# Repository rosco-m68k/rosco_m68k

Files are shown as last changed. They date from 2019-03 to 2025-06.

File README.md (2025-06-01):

# Really Old-School Computer - M68K
## A Motorola 68k Single-Board Computer

> **Note**: This is the **develop** branch, where the latest development files live. It is not guaranteed to contain stable code or working designs at any given point. If you are looking for code to use with your board or stable designs, these can be found on the relevant release branches: The [latest 2.4 release branch](https://github.com/rosco-m68k/rosco_m68k/tree/release/version-2.4) for revision 2.x boards, the [1.3 release branch](https://github.com/rosco-m68k/rosco_m68k/tree/release/version-1.3), the [1.2 release branch](https://github.com/rosco-m68k/rosco_m68k/tree/release/revision-1.2) for **revision 1.2** boards, or the [1.1 release branch](https://github.com/rosco-m68k/rosco_m68k/tree/release/revision-1.1) (or the [1.01 release branch if you have firmware 1.01](https://github.com/rosco-m68k/rosco_m68k/tree/release/revision-1.01)) for **revision 1 boards**. Code built or PCBs manufactured from the develop branch are likely to contain development and pre-production bugs, be incomplete, or just plain not work. Code and designs here are liable to change in utterly-incompatible ways without notice!

## What is this?

This repository holds design files, firmware and software for the Really Old-School Computer 
(M68k) single-board computer, AKA the rosco_m68k. This is a fully-featured, programmable,
extensible and capable 16/32-bit retro computer that is completely open source.

This project contains all the design files and source code for the project. For 
documentation (including assembly instructions) please see the [getting started guide](index.md).

You can find the project along with some logs about its development history
on Hackaday: https://hackaday.io/project/164305-yet-another-m68k-homebrew

* All Software released under the MIT licence. See LICENSE for details.
* All Hardware released under the CERN Open Hardware licence.See LICENCE.hardware.txt.
* All Documentation released under Creative Commons Attribution. See https://creativecommons.org/licenses/by/2.0/uk/
* OSHWA-certified Open Source Hardware

## Specifications

Current main board

### Hardware

The hardware specifications for the rosco_m68k are:

* MC68010P10 at 10MHz.
* XR68C681P provides UART, Timers and SD Card / SPI
* 1MB RAM (0x0 - 0xFFFFF)
* 1MB ROM (0xE00000 - 0xEFFFFF)
* 1MB IO space (0xF00000 - 0xFFFFFF)
* High-speed decode and glue logic handled by Atmel F22V10C PLDs.
* Comprehensive expansion and IO connectors allow the system to be easily expanded!

### Software

* A serial bootloader that can load software via the UART (with Kermit protocol)
* Lots of example code and community projects
* Rich firmware interface for with serial and video console for easy programming
* Programmable in assembly, C and (a limited subset of) C++.
* Easy68K-compatible* TRAP 15 (IO) handler
* A growing collection of system libraries and utility code
* Custom Homebrew tap with toolchain - assembly built with VASM; C/C++ built with GCC 13.3.

(*) The firmware is _mostly_ Easy68K compatible - certain functions are not implemented due to the serial nature of IO.

## Getting boards fabricated

If you want to get boards fabricated, we recommend JLCPCB - they did all of our commercial boards. 
These are the options you'll want when ordering from them (these should be readily adaptable to other fabs too!)

JLCPCB Fab Options

## Certification

The rosco_m68k is an OSHWA-certified Open Source Hardware project!

<p align='center'>
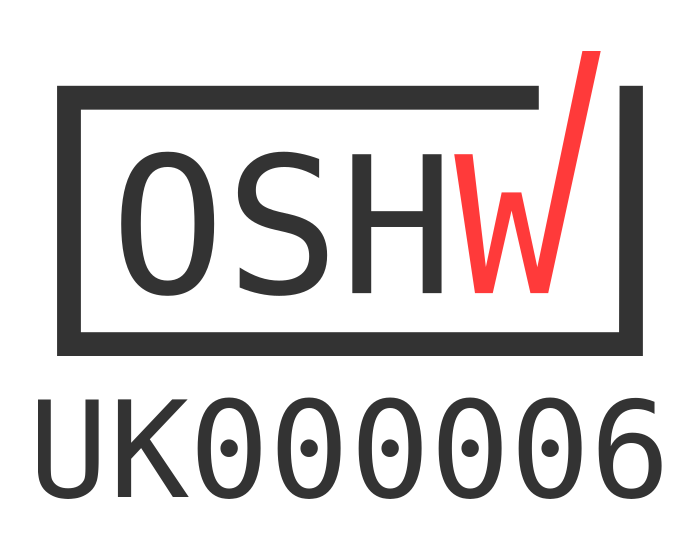
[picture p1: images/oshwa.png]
OSHWA Certified OSHWA Certification UK000006

</p>
<p align='center'>
https://certification.oshwa.org/uk000006.html
</p>

## Evolution

<table>
<tr>
<td colspan="2">
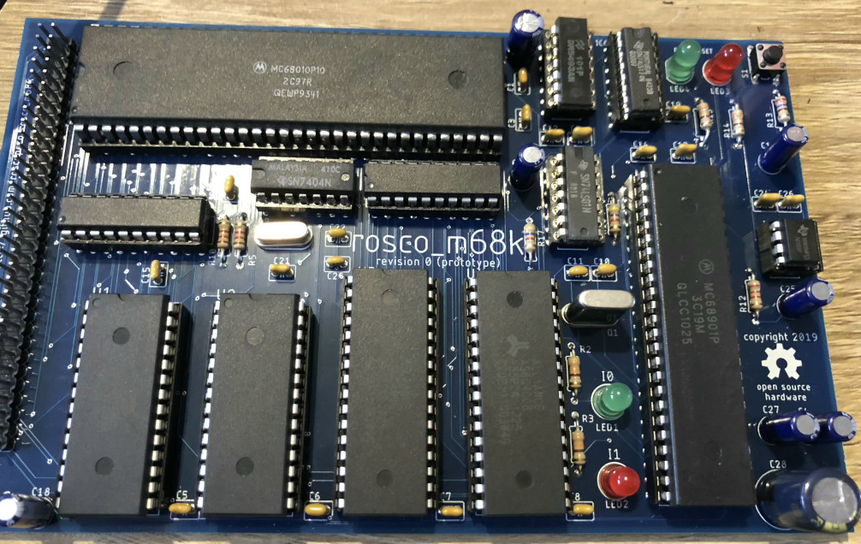
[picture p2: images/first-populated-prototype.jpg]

</td>
</tr>
<tr>
<td>

</td>
<td>
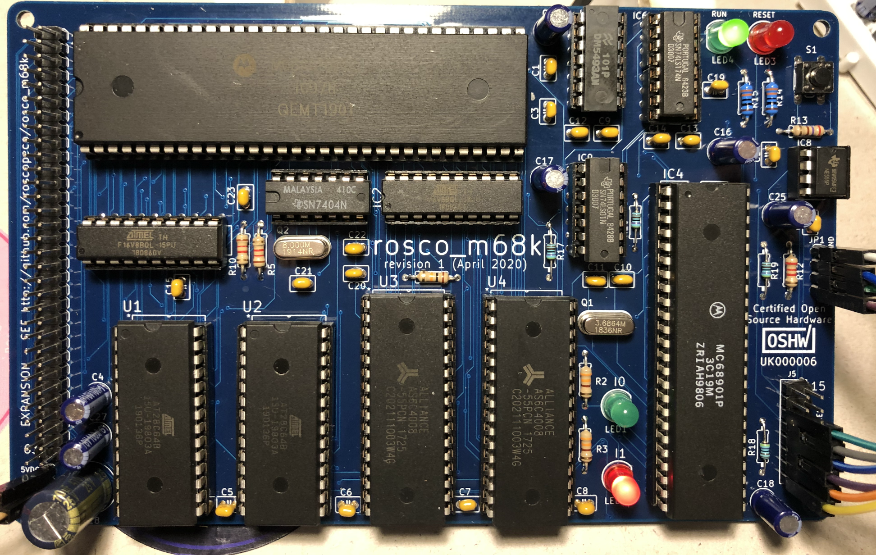
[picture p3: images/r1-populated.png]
 
</td>
</tr>
<tr>
<td>
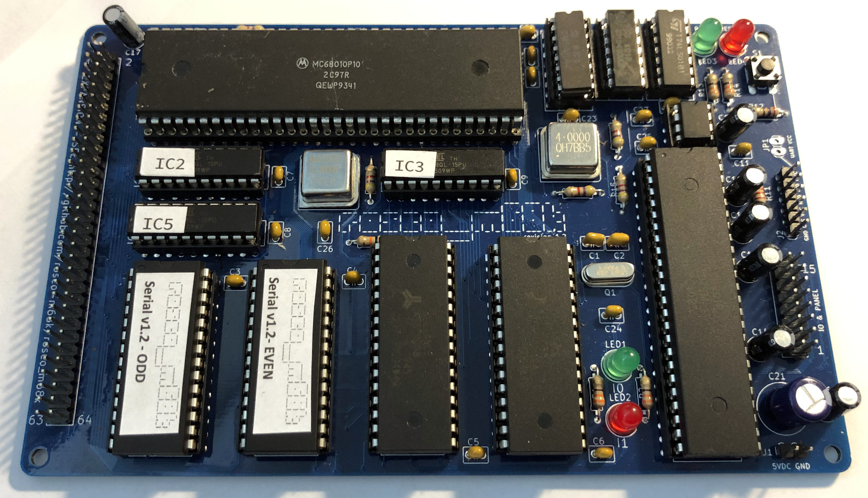
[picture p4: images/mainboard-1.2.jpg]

</td>
<td>
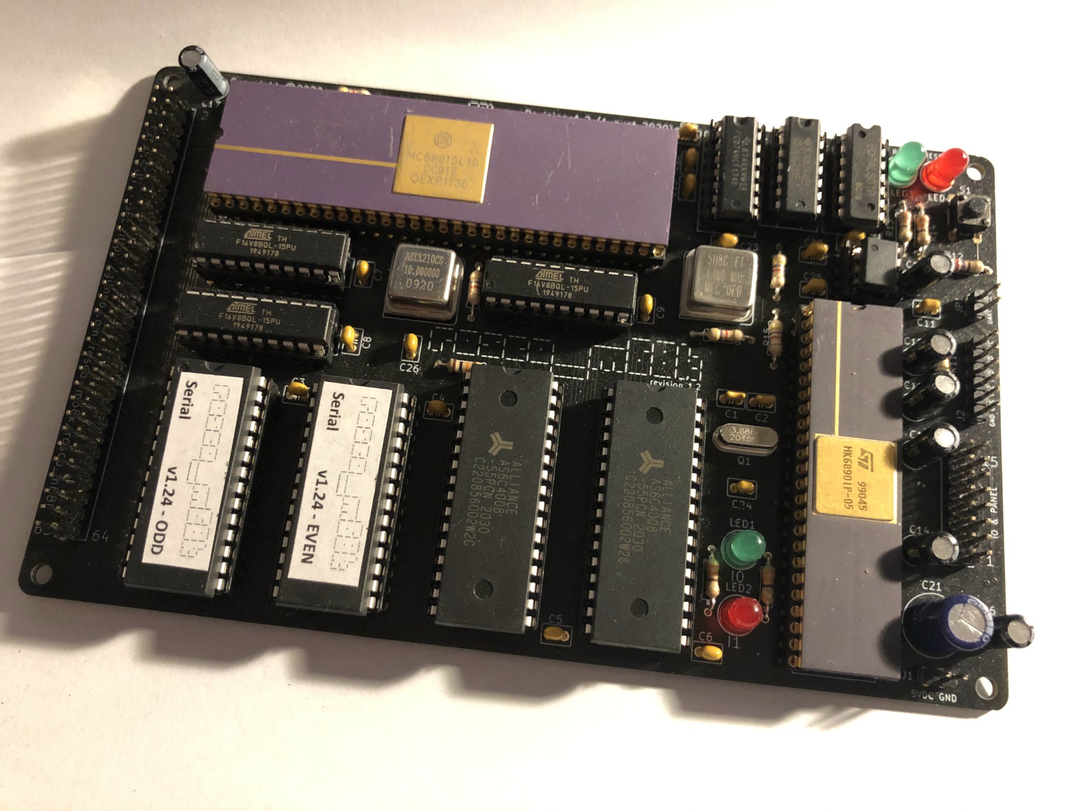
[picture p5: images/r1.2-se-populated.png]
 
</td>
</tr>
<tr>
<td>
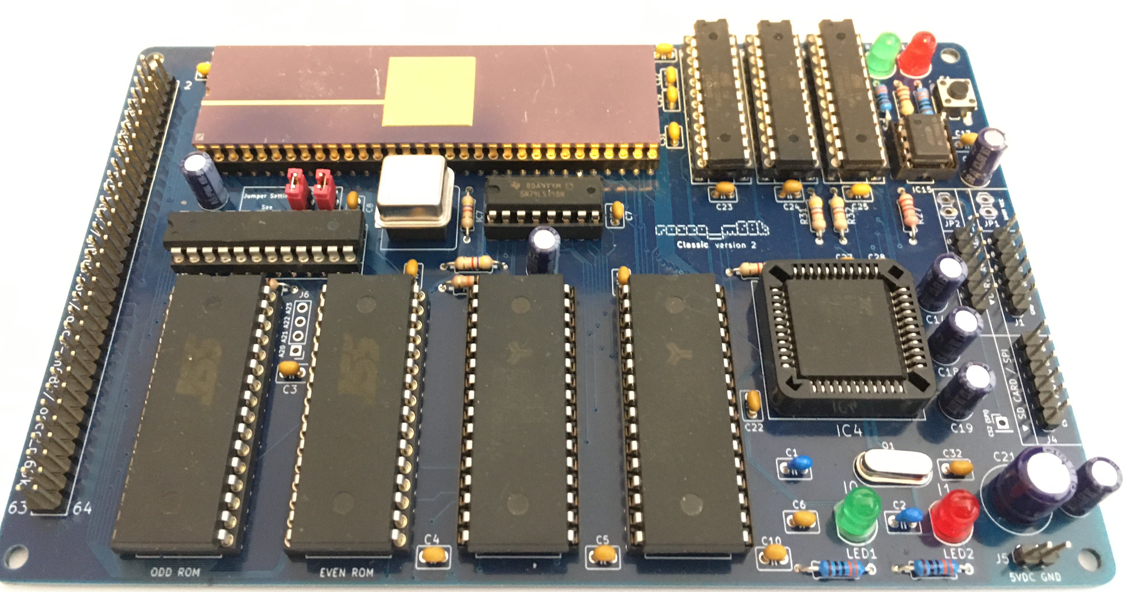
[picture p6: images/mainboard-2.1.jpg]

</td>
<td>
 
</td>
</tr>
<tr>
<td colspan="2">

</td>
</tr>
</table>

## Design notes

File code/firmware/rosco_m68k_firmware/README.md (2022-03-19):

# rosco_m68k Firmware v2.0
## For all Revision 1.x & Revision 2.x rosco_m68k Classic main boards

This is the official version 2.0 firmware for all rosco_m68k Classic boards.

It provides basic machine initialization, a rich API for use by software,
and a variety of boot loaders to enable flexible loading of code into the
machine at boot time.

Drivers are included here for the MC68901 (Revision 1.x only), MC68681 
(and XR68C681), V9958, Xark's Xosera, MarkM's IDE (ATA) interface, and 
the built-in (bit-banged) SPI and SD Card interfaces, and (where 
appropriate) a firmware interface to enable easy use is also provided 
(see InterfaceReference.md).

## Building

The build supports building either 1MB (for Revision 2.x mainboards) or 
64KB ROMs (for Revision 1.x mainboards). Selected options will vary depending
on the ROM size being built. 

Note that, unlike the 1.x firmware series, no support is provided for 16KB ROMs.

To build all options included for revision 2.x boards, just `make`, e.g:

```
make clean all
```

If you wish to build for revision 1.x boards, build with REVISION1X=true, e.g.

```
REVISION1X=true make clean all
```

You can optionally include/exclude various things - see the `Makefile` for 
details.

### Burning

If you are using a TL866II+ programmer, you can burn your ROMs 
directly from the Makefile with:

```
make burn
```

This will automatically set the device to whatever is appropriate for the
ROM size you built (SST39SF040 for R2.x, AT28C256 for R1.x). This can be 
overriden by passing `ROMDEVICE` on the command line, e.g:

```
ROMDEVICE=<SOMEDEVICE> make clean burn
``` 

Where `<SOMEDEVICE>` is a Minipro-recognised device string.

## SD Card 

The SD Card connects to the dedicated SD card connector on the r2 and
r1.2 mainboards. See https://github.com/rosco-m68k/rosco_m68k/blob/develop/SDCardGuide.md
for further details.

SD Cards must be FAT formatted, and will be recognised and scanned 
at boot. If a file named `ROSCODE1.BIN` is found in the root directory,
it will be loaded automatically. 

Binaries built with the `start_serial` standard library (which includes
all example programs) will work from SD card without modification.

## Serial Loader (Kermit)

### Protocols

Currently, only Kermit is supported, and only in the `robust` mode. To support
cautious or fast mode would probably need hardware flow control, for which
most FTDI adapters implement inadequate support.

This is mildly annoying as it requires one to install additional software 
to get Kermit support from the command line, or in minicom. On most Unices
you should be able to install from your package manager (try `ckermit` or 
`c-kermit`). On OSX you can install from homebrew (`brew install c-kermit`) 
and ports probably has it too. On Windows YMMV, but if you're successfully
building this on Windows then you've probably already done a lot of work to
get a cross-compiler and so on working, so I'm sure you'll figure it out.

If you are having problems getting Kermit to work on Linux (especially
Debian or derivatives) you may find that building this patched version
from source helps: https://github.com/rosco-m68k/ckermit

### Kermit Settings

It is **strongly** recommended you use the following settings for your
c-kermit. These should go in your `~/.kermrc` file (or whatever the 
Windows equivalent is):

```
set carrier-watch off ;
set flow xon/xoff ;
robust
```

This instructs c-kermit not to look for a carrier detect signal, to use
software flow-control (because all FTDI chips I've seen get RTS/CTS 
just wrong enough to make them useless without a FIFO on the receiving 
end), and to use the `robust` kermit protocol variant, which is the only 
one I've been able to get to work with the embedded Kermit implementation 
in the bootloader - YMMV of course, feel free to experiment...

You'll need this (at least the carrier detect disable) whether you're
using c-kermit from the command-line or from minicom (or similar).

Of course if your FTDI adapter has a CD pin and you tie this low, you
can skip the carrier-detect setting...
 
## Code

For details of the standard libraries and how to use them to write your
own code, see the examples and the README in the software directory:
https://github.com/rosco-m68k/rosco_m68k/blob/develop/code/software/README.md

You will also find some template projects that get you started with 
either C/C++ or Assembly development at 
https://github.com/rosco-m68k/rosco_m68k/tree/develop/code/starter_projects

The primary reference for the software interfaces provided by the 
firmware can be found here: 
https://github.com/rosco-m68k/rosco_m68k/blob/develop/code/firmware/rosco_m68k_firmware/InterfaceReference.md

* Code is loaded at $40000 (somewhat arbitrarily). The loader will jump
  directly to that location after the code is received.
* This means you are limited to ~860KB with the standard memory configuration.
* (It's actually slightly more, but the stack is at the top of RAM!)
* Once your code is loaded, all of RAM is yours.
* If you use the `heap` standard library, most of this memory will be dedicated
  to your heap, with 32KB being reserved for stack.
* Depending how much setup you want to do, you might leave the lowest 1KB 
  alone (exception vectors), other than setting up any vectors your code
  actually wants to handle.
* If you want to use the standard runtime support stuff (see below), leave the
  bottom 8KB alone (i.e. $2000-$FFFFF are free for your use).

Most of the following things are taken care of automatically if you use the
`start_serial` library (and link using the provided link script). 

The starter projects linked above take care of this for you.
 
* The _recommended_ thing to do is to relocate your code after loading,
  so you don't have it stuck in the middle of RAM. This will make your
  life easier later.
* Obviously your link script will need to take this into account!
* On entry to your code, you are free to (and probably should) reset the
  stack, and can trash any registers you wish. 
* The loader **does not** expect to be returned to. It _will_ handle
  such a condition gracefully, however (it will print a message and halt
  the machine).
  
On entry to the loaded code, the system will be in the following state:

* CPU will be in supervisor mode
* PC will be at $40000
* VBR will point to $0
* Supervisor stack will be at the top of RAM, SSP could be anywhere and can be reset
* Registers will be undefined, and can all be trashed.
* Exception table will be set up (with mostly no-op handlers) from $0 - $3FF 
* Some (very) basic system data will exist between $400-$4FF. You can trash this if you don't need it
  * Some of the default exception handlers **do** write to this area, however!
  * So replace them if you're going to use this area for your own purposes!
* Interrupts (level 2 and above) will be enabled  
* A default exception handler (that will print some debugging information) will
  be installed.
* The system timer will be driving a 100Hz system tick
* System tick will be vectored to CPU vector 0x45, default handler flashes I0.
* DUART/MFP Interrupts other than Timer C will be disabled
* TRAP#13, TRAP#14, TRAP#15 will be hooked by the firmware to provide some basic 
  IO.
* UART TX and RX will be enabled, but their interrupts won't be 
  * you'll either have to enable (and handle) them or use polling
  * If you _do_ enable them, don't use the TRAP#14 IO routines any more or sadness is likely to ensue.

## Runtime Support

See InterfaceReference.md for full details of the runtime interfaces,
TRAPs and memory layout supported by this firmware, including the 
Easy68k compatibility layer.

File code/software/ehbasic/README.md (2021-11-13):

# Enhanced Basic for rosco_m68k

This is a port of Lee Davison's Enhanced Basic for 680x0 to the rosco_m68k.

It can be loaded into RAM (by the serial bootloader) where it will currently run
directly from the load address (i.e. it does not relocate low like most of the 
other software does, because of some idiosyncracies in the way its memory is laid
out - this is likely to change in the future). BASIC RAM is kept below this and 
comprises 128K at the moment.

It should also support being built into a ROM, though this is as-yet untested.

Note that EhBASIC, like any good BASIC, is case-sensitive! Commands must be in
uppercase, or you will receive an error message.

References:

1. http://retro.hansotten.nl/home/lee-davison-web-site/
2. http://www.easy68k.com/applications.htm
3. http://sun.hasenbraten.de/vasm/

## Building

### Standard board (Revision 1.x with Firmware 1.3+, or revision 2.x)

Just run `make` to build, with the standard toolchain.

### Standard board (No MC68681 Dual UART expansion, Firmware 1.2 or below)

To work with the with the onboard MC68901, you must pass `FIRMWARE_IO=false`
option to the make command:

`FIRMWARE_IO=false make clean all`

### With MC68681 Dual UART expansion board

To work with the MC68681 expansion on older mainboards (without Firmware
1.3 or above), you must pass `FIRMWARE_IO=false` and `MC68681=true` 
options to the make command:

`FIRMWARE_IO=false MC68681=true make clean all`

------------------------------------------------------------------------

 EhBASIC68

 Enhanced BASIC is a BASIC interpreter for the 68k family microprocessors. It
 is constructed to be quick and powerful and easily ported between 68k systems.
 It requires few resources to run and includes instructions to facilitate easy
 low level handling of hardware devices. It also retains most of the powerful
 high level instructions from similar BASICs.

 EhBASIC is copyright Lee Davison 2002 - 2012 and free for educational or
 personal use only.
 For commercial use please contact me at leeedavison@lgooglemail.com for conditions.

 For more information on EhBASIC68, other versions of EhBASIC and other projects
 please visit my site at ..

  http://mycorner.no-ip.org/index.html

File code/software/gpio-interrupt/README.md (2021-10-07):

# Rosco_m68k MFP GPIO Interrupt Test Example

This is an example of programming rosco_m68k's MC68901 Multi-Function
Peripheral (MFP) chip.  It programs the chip's general purpose input/output
(GPIO) port to generate a 680x0 CPU interrupt on a falling edge signal (high
to low transition) on rosco_m68k's GPIO3 pin (aka JP5-5). When this transition
happens, the CPU will suspend what it is doing and call a special "interrupt
handler" function, which can then do some work and then when it finishes,
the CPU will resume right at the point where it suspended.

In order to actually see this do anything  semi-interesting, you'll need
something to toggle the signal on J5 pin 5 (GPIO3).  You can use an FTDI
module (including the one you may also be using for rosco_m68k UART), a
switch or an Arduino etc.

However, in my testing, even with _nothing_ hooked up I got a large number
of "bogus" interrupts due to the pin being left floating (especially
when touching JP5 lightly with my finger).

## Building

```text
make clean all
```

This will build `gpio-interrupt.bin`, which can be uploaded to a rosco_m68k
board with standard firmware.

The `Makefile` also makes some other potentially useful outputs:

* `gpio-interrupt.elf` the program binary along with additional symbol and debugging information (useful when using other GNU tools vs a raw binary)
* `gpio-interrupt.dis` a disassembly of the program (but since it is interspersed with the corresponding source code, it is somewhat more understandable than a raw disassembly)
* `gpio-interrupt.sym` lists symbols used in the program and their address (or value for constants)
* `gpio-interrupt.map` similar to the SYM file this shows where everything was placed in memory by the linker

The test will print to the screen while "counting" high to low transitions
on J5 pin 5 and toggling the red LED (the green LED will keep blinking as
usual, using the normal rosco 100Hz MFP "timer C" interrupt).  If there is any
UART input (e.g., you hit a key in a terminal program) the program will issue
a "goodbye" message and exit (similar to as if you pressed the reset button).

I have tried hard to keep the code all in C and not directly use assembly,
however this task is by nature somewhat low-level and I did find using one line
of assembly was required (at least without removing the `-pedantic` compiler
option, and that didn't quite seem sportsman like).

I have found it handy to use an FTDI adapter to automatically toggle the
GPIO pin.  See
[Introduction To FTDI Bitbang Mode](https://hackaday.com/2009/09/22/introduction-to-ftdi-bitbang-mode/)
for a nice example that toggles CTS (change the define at the top to 0x10 for DTR or 0xFF
for "all the pins").  You should connect the GND of FTDI to one of the rosco GND
connections (which you should already be doing if using the FTDI for rosco UART).
Also connect the FTDI signal pin you are using to JP5-5 (e.g., DTR, CTS or RTS).
I find DTR is handy on the default generic FTDI modules. **DO NOT** connect power
from the FTDI module to rosco (unless you are using **only** using the FTDI module
to power your rosco).

Here is a picture of my FTDI to GPIO3 hook-up.  The red, grey and black wires are normal
UART connections (rosco RXD to FTDI TX, rosco TXD to FTDI RX and GND to GND).  The white
wire is DTR to GPIO3 to generate the interrupt.
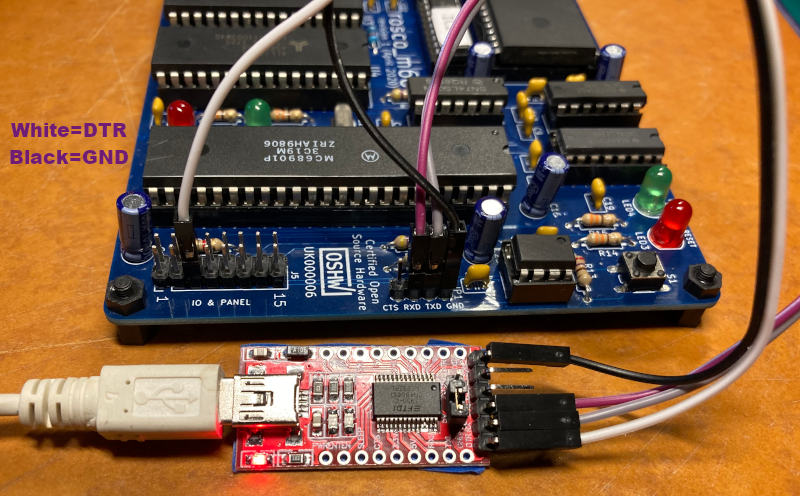
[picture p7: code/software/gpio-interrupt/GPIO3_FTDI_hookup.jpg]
GPIO3 to FTDI connection


I believe using a switch to toggle JP5-5 between 5V and GND should work also (perhaps with
a small-ish ~100 ohm resistor to protect rosco, electrically).

If you're feeling adventurous (and have `ckermit` installed), you
can try:

```text
SERIAL=/dev/some-serial-device make load
```

which will attempt to send the binary directly to your board (which
must obviously be connected and waiting for the upload).

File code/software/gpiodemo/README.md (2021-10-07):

# Very simple GPIO programming example

This is a very simple example of programming the GPIOs.

In order to actually see this do anything, you'll need to hook up a circuit with
some LEDs or something connected to the GPIO lines.

**Note** If you're going to do that, use transistors - the GPIO's can't directly
drive LEDs! See [example-circuit/circuit.pdf](example-circuit/circuit.pdf) for
an example circuit schematic (in KiCad).

## Building

```text
make clean all
```

This will build `kernel.bin`, which can be uploaded to a board that is running
the `serial-receive` firmware.

If you're feeling adventurous (and have ckermit installed), you can try:

```text
SERIAL=/dev/some-serial-device make load
```

which will attempt to send the binary directly to your board (which must
obviously be connected and waiting for the upload).

**NOTE:** This sample uses UTF-8 (for the "💡" glyph). It's recommended to run minicom with colour
and UTF-8 enabled (or you can alter the program).

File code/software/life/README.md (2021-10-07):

# C Game of Life for rosco_m68k

Based on code from this site: <https://rosettacode.org/wiki/Conway%27s_Game_of_Life>

## Building

```bash
make clean all
```

This will build `life.bin`, which can be uploaded to a board that is running the
`serial-receive` firmware.

If you're feeling adventurous (and have ckermit installed), you can try:

```bash
SERIAL=/dev/some-serial-device make load
```

which will attempt to send the binary directly to your board (which must
obviously be connected and waiting for the upload).

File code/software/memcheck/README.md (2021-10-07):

# Memory checked for rosco_m68k

This runs a check of all memory in the address space and builds a memory map
based on what it finds.

All memory locations are tested by writing, and checking that the value that was
written is successfully read back (after writing to another location to avoid
phantom reads).

## Building

```bash
make clean all
```

This will build `memcheck.bin`, which can be uploaded to a board that is
running the `serial-receive` firmware.

If you're feeling adventurous (and have ckermit installed), you can try:

```bash
SERIAL=/dev/some-serial-device make load
```

which will attempt to send the binary directly to your board (which must
obviously be connected and waiting for the upload).

This sample uses UTF-8. It's recommended to run minicom with colour and UTF-8
enabled, for example:

```bash
minicom -D /dev/your-device -c on -R utf-8
```

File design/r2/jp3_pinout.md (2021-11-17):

# rosco_m68k JP3 (Expansion) Pinout (revision 2)

> **Note** this applies to revision 2 (and higher, unless otherwise specified)
  boards **only**. This pinout has changed since the revision one boards (but 
  for most practical purposes it should be compatible - see the new IRQ pins 
  for the differences). This pinout is **not** compatible with earlier revision
  zero boards (which were never released to production anyway)!

JP3 provides peripheral access to the full address, data and control buses in the system, 
plus VCC (5V) and GND. These signals are unbuffered and have no built-in protection, so are
not suitable for direct use as a bus, but could be made so with a relativelty simple 
expansion-to-bus conversion board. 

Many of the MC68010 lines are tri-state when used in conjunction with the bus-mastering support.

It should be noted that most of these signals have very low output current capabilities,
and should not be used to directly drive e.g. LEDs. If LEDs are to be driven, then either
a transistor must be used, or the circuit set up such that the pins sink current.

In all cases, see the datasheets for the relevant IC driving a given line (either the
MC68010, MC68901 or, for the decoder signals, the ATF22V10Cs) for the absolute maximum ratings.

The absolute maximum current draw on the VCC line is 1A. Recommended maximum is 500mA.
The board _may_ be able to supply more than this, but as power supplies are so variable 
you should take care if drawing more than this from this pin. A better solution should 
you need might be to separately power your peripheral from the supply and share common ground.

| Pin | Signal | Description | Active | I/O |
|-----|---|---|---|-----|
| 1 | A1 | MC68010 Address line 1 | High | O |
| 2 | VCC | +5V (Recommend 1A max) | N/A | O |
| 3 | A2 | MC68010 Address line 2 | High | O |
| 4 | CLK | Main system clock (10MHz, 50% duty cycle) | N/A | O |
| 5 | A3 | MC68010 Address line 3 | High | O |
| 6 | GND | Ground | N/A | O |
| 7 | A4 | MC68010 Address line 4 | High | O |
| 8 | VPA | MC68010 Legacy peripheral VPA (*5)(6*) | Low | I |
| 9 | A5 | MC68010 Address line 5 | High | O |
| 10  | E | MC68010 Legacy peripheral E (*5) | Low | O |
| 11  | A6 | MC68010 Address line 6 | High | O |
| 12  | VMA | MC68010 Legacy peripheral VMA (*5) | Low | O |
| 13  | A7 | MC68010 Address line 7 | High | O |
| 14  | IRQ3 | IRQ3 line (*3) | Low | I |
| 15  | A8 | MC68010 Address line 8 | High | O |
| 16  | IOS | IOSEL line from decoder (*1) | Low | O |
| 17  | A9 | MC68010 Address line 9 | High | O |
| 18  | EXPS | EXPSEL line from decoder (*1) | Low | O |
| 19  | A10 | MC68010 Address line 10 | High | O |
| 20  | FC0 | MC68010 Function Code 0 (*2) | High | O |
| 21  | A11 | MC68010 Address line 11 | High | O |
| 22  | FC1 | MC68010 Function Code 1 (*2) | High | O |
| 23  | A12 | MC68010 Address line 12 | High | O |
| 24  | FC2 | MC68010 Function Code 2 (*2) | High | O |
| 25  | A13 | MC68010 Address line 13 | High | O |
| 26  | IPL0 | IRQ5 line (*3) | Low | I |
| 27  | A14 | MC68010 Address line 14 | High | O |
| 28  | IPL1 | IRQ2 Line (*3) | Low | I |
| 29  | A15 | MC68010 Address line 15 | High | O |
| 30  | IPL2 | IRQ6 Line *3) | Low | I |
| 31  | A16 | MC68010 Address line 16 | High | O |
| 32  | LDS | MC68010 Lower Data Strobe | Low | O |
| 33  | A17 | MC68010 Address line 17 | High | O |
| 34  | UDS | MC68901 Upper Data Strobe | Low | O |
| 35  | A18 | MC68010 Address line 18 | High | O |
| 36  | RESET  | System Reset (4*) | Low | I/O |
| 37  | A19 | MC68010 Address line 19 | High | O |
| 38  | D15 | MC68010 Data line 15 | High | I/O |
| 39  | A20 | MC68010 Address line 20 | High | O |
| 40  | D14 | MC68010 Data line 14 | High | I/O |
| 41  | A21 | MC68010 Address line 21 | High | O |
| 42  | D13 | MC68010 Data line 13 | High | I/O |
| 43  | A22 | MC68010 Address line 22 | High | O |
| 44  | D12 | MC68010 Data line 12 | High | I/O |
| 45  | A23 | MC68010 Address line 23 | High | O |
| 46  | D11 | MC68010 Data line 11 | High | I/O |
| 47  | AS | MC68010 Address Strobe | Low | O |
| 48  | D10 | MC68010 Data line 10 | High | I/O |
| 49  | BERR | MC68010 Bus Error | Low | I |
| 50  | D9 | MC68010 Data line 9 | High | I/O |
| 51  | BG | MC68010 Bus Grant | Low | O |
| 52  | D8 | MC68010 Data line 8 | High | I/O |
| 53  | BGACK  | MC68010 Bus Grant Acknowledge | Low | I |
| 54  | D7 | MC68010 Data line 7 | High | I/O |
| 55  | BR | MC68010 Bus Request | Low | I |
| 56  | D6 | MC68010 Data line 6 | High | I/O |
| 57  | DTACK  | MC68010 Data Transfer Acknowledge | Low | I |
| 58  | D5 | MC68010 Data line 5 | High | I/O |
| 59  | R/W | MC68010 Read/Not Write | N/A | O |
| 60  | D4 | MC68010 Data line 4 | High | I/O |
| 61  | D0 | MC68010 Data line 0 | High | I/O |
| 62  | D3 | MC68010 Data line 3 | High | I/O |
| 63  | D1 | MC68010 Data line 1 | High | I/O |
| 64  | D2 | MC68010 Data line 2 | High | I/O |
 
 ## Notes:
 
 1. If used to drive LEDs, the circuit should be configured such that these pins sink current.
 2. If all three function code pins are high the CPU is asserting IACK.
 3. Active low, open-collector IRQ lines for peripherals (4K7 pullups included, do not add more). 
 4. Wire-or, open-collector. Pullup is already provided.
 5. See MC68010 user manual. Using these lines alters bus cycle timing.
 6. This line has a built-in 10k pull-up.

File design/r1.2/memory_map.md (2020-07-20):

# Memory Map

With the standard address decoder (IC2), the machine has the following memory map:

| Region | Start | End | Type |
|---|---|---|---|
| 00 | 0x00000000 | 0x000fffff | Onboard RAM (See note 1) |
| 01 | 0x00100000 | 0x00efffff | Expansion RAM |
| 02 | 0x00f00000 | 0x00f3ffff | Memory hole (See issue #32) |
| 03 | 0x00f40000 | 0x00f7ffff | Expansion RAM |
| 04 | 0x00f80000 | 0x00fbffff | IO (See note 2, below) |
| 05 | 0x00fc0000 | 0x00ffffff | Onboard ROM (See note 3) |

## Note 1 - RAM layout with standard firmware

```
00: 0x00000000-0x000003ff - Exception vectors
01: 0x00000400-0x000004ff - System data area
02: 0x00000500-0x00000fff - Reserved for Kernel, can be re-used 
03: 0x00001000-0x000fffff - User
```

When using the serial firmware, the firmware loads code at 0x40000. On
entry to that code:

* PC will be at 0x40000
* VBR will point to 0x0
* Supervisor stack will be at 0x100000, SSP could be anywhere and can be reset

There is a more complete description of the environment at entry to your
code here: https://github.com/rosco-m68k/rosco_m68k/tree/master/code/firmware/rosco_m68k_v1

When the standard `start_serial` library is compiled into your program,
this library will take care of linking your program correctly and relocating
it to 0x1000 before passing control to your `kmain` function.
For a complete description of the environment on entry, 
see https://github.com/rosco-m68k/rosco_m68k/tree/master/code/software/libs/src/start_serial

### RAM Expansion

Where the roscram_68k RAM expansion board (https://github.com/rosco-m68k/hardware-projects/tree/master/ram-expansion) is fitted, the base address of the RAM provided will be as set by JP1-JP3 on the expansion board, but always
at or above the 1MB mark.

The RAM will extend between 1 and 4 megabytes beyond the base, depending how much RAM is
fitted to the expansion board.

Where the expansion is mapped high (at 13MB) only two megabytes are supported - additional
RAM fitted to the board will not be addressable.

> For more detail on the mapping used by the expansion board and the jumper settings, see comments in https://github.com/rosco-m68k/hardware-projects/blob/master/ram-expansion/code/pld/ic1_address_decoder.pld

## Note 2 - IO Space

As standard, the MFP is mapped to all odd addresses in IO space (IC5 handles
this). It has to be mapped to odd addresses in order to work with the 
CPUs vectored interrupts.

The MFP registers are mapped repeatedly through the whole of IO space,
which leaves only even addresses available for IO expansion (unless the
glue code in IC5 is modified to support).

### MFP Registers

The MFP registers are mapped at the following base addresses and then 
repeat at odd addresses throughout IO space.

| Name (from `machine.h`) | Address | Description |
|---|---|---|
| MFP_GPDR | 0xf80001 | GPIO Data Register |
| MFP_AER | 0xf80003 | Active Edge Register |
| MFP_DDR | 0xf80005 | GPIO Data Direction Register |
| MFP_IERA | 0xf80007 | Interrupt Enable 'A' |
| MFP_IERB | 0xf80009 | Interrupt Enable 'B' |
| MFP_IPRA | 0xf8000B | Interrupt Pending 'A' |
| MFP_IPRB | 0xf8000D | Interrupt Pending 'B' |
| MFP_ISRA | 0xf8000F | Interrupt In-service 'A' |
| MFP_ISRB | 0xf80011 | Interrupt In-service 'B' |
| MFP_IMRA | 0xf80013 | Interrupt Mask 'A' |
| MFP_IMRB | 0xf80015 | Interrupt Mask 'B' |
| MFP_VR | 0xf80017 | Vector Register |
| MFP_TACR | 0xf80019 | Timer 'A' Control Register | 
| MFP_TBCR | 0xf8001B | Timer 'B' Control Register |
| MFP_TCDCR | 0xf8001D | Timers 'C' & 'D' Control |
| MFP_TADR | 0xf8001F | Timer 'A' Data Register |
| MFP_TBDR | 0xf80021 | Timer 'B' Data Register |
| MFP_TCDR | 0xf80023 | Timer 'C' Data Register |
| MFP_TDDR | 0xf80025 | Timer 'D' Data Register |
| MFP_SCR | 0xf80027 | USART Sync Char Register |
| MFP_UCR | 0xf80029 | USART Control Register |
| MFP_RSR | 0xf8002B | USART Receiver Status Register |
| MFP_TSR | 0xf8002D | USART Transmitter Status Register |
| MFP_UDR | 0xf8002F | USART Data Register |

## Note 3 - Onboard ROM

Although 256KB is set aside for ROM, in the standard configuration only 16KB of 
on-board ROM is provided; This is simply striped through the whole of the
space reserved for ROM.

It's also worth noting that, for the first four memory cycles after power-on
or reset, ROM is duplicated low (at 0x0) to allow the CPU to read the reset
vector.

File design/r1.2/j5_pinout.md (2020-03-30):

# rosco_m68k J5 (IO & Panel) Pinout

J5 provides connection to five software-controlled digital GPIO pins with
vectored interrupt capability, two software-controlled timers 8-bit timers, 
and access to all six address-decoder outputs for display purposes.

## GPIO Pins

The general purpose interrupt input/output port provides five I/O lines (GPIO#1-#5)
that may be operated as either inputs or outputs under software control.

In addition, these lines may optionally generate an interrupt on either a positive
transition or a negative transition of the input signal. 

Since interrupts are enabled on a bit-by-bit basis, a subset of the GPIO port could 
be programmed as e.g. handshake lines or the port could be connected to as many as 
five external interrupt sources, which would be prioritized by the on-board interrupt
controller for interrupt service.

For full details, refer to the MC68901 Users Manual. When programming the GPIO port,
it should be noted that the GPIOs are connected to MFP GPIPs #2-6. GPIOs 0, 1 and 7
are used internally by the system.

> **Note**: The GPIO pins are intented for interfacing with other ICs and are **not** 
  suitable for directly driving LEDs or other such devices. If you want to drive LEDs
  from these pins please use transistors!

### Legacy peripheral support

While the MC68010's built-in legacy peripheral support lines are available on
JP3, utilising these lines will cause M6800-type peripherals to use the autovector 
which corresponds to their assigned interrupt level (determined by the state of
the IPL pins, also available on JP3) since they do not provide a vector number in
response to an IACK cycle. This means that polling will have to be performed in
software to determine the interrupting device.

However, by tying the IRQ output from an M6800-type device to the general purpose
IO port and configuring that GPIO as an interrupt line, a unique vector number will
be provided to the processor during an interrupt acknowledge cycle. 

This interrupt structure will significantly reduce interrupt latency for M6800-type
devices and other peripheral devices which do not support vector-by-device.

## Timers

The timers can generate periodic interrupts, measure elapsed time, and count 
signal transitions. In addition, the timers have waveform generation capability.
Both timers are prescaler/counter timers with a common 3.6864MHz clock and are 
independent of the system clock. 

Each timer's output signal toggles when the timer's main counter times out. 
Additionally, both have auxiliary input signals which are used in two of the operation 
modes. An interrupt channel is assigned to each timer and when the auxiliary control 
signals are used, a separate interrupt channel will respond to transitions on these 
inputs.

In addition to the delay mode, both timers can operate in pulse width measurement 
mode and event count mode. 

For full details of the timer modes and how the timers are programmed, refer to the 
MC68901 user manual. When programming the timers, it should be noted that the 
two timers provided are the full-featured timers, A and B. Timers C and D are
used internally by the system.

## Pin assignments

It should be noted that most of these signals have very low output current capabilities,
and should not be used to directly drive e.g. LEDs. If LEDs are to be driven, then either
a transistor must be used, or the circuit set up such that the pins sink current.

In all cases, see the datasheets for the relevant IC driving a given line (either the
MC68901 or, for the decoder signals, the ATF16V8BQL) for the absolute maximum ratings.

| Pin | Signal | Description | Active | I/O |
|-----|---|---|---|-----|
| 1 | GPIO1  | GPIO #1 (MFP GPIP #2) (*4) | H/L | I/O |
| 2 | ERAM | EVENRAMSEL line from decoder (*1) | Low | O |
| 3 | GPIO2  | GPIO #2 (MFP GPIP #3) (*4) | H/L | I/O |
| 4 | ORAM | ODDRAMSEL line from decoder (*1) | Low | O |
| 5 | GPIO3  | GPIO #3 (MFP GPIP #4) (*4) | H/L | I/O |
| 6 | EROM | EVENROMSEL line from decoder (*1) | Low | O |
| 7 | GPIO4  | GPIO #4 (MFP GPIP #5) (*4) | H/L | I/O |
| 8 | OROM | ODDROMSEL line from decoder (*1) | Low | O |
| 9 | GPIO5  | GPIO #5 (MFP GPIP #6) (*4) | H/L | I/O |
| 10  | IOS | IOSEL line from decoder (*1) | Low | O |
| 11  | TAO | Timer A output | -- | O |
| 12  | EXPS | EXPSEL line from decoder (*1) | Low | O |
| 13  | TBO | Timer B output | -- | O |
| 14  | TBI | Timer B input (*2) | -- | I |
| 15  | TAI | Timer A input (*2) | -- | I |
| 16  | N/C | Unconnected (*3) | -- | --  |
 
 ## Notes:
 
 1. If used to drive LEDs, the circuit should be configured such that these pins sink current.
 2. These pins have an on-board 4K7 pull-up to VCC
 3. This pin can (via additional soldering) be used as either a GND or VCC to suit the configuration of the other pin connections. In the future an on-board jumper may be provided to accomplish this.
 4. If driving LEDs, it is **strongly** recommended that transistors be used as these pins have very low current ratings for both source and sink. Refer to the MC68901 datasheet for specific values.

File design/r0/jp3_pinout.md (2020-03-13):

# rosco_m68k JP3 (Expansion) Pinout

> **Note** that there is an error in the silkscreen of the revision 0 board than incorrectly
  labels pin 2 as pin 64 on the physical board!

JP3 (split into JP3 and JP4 in the schematic but joined as a single 2x32 pin header on the PCB)
provides peripheral access to the full address, data and control buses in the system, plus
VCC (5V) and GND. These signals are unbuffered, however many of the MC68010 lines are 
tri-state when used in conjunction with the bus-mastering support.

It should be noted that most of these signals have very low output current capabilities,
and should not be used to directly drive e.g. LEDs. If LEDs are to be driven, then either
a transistor must be used, or the circuit set up such that the pins sink current.

In all cases, see the datasheets for the relevant IC driving a given line (either the
MC68010 or, for the decoder signals, the ATF16V8BQL) for the absolute maximum ratings.

The recommended maximum current draw on the VCC line is 250mA. The board _should_ be
able to supply more than this, but as power supplies are so variable you should take
care if drawing more than this from this pin. A better solution should you need might
be to separately power your peripheral from the supply and share common ground.

Although it is possible with the current design to power the board by the VCC and GND
pins, this is not recommended. If you do decide to do this you might consider additional
filtering.

| Pin | Signal | Description | Active | I/O |
|-----|---|---|---|-----|
| 1 | A1 | MC68010 Address line 1 | High | O |
| 2 | VCC | +5V (Recommend 250mA max depending on PSU) | N/A | O |
| 3 | A2 | MC68010 Address line 2 | High | O |
| 4 | CLK | Main system clock (8MHz, 50% duty cycle) | N/A | O |
| 5 | A3 | MC68010 Address line 3 | High | O |
| 6 | GND | Ground | N/A | O |
| 7 | A4 | MC68010 Address line 4 | High | O |
| 8 | ERAM | EVENRAMSEL line from decoder (*1) | Low | O |
| 9 | A5 | MC68010 Address line 5 | High | O |
| 10  | EROM | EVENROMSEL line from decoder (*1) | Low | O |
| 11  | A6 | MC68010 Address line 6 | High | O |
| 12  | ORAM | ODDRAMSEL line from decoder (*1) | Low | O |
| 13  | A7 | MC68010 Address line 7 | High | O |
| 14  | OROM | ODDROMSEL line from decoder (*1) | Low | O |
| 15  | A8 | MC68010 Address line 8 | High | O |
| 16  | IOS | IOSEL line from decoder (*1) | Low | O |
| 17  | A9 | MC68010 Address line 9 | High | O |
| 18  | EXPS | EXPSEL line from decoder (*1) | Low | O |
| 19  | A10 | MC68010 Address line 10 | High | O |
| 20  | FC0 | MC68010 Function Code 0 (*2) | High | O |
| 21  | A11 | MC68010 Address line 11 | High | O |
| 22  | FC1 | MC68010 Function Code 1 (*2) | High | O |
| 23  | A12 | MC68010 Address line 12 | High | O |
| 24  | FC2 | MC68010 Function Code 2 (*2) | High | O |
| 25  | A13 | MC68010 Address line 13 | High | O |
| 26  | IPL0 | MC68010 Interrupt Priority Level Bit 0 (*3)  | Low | I |
| 27  | A14 | MC68010 Address line 14 | High | O |
| 28  | IPL1 | MC68010 Interrupt Priority Level Bit 1 (*3)  | Low | I |
| 29  | A15 | MC68010 Address line 15 | High | O |
| 30  | IPL2 | MC68010 Interrupt Priority Level Bit 2 (*3)  | Low | I |
| 31  | A16 | MC68010 Address line 16 | High | O |
| 32  | LDS | MC68010 Lower Data Strobe | Low | O |
| 33  | A17 | MC68010 Address line 17 | High | O |
| 34  | UDS | MC68901 Upper Data Strobe | Low | O |
| 35  | A18 | MC68010 Address line 18 | High | O |
| 36  | RESET  | System Reset (4*) | Low | I/O |
| 37  | A19 | MC68010 Address line 19 | High | O |
| 38  | D15 | MC68010 Data line 15 | High | I/O |
| 39  | A20 | MC68010 Address line 20 | High | O |
| 40  | D14 | MC68010 Data line 14 | High | I/O |
| 41  | A21 | MC68010 Address line 21 | High | O |
| 42  | D13 | MC68010 Data line 13 | High | I/O |
| 43  | A22 | MC68010 Address line 22 | High | O |
| 44  | D12 | MC68010 Data line 12 | High | I/O |
| 45  | A23 | MC68010 Address line 23 | High | O |
| 46  | D11 | MC68010 Data line 11 | High | I/O |
| 47  | AS | MC68010 Address Strobe | Low | O |
| 48  | D10 | MC68010 Data line 10 | High | I/O |
| 49  | BERR | MC68010 Bus Error | Low | I |
| 50  | D9 | MC68010 Data line 9 | High | I/O |
| 51  | BG | MC68010 Bus Grant | Low | O |
| 52  | D8 | MC68010 Data line 8 | High | I/O |
| 53  | BGACK  | MC68010 Bus Grant Acknowledge | Low | I |
| 54  | D7 | MC68010 Data line 7 | High | I/O |
| 55  | BR | MC68010 Bus Request | Low | I |
| 56  | D6 | MC68010 Data line 6 | High | I/O |
| 57  | DTACK  | MC68010 Data Transfer Acknowledge | Low | I |
| 58  | D5 | MC68010 Data line 5 | High | I/O |
| 59  | R/W | MC68010 Read/Not Write | N/A | O |
| 60  | D4 | MC68010 Data line 4 | High | I/O |
| 61  | D0 | MC68010 Data line 0 | High | I/O |
| 62  | D3 | MC68010 Data line 3 | High | I/O |
| 63  | D1 | MC68010 Data line 1 | High | I/O |
| 64  | D4 | MC68010 Data line 4 | High | I/O |
 
 ## Notes:
 
 1. If used to drive LEDs, the circuit should be configured such that these pins sink current.
 2. If all three function code pins are high the CPU is asserting IACK.
 3. Interrupt 4 (100b) is reserved for the MC68901.
 4. Wire-or, open-collector.

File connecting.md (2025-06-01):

[Home](index.md) | [Getting Started](getting-started.md) | [Connecting](connecting.md) | [Running the Examples](running-the-examples.md) | [Toolchain Installation](toolchain-installation.md) | [Building the Software](building-the-software.md) | [Installing the Emulator](installing-the-emulator.md) | [Debugging with MAME](MAME-serial.md) | [Using SD Cards](SDCardGuide.md)

# Connecting your rosco_m68k

## Once you've built your new old computer, it's time to start talking to it!

Hooking up your rosco_m68k to your regular modern computer is a simple affair, thanks to the wonders of modern technology. USB to Serial (UART) converters are cheap and plentiful, and you might even have received one along with your kit (if you opted for one when you purchased). Let's look at what you'll need to get started.

### You'll need:
- A USB lead with +5V and GND broken out to Dupont® connectors, or alternative power connector
- A USB to Serial converter (sometimes called an FTDI converter) or cable
- A USB Mini-B to A cable

> **Warning!**
> - Incorrectly connecting your rosco_m68k may damage it and other equipment connected to it - Check before you connect!
> - Connecting your rosco_m68k to a power source with a voltage higher than 5V is likely to damage it - Check before you connect!
> - Your USB to Serial converter must be 5V tolerant. Some have a jumper to select either 5V or 3.3V, ensure this is set to 5V - Check before you connect!

---

## Connecting the Power

You'll need some kind of 5V power supply that can connect to the two-pin power header on the rosco_m68k. We use modified USB cables and regular wall-wart adapters for this, but any well-regulated 5V power source will work just fine.

If you don't have a power lead, it's easy to make one from an old USB lead - check out [this video](https://www.youtube.com/watch?v=Vw4d0oMl0Mg), for example.

When connecting the power, be sure to observe the polarity - the pins are clearly marked on the board as **5VDC** and **GND**. If using a USB cable, these should be connected to the red and black wires, respectively. It's really important to connect these correctly, getting them the wrong way round *will* damage your rosco_m68k! If in doubt, use a multimeter to check the polarity before you connect.

---

## Connecting the UART to the USB to Serial Converter

The exact method for doing this will vary depending on the specific converter you have, but the general principle remains the same.

Find the four-pin UART connector on your rosco_m68k - it's on the right side of the board, and the pins are marked **CTS**, **RXD**, **TXD** and **GND**.

Now, on your USB to Serial converter, find the corresponding four pins. Most converters (including the one we optionally supply) will already have headers soldered on for these pins.

Using a four-way wire with DuPont connectors at each end, make the following connections:

| rosco_m68k | USB to Serial Converter |
|---|---|
| CTS | CTS |
| RXD | TXD (Sometimes TX) |
| TXD | RXD (Sometimes RX) |
| GND | GND |

Now connect the USB cable from your USB to Serial converter to your computer. The converter will probably have some LEDs that light up at this point, and your computer should recognise it as a new serial device.

The new device should appear in the `/dev` directory, ready for use. On macOS, for example, it's named `/dev/cu.usbserial-XXXX`. You can find it easily by running:

```sh
ls /dev/cu*
```

On Linux, you can find the name of the device by looking at the output of the `dmesg` command.

---

## Connecting an SD Card

If you're running Firmware v1.3 and up, you can connect an SD card using an Arduino SD card adapter. Depending on your board revision, this either connects to a dedicated header (on 1.23 boards and higher) or to J5 (on 1.2 boards and below).

See [this page](https://github.com/rosco-m68k/rosco_m68k/blob/develop/SDCardGuide.md) for a detailed hookup guide, as well as information on supported cards and formatting.

---

## Installing Software and Testing

> **Note:** These instructions apply to macOS® and Linux only. We recommend that Windows® users use a Linux VM.

If you hit compilation failures or other issues with CKermit, you may need to install from source - we maintain a fork of the 9.0.160 version, slightly modified to compile on modern systems: [rosco-m68k/ckermit](https://github.com/rosco-m68k/ckermit).

In this section we'll install two programs, `minicom` and `ckermit`. If you already have them installed, or have another terminal emulator / kermit client that you like, then feel free to skip this section.

We recommend using Homebrew to manage your software. If you don't already have it, you can find simple installation instructions at [brew.sh](https://brew.sh/).

If you're using Linux and don't want to install Homebrew, it's very likely that both these packages are available from your distribution's standard package repositories - you'll be able to install them with `apt-get`, `yum`, `dnf`, or whatever your regular package manager is called.

To install the two packages with Homebrew:

```sh
brew install minicom c-kermit
```

(Note: If using your Linux distribution's package manager, the Kermit package is likely to be called `ckermit` instead of `c-kermit`.)

After installation, both packages should be ready to use, but we need to add a little bit of configuration first.

Create a new file in your home directory called `.kermrc`, or edit the existing one if it already exists. The contents of this file should be:

```
set carrier-watch off ;
set flow xon/xoff ;
robust
```

Now launch minicom:

```sh
minicom -D /dev/cu.usbserial-XXXX -c on -R utf-8
```

Replace `/dev/cu.usbserial-XXXX` with the path to the device you determined in the previous step. On Linux, this will probably start with `/dev/tty...` rather than `/dev/cu...`.

> **Note:** On Mac, you may find that the `Esc+KEY` combination used in the following section doesn't work. If you're using [iTerm2](https://iterm2.com/) you can emulate this combination with the right option key by opening the `Profiles` menu, selecting `Open Profiles`. Click the `Edit Profiles` button, and with the `Default` profile selected in the left pane go to the `Keys` tab in the right pane. Near the bottom of this is an option to change the mapping of the `Right Option` key - change this to be `Esc+`.

Once Minicom has launched, open the options (Esc+O or CTRL-A, O on Linux) and navigate to Serial Port Setup. Edit the options as needed, then escape out and select "Save setup as dfl". Restart minicom to ensure the configuration is loaded.

Power up your rosco_m68k (or hit the reset button if it's already powered up), and you should see the startup message on-screen. Congratulations - you're now all set, and your rosco_m68k can talk to your computer!

From here, you can use Esc+S (Ctrl-A, S on Linux) to initiate a Kermit file transfer, and send a compiled binary program to your board and interact with it in the serial terminal.

Now that the rosco_m68k is successfully talking to your computer, it's time to run some example programs! We'll do that in the [next section](running-the-examples.md).

---

---

[Home](index.md) | [Getting Started](getting-started.md) | [Connecting](connecting.md) | [Running the Examples](running-the-examples.md) | [Toolchain Installation](toolchain-installation.md) | [Building the Software](building-the-software.md) | [Installing the Emulator](installing-the-emulator.md) | [Debugging with MAME](MAME-serial.md) | [Using SD Cards](SDCardGuide.md)

Copyright © 2020 The Really Old-School Company Limited. Registered in England and Wales No. 12596175
The Really Old-School Company Ltd, 15 Starthe Bank, GB DE75 7AX Tel: 0330 133 2083

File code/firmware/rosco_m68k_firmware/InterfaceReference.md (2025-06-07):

# rosco_m68k Firmware - Memory & Interfaces
## Firmware version 2.0

This document describes the interfaces provided for programmers,
hardware integrators and those expanding the rosco_m68k, as it
applies to firmware revision 2.0. 

The information contained herein is accurate and complete as far
as possible, and will be kept updated as firmware 2.0 is developed.

# Contents

* 1. TRAP Interfaces for User Code
  * 1.1. SPI & Block device IO (TRAP 13)
    * 1.1.1 Example Usage
    * 1.1.2 Functions
      * 1.1.2.1 CHECK_SD_SUPPORT (Function #0)
      * 1.1.2.2 SD_INIT (Function #1)
      * 1.1.2.3 SD_READ_BLOCK (Function #2)
      * 1.1.2.4 SD_WRITE_BLOCK (Function #3)
      * 1.1.2.5 SD_READ_REGISTER (Function #4)
      * 1.1.2.6 CHECK_SPI (Function #5)
      * 1.1.2.7 SPI_INIT (Function #6)
      * 1.1.2.8 SPI_ASSERT_CS (Function #7)
      * 1.1.2.9 SPI_DEASSERT_CS (Function #8)
      * 1.1.2.10 SPI_TRANSFER_BYTE (Function #9)
      * 1.1.2.11 SPI_TRANSFER_BUFFER (Function #10)
      * 1.1.2.12 SPI_RECV_BYTE (Function #11)
      * 1.1.2.13 SPI_RECV_BUFFER (Function #12)
      * 1.1.2.14 SPI_SEND_BYTE (Function #13)
      * 1.1.2.15 SPI_SEND_BUFFER (Function #14)
      * 1.1.2.16 CHECK_ATA_SUPPORT (Function #15)
      * 1.1.2.17 ATA_INIT (Function #16)
      * 1.1.2.18 ATA_READ_SECTORS (Function #17)
      * 1.1.2.19 ATA_WRITE_SECTORS (Function #18)
      * 1.1.2.20 ATA_IDENTIFY (Function #19)
  * 1.2. Character device IO routines (TRAP 14)
    * 1.2.1 Example Usage
    * 1.2.2 Functions
      * 1.2.2.1 PRINT (Function #0)
      * 1.2.2.2 PRINTLN (Function #1)
      * 1.2.2.3 SENDCHAR (Function #2)
      * 1.2.2.4 RECVCHAR (Function #3)
      * 1.2.2.5 PRINTCHAR (Function #4)
      * 1.2.2.6 SETCURSOR (Function #5)
      * 1.2.2.7 CHECKCHAR (Function #6)
      * 1.2.2.8 CHECK_DEVICE_SUPPORT (Function #7)
      * 1.2.2.9 GET_DEVICE_COUNT (Function #8)
      * 1.2.2.10 GET_DEVICE (Function #9)
      * 1.2.2.11 ADD_DEVICE (Function #10)
      * 1.2.2.12 DEVICE_RECVCHAR (Function #11)
      * 1.2.2.13 DEVICE_SENDCHAR (Function #12)
      * 1.2.2.14 DEVICE_CHECKCHAR (Function #13)
      * 1.2.2.15 RESERVED (Function #14)
      * 1.2.2.16 RESERVED (Function #15)
      * 1.2.2.17 DEVICE_CTRL (Function #16)
      * 1.2.2.18 INPUTCHAR (Function #17)
      * 1.2.2.19 CHECKINPUT (Function #18)
  * 1.3. Easy68k compatibility layer (TRAP 15)
    * 1.3.1 Example Usage
    * 1.3.2 Functions
      * 1.3.2.1 PRINTLN_LEN (Function #0)
      * 1.3.2.2 PRINT_LEN (Function #1)
      * 1.3.2.3 READSTR (Function #2)
      * 1.3.2.4 DISPLAYNUM_SIGNED (Function #3)
      * 1.3.2.5 READNUM (Function #4)
      * 1.3.2.6 READCHAR (Function #5)
      * 1.3.2.7 SENDCHAR (Function #6)
      * 1.3.2.8 CHECKINPUT (Function #7)
      * 1.3.2.9 GETUPTICKS (Function #8)
      * 1.3.2.10 TERMINATE (Function #9)
      * 1.3.2.11 MOVEXY (Function #11)
      * 1.3.2.12 SETECHO (Function #12)
      * 1.3.2.13 PRINTLN_SZ (Function #13)
      * 1.3.2.14 PRINT_SZ (Function #14)
      * 1.3.2.15 PRINT_UNSIGNED (Function #15)
      * 1.3.2.16 SETDISPLAY (Function #16)
      * 1.3.2.17 PRINTSZ_NUM (Function #17)
      * 1.3.2.18 PRINTSZ_READ_NUM (Function #18)
      * 1.3.2.19 PRINTNUM_SIGNED_WIDTH (Function #20)
* 2. System Data Area memory map
  * 2.1. Exception vectors
  * 2.2. Basic System Data Block (SDB)
  * 2.3. Extension Function Pointer Table (EFPT)
  * 2.4. Video IO Data Area (VDA)
    * 2.4.1. Video Data Block (VDB)
  * 2.5. Firmware Reserved Area 1 (Internal)
  * 2.6. Firmware Reserved Area 2 (BSS)
* 3. Character Devices
  * 3.1 General Information
  * 3.2. The `CHAR_DEVICE` structure
  * 3.3. Device function calling conventions

# 1. TRAP Interfaces for User Code

The firmware provides a set of basic IO routines intended for use
from user code. Because some of these routines may require the CPU
to be in Supervisor mode, they are accessed via the M68k TRAP
instruction. Execution of this instruction causes the CPU to jump
to an exception vector (initialized by the firmware) as if an
exception were being processed. Context is stored on the stack
and Supervisor mode is entered automatically.

Currently, three TRAPs are used by the firmware:

* TRAP 13 provides rosco_m68k's native block device IO routines (SD)
* TRAP 14 provides rosco_m68k's native serial device IO routines (UART/Console)
* TRAP 15 provides basic IO routines that are broadly Easy68k-compatible(*)

All other TRAP vectors are unused at boot-time (and initialized to no-op
handlers). Extension code, drivers and user code are free to re-use
these vectors as they see fit.

The standard TRAP handlers use various registers as arguments, and
may also use one or more registers to return values to the 
calling code. These registers are documented in the following 
sections. In all cases, all registers other than those stated
in this documentation are preserved.

**Note** that the standard firmware TRAP handlers rely on the 
integrity of the System Data Area in memory. If this area is
reused or corrupted, these routines may not function properly.

(*) Note that the Easy68k layer may optionally be omitted from the 
firmware build. In such cases, the functions offered on TRAP 15 will
not be available, and that TRAP vector may be reused.

## 1.1. Block device IO (TRAP 13)

TRAP 13 provides access to the block-device IO functionality
provided by the firmware. At present, this means SD cards.

Register D0.L is expected to contain the function code (note that
this is different to the TRAP 14 handler!). Other arguments
depend on the specific function, and are documented below.

In all cases, registers used as aguments (including D0.L) are **not** 
guaranteed to be preserved. All other registers are preserved.

Function codes outside the range documented here are considered
reserved for future expansion, and should not be used by integrators
or other code. The exception to this is where the user program 
is intended to take complete control of the system, in which case
the TRAP handlers, and the SDA that underpins them, may be entirely
replaced in the scope of that program.

### 1.1.1 Example Usage

An example of using function 2 (SD_READ_BLOCK) of TRAP 13 is:

```
SD_read_block::
    movem.l A0-A2/D1,-(A7)
    move.l  (20,A7),A1
    move.l  (24,A7),D1
    move.l  (28,A7),A2
    move.l  #2,D0
    trap    #13
    movem.l (A7)+,A0-A2/D1
    rts
```

With GCC as the compiler, this could be called directly from C, 
with the prototype: 

```
bool SD_read_block(SDCard *sd, uint32_t block, void *buf);
```
 
### 1.1.2 Functions

#### 1.1.2.1 CHECK_SD_SUPPORT (Function #0)

**Arguments**

* D0.L - 0 (Function code)

**Modifies**

* `D0.L` - Return value

**Description**

Determine whether SD Card support is present in the Firmware.

Where SD Card support is available, this will return the magic
number $1234FEDC in D0.L. 

Any other value indicates that support is not available. In this
case, none of the SD Card routines should be used.

With Firmware 2.0, SD support is always available. However, this
routine is retained to allow easy backward-compatibility.

#### 1.1.2.2 SD_INIT (Function #1)

**Arguments**

* `D0.L` - 1 (Function code)
* `A1`   - Pointer to an SDCard struct

**Modifies**

* `D0.L` - Return value
* `A0`   - Modified arbitrarily
* `A1`   - May be modified arbitrarily

**Description**

Attempt to initialize the SD Card. 

The memory pointed to by A1 will be a SDCard structure - see
sdfat.h in the standard libraries for details.

The return value in D0.L will be one of the SDInitStatus
codes - `SD_INIT_OK` (ordinal 0) indicates success, while failure 
is indicated by any other value. Again, see sdfat.h for details.

#### 1.1.2.3 SD_READ_BLOCK (Function #2)

**Arguments**

* `D0.L` - 2 (Function code)
* `D1.L` - Block number to read
* `A1`   - Pointer to an initialized SDCard struct
* `A2`   - Pointer to a 512-byte buffer

**Modifies**

* `D0.L` - Return value
* `D1.L` - May be modified arbitrarily
* `A0`   - Modified arbitrarily
* `A1`   - May be modified arbitrarily
* `A2`   - May be modified arbitrarily

**Description**

Read a 512-byte block from the SD Card into the buffer
pointed to by A2.

Returns 0 in D0.L to indicate failure, any other value
indicates success.

#### 1.1.2.4 SD_WRITE_BLOCK (Function #3)

**Arguments**

* `D0.L` - 3 (Function code)
* `D1.L` - Block number to write
* `A1`   - Pointer to an initialized SDCard struct
* `A2`   - Pointer to a 512-byte buffer

**Modifies**

* `D0.L` - Return value
* `D1.L` - May be modified arbitrarily
* `A0`   - Modified arbitrarily
* `A1`   - May be modified arbitrarily
* `A2`   - May be modified arbitrarily

**Description**

Write a 512-byte block from the buffer pointed to by A2 to
the SD Card..

Returns 0 in D0.L to indicate failure, any other value
indicates success.

#### 1.1.2.5 SD_READ_REGISTER (Function #4)

**Arguments**

* `D0.L` - 4 (Function code)
* `D1.L` - Register number to read (translates directly to a CMD)
* `A1`   - Pointer to an initialized SDCard struct
* `A2`   - Pointer to a 16-byte buffer

**Modifies**

* `D0.L` - Return value
* `D1.L` - May be modified arbitrarily
* `A0`   - Modified arbitrarily
* `A1`   - May be modified arbitrarily
* `A2`   - May be modified arbitrarily

**Description**

Read an SD Card register block from the SD Card into the buffer
pointed to by A2.

Returns 0 in D0.L to indicate failure, any other value
indicates success.

#### 1.1.2.6 CHECK_SPI (Function #5)

**Arguments**

* `D0.L` - 5 (Function code)

**Modifies**

* `D0.L` - Return value

**Description**

Determine whether SPI support is present in the Firmware.

Where SPI Card support is available, this will return the magic
number $1234FEDC in D0.L. 

Any other value indicates that support is not available. In this
case, none of the SPI routines should be used.

With Firmware 2.0, SD support is always available. However, this
routine is retained to allow easy backward-compatibility.

#### 1.1.2.7 SPI_INIT (Function #6)

**Arguments**

* `D0.L` - 6 (Function code)

**Modifies**

* `D0.L` - Result (0 = OK, otherwise failed)
* `A0`   - Modified arbitrarily

**Description**

Initialize the SPI interface. This sets the SPI pins to the 
appropriate modes (input vs output).

#### 1.1.2.8 SPI_ASSERT_CS (Function #7)

**Arguments**

* `D0.L` - 7 (Function code)
* `D1.L` - Device number (0 or 1)

**Modifies**

* `D0.L` - Result (0 = failed, otherwise OK)
* `A0`   - Modified arbitrarily

**Description**

Assert the appropriate CS line. Note that asserting one line 
*does not* automatically deassert the other!

#### 1.1.2.9 SPI_DEASSERT_CS (Function #8)

**Arguments**

* `D0.L` - 8 (Function code)
* `D1.L` - Device number (0 or 1)

**Modifies**

* `D0.L` - Result (0 = failed, otherwise OK)
* `A0`   - Modified arbitrarily

**Description**

Deassert the appropriate CS line. 

#### 1.1.2.10 SPI_TRANSFER_BYTE (Function #9)

**Arguments**

* `D0.L` - 9 (Function code)
* `D1.L` - Byte to send

**Modifies**

* `D0.L` - Byte received
* `A0`   - Modified arbitrarily

**Description**

Send and receive a byte (exchange) via SPI.

#### 1.1.2.11 SPI_TRANSFER_BUFFER (Function #10)

**Arguments**

* `D0.L` - 10 (Function code)
* `A1.L` - Pointer to buffer
* `D1.L` - Number of bytes

**Modifies**

* `D0.L` - Count exchanged
* `A0`   - Modified arbitrarily
* `A1`   - Possibly modified

**Description**

Transfer count (`D1.L`) bytes from the given buffer, exchanging them 
with bytes received at the same time (and returned in the buffer).

Note that the buffer pointer may be modified, so keep a copy locally.

#### 1.1.2.12 SPI_RECV_BYTE (Function #11)

**Arguments**

* `D0.L` - 11 (Function code)

**Modifies**

* `D0.L` - Byte received
* `A0`   - Modified arbitrarily

**Description**

Send and receive a byte (exchange) via SPI.

#### 1.1.2.13 SPI_RECV_BUFFER (Function #12)

**Arguments**

* `D0.L` - 12 (Function code)
* `A1.L` - Pointer to buffer
* `D1.L` - Number of bytes

**Modifies**

* `D0.L` - Count received
* `A0`   - Modified arbitrarily
* `A1`   - Possibly modified

**Description**

Receive count (`D1.L`) bytes into the given buffer.
Note that the buffer pointer may be modified, so keep a copy locally.

#### 1.1.2.14 SPI_SEND_BYTE (Function #13)

**Arguments**

* `D0.L` - 13 (Function code)
* `D1.L` - Byte to send

**Modifies**

* `A0`   - Modified arbitrarily
* `D1.L` - Possibly trashed

**Description**

Send and receive a byte (exchange) via SPI.

#### 1.1.2.15 SPI_SEND_BUFFER (Function #14)

**Arguments**

* `D0.L` - 14 (Function code)
* `A1.L` - Pointer to buffer
* `D1.L` - Number of bytes

**Modifies**

* `D0.L` - Count received
* `A0`   - Modified arbitrarily
* `A1`   - Possibly modified

**Description**

Send count (`D1.L`) bytes from the given buffer.
Note that the buffer pointer may be modified, so keep a copy locally.

#### 1.1.2.16 CHECK_ATA_SUPPORT (Function #15)

**Arguments**

* `D0.L` - 15 (Function code)

**Modifies**

* `D0.L` - Return value

**Description**

Determine whether ATA support is present in the Firmware.

Where ATA support is available, this will return the magic
number $1234FEDC in D0.L. 

Any other value indicates that support is not available. In this
case, none of the ATA routines should be used.

With Firmware 2.0, ATA support is always available. However, this
routine is retained to allow easy backward-compatibility.

#### 1.1.2.17 ATA_INIT (Function #16)

**Arguments**

* `D0.L` - 16 (Function code)
* `D1.L` - 0 (ATA Master) or 1 (ATA slave)
* `A1`   - Pointer to an ATADevice struct

**Modifies**

* `D0.L` - Return value
* `D1.L` - May be modified arbitrarily
* `A0`   - Modified arbitrarily
* `A1`   - May be modified arbitrarily

**Description**

Attempt to initialize an ATA device. 

The memory pointed to by A1 will be a ATADevice structure - see
ata.h in the standard libraries for details.

The return value in D0.L will be one of the ATAInitStatus
codes - `ATA_INIT_OK` (ordinal 0) indicates success, while failure 
is indicated by any other value. Again, see ata.h for details.

#### 1.1.2.18 ATA_READ_SECTORS (Function #17)

**Arguments**

* `D0.L` - 17 (Function code)
* `D1.L` - LBA sector number to read
* `D2.L` - Number of sectors to read
* `A1`   - Pointer to an initialized ATADevice struct
* `A2`   - Pointer to a (512 * D2.L)-byte buffer

**Modifies**

* `D0.L` - Return value
* `D1.L` - May be modified arbitrarily
* `A0`   - Modified arbitrarily
* `A1`   - May be modified arbitrarily
* `A2`   - May be modified arbitrarily

**Description**

Read the number of 512-byte sectors (indicated by `D2.L`) from the 
ATA device into the buffer pointed to by `A2`.

Returns the actual number of sectors read in `D0.L`.

#### 1.1.2.19 ATA_WRITE_SECTORS (Function #18)

**Arguments**

* `D0.L` - 18 (Function code)
* `D1.L` - LBA sector number to write
* `D2.L` - Number of sectors to write
* `A1`   - Pointer to an initialized ATADevice struct
* `A2`   - Pointer to a (512 * D2.L)-byte buffer

**Modifies**

* `D0.L` - Return value
* `D1.L` - May be modified arbitrarily
* `A0`   - Modified arbitrarily
* `A1`   - May be modified arbitrarily
* `A2`   - May be modified arbitrarily

**Description**

Write the number of 512-byte sectors (indicated by `D2.L`) from the 
buffer pointed to by `A2` to the ATA device, starting at the LBA sector
indicated by `D1.L`.

Returns the actual number of sectors written in `D0.L`.

#### 1.1.2.20 ATA_IDENTIFY (Function #19)

**Arguments**

* `D0.L` - 19 (Function code)
* `A1`   - Pointer to an initialized ATADevice struct
* `A2`   - Pointer to a 512-byte buffer

**Modifies**

* `D0.L` - Return value (0 = failed, 1 = success)
* `D1.L` - May be modified arbitrarily
* `A0`   - Modified arbitrarily
* `A1`   - May be modified arbitrarily
* `A2`   - May be modified arbitrarily

**Description**

Issue an ATA `IDENTIFY` command to the specified `ATADevice`, and return
the results in the supplied buffer.

Returns 1 in `D0.L` if successful, 0 otherwise.

## 1.2. Basic IO routines (TRAP 14)

TRAP 14 provides access to the character-based IO functionality 
provided by the firmware. This includes the default UART and
console.

Register D1.L is expected to contain the function code. Other arguments
depend on the specific function, and are documented below.

In all cases, registers used as aguments (**excluding** D1.L, which 
will be preserved unless explicitly documented as used for a return
value) are **not** guaranteed to be preserved. All 
other registers are preserved.

Function codes outside the range documented here are considered
reserved for future expansion, and should not be used by integrators
or other code. The exception to this is where the user program 
is intended to take complete control of the system, in which case
the TRAP handlers, and the SDA that underpins them, may be entirely
replaced in the scope of that program.

### 1.2.1 Example Usage

An example of calling function 1 (PRINTLN) of TRAP 14 is:

```
DO_PRINTLN:
    move.l  #1,D1
    lea.l   MYSTRING,A0
    trap    #14

; ... later

MYSTRING    dc.b    "Hello, World!", 0
```

### 1.2.2 Functions

#### 1.2.2.1 PRINT (Function #0)

**Arguments**

* `D1.L` - 0 (Function code)
* `A0`   - Pointer to null-terminated string to print

**Modifies**

* `A0`   - Will point to the memory location following the null terminator

**Description**

Print the null-terminated string pointed to by `A0` to the system's
*default console*. 

Where the default console is a serial terminal, this routine may block until
there is space in the UART's transmit buffer for the character - as such, 
it is not suitable for use in time- or latency-critical code (e.g. interrupt 
handlers).

The default console is initialized at boot-time by the firmware, and 
may be the V9958 console (where available), or the *default serial UART*.
For details on the default UART, see the `SENDCHAR` function.

System integrators and third-party hardware developers may also override
the default console (for example to output to third-party video 
hardware). See section 2.3 for details.

#### 1.2.2.2 PRINTLN (Function #1)

**Arguments**

* `D1.L` - 1 (Function code)
* `A0`   - Pointer to null-terminated string to print

**Modifies**

* `A0`   - Will point to the memory location following the null terminator

**Description**

Print the null-terminated string pointed to by `A0` to the system's
*default console* followed by a CR/LF sequence.

Where the default console is a serial terminal, this routine may block until
there is space in the UART's transmit buffer for the character - as such, 
it is not suitable for use in time- or latency-critical code (e.g. interrupt 
handlers).

The default console is initialized at boot-time by the firmware, and 
may be the V9958 console (where available), or the *default serial UART*.
For details on the default UART, see the `SENDCHAR` function.

System integrators and third-party hardware developers may also override
the default console (for example to output to third-party video 
hardware). See section 2.3 for details.

#### 1.2.2.3 SENDCHAR (Function #2)

**Arguments**

* `D1.L` - 2 (Function code)
* `D0.B` - Character to send

**Modifies**

Nothing

**Description**

Synchronously send the character contained in `D0.B` via the system's
*default UART*. This routine may block until there is space in the 
UART's transmit buffer for the character - as such, it is not suitable
for use in time- or latency-critical code (e.g. interrupt handlers).

The default UART is initialized at boot-time by the firmware, and
will generally be the "best" serial UART available (with the 
fallback being the MC68901 UART that is expected to be always installed).

System integrators and third-party hardware developers may also override
the default UART (for example to utilise third-party hardware). 
See section 2.3 for details.

#### 1.2.2.4 RECVCHAR (Function #3)

**Arguments**

* `D1.L` - 3 (Function code)

**Modifies**

* `D0.B` - Returns the received character

**Description**

Synchronously receive a character via the system's *default UART*,
and return it in `D0.B`. If no character is immediately available, this
routine will block until one becomes available. As such, it is not suitable
for use in time- or latency-critical code (e.g. interrupt handlers).

The default UART is initialized at boot-time by the firmware, and
will generally be the "best" serial UART available (with the 
fallback being the MC68901 UART that is expected to be always installed).

System integrators and third-party hardware developers may also override
the default UART (for example to utilise third-party hardware). 
See section 2.3 for details.

#### 1.2.2.5 PRINTCHAR (Function #4)

**Arguments**

* `D1.L` - 4 (Function code)
* `D0.B` - Character to print

**Modifies**

Nothing

**Description**

Print the character in `D0.B` to the system's *default console*.

Where the default console is a serial terminal, this routine may block until
there is space in the UART's transmit buffer for the character - as such, 
it is not suitable for use in time- or latency-critical code (e.g. interrupt 
handlers).

The default console is initialized at boot-time by the firmware, and 
may be the V9958 console (where available), or the *default serial UART*.
For details on the default UART, see the `SENDCHAR` function.

System integrators and third-party hardware developers may also override
the default console (for example to output to third-party video 
hardware). See section 2.3 for details.

#### 1.2.2.6 SETCURSOR (Function #5)

**Arguments**

* `D1.L` - 5 (Function code)
* `D0.B` - 0 to hide cursor, non-zero to show

**Modifies**

Nothing

**Description**

Show or hide the cursor on the *default console*. Where this is not possible]
(e.g. where the default console is a serial terminal) this routine does
nothing.

The default console is initialized at boot-time by the firmware, and 
may be the V9958 console (where available), or the *default serial UART*.
For details on the default UART, see the `SENDCHAR` function.

System integrators and third-party hardware developers may also override
the default console (for example to output to third-party video 
hardware). See section 2.3 for details.

#### 1.2.2.7 CHECKCHAR (Function #6)

**Arguments**

* `D1.L` - 6 (Function code)

**Modifies**

* `D0.B` - 0 if no character waiting, nonzero otherwise

**Description**

Determine whether the system's *default UART* has a character waiting to
be received, returning non-zero in `D0.B` if so, zero otherwise. 

This can be used to determine whether a call to `RECVCHAR` will block.
Note that this function may clear error flags and other status information.

The default UART is initialized at boot-time by the firmware, and
will generally be the "best" serial UART available (with the 
fallback being the MC68901 UART that is expected to be always installed).

System integrators and third-party hardware developers may also override
the default UART (for example to utilise third-party hardware). 
See section 2.3 for details.

#### 1.2.2.8 CHECK_DEVICE_SUPPORT (Function #7)

**Arguments**

* `D1.L` - 7 (Function code)

**Modifies**

* `D0.L` - Return value

**Description**

Check if the new _Character Device Support_ (available since firmware
2.30) is available.

Where support is available, this will return the magic number $1234FEDC 
in `D0.L`.

Any other value indicates that support is not available. In this
case, none of the character device routines should be used.

#### 1.2.2.9 GET_DEVICE_COUNT (Function #8)

**Arguments**

* `D1.L` - 8 (Function code)

**Modifies**

* `D0.W` - Return value

**Description**

Returns the number of character devices the firmware knows about in 
`D0.W`.

#### 1.2.2.10 GET_DEVICE (Function #9)

**Arguments**

* `D1.L` - 9 (Function code)
* `D0.W` - 0-based index of the desired device
* `A0`   - Points to a `CHAR_DEVICE` structure (32 bytes)

**Modifies**

* `D0.B` - `0` if the device number is not valid, nonzero otherwise
* `A0`   - Trashed

**Description**

Populates the supplied device structure with data for the
specified device number. 

Note that the data is copied into the structure you supply,
you cannot use this to modify system data structures.

#### 1.2.2.11 ADD_DEVICE (Function #10)

**Arguments**

* `A0`   - Pointer to a new `CHAR_DEVICE` structure
* `D1.L` - 10 (Function code)

**Modifies**

* `D0.B` - 0-15 index of the device. Any other value indicates failure.

**Description**

Adds a new character device at the next available slot. There
are sixteen slots - if they are all full, this function will return
a value >15 to indicate failure.

#### 1.2.2.12 DEVICE_RECVCHAR (Function #11)

**Arguments**

* `D1.L` - 11 (Function code)
* `A0`   - Pointer to the `CHAR_DEVICE` structure (obtained via `GET_DEVICE`)

**Modifies**

* `D0.B` - Returns the received character
* `A0`   - Trashed 

**Description**

Synchronously receive a character via the character device in the supplied
`CHAR_DEVICE` structure, and return it in `D0.B`. 

If no character is immediately available, this routine _may_ block until one
becomes available. As such, it is not suitable for use in time- or 
latency-critical code (e.g. interrupt handlers).

#### 1.2.2.13 DEVICE_SENDCHAR (Function #12)

**Arguments**

* `D1.L` - 12 (Function code)
* `D0.B` - Character to send
* `A0`   - Pointer to the `CHAR_DEVICE` structure (obtained via `GET_DEVICE`)

**Modifies**

* `A0`   - Trashed 

**Description**

Synchronously send the character contained in `D0.B` via the character 
device referenced by the supplied `CHAR_DEVICE` structure. 

This routine _may_ block until there is space in the device's buffer
for the character - as such, it is not suitable for use in time- or 
latency-critical code (e.g. interrupt handlers).

#### 1.2.2.14 DEVICE_CHECKCHAR (Function #13)

**Arguments**

* `D1.L` - 13 (Function code)
* `A0`   - Pointer to the `CHAR_DEVICE` structure (obtained via `GET_DEVICE`)

**Modifies**

* `D0.B` - 0 if no character waiting, nonzero otherwise
* `A0`   - Trashed 

**Description**

Determine whether the the character device referenced by the supplied
 `CHAR_DEVICE` structure has a character waiting to be received, returning 
 non-zero in `D0.B` if so, zero otherwise. 

This can be used to determine whether a call to `DEVICE_RECVCHAR` will 
block if called for the same device.

Note that this function _may_ clear error flags and other status information.

#### 1.2.2.15 RESERVED (Function #14)

This function code is reserved for future use and should not be called.

#### 1.2.2.16 RESERVED (Function #15)

This function code is reserved for future use and should not be called.

#### 1.2.2.17 DEVICE_CTRL (Function #16)

**Arguments**

* `D1.L` - 16 (Function code)
* `D0.L` - Command (low-byte) and optional data
* `D2.L` - 32-bit command-specific parameter
* `A0`   - Pointer to the `CHAR_DEVICE` structure (obtained via `GET_DEVICE`)

**Modifies**

* `D0.L` - 0 if unknown command, device/command-specific result otherwise
* `A0`   - Trashed 

**Description**

Send a device-specific command, with optional parameters in the high
24 bits of `D0` and the full 32-bits of `D2`.

The commands supported, the parameters they take, and the return value
of this function are all device specific. See the specific documentation
for the device (which can be identified by the device type in the 
`CHAR_DEVICE` block) for details.

#### 1.2.2.18 INPUTCHAR (Function #17)

**Arguments**

* `D1.L` - 17 (Function code)

**Modifies**

* `D0.B` - The read character

**Description**

Read a character from the default input device. Will block until a
character is available.

In systems where the rosco_m68k (or compatible) keyboard is connected to the
second UART, this will check the keyboard. 

Otherwise, the default input will usually be the main UART.

#### 1.2.2.19 CHECKINPUT (Function #18)

**Arguments**

* `D1.L` - 18 (Function code)

**Modifies**

* `D0.B` - 0 if no character waiting, nonzero otherwise

**Description**

Check the default input device for a waiting character.

In systems where the rosco_m68k (or compatible) keyboard is connected to the
second UART, this will check the keyboard. 

Otherwise, the default input will usually be the main UART.

## 1.3. Easy68k compatibility layer (TRAP 15)

TRAP 15 provides an (optional, included by default) Easy68k-compatible
IO interface. The aim is to allow many common Easy68k programs to be 
run on the rosco_m68k without modification.

Currently only a subset of the Easy68K tasks are implemented. Output 
will always go to the **default console** (See section 1.1.2.1) and input
will be via the **default UART** (See section 1.1.2.3). Depending on
capabilities of the input and output devices, some functions may not
be available in all contexts (for example, cursor movement and color
setting will not be available where output is via UART).

These functions are called by loading the task number into `D0` and setting
up other registers as documented below, and then calling `TRAP #15`.

### 1.3.1 Example Usage

An example of calling function 0 (PRINTLN with length) of TRAP 15 is:

```
DO_EASY68K_PRINTLN_LEN:
    move.l  #0,D0
    move.w  #13,D1
    lea.l   MYSTRING,A1
    trap    #15

; ... later

MYSTRING    dc.b    "Hello, World!"
```

### 1.3.2 Functions

#### 1.3.2.1 PRINTLN_LEN (Function #0)

**Arguments**

* `D0.L` - 0 (Function code)
* `D1.W` - String length (max 255)
* `A1` - Points to the string

**Modifies**

* `D1` - Trashed
* `A1` - Points to memory location after the last printed character

**Description**

Print the string at (A1), D1.W bytes long (max 255) with carriage return
and line feed (CR, LF) to the system's *default console*. 

See also: Function 13

#### 1.3.2.2 PRINT_LEN (Function #1)

**Arguments**

* `D0.L` - 1 (Function code)
* `D1.W` - String length (max 255)
* `A1` - Points to the string

**Modifies**

* `D1` - Trashed
* `A1` - Points to memory location after the last printed character

**Description**

Print the string at (A1), D1.W bytes long (max 255) **without** carriage return
and line feed (CR, LF) to the system's *default console*. 

See also: Function 14

#### 1.3.2.3 READSTR (Function #2)

**Arguments**

* `D0.L` - 2 (Function code)
* `A0` - Pointer to buffer in which to store string

**Modifies**

* `D1.W` - Returns length of read string (Max 80)
* `(A1)` - Returns the string

**Description**

Read string from keyboard and store at (A1), NULL terminated, length retuned in D1.W (max 80). 

#### 1.3.2.4 DISPLAYNUM_SIGNED (Function #3)

**Arguments**

* `D0.L` - 3 (Function code)
* `D1.L` - Number to display

**Modifies**

* `D1` - Possibly trashed

**Description**

Print signed number in D1.L in decimal (in smallest field) to the system's
*default console*.

See also: Functions 15 & 20

#### 1.3.2.5 READNUM (Function #4)

**Arguments**

* `D0.L` - 4 (Function code)

**Modifies**

* `D1.L` - Returns the read number

**Description**

Read a number from the keyboard into D1.L.

See also: Functions 15 & 20

#### 1.3.2.6 READCHAR (Function #5)

**Arguments**

* `D0.L` - 5 (Function code)

**Modifies**

* `D1.B` - The read character.

**Description**

Read single character from the keyboard into D1.B.

**Note** Unlike Easy68k, this will block until input is available.

#### 1.3.2.7 SENDCHAR (Function #6)

**Arguments**

* `D0.L` - 6 (Function code)
* `D1.B` - Character to display

**Modifies**

* `D1` - Trashed

**Description**

Display single character in D1.B.

#### 1.3.2.8 CHECKINPUT (Function #7)

**Arguments**

* `D0.L` - 7 (Function code)

**Modifies**

* `D1.B` - 1 if input pending, 0 otherwise

**Description**

Set D1.B to 1 if keyboard input is pending, otherwise set to 0. 
Use Function 5 to read pending key.

**Notes**

**This function is to be avoided if possible**.

Using this function doesn't make a lot of sense in the current rosco_m68k 
environment, because all input is via the UART. This means that, while this 
function _is_ implemented, its meaning is subtly different from the Easy68K
equivalent - here true result means there is serial data waiting, not 
specifically a user keypress.

That's not the worst of it, however - if the MC68901 UART is currently the
system's *default UART*, **using this task may actually be harmful**.
It may silently clear any errors the UART is signalling. This is 
because it works by reading the Buffer Full indicator bit in the receiver
status register, which has the effect of _also_ clearing the error flags
(e.g. overrun) in that same register. Normally, these would be checked 
during a receive, but this task doesn't check them _at all_ and so could 
lead to errors being ignored / discarded.

So, if you must use this task, keep all this in mind! 

See also: Function 5                       

#### 1.3.2.9 GETUPTICKS (Function #8)

**Arguments**

* `D0.L` - 8 (Function code)

**Modifies**

* `D1.L` - Current number of upticks

**Description**

Return upticks (time in hundredths of a second since boot) in D1.L.

**Notes**

Easy68K defines this function as returning the count of "hundredths of a
second since midnight", but since the rosco_m68k doesn't have a real-time 
clock this just returns the system tick counter from the system data 
block (SDB), which is updated by the system tick handler (driven by a 
programmable interrupt which may be disabled).

Unfortunately this counter is only word-sized, and will roll over every
655.36 seconds (or 10.92 minutes if you prefer). It also isn't updated at
exactly 100HZ, so all-in-all this isn't really going to return "hundredths 
of a second since boot" unless you aren't particularly strict with your 
definition of "hundredths" and the computer was started less than ~11 minutes ago.

If you do need any kind of precision timing, you'll have to design some sort
of expansion that connects to the expansion bus :) 

#### 1.3.2.10 TERMINATE (Function #9)

**Arguments**

* `D0.L` - 9 (Function code)

**Modifies**

Nothing

**Description**

Terminate the program (Disables interrupts and halts the CPU).

This will never return - the only way back is through wetware
intervention.

#### 1.3.2.11 MOVEXY (Function #11)

**Arguments**

* `D0.L` - 11 (Function code)
* `D1.W` - Encoded position (see description)

**Modifies**

* `D1` - Trashed
* `D2` - Trashed
* `A0` - Trashed

**Description**

Position the cursor at ROW, COL. 

Support is not mandatory for any given console. E.g. requires ANSI support
on the receiving terminal where the default console is a UART.

* The high byte of D1.W holds the COL number (0-79),
* The low byte holds the ROW number (0-31).

0,0 is top left 79,31 is the bottom right (depending on terminal size).
Out of range coordinates are usually ignored (depends on terminal).

**Clear Screen : Set D1.W to $FF00**.

#### 1.3.2.12 SETECHO (Function #12)

**Arguments**

* `D0.L` - 12 (Function code)
* `D1.B` - 0 to disable, 1 to enable

**Modifies**

* `D1` - Trashed

**Description**

Keyboard Echo.

* D1.B = 0 to turn off keyboard echo.
* D1.B = non zero to enable it (default).

Echo is restored on 'Reset'.

#### 1.3.2.13 PRINTLN_SZ (Function #13)

**Arguments**

* `D0.L` - 13 (Function code)
* `A1` - Points to the string

**Modifies**

* `D1` - Trashed
* `A1` - Points to memory location after the last printed character

**Description**

Print the NULL-terminated string at (A1) with carriage return
and line feed (CR, LF) to the system's *default console*. 

See also: Function 0

#### 1.3.2.14 PRINT_SZ (Function #14)

**Arguments**

* `D0.L` - 14 (Function code)
* `A1` - Points to the string

**Modifies**

* `D1` - Trashed
* `A1` - Points to memory location after the last printed character

**Description**

Print the NULL-terminated string at (A1) **without** carriage return
and line feed (CR, LF) to the system's *default console*. 

See also: Function 1

#### 1.3.2.15 PRINT_UNSIGNED (Function #15)

**Arguments**

* `D0.L` - 15 (Function code)
* `D1.L` - Number to print
* `D2.B` - Base (2 through 36)

**Modifies**

* `D1` - Trashed
* `D2` - Trashed

**Description**

Display the unsigned number in D1.L converted to number base (2 
through 36) contained in D2.B.

For example, to display D1.L in base16 put 16 in D2.B

Values of D2.B outside the range 2 to 36 inclusive are ignored.

#### 1.3.2.16 SETDISPLAY (Function #16)

**Arguments**

* `D0.L` - 16 (Function code)
* `D1.B` - Option to set (see description)

**Modifies**

* `D1` - Trashed

**Description**

Adjust display properties

* D1.B = 0 to turn off the display of the input prompt.
* D1.B = 1 to turn on the display of the input prompt. (default)
* D1.B = 2 do not display a line feed when Enter pressed during Trap task #2 input
* D1.B = 3 display a line feed when Enter key pressed during Trap task #2 input (default)

Other values of D1 reserved for future use.

Input prompt display is enabled by default and by 'Reset'.

#### 1.3.2.17 PRINTSZ_NUM (Function #17)

**Arguments**

* `D0.L` - 17 (Function code)
* `D1.L` - Number to display
* `A1` - Pointer to string

**Modifies**

* `D1` - Trashed
* `A1` - Trashed

**Description**

Combination of functions 14 & 3.

* Display the NULL terminated string at (A1) without CR, LF then
* Display the number in D1.L, in base 10

#### 1.3.2.18 PRINTSZ_READ_NUM (Function #18)

**Arguments**

* `D0.L` - 18 (Function code)
* `A1` - Pointer to string

**Modifies**

* `D1.L` - Returns the resulting number
* `A1` - Trashed

**Description**

Combination of functions 14 & 4.

* Display the NULL terminated string at (A1) without CR, LF then
* Read a number from the keyboard into D1.L.

#### 1.3.2.19 PRINTNUM_SIGNED_WIDTH (Function #20)

**Arguments**

* `D0.L` - 20 (Function code)
* `D1.L` - Number to display
* `D2.B` - Field width

**Modifies**

* `D1` - Trashed
* `A1` - Trashed

**Description**

Display signed number in D1.L in decimal in field D2.B columns wide.

#2. System Data Area memory map

As standard, the first 4KB of RAM is reserved for system use. This section
details the layout of this memory area.

It is worth noting that if memory is in high demand and the program
being run intends to take full control of the system (i.e. not make
use of any of the firmware TRAP routines or default exception
handlers) then some of this are may be reused. As this is advanced
usage, it is assumed that you know what you need to keep in 
order for the basic machine to function.

All addresses listed in this section are physical addresses. If you
are programming for a system that has an MMU, you may need
to take virtual addressing into account and translate accordingly.

# 2. System Data Area memory map

## 2.1. Exception vectors

**Start Address**: 0x0
**End Address**: 0x3FF
**Size**: 0x400 (1024 bytes, 1KB)

This area contains the exception vectors for use by the CPU. 
See the MC68010 manual for the layout of this area.

In order to use custom exception handlers, you will want to
replace the appropriate vector with the address of your 
handler function. Writing exception handlers is beyond the
scope of this document.

It should be noted that this can be moved if a 68010 or higher
is in use. To achieve this, place the starting address of the
exception table in the VBR (Vector Base Register).

## 2.2. Basic System Data Block (SDB)

**Start Address**: 0x400
**End Address**: 0x41F
**Size**: 0x20 (32 bytes, 8 longwords)

This area contains the basic system data block, which is reserved
by the system for variable storage and data used by the standard
exception handlers and TRAP routines.

| Address | Size | Description |
|---|---|---|
| 0x400 | 4 | SDB Magic (0xB105D47A) |
| 0x404 | 4 | Status code (set by exception handlers) |
| 0x408 | 2 | Internal counter used by timer tick handler |
| 0x40A | 2 | System flags (see below) |
| 0x40C | 4 | Upticks counter, updated by timer tick handler |
| 0x410 | 4 | Xosera base address (or 0 if not detected) |
| 0x414 | 4 | Size of the first block of contiguious memory |
| 0x418 | 4 | Default UART base address |
| 0x41C | 4 | CPU Info (see below) |

For initialisation and usage, see `bootstrap.S` and the Easy68k `syscalls_asm.S`.

### System flags word (0x40A)

This word contains various flags that control system behaviour. The main use
at the moment is to prevent the system from using the on-board LEDs.

| Bit | Description |
|-----|---|
|  15 | Reserved |
|  14 | Reserved |
|  13 | Reserved |
|  12 | Reserved |
|  11 | Reserved |
|  10 | Reserved |
| 9 | Allow system use of LED1 |
| 8 | Allow system use of LED0 |
| 0-7 | Reserved |

The default value for the flags word is $XFXX (XX being reserved bits which can
have any value). This allows the system to take control of the two LEDs I0 and I1.

User code may clear any of the non-reserved bits to take full control of the appropriate
lines. 

**Note** that changing any reserved bits from their default values will result in 
undefined behaviour and possible data loss.

**Note** that, in the case of total system crash (i.e. a crash that is unrecoverable
without a hardware button-push reset), these bits will not be honored and the system 
will assume full control.

**Note** also that clearing these bits has no effect on the actual state of the relevant
lines, and user code should set the lines to a known state after setting this word.

### CPU Info (0x41C)

This four-byte value encodes the CPU type (3 bits indicating the family version number,
and 29 bits with the approximate multiplied speed measured at boot time).

Where multiple processors are present, this field will refer to the boot CPU.

## 2.3. Extension Function Pointer Table (EFPT)

**Start Address**: 0x420
**End Address**: 0x4FF
**Size**: 0xE0 (224 bytes, 56 pointers)

This area contains pointers to functions which are called by the
firmware and TRAP handlers to achieve various things. 

The purpose of this pointer table is to allow these functions
to be replaced by driver software. For example, the V9958 driver
replaces some of these functions in order to redirect output 
to the video console.

Driver writers can replace functions here in order to hook into
the firmware. The general rules are:

* The pointers can point anywhere, but the function that is pointed to **must** remain at that address!
* On entry to the function, the CPU will be in supervisor mode
* On entry to the function, the SP will reference the supervisor stack

Not all of these functions will be used by the firmware - some are 
designated as for program use (for example, a kernel may use them
to provide its own hooks).

User code **must not** call these functions directly - they 
must be accessed through the public TRAP functions!

| Address | Function |
|---|---|
| 0x420 | FW_PRINT - Print SZ to the default console. |
| 0x424 | FW_PRINTLN - Print SZ to the default console, followed by CRLF |
| 0x428 | FW_PRINTCHAR - Print a character to the default console |
| 0x42C | FW_HALT - Disable interrupts and halt |
| 0x430 | FW_SENDCHAR - Send a character via the default UART | 
| 0x434 | FW_RECVCHAR - Receive a character via the default UART |
| 0x438 | FW_CLRSCR - Clear the default console (where supported) |
| 0x43C | FW_MOVEXY - Move cursor to (X,Y) (see note 1) |
| 0x440 | FW_SETCURSOR - Show (D0.B > 0) or hide (D0.B == 0) the cursor |
| 0x444 | FW_CHECKCHAR - Determine whether a character is available on the default UART |
| 0x448 | FW_PROGRAM_LOADER - The firmware uses this to invoke the program loader (defaults to SD/Kermit) |
| 0x44C | FW_SD_INIT - Initialize SD Card |
| 0x450 | FW_SD_READ - Read from SD Card |
| 0x454 | FW_SD_WRITE - Write to SD Card |
| 0x458 | FW_SD_REG - Read SD Card register |
| 0x45C | FW_SPI_INIT - Intialize SPI subsystem |
| 0x460 | FW_SPI_ASSERT_CS - Assert SPI chip select 0 or 1 |
| 0x464 | FW_SPI_DEASSERT_CS - Deassert SPI chip select 0 or 1 |
| 0x468 | FW_SPI_TRANSFER_BYTE - Transfer (exchange) a byte |
| 0x46C | FW_SPI_TRANSFER_BUFFER - Transfer (exchange) N bytes to/from a buffer |
| 0x470 | FW_SPI_RECV_BYTE - Receive a byte |
| 0x474 | FW_SPI_RECV_BUFFER - Receive N bytes into a buffer |
| 0x478 | FW_SPI_SEND_BYTE - Send a byte |
| 0x47C | FW_SPI_SEND_BUFFER - Send N bytes from a buffer |
| 0x480 | FW_ATA_INIT - Initialize ATA PIO device |
| 0x484 | FW_ATA_READ - Read from ATA device |
| 0x488 | FW_ATA_WRITE - Write to ATA device |
| 0x48C | FW_ATA_IDENT - `IDENTIFY` ATA device |
| 0x490 | FW_PROG_EXIT - Vector used by library code to support the exit() function |
| 0x494 | FW_INPUTCHAR - Blocking read from default input device |
| 0x498 | FW_CHECKINPUT - Check if a character is available on default input device |

**Note 1**: FW_GOTOXY takes the coordinates to move to from D1.W. The high
byte is the X coordinate (Column) and the low byte is the Y coordinate (Row).

**Note 2**: The SD, SPI and ATA routines arguments, modifies and returns are the same as for the TRAPs they 
underlie unless otherwise noted. See section 1 for details.

Arguments, modifies and other information for these functions are the same
as for the TRAP functions they implement. If replacing them, you **must**
adhere to the same interface. The reference implementations can be found in
`bootstrap.S`, `trap14.S` and `sdcard/syscalls_asm.S`.

**Note** that all of these are allowed to block! 

## 2.4. Video IO Data Area (VDA)

**Start Address**: 0x500
**End Address**: 0x117F
**Size**: 0xC80 (3200 bytes)

This area is reserved for use by video subsystems. The specific layout
is dependent on the video subsystem in use.

For example, this area may contain a framebuffer along with
variables and data required by a video driver.

## 2.4.1. Video IO Block (VDB)

**Start Address**: 0x1140
**End Address**: 0x117F
**Size**: 0x40 (64 bytes)

This block of 16 longs is reserved for publicly-available data about installed
video systems. It may be populated by the firmware during detection, or by 
video drivers at load time.

| Address | Size | Description |
|---|---|---|
| 0x1140  | 4 | VDB Magic (0xC0C010C0) |
| 0x1144  | 4 | Reserved |
| 0x1148  | 4 | Reserved |
| 0x114C  | 4 | Reserved |
| 0x1150  | 4 | Reserved |
| 0x1154  | 4 | Reserved |
| 0x1158  | 4 | Reserved |
| 0x115C  | 4 | Reserved |
| 0x1160  | 4 | Reserved |
| 0x1164  | 4 | Reserved |
| 0x1168  | 4 | Reserved |
| 0x116C  | 4 | Reserved |
| 0x1170  | 4 | Reserved |
| 0x1174  | 4 | Reserved |
| 0x1178  | 4 | Reserved |
| 0x117C  | 4 | Xosera base address (or 0 if not detected) |

## 2.5. Firmware Reserved Area 1 (Internal)

**Start Address**: 0x1180
**End Address**: 0x17FF
**Size**: 0x680 (1664 bytes)

This area is reserved for future Firmware expansion.

## 2.6. Firmware Reserved Area 2 (BSS)

**Start Address**: 0x1800
**End Address**: 0x1FFF
**Size**: 0x800 (2048 bytes)

This area is reserved for the firmware's BSS section. The content
and layout of this area may change without notice.

# 2.7. Firmware Version Identifier

**Start Address**: 0xE00100
**End Address**: 0xE00103
**Size**: 3 bytes

The longword at the top of the ROM exception table determines the 
firmware version and some information about its (static) version-related
requirements and capabilities.

Most significant word is flags, least significant word is split into major
(MSB) and minor (LSB) version identifiers.

## Flags:

```
bit 0 - 11: Reserved
bit 12    : Supports Video Data Block (Version 2.5+)
bit 13    : Flashable ROM (i.e. HUGEROM).
bit 14    : Requires larger system data area
bit 15    : Snapshot version
```

# 3. Character Devices

## 3.1 General Information

The system provides support for up to 16 character devices which are
accessed through the relevant routines in TRAP 14.

Any UART devices detected during firmware initialization will 
automatically have such devices created for them. The remainder are
available for user use.

## 3.2. The `CHAR_DEVICE` structure

The `CHAR_DEVICE` structure is currently 32 bytes:

| Offset | Size | Contains |
|---|---|---|
| 0x0 |  0x4 | Data required by the functions (e.g. base address) |
| 0x4 |  0x4 | CHECKCHAR function pointer |
| 0x8 |  0x4 | RECVCHAR function pointer |
| 0xC |  0x4 | SENDCHAR function pointer |
| 0x10 |  0x4 | Reserved for future use |
| 0x14 |  0x4 | Reserved for future use |
| 0x18 |  0x4 | DEVICE_CTRL function pointer |
| 0x1C |  0x2 | Capability flags |
| 0x1E |  0x1 | Additional device-specific flags |
| 0x1F |  0x1 | Device type |

### 3.2.1 Capability Flags

The capability flags are a work in progress, and are currently ignored.

### 3.2.2 Device Types

The device types currently defined by the system are:

| Type | Description |
|---|---|
| 0x01 | MFP in-built UART |
| 0x02 | DUART Port A |
| 0x03 | DUART Port B |

## 3.3. Device function calling conventions

> **Note** It is legal to call device functions directly from user codes. They 
should be designed accordingly. The system TRAPs to call them are
provided for convenience only, and device functions should not assume
the CPU will be in supervisor mode when they are called.

All the device functions receive a pointer to their `CHAR_DEVICE` 
structure in A0. `D0` is used for the return value where applicable.

The calling convention (other than the pointer to the device structure)
is the same as the `CHECKCHAR`, `RECVCHAR` and `SENDCHAR` functions
in TRAP 14.

If the device routines are to be directly called from (for example) C
then a wrapper will be required to manage moving arguments from the
stack to the appropriate registers.

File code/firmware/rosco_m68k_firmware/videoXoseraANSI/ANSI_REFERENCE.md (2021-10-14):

# rosco_m68k Xosera XANSI Console Reference

This is a reference for terminal control sequences supported by the rosco_m68k Xosera XANSI console driver (which can be included
in the 64K or 1MB rosco_m68k firmware and used automatically when Xosera hardware is detected at boot). These represent a largely a
compatible superset of VT100, ANSI and other common terminal codes (as adapted to Xosera).  However, there are also a number of
rosco_m68k XANSI specific extensions to support rosco_m68k and Xosera (flagged with EXTENSION).

## Control Characters

| Character | Hex  | Name | Description |
| --- | ---- | ---- | --- |
| `\a` or `^G` | 0x07 | BEL  | alert (visual bell, reverses screen momentarily) |
| `\b` or `^H` | 0x08 | BS | backspace, move cursor left, stops at left margin |
| `\t` or `^I` | 0x09 | HT | tab, move to next 8 col. tab or next line EXTENSION (VT100 doesn't wrap)  |
| `\n` or `^J` | 0x0A | LF | line feed, cursor down, scrolls up at bottom (also does CR if NEWLINE on) |
| `\v` or `^K` | 0x0B | VT | vertical tab, cursor up, scrolls down at top EXTENSION (LF on VT100) |
| `\f` or `^L` | 0x0C | FF | form feed, clear screen, home cursor EXTENSION (LF on VT100) |
| `\r` or `^M` | 0x0D | CR | carriage return (move to left margin only) |
| `\x18` or `^X` | 0x18 | CAN  | terminate current CSI or ESC sequence, otherwise ignored |
| `\x1A` or `^Z` | 0x1A | SUB  | terminate current CSI or ESC sequence, otherwise ignored |
| `\x1B` or `^[` | 0x1B | ESC  | ESC sequence introducer |
| `\x9B` | 0x9B | CSI  | 8-bit CSI sequence introducer (equivalent to "ESC`[`" sequence) |

EXTENSION: When PASSTHROUGH on ("CSI`8m`", aka HIDDEN attribute), all characters will be printed as graphical characters instead of
being interpreted except for ESC and CSI introducers (but these will also be printed when sent twice).  To print the NUL character
('\0' or 0x00), you must use PRINTCHAR (as it is used to terminate the PRINT or PRINTLN string).

When the PASSTHROUGH mode is not enabled, other control charaters not specified above are ignored with no effect.

## ESC Sequences

| Sequence | Name  | Description |
| --- | ----- | --- |
| ESC`[` | CSI | CSI sequence introducer (equivalent to 8-bit "`\x9b`" CSI) |
| ESC`c` | RIS | reset initial settings EXTENSION restores Xosera text mode |
| ESC`7` | DECSC | save cursor position |
| ESC`8` | DECRC | restore saved cursor position |
| ESC`(` | G0 | VT220 font EXTENSION: Xosera font 0 (ST 8x16 default) |
| ESC`)` | G1 | VT220 font EXTENSION: Xosera font 1 (ST 8x8) |
| ESC`*` | G2 | VT220 font EXTENSION: Xosera font 2 (PC 8x8) |
| ESC`+` | G3 | VT220 font EXTENSION: Xosera font 3 (default same as font 0) |
| ESC`D` | IND | move cursor down, scroll at bottom (like LF regardless of NEWLINE mode) |
| ESC`M` | RI | move cursor up, scroll at top |
| ESC`E` | NEL | next line (like CR + LF) |
| ESC`Z` | DA | send VT101 identifier reply (older sequence, replies with "ESC`[?1;0c`" ) |

NOTE: Only single character ESC sequences are supported (ESC and one additional character).  This is different than some terminals
for codes G0 - G3 (which may take another "nationality" code character that is not supported).

Other sequences not specified above will terminate ESC mode and are ignored with no effect.

## CSI Sequences

| Sequence | Name | Description |
| --- | --- | --- |
| CSI _n_`A` | CUU | cursor up, _n_ times (no scroll) |
| CSI _n_`B` | CUD | cursor down, _n_ times (no scroll) |
| CSI _n_`C` | CUF | cursor right, _n_ times (no scroll) |
| CSI _n_`D` | CUB | cursor left, _n_ times (no scroll) |
| CSI _r_`;`_c_`H` | CUP | cursor home / position (_r_ row, _c_ column, starting at 1, home default) |
| CSI _r_`;`_c_`f` | HVP | cursor home / position (_r_ row, _c_ column, starting at 1, home default) |
| CSI`?3h` | DECCOLM 132 | 132 columns EXTENSION  106 column "wide" 16:9 video mode (848x480) |
| CSI`?3l` | DECCOLM 80 | 80 columns EXTENSION  80 column "narrow" 4:3 video mode (640x480) |
| CSI`?5h` | DECSCNM on | screen reverse EXTENSION swap default fore/back (persistant) |
| CSI`?5l` | DECSCNM off | screen normal  EXTENSION swap default fore/back (persistant) |
| CSI`?7h` | DECAWM on | autowrap mode on (wrap cursor or scroll at right margin, default) |
| CSI`?7l` | DECAWM off | autowrap mode off (cursor stops at right margin) |
| CSI`?12h` | ATT160 blink | blinking inverse cursor (blinks every ~1/2 second, default) |
| CSI`?12l` | ATT160 no blink | non-blinking inverse cursor |
| CSI`?20h` | LMN on | newline mode on, LF also does CR |
| CSI`?20l` | LMN off | newline mode off, LF only (default) |
| CSI`?25h` | DECTCEM on | show cursor when waiting for input (default) |
| CSI`?25l` | DECTCEM off | do not show any cursor |
| CSI`5n` | DSR | report terminal "OK" status with "ESC`[0n` |
| CSI`6n` | CPR | report cursor position "ESC`[`_r_`;`_c_`R`" _r_ is row, _c_ is column |
| CSI _n_`c` | DA | report device attributes, depending on _n_ (see next entries) |
| CSI`0c` | VT101 DA ID | 0 reports VT101 ID "ESC`[?1;0c`" |
| CSI`68c` | XANSI DA ID | 68 reports XANSI ID "ESC`[?68;`_v_`;`_i_`;`_r_`c`" EXTENSION: Xosera ver _v_._i_ XANSI rev _r_ |
| CSI`s` | SCP | save cursor position (ANSI version) |
| CSI`u` | RCP | restore saved cursor position (ANSI version) |
| CSI`J` | ED | erase down from cursor line to end of screen |
| CSI`1J` | ED | erase up from cursor line to start of screen |
| CSI`2J` | ED | erase whole screen (NOTE: faithful to DEC VT101, cursor does not move) |
| CSI`K` | EL | erase from cursor to end of line (inclusive) |
| CSI`1K` | EL | erase from cursor to start of line (inclusive) |
| CSI`2K` | EL | erase from whole cursor line (inclusive) |
| CSI _n_`m` | SGR | set graphic rendition depending on _n_ (see table below), can be combined with `;` |

Other sequences not specified above will terminate CSI mode and are ignored with no effect.

Numeric parameters for the above (represented in _italics_) are in ASCII decimal with multiple values seperated with a semicolon
("`;`") and if omitted typically default to 0 (except for cursor row and column, which default to 1).
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

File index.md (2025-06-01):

# Getting started with the rosco_m68k

Welcome to the go-to resource for all things rosco_m68k! Here, you’ll find everything you need to get started—from detailed assembly instructions to guides on building exciting extensions. Dive in and explore the full potential of your machine!

[Join us on Discord](https://discord.gg/rDkE3Xr)

---

## Documentation Sections

### Getting Started
Just received your kit and can't wait to get started? Check this section for everything you need to know.
- [Getting Started Guide](getting-started.md)
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

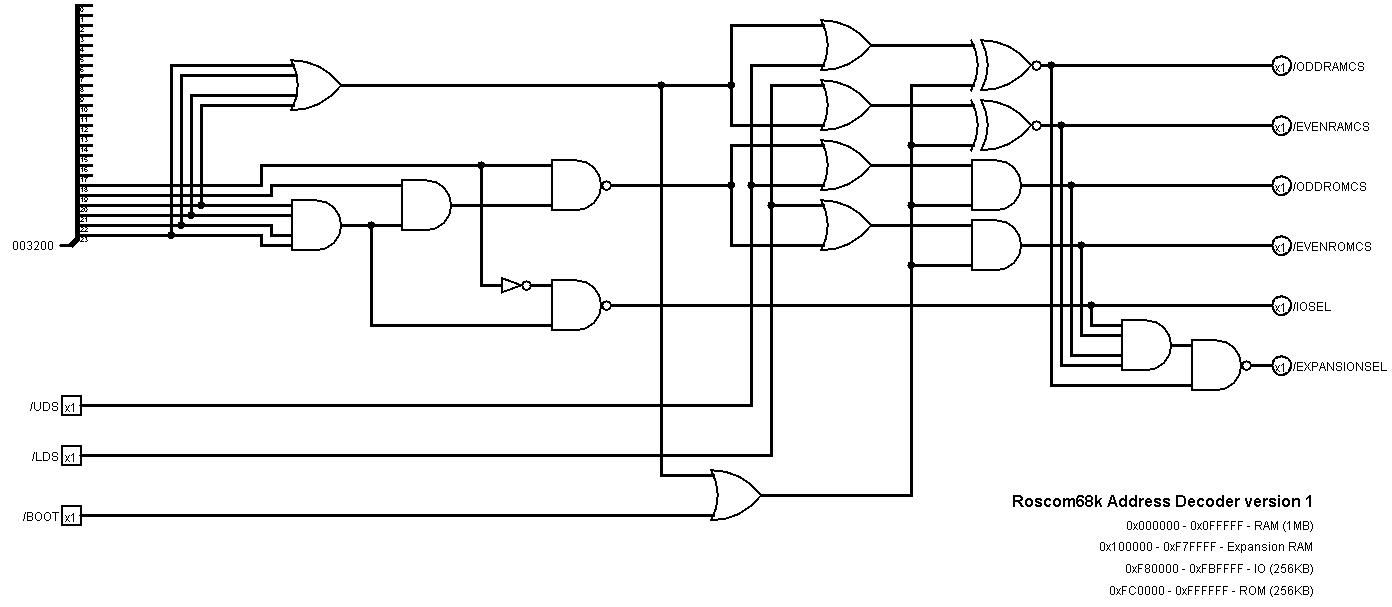
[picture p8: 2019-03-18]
design/r0/logisim/address_decoder_v1.png

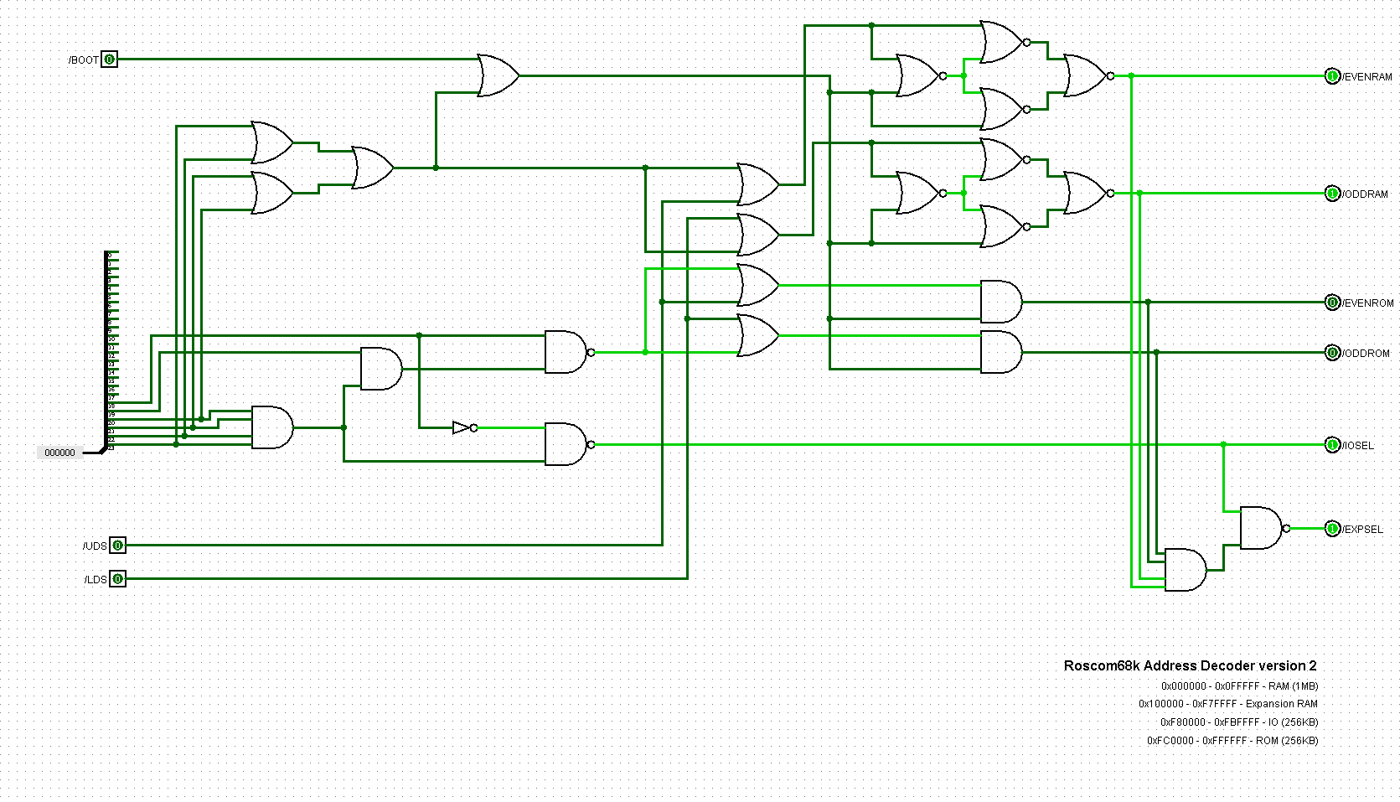
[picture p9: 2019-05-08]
design/r0/logisim/address_decoder_v2.png

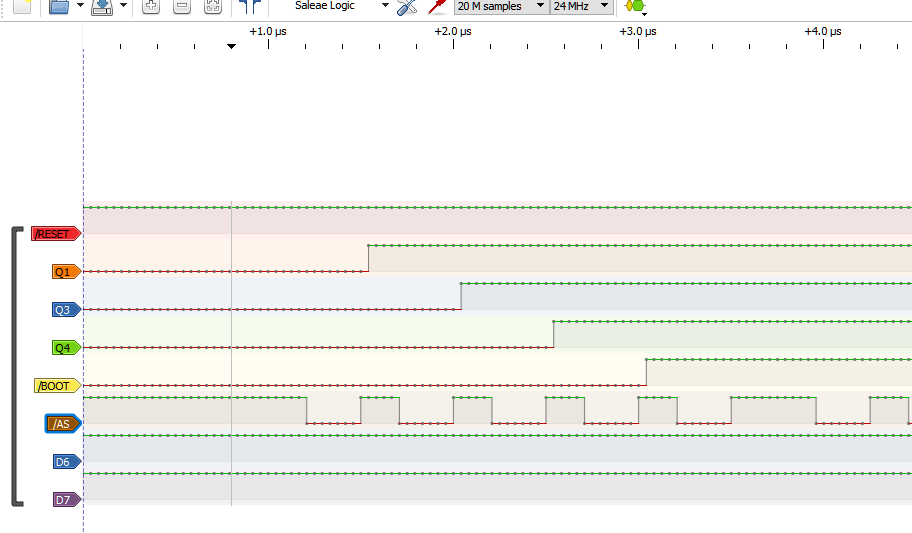
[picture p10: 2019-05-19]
images/boot_line_on_reset.png

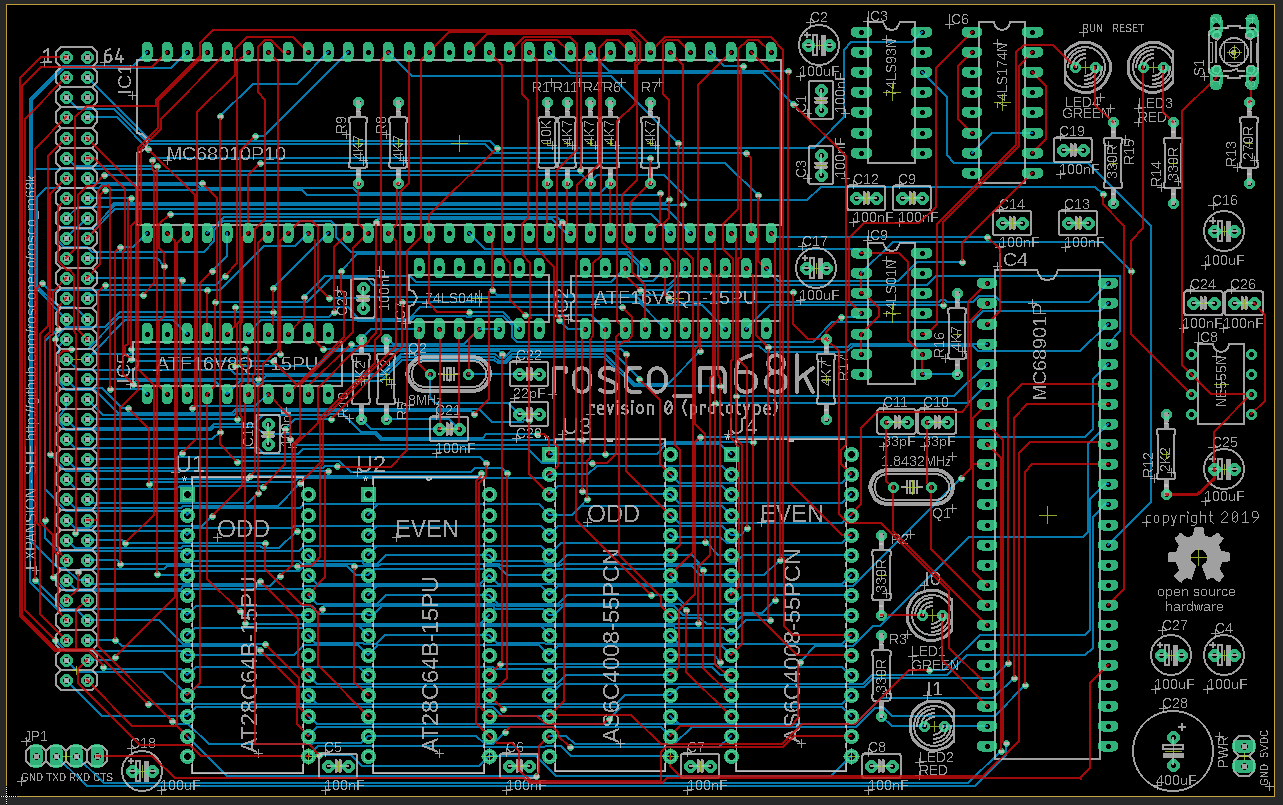
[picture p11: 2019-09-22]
images/pcb_r0.png

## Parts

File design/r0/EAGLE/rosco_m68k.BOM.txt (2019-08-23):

Partlist exported from C:/Users/rosco/devel/retro/rosco_m68k/design/EAGLE/rosco_m68k.sch at 22/08/2019 15:40

Part Value          Device         Package            Description                                                                  1   2   3   4   DESCRIPTION     MF MPN            OC_FARNELL OC_NEWARK PACKAGE  POPULARITY PROG                SPICEPREFIX SUPPLIER       
C1   100nF          C2,5-3         C2.5-3             CAPACITOR                                                                                                                                                    38                                                        
C2   100uF          CPOL-EUE2.5-5  E2,5-5             POLARIZED CAPACITOR, European symbol                                                                                                                         16                             C                          
C3   100nF          C2,5-3         C2.5-3             CAPACITOR                                                                                                                                                    38                                                        
C4   100uF          CPOL-EUE2.5-5  E2,5-5             POLARIZED CAPACITOR, European symbol                                                                                                                         16                             C                          
C5   100nF          C2,5-3         C2.5-3             CAPACITOR                                                                                                                                                    38                                                        
C6   100nF          C2,5-3         C2.5-3             CAPACITOR                                                                                                                                                    38                                                        
C7   100nF          C2,5-3         C2.5-3             CAPACITOR                                                                                                                                                    38                                                        
C8   100nF          C2,5-3         C2.5-3             CAPACITOR                                                                                                                                                    38                                                        
C9   100nF          C2,5-3         C2.5-3             CAPACITOR                                                                                                                                                    38                                                        
C10  33pF           C2,5-3         C2.5-3             CAPACITOR                                                                                                                                                    38                                                        
C11  33pF           C2,5-3         C2.5-3             CAPACITOR                                                                                                                                                    38                                                        
C12  100nF          C2,5-3         C2.5-3             CAPACITOR                                                                                                                                                    38                                                        
C13  100nF          C2,5-3         C2.5-3             CAPACITOR                                                                                                                                                    38                                                        
C14  100nF          C2,5-3         C2.5-3             CAPACITOR                                                                                                                                                    38                                                        
C15  100nF          C2,5-3         C2.5-3             CAPACITOR                                                                                                                                                    38                                                        
C16  100uF          CPOL-EUE2.5-5  E2,5-5             POLARIZED CAPACITOR, European symbol                                                                                                                         16                             C                          
C17  100uF          CPOL-EUE2.5-5  E2,5-5             POLARIZED CAPACITOR, European symbol                                                                                                                         16                             C                          
C18  100uF          CPOL-EUE2.5-5  E2,5-5             POLARIZED CAPACITOR, European symbol                                                                                                                         16                             C                          
C19  100nF          C2,5-3         C2.5-3             CAPACITOR                                                                                                                                                    38                                                        
C20  22pF           C2,5-3         C2.5-3             CAPACITOR                                                                                                                                                    38                                                        
C21  100nF          C2,5-3         C2.5-3             CAPACITOR                                                                                                                                                    38                                                        
C22  22pF           C2,5-3         C2.5-3             CAPACITOR                                                                                                                                                    38                                                        
C23  100nF          C2,5-3         C2.5-3             CAPACITOR                                                                                                                                                    38                                                        
C24  100nF          C2,5-3         C2.5-3             CAPACITOR                                                                                                                                                    38                                                        
C25  100uF          CPOL-EUE2.5-5  E2,5-5             POLARIZED CAPACITOR, European symbol                                                                                                                         16                             C                          
C26  100nF          C2,5-3         C2.5-3             CAPACITOR                                                                                                                                                    38                                                        
C27  100uF          CPOL-EUE2.5-5  E2,5-5             POLARIZED CAPACITOR, European symbol                                                                                                                         16                             C                          
C28  400uF          CPOL-EUE3.5-10 E3,5-10            POLARIZED CAPACITOR, European symbol                                                                                                                         5                              C                          
IC1  MC68010P10     MC68000P       DIL64              68xxx PROCESSOR                                                                                                                unknown    unknown                                                                      
IC2  ATF16V8QL-15PU ATF16V8BP3     DIL20              High perfomance CMOS (electrically erasable) programmable logic device (PLD)                                    ATF16V8QL-15PU 1551768    94M6254                       ADDRESS_DECODER.PLD                            
IC3  74LS93N        74LS93N        DIL14              Decade, divide by twelve and binary COUNTER                                                                                                                  0                                                         
IC4  MC68901P       MC68901P       DIL48              68xxx PROCESSOR                                                                                                                unknown    unknown                                                                      
IC5  ATF16V8QL-15PU ATF16V8BP3     DIL20              High perfomance CMOS (electrically erasable) programmable logic device (PLD)                                    ATF16V8QL-15PU 1551768    94M6254                       GLUE_LOGIC.PLD                                 
IC6  74LS174N       74LS174N       DIL16              Hex D type FLIP FLOP, clear                                                                                                                                  0                                                         
IC7  74LS04N        74LS04N        DIL14              Hex INVERTER                                                                                                                                                 0                                                         
IC8  NE555N         NE555N         DIL08              TIMER                                                                                                                                                                                                                  
IC9  74LS01N        74LS01N        DIL14              Quad 2-input NAND gate, open collector                                                                                                                       0                                                         
JP1  UART           PINHD-1X4      1X04               PIN HEADER                                                                   GND TXD RXD CTS                                                                 91                                                        
JP2  PWR            PINHD-1X2      1X02               PIN HEADER                                                                   +5V GND                                                                                                                                   
JP3                 PINHD-2X30     2X30               PIN HEADER                                                                                                                                                   0                                                         
JP4                 PINHD-2X2      2X02               PIN HEADER                                                                                                                                                   0                                                         
LED1 GREEN          LED5MM         LED5MM             LED                                                                                                                                                          93                                                        
LED2 RED            LED5MM         LED5MM             LED                                                                                                                                                          93                                                        
LED3 RED            LED5MM         LED5MM             LED                                                                                                                                                          93                                                        
LED4 GREEN          LED5MM         LED5MM             LED                                                                                                                                                          93                                                        
Q1   1.8432MHz      CRYSTALHC49S   HC49/S             CRYSTAL                                                                                                                        1667008    unknown                                                                      
Q2   8MHz           CRYSTALHC49S   HC49/S             CRYSTAL                                                                                                                        1667008    unknown                                                                      
R1   10K            R-EU_0207/10   0207/10            RESISTOR, European symbol                                                                                                                                    81                             R                          
R2   330R           R-EU_0207/10   0207/10            RESISTOR, European symbol                                                                                                                                    81                             R                          
R3   330R           R-EU_0207/10   0207/10            RESISTOR, European symbol                                                                                                                                    81                             R                          
R4   4K7            R-EU_0207/10   0207/10            RESISTOR, European symbol                                                                                                                                    81                             R                          
R5   1K2            R-EU_0207/10   0207/10            RESISTOR, European symbol                                                                                                                                    81                             R                          
R6   4K7            R-EU_0207/10   0207/10            RESISTOR, European symbol                                                                                                                                    81                             R                          
R7   4K7            R-EU_0207/10   0207/10            RESISTOR, European symbol                                                                                                                                    81                             R                          
R8   4K7            R-EU_0207/10   0207/10            RESISTOR, European symbol                                                                                                                                    81                             R                          
R9   4K7            R-EU_0207/10   0207/10            RESISTOR, European symbol                                                                                                                                    81                             R                          
R10  1K2            R-EU_0207/10   0207/10            RESISTOR, European symbol                                                                                                                                    81                             R                          
R11  4K7            R-EU_0207/10   0207/10            RESISTOR, European symbol                                                                                                                                    81                             R                          
R12  2K2            R-EU_0207/10   0207/10            RESISTOR, European symbol                                                                                                                                    81                             R                          
R13  270R           R-EU_0207/10   0207/10            RESISTOR, European symbol                                                                                                                                    81                             R                          
R14  330R           R-EU_0207/10   0207/10            RESISTOR, European symbol                                                                                                                                    81                             R                          
R15  330R           R-EU_0207/10   0207/10            RESISTOR, European symbol                                                                                                                                    81                             R                          
R16  4K7            R-EU_0207/10   0207/10            RESISTOR, European symbol                                                                                                                                    81                             R                          
R17  4K7            R-EU_0207/10   0207/10            RESISTOR, European symbol                                                                                                                                    81                             R                          
S1                  10-XX          B3F-10XX           OMRON SWITCH                                                                                                    B3F-1000       176432     36M3542                                                                      
U1   AT28C64B-15PU  AT28C64B-15PU  DIP254P1524X482-28 Parallel EEPROM                                                                              Parallel EEPROM    AT28C64B-15PU  1095784    96K6557   PCDIP-28                                            ATMEL          
U2   AT28C64B-15PU  AT28C64B-15PU  DIP254P1524X482-28 Parallel EEPROM                                                                              Parallel EEPROM    AT28C64B-15PU  1095784    96K6557   PCDIP-28                                            ATMEL          
U3   AS6C4008-55PCN AS6C4008-55PCN DIP254P1524X393-32 CMOS SRAM                                                                                                       AS6C4008-55PCN 1562900    94M6217   DIP-32                                              ALLIANCE MEMORY
U4   AS6C4008-55PCN AS6C4008-55PCN DIP254P1524X393-32 CMOS SRAM                                                                                                       AS6C4008-55PCN 1562900    94M6217   DIP-32                                              ALLIANCE MEMORY

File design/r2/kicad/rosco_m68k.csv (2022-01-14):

Id | Designator | Package | Quantity | Designation | Supplier and ref
1 | H1,H2,H4,H3 | MountingHole_3.2mm_M3_Pad | 4 | MountingHole
2 | S1 | B3F-10XX | 1 | 10-XX
3 | R19,R11 | 0207_10 | 2 | 10K
4 | C1,C2 | C2.5_or_3.5-3 | 2 | 7pF
5 | C7,C8,C9,C20,C23,C24,C22,C26,C13,C27,C28,C30,C31,C6,C25,C29,C12,C10,C5,C4,C3,C32 | C2.5-3 | 22 | 100nF
6 | C16,C17,C18,C19,C14,C15,C11 | E2,5-5 | 7 | 100uF
7 | C21 | E3,5-10 | 1 | 470uF
8 | IC4 | PLCC-44_THT-Socket | 1 | XR68C681CJTR-F
9 | IC5,IC6,IC3,IC2 | DIP-24_W7.62mm_Socket_LongPads | 4 | ATF22V10C
10 | JP1,JP2,JP3,JP4 | 1X02 | 4 | Jumper
11 | LED3,LED1 | LED5MM | 2 | GREEN
12 | LED4,LED2 | LED5MM | 2 | RED
13 | Q1 | Crystal_HC49-4H_Vertical | 1 | 3.6864MHz
14 | Q2 | Oscillator_DIP-8 | 1 | 5H8ET-10.000
15 | U4,U3 | DIP-32_W15.24mm_LongPads | 2 | AS6C4008-55PCN
16 | U2,U1 | DIP-32_W15.24mm_LongPads | 2 | SST39SF040
17 | J3 | PinHeader_2x32_P2.54mm_Vertical | 1 | Conn_02x32_Odd_Even
18 | R8,R7,R9,R10,R32,R31,R12,R15,R17,R18,R3,R16 | 0207_10 | 12 | 4K7
19 | J4 | 1X06 | 1 | Conn_01x06
20 | J2 | 1X06 | 1 | UART_B
21 | J1 | 1X06 | 1 | UART_A
22 | J5 | 1X02 | 1 | PWR
23 | IC15 | DIP-8_W7.62mm_LongPads | 1 | 555N
24 | R27 | 0207_10 | 1 | 2K2
25 | R28 | 0207_10 | 1 | 270R
26 | R13,R14,R1,R2 | 0207_10 | 4 | 330R
27 | R21 | 0207_10 | 1 | 1K2
28 | J6 | PinHeader_1x04_P2.54mm_Vertical | 1 | Conn_01x04_Male
29 | REF**,REF** | SM-rosco_m68k_logo | 2 | SM-rosco_m68k_logo
30 | J7 | PinHeader_1x01_P2.54mm_Vertical | 1 | Conn_01x01_Male
31 | IC7 | DIP-16_W7.62mm_LongPads | 1 | 74LS148
32 | IC1 | DIL64 | 1 | MC68010P10
33 | OSHW_Mono_0.25_Scale | OSHW_Mono_0.25_Scale | 1 | UK000006
34 | REF** | RoHS-Logo_6mm_SilkScreen | 1 | RoHS-Logo_6mm_SilkScreen
35 | REF** | WEEE-Logo_5.6x8mm_SilkScreen | 1 | WEEE-Logo_5.6x8mm_SilkScreen
36 | REF** | MD-rosco_m68k_logo | 1 | MD-rosco_m68k_logo

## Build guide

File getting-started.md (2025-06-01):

[Home](index.md) | [Getting Started](getting-started.md) | [Connecting](connecting.md) | [Running the Examples](running-the-examples.md) | [Toolchain Installation](toolchain-installation.md) | [Building the Software](building-the-software.md) | [Installing the Emulator](installing-the-emulator.md) | [Debugging with MAME](MAME-serial.md) | [Using SD Cards](SDCardGuide.md)

# Getting Started with rosco_m68k

## Building your kit

### Yay! Your kit has arrived! Here are a few handy tips for the build...

So you've just received your kit, and no doubt you're itching to build it. Perhaps you're a seasoned soldering pro or maybe this is all new to you – either way, read on for some handy tips and lessons we learned by soldering a lot of these things...

#### Things you'll need:
- A soldering iron (we recommend a temperature controlled one, but it doesn't have to be anything fancy!)
- Some solder (We like lead-free, 1mm diameter)
- Supplies for cleaning and caring for your iron (see below)
- (Optional) Masking tape

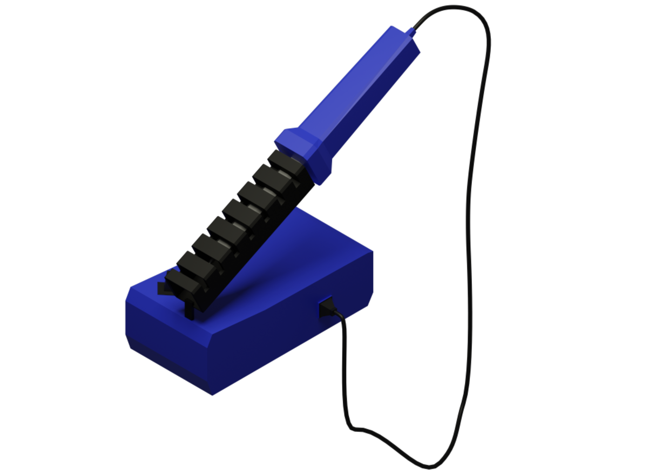
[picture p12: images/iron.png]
Soldering Iron


#### Take me to the BOM!
If you're an old pro at this, the links below will take you directly to the BOM for your board revision:
- [Revision 1 BOM](https://github.com/rosco-m68k/rosco_m68k/blob/master/design/r1/kicad/rosco_m68k.csv)
- [Revision 1.2 BOM](https://github.com/rosco-m68k/rosco_m68k/blob/release/revision-1.2/design/r1.2/kicad/rosco_m68k.csv)
- [Classic v2 BOM](https://github.com/rosco-m68k/rosco_m68k/blob/release/version-2.0/design/r2/kicad/rosco_m68k.csv)

---

## Recommended order of assembly

This is the way we generally approach building a rosco_m68k. Your mileage may vary!

When we build the rosco_m68k, we have a standard approach that we tend to follow. In fact, we find this tends to work for most PCB-based projects, though there are often cases where it makes sense to vary it. However, for this board, this is the order we pretty much always do it in:

1. First of all, we solder the resistors.
2. Next, we do the ceramic capacitors.
3. After those are done, it's time for the button.
4. Then, we do the crystals...
5. ... followed by the chip sockets (if using)
6. Now do any ICs that aren't going to be socketed.
7. After that we add the LEDs
8. Then it's time for the pin headers
9. Next, the small electrolytic capacitors are added
10. And finally the large electrolytic

You'll probably notice that, with this approach, we take the smallest components in terms of height first, and gradually add the taller components as we go. We find this works well with this board, and makes it easy to handle during the build. That said, of course this isn't a hard and fast rule – this is your kit, how you build it is totally up to you!

Let's take a look at each component type, and we'll talk about any tips we have for them individually.

### Resistors
There's not a lot to say here. We tend to place these in logical groups, soldering each group and trimming the leads before moving on to the next group, but you could just as easily place them all at once (either bending the leads or using masking tape to keep them in place) and then solder them in one go. We prefer doing them in groups because it means the leads are less likely to get in your way. As with all the components, aim to have it flush with the board (to minimise additional lead length) and if you can, try to have it nice and central between the holes.

### Ceramic capacitors
Sometimes our suppliers send us ceramics where the leads have a wider footprint than the body, so in that case you'll want to gently straighten out the leads (we recommend a pair of needle-nose pliers for this job). Again, we like to solder these in groups, and try to get them as flush with the board as possible – you might need to gently pull them from the back-side of the board before soldering to get them snugly into place.

### Button
The button is pretty simple, and the one we supply neatly holds itself in place while you solder it so you don't need to worry about it having short leads. Simply push the button into the holes (don't worry, it only fits the right way) and solder it in. Be sure to use the edge of your soldering tip here to ensure the leg is heated along with the pad and the solder should just slide into place.

### IC sockets
These should be pretty easy too. A bit of masking tape is your friend here, we tend to do a strip across the RAM, ROM and MFP, then do the CPU and glue logic with another strip or two, depending on width. If your iron is the right temperature it doesn't take long to get each leg and pad to flow temperature, and you'll probably find a nice rhythm by the time you've done a few so although there are a lot of legs, it doesn't take too long. We like to start by soldering the opposite corner pins, and checking the socket is straight before doing the rest. If it's moved, you can just re-do the corners.

### Crystals
Again, we usually put a bit of masking tape over each crystal to hold it in place. Bending the leads works too, but don't bend them too much, and we do find that the crystals tend to move around a bit when soldering if just using bent leads, hence the tape. The crystals we supply are pretty hardy, but try not to get them too hot during soldering – if a joint isn't happening on the first try, let it cool a bit and then have another go.

### LEDs
The main thing to watch with these is that you get the polarity right. The silkscreen has one flat side for each LED – this is the side where the short leg should go (if using LEDs we supply, the body of the LED has a matching flat spot, as do most standard 5mm LEDs). LEDs 1 and 4 should be green, and 2 and 3 should be red. We don't recommend using other colours – you might need to adjust the value of some of the resistors if you want to do that. We usually use a bit of masking tape to hold the LEDs in place, and take a moment to double check they're standing straight before you solder them – it's super annoying when you turn the board over to find that one of them has leaned over to the side somehow while you were soldering it...

### Pin headers
The pin headers take a little more heat than most of the other components, but not much. You'll probably find a nice rhythm, just as you did for the IC sockets. We use masking tape here too, and again double check – the headers are prone to leaning, just like the LEDs. A useful trick for the small headers (the two and four pin power and UART connectors) is to push the long-side pins through your masking tape, then stick it to the board with the short pins through the holes, ready to solder. We find this makes them easier to place properly and helps keep them straight.

### ICs
This is probably where there is the most potential for damage during soldering, but with a bit of care you should be fine. Take your time, and remember that heat build up inside the chip is cumulative, so if you rush through the legs doing one after the other, you're almost as likely to damage the part as if you held too long on an individual leg. It's unfortunate that replacing a heat-damaged IC is likely to be the most expensive damage you can do while building your board, and they're also the least fun parts to desolder if you have to, so it's worth having some patience and getting it right first time. Also, be wary of electrostatic discharge when handling the chips – try to handle them as little as possible, and avoid touching the legs if you can. If you have an antistatic mat or wrist strap, all the better. Oh, and make sure you get the chips the right way around – the semicircular indentation on one end of the chip should match the same indentation on the silkscreen. Check and double check – there's nothing more annoying than doing a perfect job soldering in a chip, only to have to remove it again because it's in backwards... Just like the sockets, we'd advise doing opposite corners first.

### Electrolytic capacitors
Make sure these are flush to the board before you solder them – you might have to use a little force to push them properly into place. Once you've done that, you'll probably find that they keep themselves in place while you solder, but they are a bit sneaky and will sometimes lean over after you turn the board over to solder them. If you need to, you can add a bit of tape to hold them in place. Like the crystals, these don't like a lot of heat – they aren't quite as touchy about it as the ICs, but still, take your time and if a joint isn't taking the solder, back off and let things cool down before taking another run at that joint. It's important that you get these the right way around! There's a little plus sign (+) on the board for each electrolytic – this is the side where the longer leg should go. The body of these capacitors will have a different coloured stripe on one side, which should go on the opposite side from the + (i.e. the stripe denotes the - side). When you're done, all the stripes should be facing the same way.

---

## Cleaning

You may want to clean your board after soldering everything up. Depending on the flux you used (or that came inside your solder) this might be necessary, but it's nice to remove any left-over globs of flux and other sticky bits that are left over from soldering.

You can buy various commercial products to do this, but Isopropyl Alcohol is our preferred chemical most of the time. Get the 99% stuff, and use it sparingly with Q-tips and a stiff (though not metal!) brush for best results. Let your board dry completely before connecting anything up.

Is it worth the hassle of cleaning your board? Well, if you don't, it'll most likely work just fine (in any event, there isn't anything that could be wrong that cleaning with IPA will fix) and will probably last for decades assuming you've not used anything crazy in terms of flux or other chemicals. If you do clean it, it'll look more professional and "finished" and you'll be able to rest easy knowing there's nothing nasty eating away at your copper. The choice is yours.

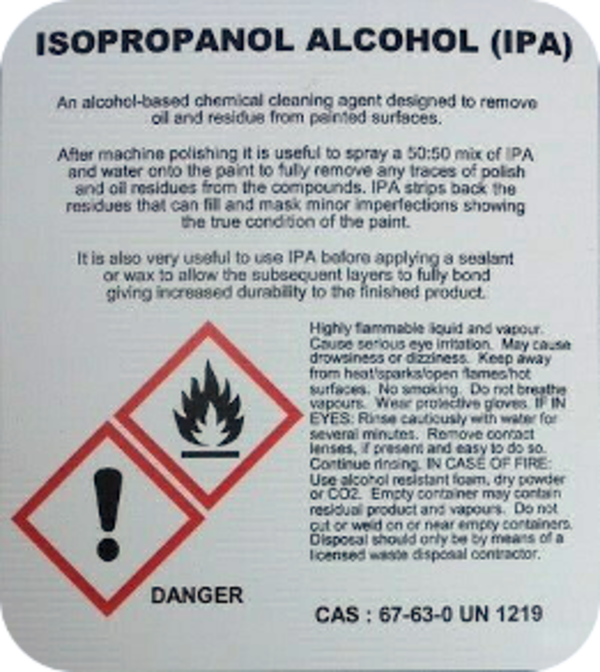
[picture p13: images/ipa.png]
IPA


> **Danger!**
>
> Isopropyl Alcohol is highly flammable and toxic if swallowed! Always read the warnings on the bottle carefully and ensure you follow all directions. Use personal-protective equipment when using IPA. Only use in a well-ventilated area, keep away from all sources of ignition and try not to breathe in any fumes. Avoid contact with the skin and eyes.

---

## Additional soldering supplies

You don't need these, but they definitely help...

### Soldering Iron Metal Sponge
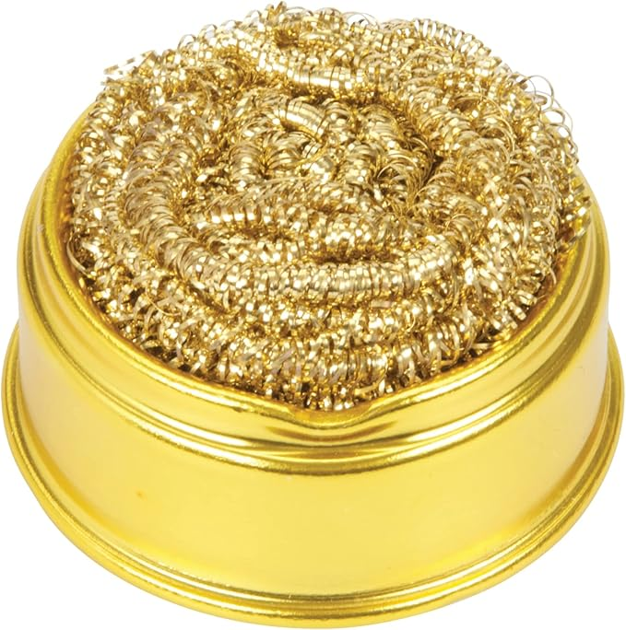
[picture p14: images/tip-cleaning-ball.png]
Soldering Tip Cleaning Ball & Base


It's likely that your soldering iron came with a sponge, which is designed to be used wet (otherwise it'll tend to melt). This definitely has its uses, but there will be times where it's not enough. If your iron is starting to get really dirty with oxidation and whatnot, one of these metal sponges can come in very handy. Obviously using one of these does abraid your tip a bit more than a wet sponge, so you don't want to use it all the time, but the number of times where a quick run through this fixes things and gives you a nice clean tip to solder with will outweigh any downsides. [Get one here (Amazon UK)](https://www.amazon.co.uk/Silverline-281271-Soldering-Cleaning-Ball/dp/B011SFFRQC)

### Tip Tinner
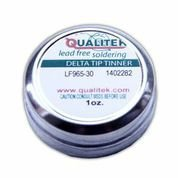
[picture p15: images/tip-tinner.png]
Tip Tinner


Handy for getting rid of oxidation on your soldering tip and tinning it at the same time, this is usually acid-based and works instantly on a hot iron. Obviously being acid-based it will eventually eat away at the plating on your tip, but for an occasional refresh of a heavily oxidized tip it's hard to beat this stuff. Plus, it's lead-free and it lasts forever, though that might be because it's ridiculously difficult to actually open the tin. [Pick it up here (Amazon UK)](https://www.amazon.co.uk/Antex-XM000Y0B-Soldering-Tip-Tinner/dp/B01ECH04HA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)

### Desoldering Braid
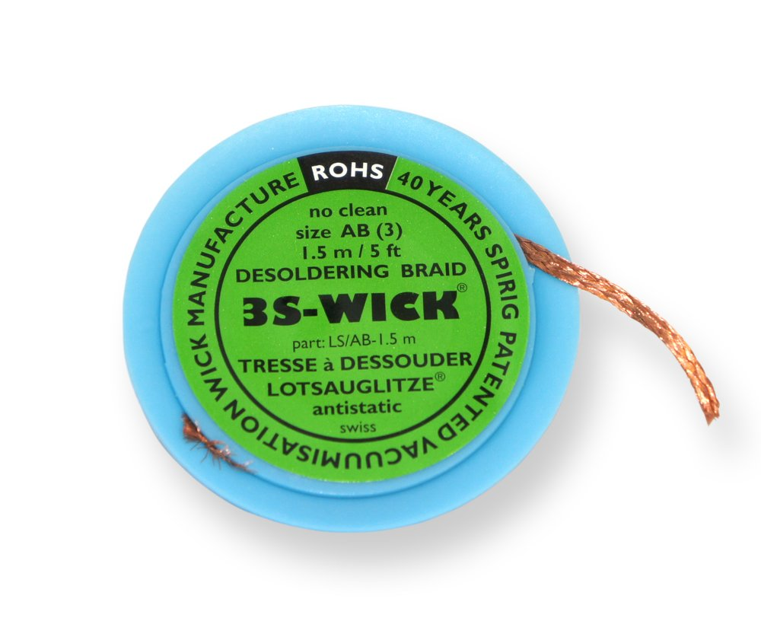
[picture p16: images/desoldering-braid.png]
Desoldering Braid


Everyone makes mistakes, and occasionally you will too. Inevitably, some of those mistakes will occur while soldering. This stuff is the "undo" button of soldering. Not really just for mistakes, this comes in handy whenever you need to remove some solder, whether you've added bit too much, or you're removing a component from some other circuit in order to recycle it. It works a bit like a wick (in fact, it's also known as "solder wick") – you place it on the solder you want to remove, apply heat, and the solder gets soaked up into the braid. It's probably not as much fun as its more glamorous cousin, the desoldering pump (or "solder sucker"), but it's reliable, plentiful and cheap. Plus it's not impossible to clean, and doesn't involve globs of molten metal flying around so it's probably safer, at least than the cheaper end of the pump range. [Get it here (Amazon UK)](https://www.amazon.co.uk/Spirig-WICK2-2-1-5-3S-Wick-Desoldering-Antistatic/dp/B00KX20MG2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)

---

## Soldering 101

If you're new to soldering, this is worth a watch...

There are lots of soldering tutorials on YouTube, but this one is nice and concise and says most of what we'd have said, probably better than we would have.

### Recommended Video

How to Solder: Through-Hole Soldering (SparkFun) (https://www.youtube.com/watch?v=Qps9woUGkvI)

**How to Solder: Through-Hole Soldering**  
by SparkFun Electronics ([Watch on YouTube](https://www.youtube.com/watch?v=Qps9woUGkvI))

---

---

[Home](index.md) | [Getting Started](getting-started.md) | [Connecting](connecting.md) | [Running the Examples](running-the-examples.md) | [Toolchain Installation](toolchain-installation.md) | [Building the Software](building-the-software.md) | [Installing the Emulator](installing-the-emulator.md) | [Debugging with MAME](MAME-serial.md) | [Using SD Cards](SDCardGuide.md)

Copyright © 2020-2024 The Really Old-School Company Limited. Registered in England and Wales No. 12596175
The Really Old-School Company Ltd, 15 Starthe Bank, GB DE75 7AX Tel: 0330 133 2083

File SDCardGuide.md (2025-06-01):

[Home](index.md) | [Getting Started](getting-started.md) | [Connecting](connecting.md) | [Running the Examples](running-the-examples.md) | [Toolchain Installation](toolchain-installation.md) | [Building the Software](building-the-software.md) | [Installing the Emulator](installing-the-emulator.md) | [Debugging with MAME](MAME-serial.md) | [Using SD Cards](SDCardGuide.md)

# SD Card Hookup & User Guide

With Firmware 1.3, SD Cards are now supported directly by the firmware. This feature works will all boards that are supported by Firmware 1.3, though the electrical hookup and usage varies.

In order to use SD card, you will need an Arduino SD Card adapter. It is very important that this adapter includes level conversion (as SD cards are 3.3V) - any adapter marked as suitable for Arduino _should_ work, but for completeness ensure it has the regulator and level-conversion chip (as in the diagram below).

## Electrical connection

To connect your SD adapter to your rosco_m68k, you will use some of the GPIO pins (on `J5`) for r1 and r1.2 boards, or the dedicated SD card connector (`J4`) on r1.23 boards. The hookup is as shown below:

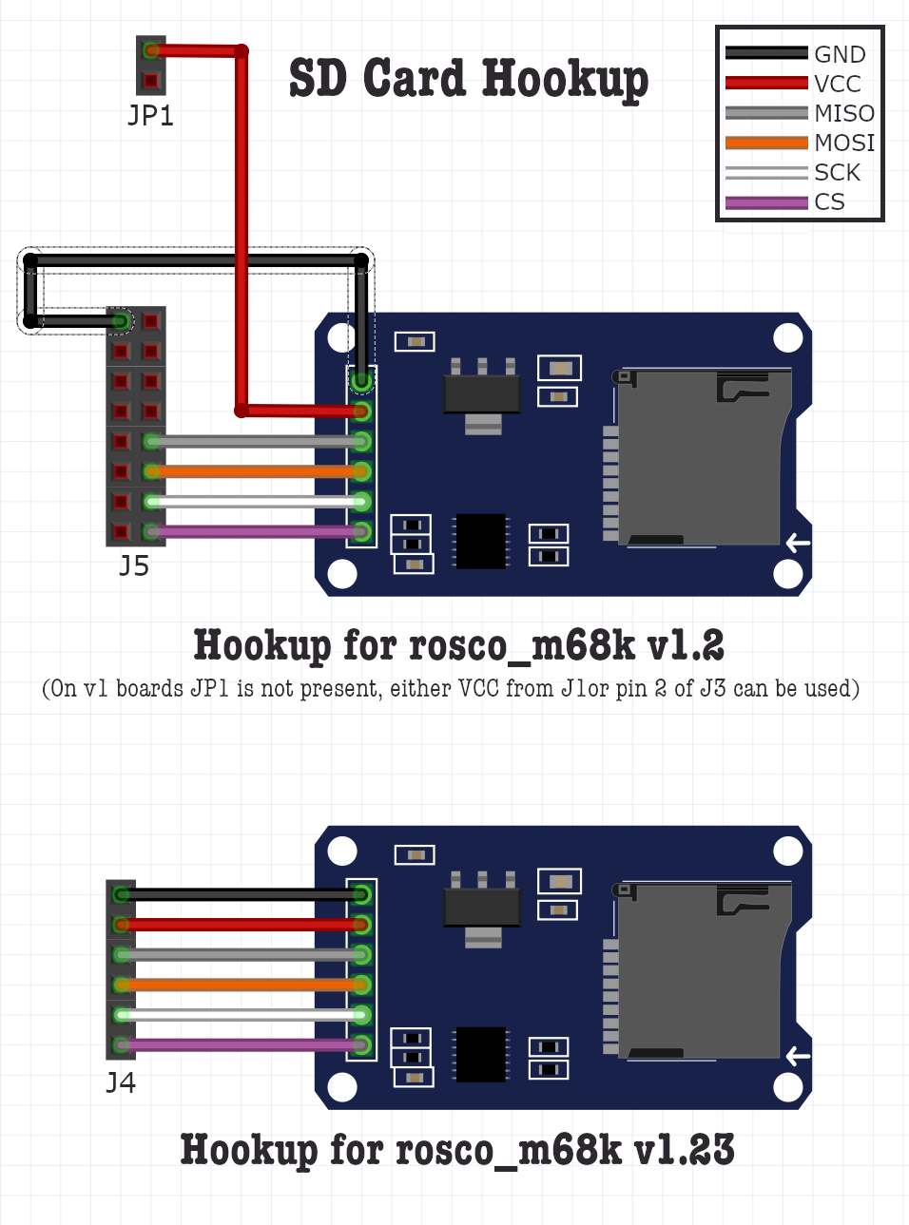
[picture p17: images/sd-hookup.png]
SD Card Hookup


The SD adapter should be connected with the rosco_m68k powered off. Ensure all connections are correct before connecting power to the mainboard. Once the adapter is connected, you can insert and remove SD cards without needing to power off or reboot your rosco_m68k.

## Supported SD cards

Most SD cards will work fine in a read-only system, however for best performance and reliability (especially during writes) we recommend good quality SDHC cards with capacity 16 or 32GB. The interface has been fairly extensively tested with SanDisk, Samsung, and similar brands in SDHC capacity.

## SD Card format

In order to work with the standard rosco_m68k software (both the firmware bootloader, where available, and Xark's [sdfat_menu](code/software/sdfat_menu)) your SD card should be formatted as FAT. You can do this on a desktop computer - specifics vary by platform.

FAT32 is recommended (and more completely tested). VFAT is known to be unsupported at this time.

### sdfat_menu

Xark's [sdfat_menu](code/software/sdfat_menu) is the official loader for SD cards, and is the recommended way to interface with your SD card. Whether by direct booting with `BIGROM`s (see below) or by sending the menu program via Kermit before using SD features, the menu provides a comprehensive text interface for selecting binaries to load and run, and also provides a command-shell, directory navigation, and more.

### Bootable SD

If you have the `BIGROM` build of Firmware 1.3, your rosco_m68k will look for an SD card at boot time (before falling back to Kermit). If one is found, it will attempt to load a file called `ROSCODE1.BIN` from the SD card and boot it directly.

It is recommended that, where this capability exists, you use Xark's [sdfat_menu](code/software/sdfat_menu) (see above).

---

[Home](index.md) | [Getting Started](getting-started.md) | [Connecting](connecting.md) | [Running the Examples](running-the-examples.md) | [Toolchain Installation](toolchain-installation.md) | [Building the Software](building-the-software.md) | [Installing the Emulator](installing-the-emulator.md) | [Debugging with MAME](MAME-serial.md) | [Using SD Cards](SDCardGuide.md)

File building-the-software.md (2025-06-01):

[Home](index.md) | [Getting Started](getting-started.md) | [Connecting](connecting.md) | [Running the Examples](running-the-examples.md) | [Toolchain Installation](toolchain-installation.md) | [Building the Software](building-the-software.md) | [Installing the Emulator](installing-the-emulator.md) | [Debugging with MAME](MAME-serial.md) | [Using SD Cards](SDCardGuide.md)

# Building the Software

Getting started with the software for your new board is as simple as grabbing the source code from GitHub and compiling it for the board.

You'll need a m68k toolchain for this part - if you don't have one, you can easily [install ours using Homebrew →](toolchain-installation.md).

We use git for version control and it's the easiest way to get the code and stay up to date, but you can also grab a zip-file if you prefer. No matter how you get the files the rest of the process is the same, so this document applies to both methods.

> **Note:** These instructions apply to macOS® and Linux® only. We recommend that Windows® users use Windows® Subsystem for Linux® or a Linux VM for development.

---

## Step One - Get The Code

Before we can build the software, you'll need to get a copy of it onto your local machine. You can either use git, or download a zip file.

### Using git

This is our preferred option, and it'll make it easy to stay up to date when we add new stuff. If you've never heard of git, check out [this page](https://www.atlassian.com/git/tutorials/what-is-git) for the lowdown.

If you're on macOS® or Linux, the chances are git is already installed. You can check if you already have git installed by typing:

```sh
git --version
```

If it comes back with a version number, you're all set! Otherwise, use your distribution's package manager to install git. For example:

```sh
sudo dnf install git
# or
sudo apt-get install git
```

To clone the project, navigate to a suitable directory and run:

```sh
git clone https://github.com/rosco-m68k/rosco_m68k.git
```

This will copy the very latest version of everything to your local computer. You'll get the code for everything from the sample programs to the code that runs the glue logic on the board, plus a ton of documentation and other stuff. Once git has done its thing you'll find everything below your current directory, in a directory called `rosco_m68k`.

If you're interested in hardware hacking, you might also want to grab some additional design files, which we keep in a separate repository:

```sh
git clone https://github.com/rosco-m68k/hardware-projects.git
```

But these are totally optional - the main repository contains the main design files for the board alongside all the software.

### Download a zip

If you don't want to use git, that's cool too - you can download the latest release as a zip file from the following links:

- [Main repository](https://github.com/rosco-m68k/rosco_m68k/archive/master.zip)
- [Hardware projects](https://github.com/rosco-m68k/hardware-projects/archive/master.zip)

---

## Exploring

If you want to explore the project a bit before you download it, head on over to [https://github.com/rosco-m68k](https://github.com/rosco-m68k) and have a look around - as well as the code, you'll find our issue tracker, documentation, and a bunch of other stuff. If you're interested in feeding back issues or contributing code, now would be a great time to sign up for a free GitHub account if you don't already have one!

---

## Step Two - Build!

Now you have the code locally you're ready to make sure you can build stuff. If you installed our toolchain, this part should be a breeze.

Firstly, you'll need to build some library code that the other programs share. Execute the following:

```sh
cd rosco_m68k/code/software/libs
make install
```

This won't install anything globally on your machine, instead it will just build the libraries and put them in a standard place within the project where the other code can find them.

Now we're ready to build a program. Run the following commands:

```sh
cd ../adventure
make
```

Assuming everything's installed correctly, this should take a second or two, and will create a file called `adventure.bin` - this is a port of [Jeff Tranter's Adventure](https://github.com/jefftranter/6502/tree/master/c/adventure) to the rosco_m68k, and it's all ready for you to upload to your board and try out!

If you see any errors when building either the libraries or the example program, it's likely your m68k toolchain isn't complete. We highly recommend installing our toolchain from Homebrew, but if you've gone with the option of building it yourself then you'll have to do some debugging. If you're stuck you can always [reach out on discord](https://discord.gg/xpZJmhA) and we'll do what we can to help!

All you need to do now is make sure your rosco_m68k is connected to your computer and up and running, then use minicom (or your terminal of choice) to send the `adventure.bin` file to the board using the Kermit protocol. Once the board receives the binary it will automatically start running it, and you'll be playing a fresh new game of Adventure!

---

## Next Steps

Now that you've tested out the toolchain and know you can successfully build software for your rosco_m68k, it's time to have a look around at the rest of the examples, and maybe even start doing some coding yourself.

The best and most up-to-date documentation can always be found in the project itself. You can either open up the README.md files locally, or they're always available (with formatting) on GitHub. A good place to start is [https://github.com/rosco-m68k/rosco_m68k/tree/master/code/software](https://github.com/rosco-m68k/rosco_m68k/tree/master/code/software) - you'll see a list of directories and files, and the README.md for that directory if you scroll down a bit.

Whenever you navigate to a new directory that has a README.md, you'll see the documentation right there!

---

## Building the Firmware & GAL Code

If you opted to not receive pre-programmed ROMs or PLDs when you ordered your rosco_m68k, you'll be wanting to build the firmware and the GAL code.

You'll find what you need in the following locations:
- `rosco_m68k/code/firmware`
- `rosco_m68k/code/pld`

You'll find fairly extensive documentation for the firmware here: [rosco_m68k_firmware](https://github.com/rosco-m68k/rosco_m68k/tree/develop/code/firmware/rosco_m68k_firmware)

For the glue logic, we've included the compiled JEDEC files in Git. If you want to modify the code, you'll need to grab a copy of GALasm [from here](https://github.com/daveho/GALasm) - it isn't included in the standard toolchain, but is easy to build with your platform compiler.

Once you've built them, there are scripts in each directory that will use minipro (included in the standard toolchain) to burn these to the appropriate chips. This will work fine if your EEPROM burner is supported by minipro - if not, you'll need to use the appropriate software that came with your burner.

As always, if you get stuck, [give us a shout on discord](https://discord.gg/76MhBxJ) and we'll help where we can.

---

---

[Home](index.md) | [Getting Started](getting-started.md) | [Connecting](connecting.md) | [Running the Examples](running-the-examples.md) | [Toolchain Installation](toolchain-installation.md) | [Building the Software](building-the-software.md) | [Installing the Emulator](installing-the-emulator.md) | [Debugging with MAME](MAME-serial.md) | [Using SD Cards](SDCardGuide.md)

Copyright © 2020-2024 The Really Old-School Company Limited. Registered in England and Wales No. 12596175
The Really Old-School Company Ltd, 15 Starthe Bank, GB DE75 7AX Tel: 0330 133 2083

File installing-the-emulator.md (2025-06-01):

[Home](index.md) | [Getting Started](getting-started.md) | [Connecting](connecting.md) | [Running the Examples](running-the-examples.md) | [Toolchain Installation](toolchain-installation.md) | [Building the Software](building-the-software.md) | [Installing the Emulator](installing-the-emulator.md) | [Debugging with MAME](MAME-serial.md) | [Using SD Cards](SDCardGuide.md)

# Installing the Emulator

The rosco_m68k toolchain includes a fully-featured fork of a popular Open Source emulator, with full support for rosco_m68k and a variety of other retro-style single-board computers.

With the emulator, you get full hardware debugging capabilities, and can run rosco_m68k software in a fully emulated virtual machine, right on your modern computer.

Once you've [got the homebrew tap set up](toolchain-installation.md), installation is simple on macOS® and Linux®.

> **Note:** These instructions apply to macOS® and Linux® only. We recommend that Windows® users use Windows® Subsystem for Linux® or a Linux VM for development.

---

## Installing from Homebrew

This is the recommended option - the emulator can be tricky to build, and it can take a while.

Our homebrew tap contains a pre-configured build with binary bottles for various platforms and architectures.

Assuming you already installed Homebrew and the rosco_m68k tap, you can just do:

```sh
brew install mame-sbc
```

Depending on your platform this may take a little while (and if there isn't a pre-built binary available, you'll need your platform build tooling installed).

Once installed, there's an extra step you'll need to do to set up the default configuration:

```sh
mkdir -p ~/.mamesbc && ln -s $(brew --prefix)/share/mame-sbc/ini/mamesbc.ini ~/.mamesbc/mamesbc.ini
```

This will make a rosco_m68k-specific emulator directory under your home directory, and symlink the default configuration file into it.

Once that's done, you can run it with your favourite rosco_m68k binary:

```sh
sbc rosco_classicv2 -debug -quik <path to rosco_m68k repository>/code/software/memcheck/memcheck.bin
```

Type `g` (for "go") in the debug window that will pop up, and that's it! You should be good to go.

For more details on the emulator and some help using the debugger, refer to the official documentation: [MAME Debugger Docs](https://docs.mamedev.org/debugger/index.html)

---

## Installing from Source

Our emulator is a customised fork of a very popular Open Source emulation project.

You can grab the code from GitHub:

```sh
git clone https://github.com/roscopeco/mame.git
cd mame
make -j9
```

This includes the Open Source ROM files for rosco_m68k and various other single-board computers.

---

---

[Home](index.md) | [Getting Started](getting-started.md) | [Connecting](connecting.md) | [Running the Examples](running-the-examples.md) | [Toolchain Installation](toolchain-installation.md) | [Building the Software](building-the-software.md) | [Installing the Emulator](installing-the-emulator.md) | [Debugging with MAME](MAME-serial.md) | [Using SD Cards](SDCardGuide.md)

Copyright © 2020-2024 The Really Old-School Company Limited. Registered in England and Wales No. 12596175
The Really Old-School Company Ltd, 15 Starthe Bank, GB DE75 7AX Tel: 0330 133 2083

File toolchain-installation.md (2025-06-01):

[Home](index.md) | [Getting Started](getting-started.md) | [Connecting](connecting.md) | [Running the Examples](running-the-examples.md) | [Toolchain Installation](toolchain-installation.md) | [Building the Software](building-the-software.md) | [Installing the Emulator](installing-the-emulator.md) | [Debugging with MAME](MAME-serial.md) | [Using SD Cards](SDCardGuide.md)

# Toolchain Installation

## No toolchain? No problem! Get coding in no time with our simple toolchain installation.

Before you can build any software for the rosco_m68k, you'll need a toolchain. Fortunately, the rosco_m68k comes with a full-featured C/C++ toolchain based on [GCC](https://gcc.gnu.org/), with assembly language support from [VASM](http://sun.hasenbraten.de/vasm/).

And thanks to our handy [Homebrew tap](https://github.com/rosco-m68k/homebrew-toolchain), it's easier than ever to get started cross-compiling software for your rosco_m68k!

> **Note:** These instructions apply to macOS® and Linux® only. We recommend that Windows® users use Windows® Subsystem for Linux® or a Linux VM for development.

---

## Step One - Install Homebrew

Homebrew, billed as The Missing Package Manager for macOS (or Linux), makes it really easy to install a complete, locally-built-from-official-sources VASM/GCC/Binutils cross-compiling toolchain, and it's our recommended way to get started with coding for the rosco_m68k.

If you don't already have Homebrew installed, visit [brew.sh](https://brew.sh/) for a one-line install.

In a nutshell, it involves running the following command in a terminal:

```sh
/bin/bash -c "$(curl -fsSL https://raw.githubusercontent.com/Homebrew/install/HEAD/install.sh)"
```

If you're wary about running arbitrary scripts downloaded from the web, take a look at their [alternative installation instructions](https://docs.brew.sh/Installation) for more options.

> **Note:** If you are on Linux, there are additional steps to take at this point. Please follow the Install section in the [Homebrew on Linux](https://docs.brew.sh/Homebrew-on-Linux#install) documentation.

---

## Step Two - Install the Toolchain

Now that you have Homebrew installed, installing the toolchain is a breeze. The best way to do this depends on your platform.

### On macOS®

```sh
brew tap rosco-m68k/toolchain
brew install rosco-m68k-toolchain@13
```

This will automatically download, build and install all the dependencies that you would normally have to build manually. Homebrew will also keep a record of what's installed, enabling you to easily remove everything if you need to later, and allowing you to receive updates when they become available.

If for some reason you want to install our older bare-metal toolchain, you can do that instead with the following commands:

```sh
brew tap rosco-m68k/toolchain
brew install gcc-cross-m68k@13 vasm-all srecord minipro
```

This isn't recommended for most users, but might be useful if you're working with an older board/firmware branch, or if you have special build requirements and don't need our libc.

### On Linux®

Note: These steps specifically target Debian-based distributions (particularly, Ubuntu 20.04 at present). If you are using a different distribution, you may need to replace `apt-get` with e.g. `yum` or `dnf` in these steps.

Firstly, you'll need to install some essential build software, and then install the cross-compiler and VASM assembler (you'll probably be asked for your password at the sudo step):

```sh
sudo apt-get install gcc g++ srecord
brew tap rosco-m68k/toolchain
brew install rosco-m68k-toolchain@13
```

Just like on macOS®, this will automatically download, build and install all the dependencies that you would normally have to build manually. Homebrew will also keep a record of what's installed, enabling you to easily remove everything if you need to later, and allowing you to receive updates when they become available.

If you want to install minipro (optional, for burning your own EEPROMs):

```sh
brew install minipro
```

Once all that's done, you're ready to rock! 🎉

---

---

[Home](index.md) | [Getting Started](getting-started.md) | [Connecting](connecting.md) | [Running the Examples](running-the-examples.md) | [Toolchain Installation](toolchain-installation.md) | [Building the Software](building-the-software.md) | [Installing the Emulator](installing-the-emulator.md) | [Debugging with MAME](MAME-serial.md) | [Using SD Cards](SDCardGuide.md)

Copyright © 2020-2024 The Really Old-School Company Limited. Registered in England and Wales No. 12596175
The Really Old-School Company Ltd, 15 Starthe Bank, GB DE75 7AX Tel: 0330 133 2083

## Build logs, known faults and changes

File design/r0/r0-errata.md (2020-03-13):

# Errata for revision 0 PCB

* The MFP address lines are reversed (see [#7](https://github.com/roscopeco/rosco_m68k/issues/7) and [#11](https://github.com/roscopeco/rosco_m68k/issues/11))
* The top silkscreen incorrectly labels expansion pin 2 as pin 64 (see [#8](https://github.com/roscopeco/rosco_m68k/issues/8))
* It is recommended to replace the **Q1** 1.8432 MHz crystal with a 3.6864 MHz part to enable 9600 BPS from the UART
  * Farnell part [9712909](https://uk.farnell.com/iqd-frequency-products/lfxtal003263/crystal-3-686400mhz/dp/9712909?CMP=i-ddd7-00001003) is a suitable drop-in replacement
  * This is due to software now using the divide-by-16 mode on the UART to aid noise resiliency
  * Higher frequencies are **not recommended** as they exceed the maximums specified for the MC68901 MFP

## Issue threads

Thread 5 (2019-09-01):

IACK generation may not be robust enough

roscopeco, 2019-09-01:
Currently, the glue logic CUPL code (in `/pldcode/glue/GLUE_LOGIC.PLD`) uses FC0, FC1 and FC2 to generate the IACK signal. On MC68010 this is not always true - breakpoints also occur with those three lines high.

The difference on this processor is determined by reading address lines 16-19 - during IACK these four lines will also be high, while in a breakpoint situation they will not.

This is not currently a problem but worth investigating if there's ever a desire to do hardware breakpointing.

roscopeco, 2020-03-13:
Won't do.

Closed 2020-03-13.

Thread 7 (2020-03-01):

Address lines to MFP are reversed

roscopeco, 2020-03-01:
In the current schematic (and revision 0 board design) the address lines A1-A5 are incorrectly connected to MFP register select RS5-RS1 (I.e they are reversed).

This needs two fixes:

* Correct the schematic
* Implement a software fix for r0 boards

Correcting the schematic is self-evident.

The software fix will involve changing the register addresses in equates.S to reverse bits 1-5. This change will apply only to boards made from the current (pre-schematic-fix) design.

roscopeco, 2020-03-13:
Software fix in place. Will raise new issue to cover schematic fix.

Closed 2020-03-13.

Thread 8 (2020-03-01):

Pin numbering for expansion connector incorrect on r0 silkscreen

roscopeco, 2020-03-01:
The revision zero board has pin identifiers for expansion pins 1 and 64 on the silkscreen.

The pin one identifier is correct, but the pin 64 identifier is incorrectly attached to pin 2. Pin 64 is actually at the bottom right of the connector.

ACs:

* Note this issue in the expansion connector pinout
* Fix this on the r1 board silkscreen

Closed 2020-03-15.

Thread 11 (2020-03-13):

Fix MFP address lines in schematic/board

roscopeco, 2020-03-13:
(See #7 for original report)

In the current schematic (and revision 0 board design) the address lines A1-A5 are incorrectly connected to MFP register select RS5-RS1 (I.e they are reversed).

A software fix has been implemented. The schematic/board still needs to be fixed before the next revision is manufactured.

roscopeco, 2020-03-15:
Fixed.

Closed 2020-03-15.

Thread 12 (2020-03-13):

Replace Q1 with a 3.6864MHz part

roscopeco, 2020-03-13:
Due to the software switching to the divide-by-sixteen mode on the UART receiver, the maximum baud that can be achieved with the current specification is 4800 bps. This can be increased to 9600 bps by replacing Q1 with a 3.6864MHz part.

Farnell part [9712909](https://uk.farnell.com/iqd-frequency-products/lfxtal003263/crystal-3-686400mhz/dp/9712909?CMP=i-ddd7-00001003) (IQD FP's LFXTAL003263) is a suitable drop-in replacement and does not require any other changes.

With this substitution the firmware will double the baud rate to 9600 without modification.

This is probably the highest (standard) speed possible with /16 mode on the MFP without moving to an external clock, due to its maximum frequency specification of 4MHz, and requirement that all timers use at least a /4 prescaler.

In tests 14400 was achieved and found stable, however support is variable in supporting hardware (e.g. USB-Serial adapters) and software (e.g. Minicom).

roscopeco, 2020-03-15:
Fixed in r1 board.

Closed 2020-03-15.

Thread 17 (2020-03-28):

Missing KiCad project file.

paulvdhoeven, 2020-03-28:
I just cloned your project because I am curious what you made of it in the mean time.

Then I discovered that the KiCad project file is missing. Without it KiCad can not be opened in project mode and the link between schematic and PCB is broken. The most logical explanation is that you forgot to put this file in git.

I also saw you entered blue text strings into the title block:
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

These texts should be added via:
**"Eeschema / File / Page Settings"**

roscopeco, 2020-03-28:
Ah, many thanks (again!). I'd added `.pro` files to `.gitignore` for some reason, I've fixed now and the files are in `master`.

Also, noted your suggestion about the title block texts - I'll fix that soon.

Closed 2020-03-28.

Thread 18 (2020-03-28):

Missing footprints for memory chips.

paulvdhoeven, 2020-03-28:
First: Just pulled your changes from github.
Normally my git knowledge stops at making clones, but I have intention of learning more of git.

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

I can now work with it as a normal KiCad project.
First thing I noticed is that footprints for the memory chips were not in the schematic.
You can easily fix this by:
**Pcbnew / File / Export / Footprint association (.cmp) File**

Then go back to Eeschema, and import that file:
**Eeschema / File / Import / Footprint Association File**

I've also used your project as an example of "vector buses" in:
https://forum.kicad.info/t/lots-of-nets-how-to-organize/21967/11

roscopeco, 2020-03-28:
Awesome, thanks for the tip 👍 I'll get that fixed asap.

Interesting reading that page, I've read about global vs hierarchical labels. I decided to go with Global labels for now, but might re-visit that later.

Closed 2020-03-29.

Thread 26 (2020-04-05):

Replace J3 DTACK with IODTACK

roscopeco, 2020-04-05:
Breaking DTACK out onto J3 is not correct - DTACK is _always_ driven by IC5 and should not be driven directly by IO devices.

Instead, the IODTACK (an input to IC5) line should be broken out to the expansion connector, as this is a tri-state line that devices can drive when they are selected and can be put into Hi-Z at all other times. IC5 takes care of using this line when appropriate (though there is a linked issue with the timing of this - See #27 for details).

As a workaround for r0 and r1 boards, it is suggested that a jumper is soldered from IC5 pin 9 to the unused pin 16 on J5.

roscopeco, 2020-05-27:
It's probably better to tristate DTACK itself. This would be more flexible and open the possibility of not forcing EXP to be zero-wait-state (which will be necessary for DRAM based expansions for example).

roscopeco, 2020-07-23:
Fixed in production-candidate r1.2.

Closed 2020-07-23.

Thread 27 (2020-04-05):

DTACK timing is incomplete for end-of-cycle in IO space

roscopeco, 2020-04-05:
The current timing of IODTACK -> DTACK is not robust enough to support IO devices that have slow tear-down times at the end of the read cycle. Specifically, devices that cannot tristate the bus quickly enough when AS is de-asserted can cause the following bus cycles to fail due to contention.

This is because, after the CPU de-asserts AS, it waits for the device to de-assert DTACK before proceeding. However, the glue logic in IC5 incorrectly drops DTACK immediately as AS is de-asserted due to the address decoder de-asserting IOSEL. This means that, immediately on de-asserting AS, DTACK is de-asserted also and the CPU continues with the next bus cycle.

Unfortunately, this means that no matter whether the IO device continues to assert DTACK the CPU will not see it asserted. In cases where the device is still in process of tristating e.g. the data bus, this can cause contention on the next read and cause garbage to be read.

It's worth noting that this is only really a problem when the bus is driven by microcontroller devices - most hardware devices tristate their bus pins virtually immediately when their CS is de-asserted. In the microcontroller case, it requires careful code design to ensure that the bus cycle is timed appropriately for the CPU.

It's also worth noting that this doesn't place any speed requirements on the actual read - the CPU will respond appropriately to DTACK _during_ the read cycle - this problem only manifests at the _end_ of the cycle.

In practice this means that an Arduino, for example, will have to be programmed with direct port access at least for the end-of-cycle, as pin manipulation via the Arduino SDK (`digitalWrite` et al) is too slow for this purpose in all but the most trivial case (e.g. a single pin being tristated).

roscopeco, 2020-10-14:
Keeping open as a reminder for redesign of rosco_m68k_next

roscopeco, 2021-10-10:
Closing, superseded (IODTACK is no longer a thing).

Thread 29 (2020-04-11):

Address decoder IO space is incorrect

roscopeco, 2020-04-11:
The CUPL code for the address decoder contains an error that causes IO space to incorrectly extend from `0xF00000-0xFBFFFF` instead of the desired `0xF80000-0xFBFFFF`. This is wasting half a megabyte at the top of the address space.

The current code for `IOSEL` is:

```
!IOSEL      = IACK & !A18 & A20 & A21 & A22 & A23;
```

Where it should actually be:

```
!IOSEL      = IACK & !A18 & A19 & A20 & A21 & A22 & A23;
```

(Notice that the fixed version includes A19 in the equation).

roscopeco, 2020-04-11:
Though this issue is closed, the fix is imperfect and in practice only 256k of the 512k expansion space above 15MB is actually usable. This _may_ not be worth doing anything about as it would probably mean breaking out even more of the address bus into the address decoder.

Certainly not worth doing now (would mean hardware changes) but will raise an Enhancement to consider in a future board spin.

roscopeco, 2020-04-11:
See #32

Closed 2020-04-11.

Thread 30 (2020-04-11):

DTACK generation in glue code does not support expansion space

roscopeco, 2020-04-11:
When addressing expansion space, the glue logic in IC5 does not correctly generate DTACK. This causes the computer to hang, and makes it impossible to support memory expansions at present.

In keeping with the zero-wait-state design of the onboard RAM and ROM, it seems reasonable to stipulate that memory expansions be fast enough to support zero-wait-state also - anything that doesn't should really be mapped into IO space rather than expansion (which is reserved purely for memory).

The fix is a small change in the CUPL code for IC5. DTACK generation is currently:

```
DTACK        = ((IOSEL # IACK) & MFPDTACK) # (!IACK & EVENROMSEL) # (!IACK & ODDROMSEL) # (!IACK & EVENRAMSEL) # (!IACK & ODDRAMSEL);
```

This should be changed to:

```
DTACK        = ((IOSEL # IACK) & MFPDTACK) # (!IACK & EVENROMSEL) # (!IACK & ODDROMSEL) # (!IACK & EVENRAMSEL) # (!IACK & ODDRAMSEL) # (!IACK & !ODDROMSEL & !EVENROMSEL & !ODDRAMSEL & !EVENRAMSEL & !IOSEL);
```

(This isn't particularly efficient, but does not require hardware changes. It might be worth revisiting this issue in a future board revision).

Closed 2020-04-11.

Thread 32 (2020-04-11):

Remove memory hole between $F00000-$F40000

roscopeco, 2020-04-11:
The current address decoder creates a 256KiB memory hole between `0xF00000-0xF40000`.

Decide whether this is worth fixing. If it is, raise a ticket to fix. If not, close "won't do".

This would require HW changes, so tagging it for r2.

roscopeco, 2020-05-24:
Won't do, superseded by #41

Closed 2020-05-24.

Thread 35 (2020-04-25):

Pads on U1-U4 and IC8 should be the same size as the other ICs

roscopeco, 2020-04-25:
For some reason, the PCB pads on U1-U4 and IC8 are smaller than the other pads. Soldering would be easier if these pads were the same size as the pads on the other ICs. This should be a simple matter of changing the footprint (and probably rerouting some of the traces) - the current footprints are EAGLE-imports anyway and have other issues so it would be good to replace them.

roscopeco, 2020-05-27:
Done for 1.2.

Closed 2020-05-27.

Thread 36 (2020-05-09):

Replace serial header with standard 6-pin Serial -> USB layout

roscopeco, 2020-05-09:
The current board has a custom layout for the UART header. For ease of use with readily-available FTDI cables and adapters this should be replaced with the standard 6-pin layout found on those cables.

roscopeco, 2020-05-09:
When doing this, jumper the 5V line so the board power doesn't have to come from the converter!

roscopeco, 2020-05-27:
Done for 1.2.

Closed 2020-05-27.

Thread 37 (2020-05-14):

Improve performance of RESET LED

roscopeco, 2020-05-14:
Thanks to Henk Gooijen for this suggestion!

> You could add an LED on the RESET using IC9D. Can probably be patched on the R2 board. IC9D pin 11 and pin 12 disconnect from GND (IF that is possible ...). If possible, then connect pin 11 and pin 12 to pin 4. Disconnect LED3 from the NE555 (pin 3) and connect the LED3 (anode) to IC9 D pin 13).

roscopeco, 2020-05-27:
Done for 1.2.

Closed 2020-05-27.

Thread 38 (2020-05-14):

Replace main crystal and derived clock with individual canned oscillators

roscopeco, 2020-05-14:
Thanks to Henk Gooijen for this suggestion:

> So, for R3 you could remove the 7401 and the 8 MHz Xtal, and replace it with a canned 10 MHz oscillator. Further, remove the 7493 and replace it with a 4 MHz canned oscillator

This would get rid of two increasingly hard-to-find and expensive 7400s from the design and significantly increase flexibility. We should definitely do this!

(Plus the current clock is barely in-spec, so there's that too...)

roscopeco, 2020-05-27:
Done for 1.2.

Closed 2020-05-27.

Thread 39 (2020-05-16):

Connect ROM pins 1 and 26

roscopeco, 2020-05-16:
Thanks for RTS4E75 for the idea and testing of this.

If r2 board is sticking with 28-pin ROMs, the usable capacity for those ROMs could be expanded by connecting pins 1 and 26. On larger members of the AT28C family (AT28C256 for example) these pins A14 and A13 respectively. This would allow drop-in replacement for ROM size up to 64KB and is verified to still work with the AT28C64B parts currently in use.

When doing this remember that the address pins on the ROMs are off-by-one WRT the CPU lines as the CPU doesn't have an A0 (CPU A14 maps to ROM A13 etc).

roscopeco, 2020-05-27:
Done for 1.2.

Closed 2020-05-27.

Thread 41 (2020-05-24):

Remap IO and ROM space to the whole top megabyte

roscopeco, 2020-05-24:
Instead of just removing the memory hole mentioned in #32 and returning that address space to EXP, we should use the whole top megabyte for IO and ROM to allow more expansion options.

The current thinking is to map it 50/50 - 512KiB each for IO (0xF00000-0xF7FFFF) and ROM (0xF80000-0xFFFFFF).

Thanks to @RTS4E75 for the suggestion on Discord.

Requires hardware changes (more address lines into the decoder) and probably a bigger GAL, tagging for r2.

roscopeco, 2020-10-14:
Marking 'maybe' as 32-bit address space may change the priority on this.

roscopeco, 2021-03-05:
Closing as this will need a complete rethink for r2 anyway.

Closed 2021-03-05.

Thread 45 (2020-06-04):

Investigate: In-circuit ROM reprogramming

roscopeco, 2020-06-04:
Look into supporting in-circuit EEPROM reprogramming. Would entail:

* Stop tying /WE high on the EEPROMs
* Possibly some HW protection (maybe jumper /WE, or have a GAL handle /WE in response to some Magick Incantation)
* Software support for reprogramming (not in ROM, obvs!)

This should be doable without too much trouble, and might be a use for the MFP (in conjunction with a bit of glue, this would probably fit in the existing GALs).

roscopeco, 2021-03-05:
ICP accepted for r2, leaving open as a reminder.

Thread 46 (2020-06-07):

Address decoder lines should not be tri-state

roscopeco, 2020-06-07:
The output lines from the address decoder should not be tristate. There are no pull resistors on these lines, and in any event it is expected by expansions that they always be driven - there is no value in expansions driving these lines directly, rather they should rely on the decoder to correctly select the memory space in use.

roscopeco, 2020-06-07:
Can be hot-fixed into release/revision-1.01, remove tri-state logic and replace with gating on /AS.

Closed 2020-06-07.

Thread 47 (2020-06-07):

Emulate open-collector DTACK in glue logic

roscopeco, 2020-06-07:
The glue logic GAL should emulate open-collector behaviour for DTACK by tri-stating the pin, with enable being driven by DTACK being low. A pull-up should then be applied to DTACK to give correct behaviour.

Hardware changes required - should be done for revision 1.2 or 2. Also need to investigate the impact on current run of V9958 boards which do not manage DTACK (should be fixable with a small jumper modification to pull DTACK low when VDP CS goes low).

Closed 2020-06-07.

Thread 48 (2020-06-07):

MFP DS is asserted incorrectly at all times

roscopeco, 2020-06-07:
The DS line of the MFP is incorrectly asserted at all times. This causes bus contention when working with even IO addresses and prevents writing to certain registers from working as it also trashes MFP registers at the following odd address.

The problem is in the glue logic:

```
/MFPDS  = /LDS + IACK
```

Should be:

```
/MFPDS  = /LDS + /IACK
```

This is a minimal-impact fix. Hotfix for release/revision-1.01 (and release a bulletin for existing users).

Closed 2020-06-07.

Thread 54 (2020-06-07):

Add pull-up on DTACK for 1.2 and investigate patch for current-run video board

roscopeco, 2020-06-07:
With new DTACK handling in current develop (for 1.2 board) we will need two things:

* Pull up on DTACK
* A patch for current run video board (pull DTACK on VDP CS)

roscopeco, 2020-07-23:
Fixed on production-candidate r1.2, Fix implemented in V9958 glue logic (jumper required on boards).

Raised https://github.com/rosco-m68k/hardware-projects/issues/18 to cover work to implement long-term fix on the video board.

Closed 2020-07-23.

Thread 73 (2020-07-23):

RUN LED is the wrong way around

roscopeco, 2020-07-23:
On r0, r1 and r1.2 board the RUN LED is the wrong way around.

ACs:

* RUN LED is the same way around as the other LEDs on the board.

roscopeco, 2020-10-14:
Closing as next revision will be a complete redesign.

roscopeco, 2020-11-26:
Done anyway in r1.21 (mostly for tracking)

Closed 2020-10-14.

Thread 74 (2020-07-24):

Fix incorrect system timer frequency

roscopeco, 2020-07-24:
The system timer tick (driven by MFP timer C) is incorrectly running at 200Hz. It should be 100Hz.

This is because the crystal from which the timers are derived had it's frequency doubled after r0, but the bootstrap code that sets up Timer C has never been updated.

200Hz is high and has a negative (if slight) impact on system performance. Additionally, the upticks counter (which is supposed to be hundredths of a second) in FW 1.1 and 1.2 is incorrect.

This is not an issue for FW 1.01 (as it does not track upticks), but should be fixed in FW1.1 and 1.2 (and beyond).

Additionally the counter that drives the I0 flash will need to be adjusted as we want to keep the existing ~1Hz flash.

Closed 2020-07-24.

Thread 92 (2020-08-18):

Firmware should only optionally use GPIOs

roscopeco, 2020-08-18:
Currently, if the timer tick is enabled, it will always toggle GPIOs (to flash the green LED). This limits the utility of the GPIO port and makes efficient low-level programming more difficult.

While one can disable the timer completely with `bclr.b  #5,MFP_IMRB`, this also disables updating of the uptime counters, and so is not optimal. There should be a variable in the SDB that one can set to disable the GPIO toggling, while still allowing the timer to continue operating.

XarkLabs, 2020-08-19:
Thinking a little bit about this, my proposal would be to have a documented "GPIO mask" that has bits set that are "user use" that the system should not alter (default ~0x83 = LEDs, and CTS - and as discussed red LED will always blink on "crash" regardless).    Then the few places where firmware etc. touches GPIO change bset/cclr/bchg test the mask (or probably better) just read/modify/write byte using gpio_mask. This also functions as a simple "indicator" as to what GPIOs are in use (which might be handy).

roscopeco, 2020-08-19:
I like this idea @XarkLabs , seems more flexible than a simple Boolean. Good call :)

Closed 2020-11-26.

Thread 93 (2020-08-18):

Terminal exception handlers should ensure GPIOs are in a known state before using them

roscopeco, 2020-08-18:
The terminal exception handlers (BUS ERROR, ADDRESS ERROR and ILLEGAL INSTRUCTION) currently flash the red LED in a different pattern to indicate the fault condition.

They **do not** initialise the GPIOs to the appropriate state before doing this. In cases where the programmer has changed the state of the GPIOs to enable efficient use of the MFPs GPIO port, this may result in non-visible flashing in a crash situation.

The exception handlers should set the appropriate GPIO to OUTPUT (and initialise the GPIO port to a known state) before entering into the terminal loop.

Closed 2020-11-29.

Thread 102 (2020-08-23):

DTACK operation is incorrect on r1 boards

roscopeco, 2020-08-23:
@XarkLabs discovered that DTACK operation is incorrect on r1 boards with r1.1 GAL code.

The incorrect behaviour can be seen in the trace below - note that, when IOSEL is asserted for IO accesses, DTACK does not go high as it should. This is causing the CPU to proceed faster than the MFP can correctly handle, and means that IODTACK is never asserted by the MFP (due to it's CS being deasserted by the premature end-of-cycle).

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

The problem is due to incorrect precedence in the logic equations for IC5. This should be fixed on the 1.1 branch. **This also needs to be investigated in 1.2 to ensure we do not have similar issues**.

Due to the special-case handling of IACK cycles, it's worth noting that IACK functions correctly.

A fix **must not** change the behaviour externally (especially for EXPSEL accesses) and it is desirable to retain the existing 'normally-asserted' DTACK behaviour if possible.

Closed 2020-08-30.

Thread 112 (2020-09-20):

RS232-USB PL2302 causes problems after loading

nbrok, 2020-09-20:
I use no FTDI cable but an RS232 to USB cable (PL2302). With this I have an issue that after loading a program via Kermit that no ready message is shown. This due an USB reset after Kermit did load the file.
As I insert a readchar call in kmain of ehbasic or adventure then I can get the start-up message of that particular program after pressing a key. This is a dirty hack. I think the delay after loading a program is to short. (So I read from the ROM sourcecode)

nbrok, 2020-09-21:
I solved it by changing the delay value in main2.c of the firmware.
OLD:
// Wait a short while for the user's terminal to come back...
    mcBusywait(100000);
NEW:
// Wait a short while for the user's terminal to come back...
    mcBusywait(400000);

This results in 720 ms delay at 10MHz

roscopeco, 2020-09-22:
Reopening to cover work to make this happen.

Increased delay should be applied as a hot fix to 1.1, 1.2 and also on Develop.

Closed 2020-10-04.

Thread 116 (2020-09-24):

Easy68K trap #15 function #7 does not work with 68681

roscopeco, 2020-09-24:
The ROM code for the Easy68K trap function #7 (CHECKINPUT) is still directly talking to the MFP.

Instead, it should use whichever UART is the default.

This will probably mean adding a new function to the EFP to support.

Closed 2020-11-26.

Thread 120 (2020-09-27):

ehBASIC inserts random CR when output is via V9958

roscopeco, 2020-09-27:
When ehBASIC is being used with 1.1 or 1.2 ROMs and output is going to the V9958 text console, random carriage-returns are inserted into the output. For example, in this screenshot a CR was output halfway through typing in line 10, however the subsequent LIST shows that this CR is not actually inserted into the line.

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

(Hardware issues have been ruled out, the screenshot above is from MAME, though this also happens on real hardware).

I suspect this is an issue in the ehBASIC echo routine. If that doesn't turn up anything, another place to look might be the V9958 console driver in `vdpcon.S` (specifically, is there a character it shouldn't print?)

Closed 2020-10-03.

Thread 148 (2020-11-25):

Glue logic should use A18 or A19 for IACK, not A17

roscopeco, 2020-11-25:
The glue logic (IC5) currently defines IACK as:

```
/IACK     = A17 * FC0 * FC1 * FC2
```

This is not correct for CPUs MC68020 and up - for those CPUs, A17 is high to indicate a Coprocessor CPU Cycle.

For upward compatibility, this should be changed to use either A18 or A19.

(TODO: Check what later CPUs output on these pins for IACK cycles - it may be that we need multiple pins in the A16-A19 range, and if so, probably a bigger GAL...)

roscopeco, 2021-03-05:
Won't fix on r1 boards, leaving open as a reminder for r2.

roscopeco, 2021-03-21:
Decided this might as well be fixed on r1.23 as I'm rerolling the fab anyway. Fix in flight on https://github.com/rosco-m68k/rosco_m68k/tree/feature/glue-experiment .

Closed 2021-04-02.

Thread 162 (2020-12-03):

can't build firmware on linux due to make: m68k-elf-gcc: Command not found

quarterturn, 2020-12-03:
On Ubuntu 20.04
Following Toolchain.md using manual source install method.
GCC 7.5.0 install successful per instructions.

firmware build fails at:

`

$ BIGROM=true make clean all
make -C stage2 clean
make[1]: Entering directory '/home/quarterturn/Documents/rosco_m68k/code/firmware/rosco_m68k_v1.2/stage2'
rm -f init2.o common.o serial.o machine.o main2.o kermit/kermit.o kermit/kermit_support.o sdfat/gpio.o sdfat/bbspi.o sdfat/bbsd.o sdfat/load.o sdfat/fat_io_lib/fat_access.o sdfat/fat_io_lib/fat_cache.o sdfat/fat_io_lib/fat_filelib.o sdfat/fat_io_lib/fat_format.o sdfat/fat_io_lib/fat_misc.o sdfat/fat_io_lib/fat_string.o sdfat/fat_io_lib/fat_table.o sdfat/fat_io_lib/fat_write.o loader2.bin loader2.bin.zip loader2.bin.zip.o loader2.map
make[1]: Leaving directory '/home/quarterturn/Documents/rosco_m68k/code/firmware/rosco_m68k_v1.2/stage2'
rm -f bootstrap.o lzgmini_68k.o decompress.o ansicon.o trap14.o main1.o  easy68k/syscalls_asm.o easy68k/syscalls.o video9958/vdpcon.o video9958/font.o rosco_m68k.rom rosco_m68k_odd.rom rosco_m68k_even.rom rosco_m68k.map
vasmm68k_mot -Felf -m68010 -quiet  -o bootstrap.o bootstrap.S
vasmm68k_mot -Felf -m68010 -quiet   -o lzgmini_68k.o lzgmini_68k.s
vasmm68k_mot -Felf -m68010 -quiet  -o decompress.o decompress.S
vasmm68k_mot -Felf -m68010 -quiet  -o ansicon.o ansicon.S
vasmm68k_mot -Felf -m68010 -quiet  -o trap14.o trap14.S
m68k-elf-gcc -c -std=c11 -ffreestanding -nostartfiles -Wall -Wpedantic -Werror -Iinclude -mcpu=68010 -march=68010 -mtune=68010 -Os -fomit-frame-pointer -mno-align-int -mno-strict-align   -DEASY68K_TRAP -DVIDEO9958_CON -Ivideo9958/include -o main1.o main1.c
make: m68k-elf-gcc: Command not found
make: *** [Makefile:66: main1.o] Error 127

`

here's all I have in my home opt directory path:

`

~/opt/cross/bin$ ls
m68k-elf-addr2line  m68k-elf-c++filt  m68k-elf-ld      m68k-elf-objcopy  m68k-elf-readelf  m68k-elf-strip  srec_info
m68k-elf-ar         m68k-elf-elfedit  m68k-elf-ld.bfd  m68k-elf-objdump  m68k-elf-size     srec_cat        vasmm68k_mot
m68k-elf-as         m68k-elf-gprof    m68k-elf-nm      m68k-elf-ranlib   m68k-elf-strings  srec_cmp

`

make install for gcc fails with:

`

 make install-gcc install-target-libgcc
/bin/bash ../gcc-7.5.0/mkinstalldirs /home/quarterturn/opt/cross /home/quarterturn/opt/cross
make[1]: Entering directory '/home/quarterturn/Downloads/m68k-toolchain/build-gcc-7.5.0-m68k/fixincludes'
rm -rf /home/quarterturn/opt/cross/libexec/gcc/m68k-elf/7.5.0/install-tools
/bin/bash ../../gcc-7.5.0/fixincludes/../mkinstalldirs /home/quarterturn/opt/cross/libexec/gcc/m68k-elf/7.5.0/install-tools
mkdir -p -- /home/quarterturn/opt/cross/libexec/gcc/m68k-elf/7.5.0/install-tools
/bin/bash ../../gcc-7.5.0/fixincludes/../mkinstalldirs /home/quarterturn/opt/cross/lib/gcc/m68k-elf/7.5.0/install-tools/include
/usr/bin/install -c -m 644 ../../gcc-7.5.0/fixincludes/README-fixinc \
  /home/quarterturn/opt/cross/lib/gcc/m68k-elf/7.5.0/install-tools/include/README
/usr/bin/install -c fixinc.sh /home/quarterturn/opt/cross/libexec/gcc/m68k-elf/7.5.0/install-tools/fixinc.sh
/usr/bin/install -c fixincl /home/quarterturn/opt/cross/libexec/gcc/m68k-elf/7.5.0/install-tools/fixincl
/usr/bin/install -c mkheaders /home/quarterturn/opt/cross/libexec/gcc/m68k-elf/7.5.0/install-tools/mkheaders
make[1]: Leaving directory '/home/quarterturn/Downloads/m68k-toolchain/build-gcc-7.5.0-m68k/fixincludes'
make[1]: Entering directory '/home/quarterturn/Downloads/m68k-toolchain/build-gcc-7.5.0-m68k/lto-plugin'
make[2]: Entering directory '/home/quarterturn/Downloads/m68k-toolchain/build-gcc-7.5.0-m68k/lto-plugin'
 /bin/mkdir -p '/home/quarterturn/opt/cross/libexec/gcc/m68k-elf/7.5.0'
 /bin/bash ./libtool --tag=disable-static  --mode=install /usr/bin/install -c   liblto_plugin.la '/home/quarterturn/opt/cross/libexec/gcc/m68k-elf/7.5.0'
libtool: install: /usr/bin/install -c .libs/liblto_plugin.so.0.0.0 /home/quarterturn/opt/cross/libexec/gcc/m68k-elf/7.5.0/liblto_plugin.so.0.0.0
libtool: install: (cd /home/quarterturn/opt/cross/libexec/gcc/m68k-elf/7.5.0 && { ln -s -f liblto_plugin.so.0.0.0 liblto_plugin.so.0 || { rm -f liblto_plugin.so.0 && ln -s liblto_plugin.so.0.0.0 liblto_plugin.so.0; }; })
libtool: install: (cd /home/quarterturn/opt/cross/libexec/gcc/m68k-elf/7.5.0 && { ln -s -f liblto_plugin.so.0.0.0 liblto_plugin.so || { rm -f liblto_plugin.so && ln -s liblto_plugin.so.0.0.0 liblto_plugin.so; }; })
libtool: install: /usr/bin/install -c .libs/liblto_plugin.lai /home/quarterturn/opt/cross/libexec/gcc/m68k-elf/7.5.0/liblto_plugin.la
libtool: finish: PATH="/home/quarterturn/opt/cross/bin:/home/quarterturn/bin:/usr/local/cuda-10.1/bin::/usr/local/cuda/bin:/home/quarterturn/opt/cross/bin:/home/quarterturn/bin:/usr/local/cuda-10.1/bin::/usr/local/cuda/bin:/home/linuxbrew/.linuxbrew/bin:/home/linuxbrew/.linuxbrew/sbin:/home/quarterturn/opt/cross/bin:/home/quarterturn/bin:/usr/local/cuda-10.1/bin::/usr/local/cuda/bin:/home/quarterturn/.local/bin:/usr/local/sbin:/usr/local/bin:/usr/sbin:/usr/bin:/sbin:/bin:/usr/games:/usr/local/games:/snap/bin:/sbin" ldconfig -n /home/quarterturn/opt/cross/libexec/gcc/m68k-elf/7.5.0
----------------------------------------------------------------------
Libraries have been installed in:
   /home/quarterturn/opt/cross/libexec/gcc/m68k-elf/7.5.0

If you ever happen to want to link against installed libraries
in a given directory, LIBDIR, you must either use libtool, and
specify the full pathname of the library, or use the `-LLIBDIR'
flag during linking and do at least one of the following:
   - add LIBDIR to the `LD_LIBRARY_PATH' environment variable
     during execution
   - add LIBDIR to the `LD_RUN_PATH' environment variable
     during linking
   - use the `-Wl,-rpath -Wl,LIBDIR' linker flag
   - have your system administrator add LIBDIR to `/etc/ld.so.conf'

See any operating system documentation about shared libraries for
more information, such as the ld(1) and ld.so(8) manual pages.
----------------------------------------------------------------------
make[2]: Nothing to be done for 'install-data-am'.
make[2]: Leaving directory '/home/quarterturn/Downloads/m68k-toolchain/build-gcc-7.5.0-m68k/lto-plugin'
make[1]: Leaving directory '/home/quarterturn/Downloads/m68k-toolchain/build-gcc-7.5.0-m68k/lto-plugin'
make[1]: Entering directory '/home/quarterturn/Downloads/m68k-toolchain/build-gcc-7.5.0-m68k/gcc'
make[1]: *** No rule to make target 'install'.  Stop.
make[1]: Leaving directory '/home/quarterturn/Downloads/m68k-toolchain/build-gcc-7.5.0-m68k/gcc'
make: *** [Makefile:4301: install-gcc] Error 2

`

quarterturn, 2020-12-04:
review of config.log showed gcc-9.3.0 having an issue with '-qversion' option in the gcc makefile. I instead got the source of gcc-9.3.0 and followed the same build process.

make now fails at:
ake[2]: Entering directory '/home/quarterturn/Downloads/m68k-toolchain/build-gcc-9.3.0-m68k/gcc'
g++ -c   -g -O2 -DIN_GCC  -DCROSS_DIRECTORY_STRUCTURE   -fno-exceptions -fno-rtti -fasynchronous-unwind-tables -W -Wall -Wno-narrowing -Wwrite-strings -Wcast-qual -Wmissing-format-attribute -Woverloaded-virtual -pedantic -Wno-long-long -Wno-variadic-macros -Wno-overlength-strings   -DHAVE_CONFIG_H  -DGENERATOR_FILE -fno-PIE -I. -Ibuild -I../../gcc-9.3.0/gcc -I../../gcc-9.3.0/gcc/build -I../../gcc-9.3.0/gcc/../include  -I../../gcc-9.3.0/gcc/../libcpp/include  \
	-o build/genmodes.o ../../gcc-9.3.0/gcc/genmodes.c
/home/quarterturn/opt/cross/m68k-elf/bin/as: unrecognized option '--64'

quarterturn, 2020-12-04:
I looked at issue #5 of the homebrew-toolchain git and started over with the homebrew method. I had to 'brew edit vasm-all' and make the following change:

sha256 "9ae0b37bca11cae5cf00e4d47e7225737bdaec4028e4db2a501b4eca7df8639d"

Only other thing I had to fix was ' the pstopdf error via sudo cp /usr/bin/ps2pdf /usr/bin/pstopdf'
The firmware now can be built.

Closed 2020-12-04.

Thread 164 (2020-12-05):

Trap #15 handler should not trash D0

roscopeco, 2020-12-05:
Currently, the trap handlers are allowed to trash their arguments. Sometimes this works well (e.g. string pointing to next in an array) but often it is most annoying (e.g. trashing the function code, meaning it must be set again when e.g. printing multiple buffers consecutively).

* Go through all the handlers, and save at least the function code argument from modification.
* Document this.

roscopeco, 2021-03-05:
Fix in flight for this: https://github.com/rosco-m68k/rosco_m68k/pull/180

Closed 2021-03-05.

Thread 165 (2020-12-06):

Trap #15 handler should not trash registers if not used as an argument

roscopeco, 2020-12-06:
Currently, the trap handlers are allowed to trash their arguments (and this is documented). However, some of the handlers also trash registers that **are not** used as arguments, for example `A0` is trashed by TRAP 15 function 14. This is annoying (to say the least) and should not happen.

* Go through all the handlers, and ensure they do not trash non-argument registers.
* Document this.

See also: #164

roscopeco, 2021-03-05:
Fix in flight for this: https://github.com/rosco-m68k/rosco_m68k/pull/180

roscopeco, 2021-03-05:
Fixed by https://github.com/rosco-m68k/rosco_m68k/pull/180

Closed 2021-03-05.

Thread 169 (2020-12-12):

Firmware 1.2 does not work on MC68000

roscopeco, 2020-12-12:
The 1.2 (and up) firmware does not work on MC68000. This is due to the temporary bus error handler, which assumes a minimum of 68010 (and treats the stack frame accordingly).

For 68000, the easiest thing to do is just unstack the frame and jump directly (as it does not support software re-run).

As part of this fix, it's also worth bringing in the 68020 support from the development firmware.

Closed 2020-12-12.

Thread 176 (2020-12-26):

VASM sha256 hash mismatch.

bzuidgeest, 2020-12-26:
When brewing I got an error when getting to vasm-all

Error: SHA256 mismatch
Expected: 2b7aba9b6d0a196a2ab009fbed08f10acd94da41d11d3a224cb59b2a6c2f2b41
  Actual: 9ae0b37bca11cae5cf00e4d47e7225737bdaec4028e4db2a501b4eca7df8639d
    File: /home/****/.cache/Homebrew/downloads/31e078af95a73fde88e3d55dc37179f5520233a98b3f351a785b0a3f9f54f314--vasm.tar.gz
To retry an incomplete download, remove the file above.

I looked into the formulae and it links to sun.hasenbraten.de/vasm/release/vasm.tar.gz as the download url.
Version is set at 1.8f. So I assume the sha256 is for that version. However when visiting page
http://sun.hasenbraten.de/vasm/index.php?view=relsrc which lists this url, it notes that the current version is v1.8i
So I assume the formulae or however homebrew calls its scripts is out of date.

VASM also has a page with tagged code releases http://sun.hasenbraten.de/vasm/index.php?view=tagged

there you can find links to a specific source release version. This seems a more stable download link to me for use with the formulae. So my advise would be to switch the link to using that (http://phoenix.owl.de/tags/vasm1_8f.tar.gz in this case). Otherwise you will always have it breaking on new releases of vasm. Maybe there are other options as I am no expert on this.

roscopeco, 2020-12-30:
Thanks for the report @bzuidgeest , I was not aware of the tagged releases. I have raised https://github.com/rosco-m68k/homebrew-toolchain/issues/7 in the toolchain repo (linked to this issue) to fix this.

Thanks again! :)

roscopeco, 2021-01-18:
Closed, thanks @0xTJ :)

Closed 2021-01-18.

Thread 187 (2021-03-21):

Memcheck needs updating for r1.23 boards

roscopeco, 2021-03-21:
The (forthcoming) revision 1.23 board will change (fix) the way that DTACK is handled in expansion space.

While this is a Good Thing™ , it does incur a behavioural change in that `memcheck` will now encounter bus errors when it hits the memory hole at 0x00F00000. We need to either:

* Stop it looking at that memory, much as we do for IO space, or
* Give it a bus error handler, like the firmware uses.

I am ambivalent at this point as to which one we do. That said, and given there is talk of potentially using the memory hole for other purposes, it's _probably_ best if we avoid it altogether, though of course if we _don't_ ever do that then the bus error handler would be more future-proof.

So, in short, 🤷‍♂️

roscopeco, 2021-03-22:
Fix in flight on https://github.com/rosco-m68k/rosco_m68k/tree/feature/glue-experiment .

Closed 2021-04-02.

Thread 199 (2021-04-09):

r1.23 schematics are missing

roscopeco, 2021-04-09:
It appears that the 1.23 schematics somehow got lost during the merging of the branches, and they no longer match with the PCB in `release/version-1.3`, `develop` and `master`.

They are probably still on a branch on Ross' local machine somewhere. They need to be found and merged correctly to the above mentioned branches.

Thanks to e2k for reporting (on Discord)

Closed 2021-04-14.

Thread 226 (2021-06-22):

mcEnableInterrupts in machine lib enables *all* interrupts

roscopeco, 2021-06-22:
The `mcEnableInterrupts` function in the `machine` standard lib indiscriminately enables all interrupts (it sets the mask to 0).

This could potentially cause problems. A better solution would be to have the function take a new level mask as an argument.

Closed 2021-06-30.

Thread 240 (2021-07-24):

TRAP #15 Function #6 should print, not send (despite the name)

roscopeco, 2021-07-24:
The Easy68k TRAP #15 function #6 , despite being named `SENDCHAR`, is documented to _display_ the character, so it should probably use the underlying `PRINTCHAR` EFP rather than the `SENDCHAR` one.

It might be worth (somehow) checking we're aligned with Easy68k on this...

(See: https://github.com/rosco-m68k/rosco_m68k/blob/develop/code/firmware/rosco_m68k_v1.3/InterfaceReference.md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 )

0xTJ, 2021-07-25:
Based on the EASy68K reference, it looks like `TRAP #15` function `#6` should go to the same place as `#0`, `#1`, `#3`, and all the others that "display", so I'd agree that it should go through the `PRINTCHAR` route. I think everything for `TRAP #15` should go through the default console instead of default UART (and as far as I can see this is the only one that doesn't do this yet).

Might also be worth considering (for any added user input devices, I've been looking at making a PS/2 board) adding FW/EFP routines for generic user input, as opposed to UART input; something that is to `RECVCHAR` what `PRINTCHAR` is to `SENDCHAR`.

Closed 2021-07-25.

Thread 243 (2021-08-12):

MFP IACK needs more complete decoding

roscopeco, 2021-08-12:
Currently, the IACK used on the mainboard glue to drive IACK on the MFP is not anything like good-enough. The equation is:

```
/IACK     = A19 * FC0 * FC1 * FC2
```

The output of this pin is driven directly into the MFP IACK, and also used to drive DS on the MFP.

This causes the MFP IACK (and DS) to be driven for **all** interrupt acknowledge cycles. This race condition is the root cause of the issue seen with any other device which is using legacy IACK cycles whereby after a short time the MFP interrupts will become inoperable.

There is nothing to be done (without hardware modification) on current batch of boards, but raising this for any future r2, and also for the pro.

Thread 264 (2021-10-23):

EhBASIC Makefile and build instructions need updating...

XarkLabs, 2021-10-23:
EhBASIC Makefile and build instructions need a bit of updating.  Currently I believe the Makefile ignores the MC68681 option and always tries to use the FIRMWARE_IO.  This is a problem for older firmware, so Makefile should probably default to new firmware, but still honor other options (my bad).

Closed 2021-11-13.

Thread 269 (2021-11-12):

With latest changes, cstdlib exit() does not call destructors

roscopeco, 2021-11-12:
With latest changes, the `exit` function in `cstdlib` does not correctly call destructors. It should.

This is complicated slightly because the `exit` function is defined in the `cstdlib` library, and there is no requirement that `start_serial` actually be in use in order to use that library. So it's possible that global destructors are not even _supported_ when `exit` is called.

I propose the way to fix this is to add an EFP entry for e.g. `EFP_PROGRAM_EXIT`. The firmware can set this the same as the reset vector (remembering to update it to `warm_boot` in `main1.c`) and then `start_serial` can change it to the address of a label _after_ kmain returns in `init.S`.

However, this change is tricky currently (due to `r2-initial-import` being in-flight) so I am proposing we defer until after than merge (and then fix under this ticket, which I will assign to myself).

**Note**: While investigating, I found that `abort` (also in `cstdlib.c`) will need updating when r2-initial-import is merged, as it currently hardcodes the ROM start address in inline assembly. This will instead need to be taken from the linker-provided symbol.

Closed 2022-01-14.

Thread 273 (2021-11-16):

`calloc` and `realloc` need implementing properly

roscopeco, 2021-11-16:
With latest changes, `calloc` is a super-simple implementation that works, but is inefficient and slow.

`realloc` is implemented "bare-minimum to spec" (i.e. it always fails, returning `NULL`).

Both of these need implementing properly (in `libs/src/shmall/rosco_m68k.cpp`).

0xTJ, 2021-11-23:
Annoyingly, it's really hard (I haven't been able to, even following instructions on how to convince GCC to do that, which I assume worked in an older version) to get current GCC to choose to emit the `DBcc` instruction to take advantage of the MC68010 loop mode. I've been working on this and have had to use inline assembly (just the 2 instructions that form the loop, defaulting to a simple pure C implementation when `__m68k__` isn't defined) to get good performance on the memory clear and copy for these two functions.

When I use the `__asm__`, I get a ~7x performance increase for `calloc` in a benchmark added to `malloc-test`. (~45 seconds down to ~7 seconds for 1024 `calloc` calls with a size of 0x8000)

Closed 2021-12-08.

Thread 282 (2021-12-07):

LED Blink on r2 board is unreliable

roscopeco, 2021-12-07:
The interrupt-driven LED blink on the r2 board with firmware 2.0 is unreliable, and will sometimes stop blinking (especially noticeable when the computer is under load, such as when receiving via Kermit).

This appears to be a simple issue in the firmware. Specifically, the `TICK_HANDLER` in `bootstrap.asm` is writing the byte part of a register, but testing a word. So this code:

```
move.b  SDB_INTFLAGS,D1
tst     D1                        ; Is INTFLAGS zero?
```

should actually use an explicit size for the `tst` instruction (which otherwise defaults to `test.w`):

```
move.b  SDB_INTFLAGS,D1
tst.b   D1                        ; Is INTFLAGS zero?
```

I will push a branch to fix this issue shortly.

Closed 2021-12-08.

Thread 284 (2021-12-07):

CPU detection does not work in a "fully-loaded" system

roscopeco, 2021-12-07:
The current firmware relies on at least one bus error during early initialisation in order to detect the CPU model, which is then used to determine to multiplier for speed calculation.

On r2 boards, there are three devices that have the potential to cause bus error during init - the 68681 (which _should_ always be present), Xosera and the V9958.

Assuming the 68681 will never cause a bus error, if a Xosera board is present (thus not causing a bus error) then the V9958 init is skipped completely (removing the last opportunity for a bus error). So in this configuration, the CPU model is never detected, and the firmware chooses a (rather optimistic) default:

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

Suggestions for a fix (**UPDATE** Illegal Instruction trap decided as the way to go, see discussion in comments):

* ~Always generate a bus error (perhaps we can reserve a word in IO space that should always be unused, for example)~
* ~Stop relying on bus errors for CPU detection (we do this because the CPU stacks enough useful info for the handler)~
* Something else? **Yes - probe with CPU-specific instructions & illegal instruction trap**

0xTJ, 2022-01-18:
Looking at the M68k family PRM, and some of the individual chip UMs, I'm thinking that using bus errors isn't the best solution.

If CPU detection has to be done, I think doing it by hooking the Illegal Instruction exception would be best. The PRM has a handy table of which instructions are supported on which CPU (but doesn't include the M68060), and I don't think it would be too hard to pick some to identify the CPU.

The MC68030UM suggests that code shouldn't be made to expect a specific stack frame type from specific exceptions, and that each exception handler should all be able to handle any of the formats, which are all described in the PRM.

One other option would be to drop CPU detection entirely, and make all the core code be CPU-agnostic. As far as I understand, the execution environments at boot should be equivalent between CPUs, so we don't *need* to know it right away. Any extra initialization (cache, MMU, FPU) can be done based on some configuration information (like a block in system flash), after the first stage of boot-up (so that you can't brick your system by telling it that it's an '040 when it's a '010).

Regardless of whether CPU detection is kept, I think it would be best to have the core of the firmware be built for '000 (no `MOVEC`, vector table at address 0), but able to handle exception stack frames from any CPU. To me, this feels like the most elegant solution for system firmware.

0xTJ, 2022-01-18:
Very fair wanting to keep CPU detection, it is nice to see that pop up.

Also, I had forgotten (even though I had it in front of me while writing) that the '000 doesn't use the format-code stack frame, so I absolutely agree with keeping the '010 as the least common denominator.

roscopeco, 2022-01-18:
Cool, I think that's reasonable (and FWIW I just did a quick test and it doesn't currently work with a 68000, at least not the random one I just pulled out of a drawer - it hangs during the hardware probe).

I will have a look at switching to illegal instruction traps as you suggest, it's a much cleaner idea than the bus-error-side-effect thing (and we have plenty of room now) 👍

0xTJ, 2022-01-18:
Looking at the instructions that exist, it looks like `EXTB` (among several other choices) could be used to rule out the '010, `CALLM`/`RETM` pair (with a type $00 module descriptor to avoid any external state impact) to check for '020, and `MOVE16` to check for '040.

Using `PMOVE` as reading from an MMU register should be safe, though I don't love that it's a supervisor-only register, when the others could be done as user. Another option would be to use `CALLM`, which only exists on '020, with a type $00 module descriptor (to avoid any external state impact).

Closed 2022-01-20.

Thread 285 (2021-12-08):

HUGEROM should be default for example in release/version-2.0 and develop

roscopeco, 2021-12-08:
Now that Classic r2.0 is out, the examples should build for `HUGEROM` by default. Currently, this has to be specified manually on the build command-line.

* Fix in r2.0
* Merge back to develop
* Retain option to build for older boards (maybe SMALLROM option?)

Closed 2021-12-21.

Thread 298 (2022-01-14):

Xosera ANSI terminal broken in dev firmware

roscopeco, 2022-01-14:
In current 2.2.DEV firmware, Xosera ANSI terminal does not work. I suspect this is due to the switch to BCD for the firmware revision.

Specifically, from a quick investigation, it looks like the `str_dec` routine may not like that change.

Closed 2022-01-21.

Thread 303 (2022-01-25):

Warm boot doesn't re-initialise DUART after hardware reset

0xTJ, 2022-01-25:
Currently, the line https://github.com/rosco-m68k/rosco_m68k/blob/d2e599dbe13a67ec5b3cbc58612797911bdc1022/code/firmware/rosco_m68k_v2.1/main1.c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 has the warm boot handler iset to be used both at program exit and as hardware reset vector. This causes problems when using the system `/RESET` signal to reset the processor, because this also resets the DUART (and could reset any future added peripherals). The warm boot isn't made to re-setup the entire system, just to call the current program loader, so the warm boot message isn't printed, and Kermit doesn't work.

I'd propose that the hardware reset vector use a separate routine that's one step "colder" than the current warm boot.

It might also be worth considering splitting out some of the code in `bootstrap.asm` into separate files to make things a little more modular, but that's a separate issue.

roscopeco, 2022-01-25:
Interesting. This makes sense that it should be a problem, but I don't see it in (e.g. `updateflash` which uses the `reset` instruction and AIUI _should_ trigger this issue, but doesn't, at least on my system) 🤔

Is there a test we can run which exhibits this behaviour?

(And yeah, I agree on `bootstrap.asm`. Breaking it up a bit has been on my list for quite a while now...)

roscopeco, 2022-01-25:
Having drunk plenty of coffee and thought more about this, I think it's good as currently implemented. I kind of feel like, if a piece of code is going to run a `reset` instruction (which it's worth noting doesn't actually reset the processor), then it's not really doing a warm reboot, and has no business expecting to be able to jump to the warm boot vector, as it has deliberately reset all the peripherals.

I think where `reset` is used, it's a reasonable requirement that the next thing the software (or firmware, I'm not against adding a trap for this) does is load the stack and initial PC from the ROM base and jumps there for a "cold" reboot.

What do you think?

roscopeco, 2022-01-25:
Ah right, okay, I can see your use-case now.

I'm not _against_ the above in principle (but I do want to think it through more and digest it somewhat), and you're right that it's not technically supported with the current expansion bus (though likely just yanking `/RESET` will "work fine" with any 68010 you care to try it with). If you have chance to work something up I'd gladly look at it 😃

FWIW I _do_ think we can achieve broadly what you need with a change in the glue logic. Specifically, if you replace IC5 with:

```
GAL22V10
GLUE

AS   IOSEL   HWRST  FC2    FC1     FC0   A1    A2    A3     A19      NC     GND
NC   NC      HALT   RESET  RUNLED  BQ0   BQ1   BQ2   BOOT   ANYIACK  DUIACK VCC

HALT.T  =  GND
HALT.E  =  HWRST

RESET.T =  GND
RESET.E =  HWRST

RUNLED  = /HALT

AR      = /RESET
BQ0.R   =  RESET                ; High after one memory cycle
BQ1.R   =  RESET * BQ0          ; High after two memory cycles
BQ2.R   =  RESET * BQ1          ; High after three memory cycles
BOOT.R  =  RESET * BQ2          ; High after four memory cycles

/ANYIACK=  RESET * FC0 * FC1 * FC2 * A19
/DUIACK =  RESET * FC0 * FC1 * FC2 * /AS * /A1 * /A2 * A3 * A19

DESCRIPTION

Modified IC5 for #303 test purposes
```

I _think_ that'll work, and should still be safe for the software reset case, but I'll admit I've not thought it through in depth or done any testing with it.

roscopeco, 2022-01-25:
(And actually, thinking a bit more about it, whether we change the firmware in support of this or not, we might want to think about using some slightly more robust version of the above for IC5 if we want to support hardware-reset-other-than-by-the-button. Off the top of my head we could use a spare pin to feedback a combination of `/HALT` and `/RESET` and use that to reset the `/BOOT` line maybe 🤔 ).

0xTJ, 2022-01-27:
Hmm, I'm not sure if that would work properly, since the processor can still do a system reset via `/RESET`, but continue executing. I imagine if would mess with things up if `/BOOT` got asserted at a time other than power-up reset.

I'm not sure how it'd be possible to differentiate an external `/RESET`-only reset from a `reset` instruction.

roscopeco, 2022-01-27:
Yeah, for the latter comment I'm thinking we should probably feed back `/RESET` and `/HALT` and reset `/BOOT` only if _both_ go low (i.e. a 'proper' hardware reset) rather than doing with the `HWRST` line as currently (it would be broadly the same thing, except it would support external reset). This would be more for completeness than anything else (as you say, it's not currently easy to do, as `/HALT` isn't broken out to the expansion bus).

(WRT the former comment, I just did a quick test, and the board continues to work with that change, which suggests there's likely more to it than met the eye when I came up with it - as you say, it really shouldn't work 🤔 I don't have time to get the LA on it right now, but it wasn't really a suggestion of "something we should do" anyway 😅 ).

0xTJ, 2022-01-28:
Ah, I see what you're saying, that makes sense and should be easy.

I'll make undo some of the changes to my prototype branch given that all external resets will be resets with to ROM with `/BOOT`, and I'll be making  PR since that makes it easier to what's changed. Though, with that PLD change, some of that I've said before wouldn't apply, so it's going to turn more into a `bootstrap.asm` refactor, and making things a little more modular with initialization.

The main part of what I said before that's more of a design decision to make is whether or not the reset vectors are still replaced with values for warm boot, since those wouldn't be "naturally" reachable anyways if all processor resets go to ROM. (I changed those to stay as a mostly-cold reset.)

Closed 2022-02-02.

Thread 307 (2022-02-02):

HALT should be broken out to a pin somewhere

roscopeco, 2022-02-02:
As detailed in https://github.com/rosco-m68k/rosco_m68k/pull/306#issue-1117449775 , it is currently not possible to hard reset the system other than with the on-board button, as `/HALT` is not broken out to a pin anywhere. Raising this to fix that on a future board spin.

roscopeco, 2023-08-17:
PR #352

Closed 2023-08-29.

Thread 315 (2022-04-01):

Memcheck hangs at start of roscram_68k expansion ram board memory mapped space on rev 2.12 board

DrItanium, 2022-04-01:
Observed with a rosco_m68k board revision 2.12 with firmware 2.16 and a roscram_68k board.

Regardless of the amount of ram installed in the expansion memory board and jumper configuration (except one) the instant memcheck hits the start of the mapped ram location it just stops with no error. Here is what I see:

```
***********************************************************
*                                                         *
*          rosco_m68k SysInfo & MemCheck utility          *
*        MC68010 CPU with Firmware 2.16 [RELEASE ]        *
* Firmware reports  1048576 bytes total contiguous memory *
*                                                         *
***********************************************************

Building memory map, please wait this may take a while...

Scanning for RAM: 1024K/14336K

```

When I change the jumpers on the memory board the 1024k is replaced with the base address or (start of installed memory).

If I disconnect the memory board or short all jumpers on the ram board then execution is successful because the memory board is being bypassed. With the exception of jumper pattern 0b111, the program will stop the instant it hits the mapped memory space. I even tried installing different memory configurations (even ones which aren't supported). For simplicity I'll give it as a four bit code where each bit represents a 1 megabyte even odd ram pair with the right most bit being base + $fffff and the left most bit being base + $300'000 pair. A zero means no installed and a one means installed.

0b1111 -> hangs at memory start
0b0111 -> hangs at memory start
0b0011 -> hangs at memory start
0b0001 -> hangs at memory start
0b1110 -> hangs at base + $100'000
0b1100 -> hangs at base + $200'000
0b1000 -> hangs at base + $300'000
0b0000 -> no hang... but no memory installed.

I didn't try all combinations. I got the same result if JP4 is shorted or not as well.

I also did an indepth inspection of mem board as well looking for solder bridges and found none.
I am using Alliance AS6C4008-55PCN SRAM chips as well.

If I power it from an external 5v source or the FTDI cable the result is the same (obviously not at the same time).

There is something I'm obviously doing wrong but not sure what it is.

mifritscher, 2022-04-01:
I've the same problem. It seems to be a problem with memcheck, as e.g. peek&poke from ehbasic worked fine.

DrItanium, 2022-04-01:
I'm glad I'm not the only one. So what command did you run in ehbasic to test that (I don't know basic at all...)? I'd like to use it to validate that the memory expansion is working.

mifritscher, 2022-04-01:
Uh, I just used PRINT, PEEK and POKE from https://philpem.me.uk/leeedavison/68k/ehbasic/language.html.

something like
```
A = $<Address in HEX>
PRINT PEEK(A)
POKE (A,200)
PRINT PEEK(A)
```

should do.

DrItanium, 2022-04-01:
Thank you :D

For reference it is

```
A = $<Address in HEX>
PRINT PEEK(A)
POKE A,200
PRINT PEEK(A)
```

Which worked for me. And the memory expansion board is working.

DrItanium, 2022-04-01:
I'm going to close this issue and open an new issue with a more descriptive title

Closed 2022-04-01.

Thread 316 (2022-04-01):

Memcheck hangs if memory expansion board is connected to a v2 based rosco_m68k board

DrItanium, 2022-04-01:
Running the memcheck example will hang during RAM scan if the memory expansion board is connected to the v2 classic board.

The hang happens once the program hits the memory mapped area. It will not fail if the jumpers of the memory board are set to 0b111, no memory is installed in the expansion board board, or the board is not connected.

I observed this on a 2.10 classic running firmware 2.16.

0xTJ, 2022-04-02:
I've replicated this on my board, with firmware 2.20.

0xTJ, 2022-04-02:
Huh, I think I've found the problem, it doesn't look like the code will advance the `current` pointer at all if the data was successfully read back. It will always loop forever as soon as it encounters valid expansion RAM. I should have a PR up shortly to fix this.

Closed 2022-04-04.

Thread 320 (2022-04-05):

Firmware 2.2 non-functional with r1.23 mainboards

roscopeco, 2022-04-05:
When the 2.2 firmware is built for revision 1.x boards, it appears that it doesn't correctly set up MFP interrupts, so the tick never happens and the board hangs waiting for the CPU speed loop.

Specifically, when built with:

```
BIGROM=true REVISION1X=true make clean burn
```

The firmware hangs after printing the banner, before printing the CPU speed. If building with `NO_TICK`:

```
BIGROM=true REVISION1X=true NO_TICK=true make clean burn
```

then the firmware functions correctly (but does not display CPU speed or operate the tick, of course).

I have verified that both Firmware 2.0 and Firmware 2.1 function correctly on revision 1.23 boards when build with `BIGROM=true REVISION1X=true` which leads me to believe the issue is somewhere in this changeset: https://github.com/rosco-m68k/rosco_m68k/compare/v2.1...v2.2

Closed 2022-04-06.

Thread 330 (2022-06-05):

Cannot produce pcb from gerbers

GBeushausen, 2022-06-05:
I try to get the PCB manufactured (R2). But the silkscreen is missing. If i export it myself with KiCad (don't know what i'm doing), the manufacturer says there are errors and cannot manufacture it. How can i get a working version of the PCB?

Also the manufacturer asks if this is a 2 layer or a 4 layer board. I don't know. Where can i find this information? Since this is not available on Tindie anymore, could you provide more information on how to get this manufactured? I'm a software guy, i don't have the slightest clue about hardware.

roscopeco, 2022-06-05:
Interesting. All the Gerbers for r2 are here: https://github.com/rosco-m68k/rosco_m68k/tree/develop/design/r2/CAMOutputs

The silkscreen for front and back are contained in the `rosco_m68k-F_SilkS.gbr` and `rosco_m68k-B_SilkS.gbr` files respectively.

The board is four-layer, and the layer stack up for copper is:

* `rosco_m68k-Top.gbr` (Top)
* `rosco_m68k-Route2.gbr`
* `rosco_m68k-Route15.gbr`
* `rosco_m68k-Bottom.gbr` (Bottom)

The drill files can be found alongside the gerbers (`rosco_m68k-PTH.drl` and `rosco_m68k-NPTH.drl`).

For most fabs, it should be enough to simply zip all the files in the `CAMOutputs` directory and send that zip file. Some fabs will require you to assign a layer stack-up (which is as listed above).

Which manufacturer are you using? What are the specific errors they are complaining about?

GBeushausen, 2022-06-05:
Thanks for your help. I didn't used the develop branch. I used the Release2 branch and there, the silk screen was missing. With this branch i didn't get any errors, other than it was submitted as a 2 layer board and it seems to be a 4 layer board. I'm, using PCBWay.

roscopeco, 2022-06-05:
No probs. You had me slightly worried, but I just had a look through the release branches and the silkscreen appears to be there in all of them. The `release/version-2.0` branch is somewhat out of date though, if you were using a release branch it's always best to use the latest for board designs (so `release/version-2.2` in this case).

However, it's also fine to use `develop` in this instance as the board hasn't changed since the last release, glad to hear it worked for you 👍

Okay, no worries, this should be fine for PCBWay :)

Closed 2022-06-05.

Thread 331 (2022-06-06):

Some manufacturing questions

GBeushausen, 2022-06-06:
I'm trying to produce the boards with PCBWay. They have two questions, which i don't know what it means.

1. For 4 layer board, we will make both inner and outer copper thickness 1/1oz, is it ok?
2. You noted RoHS in the file, but selected HASL with lead surface treatment cannot fit, pls advise.

What should i choose? Can i choose HASL?

roscopeco, 2022-06-06:
1. Yes that will be fine.
2. If the boards are for yourself and you don’t mind lead, you can go with Leaded HASL if you like. If you want to be kinder to the environment you can choose lead-free HASL. They are only asking because the leaded HASL is not RoHS compliant.

roscopeco, 2022-07-31:
I'm going to assume this answered your questions. Closing.

Closed 2022-07-31.

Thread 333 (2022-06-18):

Proposed board alterations: Breakout EXPSEL in J6 and add optional DIP16 oscillator footprint

HeathenUK, 2022-06-18:
As requested, just jotting down two thoughts on potential improvements:

- At the moment EXPSEL is only broken out via J3, where adding it to J6 would make it possible to create expansion RAM hat PCBs that don't require IC2 to be customised where one doesn't want to use the J3 connector (for example, if you explicitly only want to use it for Xosera and don't want a backplane).
- For whatever reason DIP8 oscillators are getting rarer while DIP14 are still freely available. It looks like there's sufficient board space to add optional DIP14-compatible pins (similar to the way we accommodate either size of cap for the DUART crystal.

roscopeco, 2023-08-17:
Thanks for this @HeathenUK , and apologies for the delay in getting to it. I have raised a PR that will address `EXPSEL` (adding it to `J6` as you suggest). On this board revision I have decided not to do the `Q2` resize / additional pins, but will keep it in mind for a future bigger respin / the next version :)

Closed 2023-08-29.

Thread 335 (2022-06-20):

CS0/CS1 (and potentially other GPO/GPI lines) clobbered by UART code

HeathenUK, 2022-06-20:
In looking to re-use the SPI routines in the firmware for a non-SD device I've had issues with what _appear_ to be the output lines (possible the input lines too?) from the DUART being yanked around unexpectedly during or between transactions.

Of course it's no problem to minimise issues in a single two-byte transaction by deasserting and re-asserting CS, but this issue does also seem to be preventing auto-incrementing/streaming transactions where you wouldn't normally deassert the CS pin until you're done (or I wouldn't, perhaps I'm operating against spec).

@roscopeco had suggested this might be an artefact of older "POST" style code and the firmware setting the whole of the output pins in one go including those not sinking an LED. I'm surprised that hasn't caused any issues with SD transactions!

G

0xTJ, 2023-09-29:
Do you know if this is still a problem? Since this issue was made I've had a few looks at where this could happen, and haven't found anything.

Since the DUART uses separate registers for setting and clearing, only the output pins that have bits set in those writes will be affected. As far as I can find (at least in the current `develop`), the operations on those pins in the firmware seem to only target the needed pins (the heartbeat only uses `$20`, SPI creates bit masks in registers).

I'm also unsure about what could yank around the input lines, since those are only connected to either the UART or the SPI ports, and are output-only from the DUART.

roscopeco, 2024-04-07:
Closing this as superseded, if it is still a problem we can reopen / reraise 🙂

Closed 2024-04-07.

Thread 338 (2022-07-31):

BOM - What to buy?

GBeushausen, 2022-07-31:
I have got some boards produced for me. Now i want to build them, but i don't know what components exactly i have to buy.

Like in the BOM it says:
4;"C7,C24,C13,C31,C12,C10,C32,C30,C29,C28,C9,C8,C3,C4,C5,C6,C27,C26,C25,C23,C22,C20";"C2.5-3";22;"100nF";;;
What does this mean? 100nf of what? Where to buy this?

Or this:
5;"R18,R17,R16,R15,R12,R8,R10,R32,R31,R9,R3,R7";"0207_10";12;"4K7";;;

What type of resistor is this?

Or this chip:
15;"IC6,IC2,IC5,IC3";"DIP-24_W7.62mm_Socket_LongPads";4;"ATF22V10C";;;

There are many subtypes of this chip, like 15pu, 20pu, 7px some say 10 macrocells, some 500 slpd. How do i know exactly which chip i need to buy?

roscopeco, 2022-07-31:
The resistors are all standard 0.25W axial through-hole resistors.

For the capacitors, `C2.5-3` are standard 2.5mm lead pitch radial non-polarised caps with the capacitance specified in the BOM (e.g. 100nF, 7pF, etc). I recommend MLCC. `E2,5-5` is a standard radial electrolytic polarised cap with 2.5mm lead pitch and the specified capacitance. `E3,5-10` (for the 470uF) is a standard radial electrolytic polarised cap with 3.5mm lead pitch. In other words, the letter (`C` or `E`) specifies whether this a ceramic or electrolytic cap, while the number immediately following specifies lead pitch and package size. All are through-hole.

For the ATF22V10C, I do not mandate a specific type as it depends to an extent what your programmer can handle. The board is tested with ATF22V10C-10PU , and ATF22V10C-7PX is known to work also.

roscopeco, 2022-08-06:
Again (https://github.com/rosco-m68k/rosco_m68k/issues/331), closing this as I assume it fixed your issue, though I can't really tell given no further feedback from yourself. I cannot begin to tell you how fulfilling I find your demands and our one-sided interactions, and how much I look forward to there being no more of them.

GBeushausen, 2022-08-06:
@roscopeco I'm really thankful for your help. You just immediatly closed the issue after replying to me and i was not sure if i could still reply after you closed the issue.

roscopeco, 2022-08-06:
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

Closed 2022-08-06.

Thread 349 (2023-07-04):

Error array subscript @ is outside array bounds

Berzerkula, 2023-07-04:
https://github.com/rosco-m68k/rosco_m68k/blob/a42a2f78be5507def89f6c46d2ec49db9581c695/code/software/libs/src/printf/include/printf.h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

I am using latest gcc and binutils for the m68k toolchain. Used -Wno-array-bounds  for the follwing (software builds fine with the option):

m68k-elf-gcc -c -std=c11 -ffreestanding -ffunction-sections -fdata-sections -fomit-frame-pointer -Wall -Wextra -Werror -Wno-unused-function -pedantic -I../../../code/software/libs/build/include -mcpu=68010 -march=68010 -mtune=68010 -g -O2 -DROSCO_M68K  -o memcheck.o memcheck.c
In file included from ../../../code/software/libs/build/include/stdio.h:20,
                 from memcheck.c:16:
In function 'show_banner',
    inlined from 'main' at memcheck.c:400:3:
../../../code/software/libs/build/include/printf.h:59:16: error: array subscript 0 is outside array bounds of 'uint32_t[0]' {aka 'long unsigned int[]'} [-Werror=array-bounds=]
   59 | #define printf printf_
memcheck.c:346:5: note: in expansion of macro 'printf'
  346 |     printf("* Firmware reports %8ld bytes total contiguous memory *\n", *FW_MEMSIZE);
      |     ^~~~~~
In function 'main':
cc1: note: source object is likely at address zero
cc1: all warnings being treated as errors
make[1]: *** [../../../code/software/software.mk:109: memcheck.o] Error 1
make[1]: Leaving directory '/home/kb0iic/repos/rosco_m68k/code/software/memcheck'
make: *** [Makefile:31: memcheck] Error 2

0xTJ, 2023-07-05:
Is this an issue when building the current version in the `develop` branch? This issue, and the one in #348, *should* have already been fixed when we added GCC 13 support.

Berzerkula, 2023-07-05:
I do remember this involved a bit back, I'm seeing it in GCC 14 (using git for GCC and Binutils)  I did a make clean, git -fxd (really cleans it) and did a pull, and all is fine. Unsure how I saw it earlier. It is clear. I'll close this issue.

Closed 2023-07-05.

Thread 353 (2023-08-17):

Add optional larger osc footprint for Q2

roscopeco, 2023-08-17:
(Raising off the back of #333 which was originally raised by HeathenUK)

In the same way as we support dual sizes for UART capacitors, we should support both DIP8 and DIP16 oscillator cans for Q2.

Not done on classic v2 boards due to lots of moving around but should definitely keep in mind for future version(s) (hence this ticket).

roscopeco, 2024-04-07:
Closing won't do, limited utility currently.

Closed 2024-04-07.

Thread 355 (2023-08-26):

Github Action for PR needs to run if **source** branch is a forked develop

roscopeco, 2023-08-26:
Currently, the build action on PR only runs if the branch is not `develop`, which is as intended (we want to have a separate build for `develop` that doesn't upload artifacts but instead creates a snapshot release).

However, the case where the _source_ branch of a PR is a `develop` in a forked repository also prevents the action running.

So, we need to find a way to make the action be ignore if the **target** (and only the target) branch is `develop` in this repo.

Closed 2023-08-29.

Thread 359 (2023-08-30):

RN1 value in 68020 BOM should be 4k7

roscopeco, 2023-08-30:
10k is probably fine (and will save on BOM cost) so it’s probably worth doing some actual tests (it only really affects interrupt lines on the expansion connector, plus cache inhibit and a few other CPU lines have a stronger pull-up).

However the actual designed value is 4k7 so should either test and rerate to 10k in the design, or fix the BOM to be 4k7.

Closed 2023-10-31.

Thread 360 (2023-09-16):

QUESTION: Is there anything special about IC3 (ATF22V10C) that you get in the kit?

blackdwarf, 2023-09-16:
I managed to boot up the computer (yay!) but I noticed that IC3, IC5, IC6, and the CPU get warm. I reseated the first 3 and tried to power it on again and no luck. Looking around what happened, I noticed that I managed to turn IC3 the wrong way. Curse my poor eyesight and poor lighting!

Anyways, DigiKey has these in stock, so wanted to buy a couple, but just wanted to check is there anything special I need to do with the replacement programming-wise? Or can I just plop in a new one (this time double checking if it is oriented right)?

Thanks!

roscopeco, 2023-09-16:
Hello!

Sorry to hear about this, but glad you've been able to get replacements.

The ATF22V10Cs are programmable logic devices, and will need to be programmed before use. You can find the JEDEC file you'll need to program IC3 here: https://raw.githubusercontent.com/rosco-m68k/rosco_m68k/develop/code/pld/r2/duartsel/ic3_duart_sel.jed

We recommend the TL866II+ programmer and the Minipro software - if you have those then you can also find a handy script to compile and burn the code for this chip in this directory: https://github.com/rosco-m68k/rosco_m68k/tree/develop/code/pld/r2/duartsel

If you don't have a programmer, please feel free to open a support case on Tindie - use either the "Contact Store" button on the main store page ( https://www.tindie.com/stores/rosco/ ) or there should be a similar button on your order details page to directly raise a question.

Thanks,
Ross

blackdwarf, 2023-09-16:
Thanks for the quick response, really appreciate it!

I do have a programmer, but it is a T48, which seems like it [doesn't work](https://gitlab.com/DavidGriffith/minipro/-/issues/270) with minipro. However, I will probably be able to just flash the PLD from the Windows software?

roscopeco, 2023-09-16:
No worries 🙂 Ah right, yeah, that's the reason I've still not gotten a T48 yet 😅

I would think you should be able to flash the PLD fine from the Windows software using the JED file I linked above.

Please do update here if you have any issues with it 🙂

blackdwarf, 2023-09-18:
An update here (for posterity and other people who may be butter fingered like I was), and yet another question.

So, based on our discussion above, I took a chance and read IC3 in my T48. That worked, but the contents were definitely different than the JED file you linked. I blanked it, then wrote the JED file from the repo. It...worked! I can boot the board! I also compiled the BASIC from the repo, transferred it there and ran some code that worked.

However, the CPU and the IC3, IC5, and IC6 do get warm. Is this normal? Or do I have another issue I need to look at? I am powering it off of an ordinary USB port.

roscopeco, 2023-09-19:
Awesome, thanks for the update, and glad to hear you’re up and running!

It’s totally normal for those chips to get warm when the system is running 🙂

blackdwarf, 2023-09-19:
Great! Then I'm good to go and try me some 68k stuff. Never had one when I was a kid. 😄

roscopeco, 2023-09-19:
Have fun! 🥳

Closed 2023-09-19.

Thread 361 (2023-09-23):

Updateflash should mention JP3

roscopeco, 2023-09-23:
The error message from updateflash correctly states when it cannot identify the ROM chips.

however, this is the case when the write protect jumper is open (a write is needed to put the chips in command mode). So if users have that jumper open and try to flash the chips, they’ll be told they have the wrong ROMs when they don’t.

the UX would be much improved if the error message mentioned the jumper 🙂

Closed 2023-09-29.

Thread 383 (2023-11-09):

Switch UART TX/RX silkscreen around

rossbamford-xdesign, 2023-11-09:
RX/TX markings on the board current reflect what should be plugged in there, rather than the pin function.

This is confusing people, so swap it back.

roscopeco, 2024-01-14:
Done for 030 board, other boards to follow

roscopeco, 2024-03-16:
Done for all boards in March 2024 refresh.

Closed 2024-03-16.

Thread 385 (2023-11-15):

Null-terminated print traps should leave A1 pointing to the terminator

roscopeco, 2023-11-15:
In the interface reference docs, we state that the print traps leave A1 pointing to the null terminator.

This no longer appears to be the case, we save and restore that register in the trap code.

since this behaviour is useful, we should put it back as it was.

0xTJ, 2023-12-13:
Is there a one of the implementation that's known not to do as it's documented? I've checked most of the functions printing functions and those seemed to match what's documented.

`TRAP #14` uses `A0` while `TRAP #13` uses `A1`, so I could see if there was some confusion where the main system print traps save and restore `A1`. I might however have also just missed a spot where the behaviour is wrong.

roscopeco, 2024-04-07:
Closing this as superseded. If still an issue we can reopen or reraise 🙂

Closed 2024-04-07.

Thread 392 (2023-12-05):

Software GPIO Directly Uses MFP

0xTJ, 2023-12-05:
Currently, the GPIO software library is fixed to use the MFP both for Arduino-like GPIO and for SPI. This library should be fixed to be more flexible and/or call into the firmware TRAPs.

Closed 2024-04-07.

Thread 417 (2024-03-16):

Debug trap handler gets incorrect values

roscopeco, 2024-03-16:
The debug trap handler is not fully compatible with 020 and 030 stack frames.

This causes (e.g.) fault address for bus error to be incorrect.

Check 🧐 and fix 🛠️

Closed 2024-04-07.

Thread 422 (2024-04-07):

`start_serial` incorrectly handles `EFP_PROG_EXIT` vector

roscopeco, 2024-04-07:
Briefly:

The way the init code in `start_serial` uses the `EFP_PROG_EXIT` vector to handle program exit is flawed in two ways:

* The original handler is stored in a program variable
* The code relies on `kmain` returning to restore the original handler

This is generally "fine" but breaks when user code does "weird things" like chaining to another user program (as is the case with `sdfat_menu`). In this case, the program variable is likely to be overwritten, and the original handler is likely to never be restored, leaving it as a dangling pointer to code that no longer exists when chained code (or anything run following warm boot) calls it.

Since user programs (like `sdfat_menu`) should be able to do this, this should be fixed in the libs. The obvious (and perhaps wrong) way to do this would be to make `exit`, `atexit` handlers and the init code itself work like it does in the new(lib) startup code: https://github.com/rosco-m68k/newlib-4.4.0.20231231/blob/062620702eccd78b1f19ea7f6d4a05bdbbfb0f14/libgloss/rosco/crt0.asm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

For full context, see this thread: https://discord.com/channels/698525682199822367/711035186170822727/1226460649673064449

Closed 2024-04-07.

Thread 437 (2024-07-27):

Audio stinger on boot

roscopeco, 2024-07-27:
Support audio stinger at boot.

I think we're going with 1s on 512KB ROM, and 2s full stinger on 1MB.

Probably should use polled audio rather than interrupts to begin with.

roscopeco, 2024-09-22:
Keeping this open due to poor quality audio, needs interrupts most likely.

roscopeco, 2024-12-18:
Closing, won’t do

Closed 2024-12-18.

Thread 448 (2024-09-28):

Keyboard reset code needs to be more resilient

roscopeco, 2024-09-28:
The keyboard init in the firmware needs to actively reset the keyboard. Currently it can get confused (and fail detection) if:

* The keyboard has been left in scan mode
* The keyboard has sent mouse packets that have not been completely processed

We should make sure we empty the buffers, send a bunch of NOPs, and then actively set ASCII mode and sensible defaults in the firmware init code.

Closed 2024-10-08.

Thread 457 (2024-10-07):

can't compile develop branch

der-schmelle2, 2024-10-07:
Hello,
this is my first ‘issue’ so please be nice to me and give me hints if I did something wrong.
I am running macOS 15.0.1.
I have installed the toolchain and am now trying to compile the firmware in develop Branch. Unfortunately this does not work. See attached file with the information received from the terminal output.
Procedure for reproduction:
```
brew tap rosco-m68k/toolchain
brew install gcc-cross-m68k@13 vasm-m68k srecord minipro
brew install zstd
git clone https://github.com/rosco-m68k/rosco_m68k.git
git submodule update --init --recursive
git checkout master
make clean all
make burn
```
**** IS WORKING FINE ****

`git checkout develop`
M code/firmware/rosco_m68k_firmware/romfs/micropython/core
M code/firmware/rosco_m68k_firmware/romfs/mklittlefs
Switched to branch ‘develop’
our branch is up to date with ‘origin/develop’.
`make clean all`
*** SEE attached screen output ***
[error_develop_branch.txt](https://github.com/user-attachments/files/17275054/error_develop_branch.txt)

Please help.
Thanks Peter

der-schmelle2, 2024-10-07:
Hello Ross,
Thank you very much for your message. I will carry out your suggested steps
tomorrow. I am really enthusiastic about your project. Thank you for that.

Best regards
Peter

Ross Bamford ***@***.***> schrieb am Mo. 7. Okt. 2024 um
21:12:

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

roscopeco, 2024-10-08:
Hmm, the error `m68k-elf-objcopy: No such file or directory` suggests the old toolchain wasn't found.

There's a [PR currently in flight](https://github.com/rosco-m68k/rosco_m68k/pull/454) to remove the dependency, but in the meantime you need to have both installed.

You mentioned initially that you'd already installed the old toolchain - did you uninstall it?

der-schmelle2, 2024-10-08:
No, I have not uninstalled anything. Would it make sense to uninstall and
reinstall both?

Ross Bamford ***@***.***> schrieb am Di. 8. Okt. 2024 um
21:45:

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

roscopeco, 2024-10-08:
No, there shouldn't be any need to do that. The easiest thing to do while we're waiting to get this PR merged would be:

```
git checkout feature/remove-bare-metal-toolchain-dependency
```

and then I'll update here as soon as we get the PR merged and you can switch back to `develop` :)

roscopeco, 2024-10-09:
Update: the PR to remove the old toolchain dependency is merged, you should be able to build develop now if you pull.

der-schmelle2, 2024-10-09:
It's working fine. Thanks

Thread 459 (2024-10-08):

Debug stub needs to wait for keypress

roscopeco, 2024-10-08:
With the new firmware, if not also connected to serial terminal it’s impossible to read debug stub info on crash, due to video being immediately reset on reboot.

debug stub should wait for keypress before continuing to allow debugging 🙂

Closed 2025-04-06.

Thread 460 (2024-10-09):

Regression: `mcCheckDevice`, `mcReadDevice` appear non-functional for UART B

roscopeco, 2024-10-09:
When code is linked against Newlib `librosco`, `mcCheckDevice` and `mcReadDevice` appear non-functional for UART B.

Requires further testing, as very possible it's not limited to those two routines and/or UART B.

0xTJ, 2024-12-24:
Is there a specific program that can be used to replicate this? I tried modifying a `newlib` example, and explicitly linked `librosco`, but can't replicate this. On a rosco_m68k Classic V2 rev 2.2 (with the FTDI trace to UART B cut, so using an external FTDI) `mcCheckDevice` still returns `true` when a character is available, and I can correctly read in that character with `mcReadDevice`.

roscopeco, 2024-12-24:
> Is there a specific program that can be used to replicate this? I tried modifying a `newlib` example, and explicitly linked `librosco`, but can't replicate this. On a rosco_m68k Classic V2 rev 2.2 (with the FTDI trace to UART B cut, so using an external FTDI) `mcCheckDevice` still returns `true` when a character is available, and I can correctly read in that character with `mcReadDevice`.

Thanks for looking at this @0xTJ !

I noted this down when testing other things and it’s very possible I had other “moving parts” in play at the time. If you’re not able to replicate then that puts my mind at rest, I’m happy to close this on that basis and if it shows up again we can revisit.

0xTJ, 2024-12-24:
Sounds good, closing for now! :)

Closed 2024-12-24.

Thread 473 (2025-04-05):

misspelling in blockdev mk file?

BoliShag, 2025-04-05:
On the last line of
code/firmware/rosco_m68k_firmware/stage1/blockdev/include.mk
it looks like CFLAGS is misspelled.

Berzerkula, 2025-04-06:
`blockdev/%.o: CLFAGS+=$(BD_EXTRA_CFLAGS)`

Yes, it is CLFAGS instead of CFLAGS

0xTJ, 2025-04-06:
Thanks for pointing out this typo. I've opened a PR to correct it.

Closed 2025-04-06.

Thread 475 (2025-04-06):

rtlsupport.h is probably not needed

BoliShag, 2025-04-06:
1. It has three prototypes, all of which are duplicated in string.h
2. The memcpy prototype has the src/dst args in the wrong order

Adding
```
#include <stdint.h>
typedef   uint32_t    size_t;
```
to string.h and replacing #includes of rtlsupport with string.h gets you most of the way to re-building successfully without rtlsupport.h.

0xTJ, 2025-04-07:
Are you looking at this code in the `develop` branch? I believe that the use of `rtlsupport.h` was removed some time ago from this repository.

BoliShag, 2025-04-07:
Why yes.
Yes I was. Thx.

Closed 2025-04-07.

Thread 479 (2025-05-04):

libm .mk causes spurious compile of printf.c

BoliShag, 2025-05-04:
The way libm/include.mk creates its LIBOBJECTS reincludes every *.c across all the libs:
```
SOURCES=$(shell find . -name "*.c")
LIBOBJECTS=$(SOURCES:%.c=%.o)
```

If you replace that with something like

```
LIBSOURCESALL=$(shell find . -name "*.c")
$(info === lib srcs  $(LIBSOURCESALL)  ===)

LIBMSOURCES0=$(filter   ./src/libm/%, $(LIBSOURCESALL))
$(info === libm srcs  $(LIBMSOURCES0)  ===)

LIBMSOURCES=$(subst   ./src/libm,src/libm,$(LIBMSOURCES0))
$(info === libm srcs  $(LIBMSOURCES)  ===)

LIBOBJECTS=$(LIBMSOURCES:%.c=%.o)
```

you'll see the all the .c's that would have been re-added to LIBOBJECTS with pathing like "./src/printf/printf.o"

That effectively causes something along the lines of:
```  gcc -o ./src/printf/printf.o ./src/printf/printf.c```
when printf.o is nowhere specified to be built by printf's include.mk

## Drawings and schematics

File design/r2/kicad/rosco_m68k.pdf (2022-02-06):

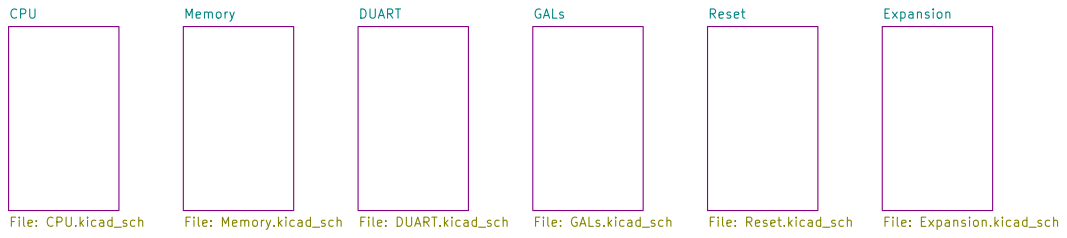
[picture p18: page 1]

Copyright 2019-2022 Ross Bamford and Contributors CPU

Open Source Hardware licenced under CERN Open Hardware Licence
See https://github.com/roscopeco/rosco_m68k/blob/master/LICENCE.hardware.txt
OSHWA UK000006 (https://certification.oshwa.org/uk000006.html)
File: rosco_m68k.kicad_sch Sheet: / The Really Old-School Company Limited

Id: 1/7 Title: ROSCO_M68K GENERAL PURPOSE MC68010 COMPUTER

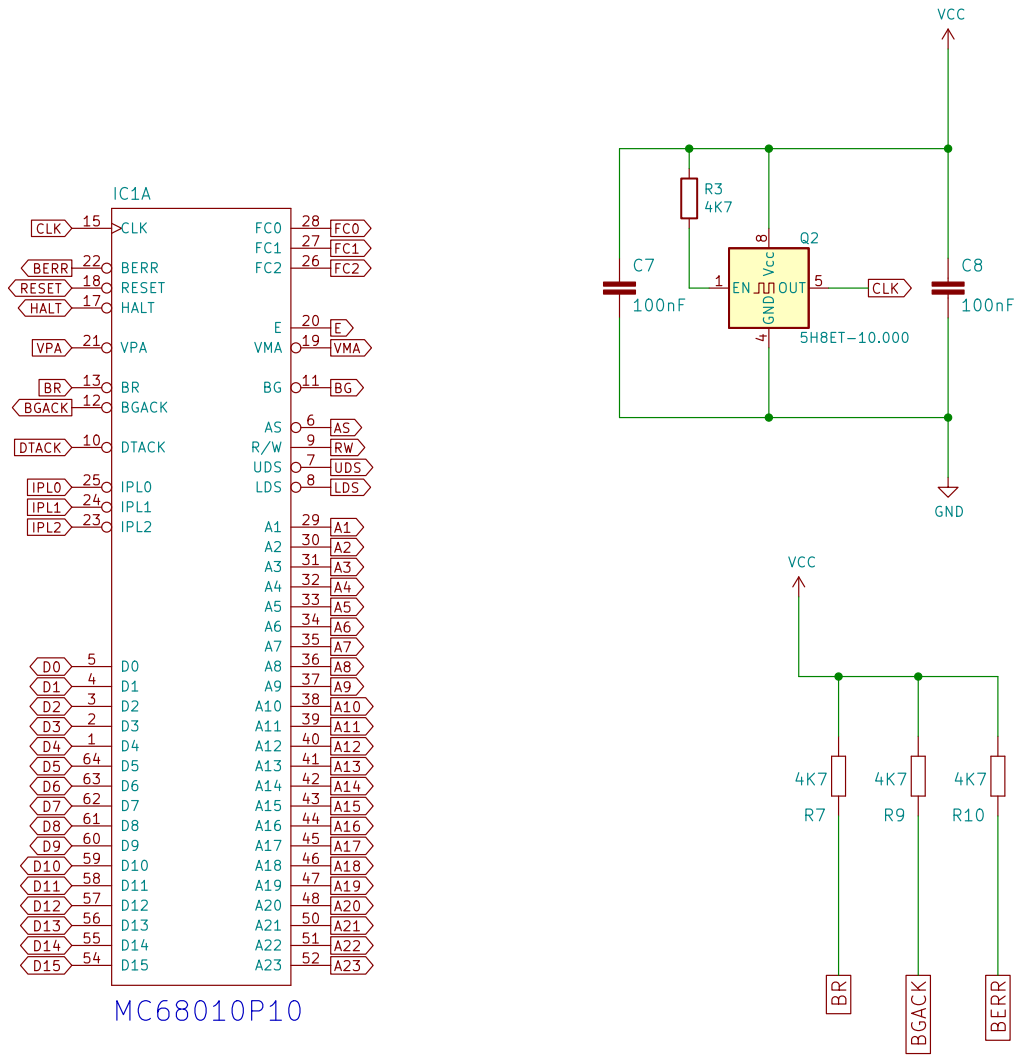
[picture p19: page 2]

Copyright 2019-2022 Ross Bamford and Contributors R10

Open Source Hardware licenced under CERN Open Hardware Licence
See https://github.com/roscopeco/rosco_m68k/blob/master/LICENCE.hardware.txt
OSHWA UK000006 (https://certification.oshwa.org/uk000006.html)
File: CPU.kicad_sch Sheet: /CPU/ The Really Old-School Company Limited

Id: 2/7 Title: ROSCO_M68K GENERAL PURPOSE MC68010 COMPUTER

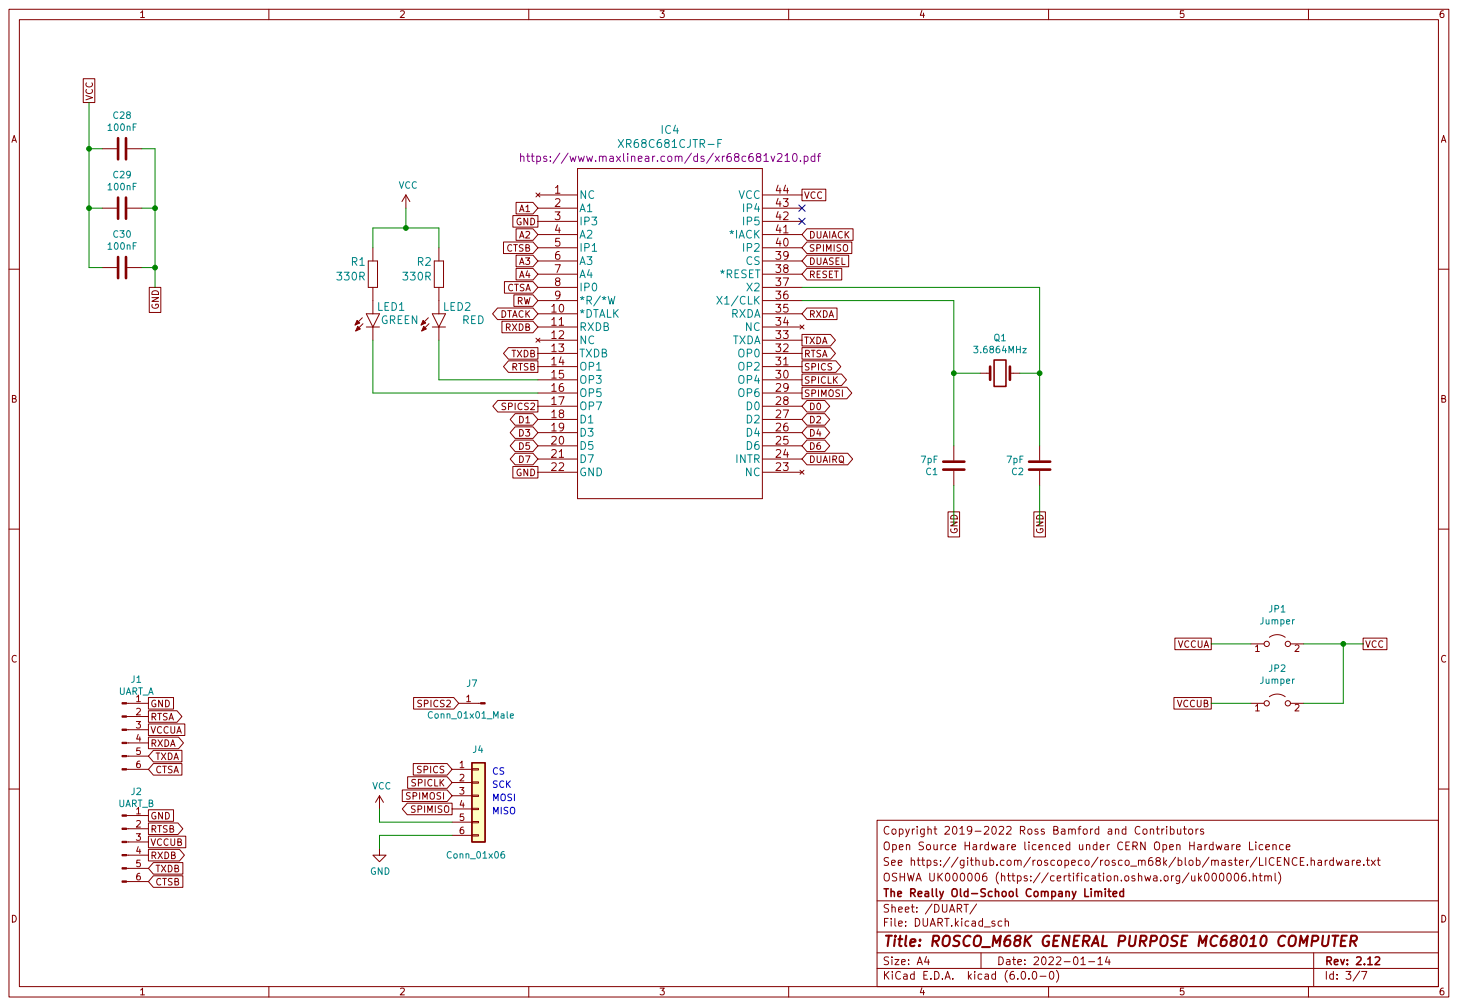
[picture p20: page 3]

Copyright 2019-2022 Ross Bamford and Contributors
Open Source Hardware licenced under CERN Open Hardware Licence
See https://github.com/roscopeco/rosco_m68k/blob/master/LICENCE.hardware.txt
OSHWA UK000006 (https://certification.oshwa.org/uk000006.html)
File: DUART.kicad_sch Sheet: /DUART/ The Really Old-School Company Limited

Id: 3/7 Title: ROSCO_M68K GENERAL PURPOSE MC68010 COMPUTER

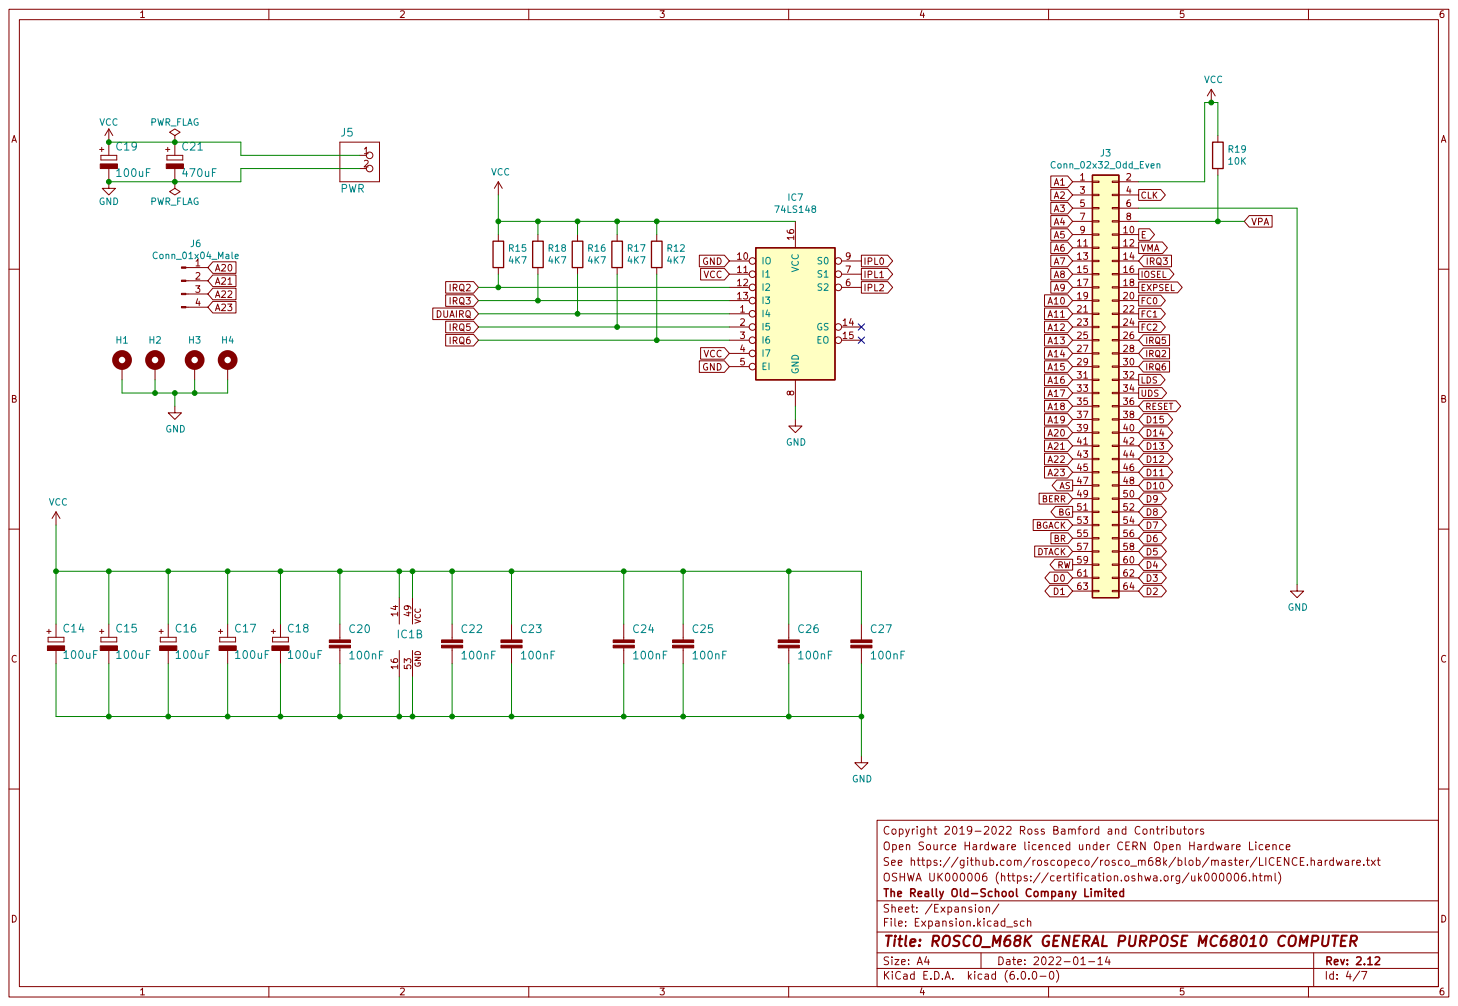
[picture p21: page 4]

Copyright 2019-2022 Ross Bamford and Contributors
Open Source Hardware licenced under CERN Open Hardware Licence
See https://github.com/roscopeco/rosco_m68k/blob/master/LICENCE.hardware.txt
OSHWA UK000006 (https://certification.oshwa.org/uk000006.html)
The Really Old-School Company Limited
Sheet: /Expansion/
File: Expansion.kicad_sch
Id: 4/7 Title: ROSCO_M68K GENERAL PURPOSE MC68010 COMPUTER

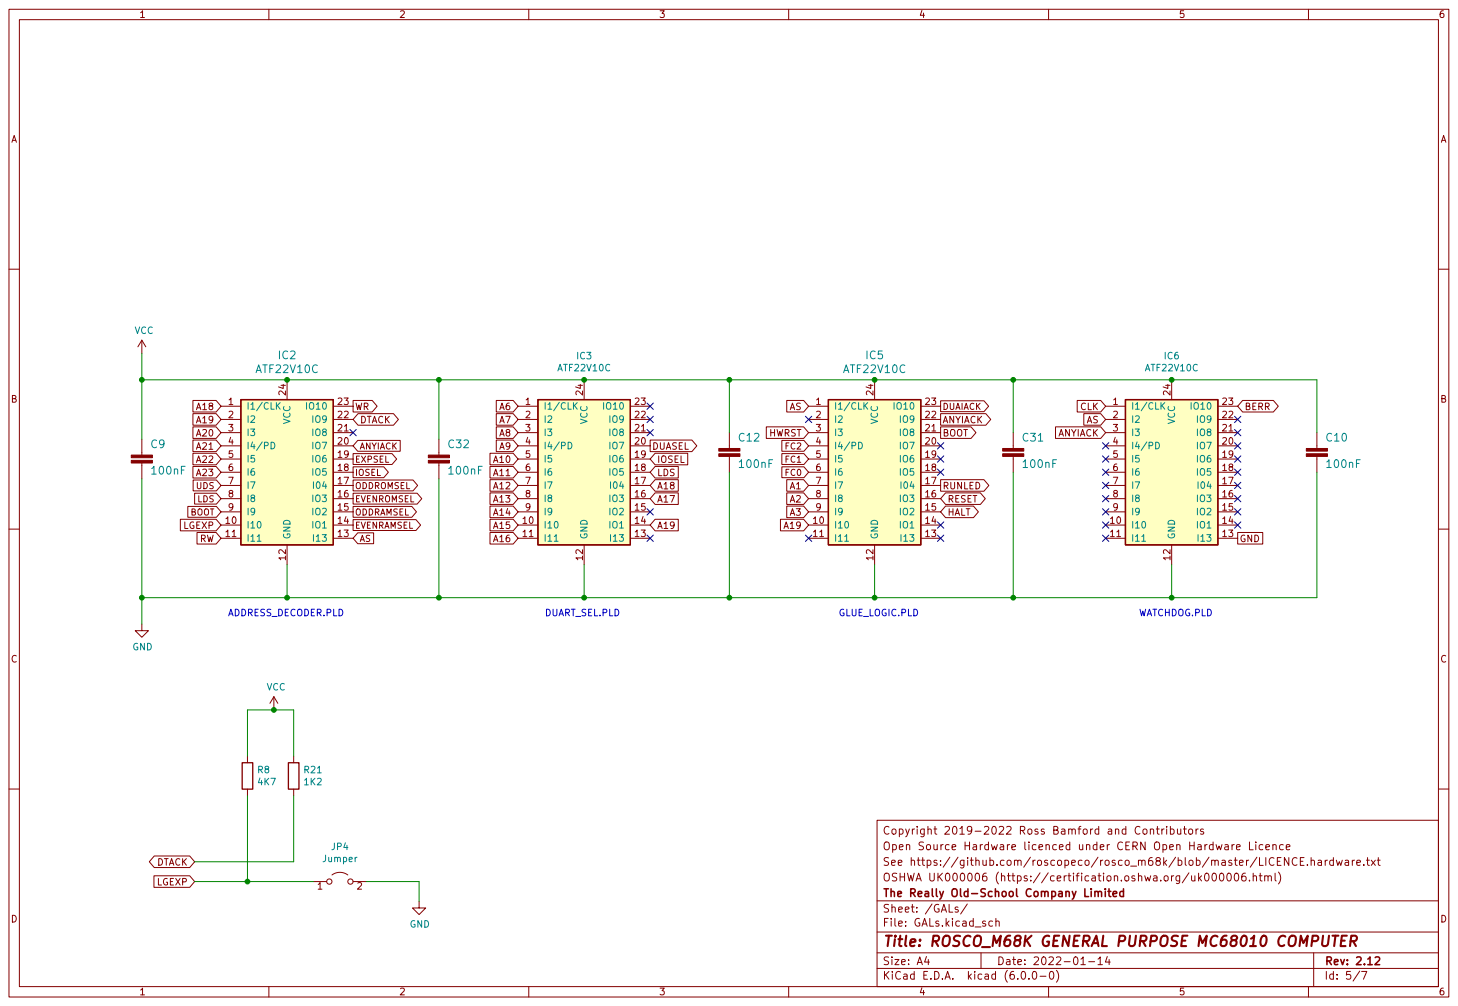
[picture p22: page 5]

Copyright 2019-2022 Ross Bamford and Contributors C12

Open Source Hardware licenced under CERN Open Hardware Licence
See https://github.com/roscopeco/rosco_m68k/blob/master/LICENCE.hardware.txt
OSHWA UK000006 (https://certification.oshwa.org/uk000006.html)
File: GALs.kicad_sch Sheet: /GALs/ The Really Old-School Company Limited

Id: 5/7 Title: ROSCO_M68K GENERAL PURPOSE MC68010 COMPUTER

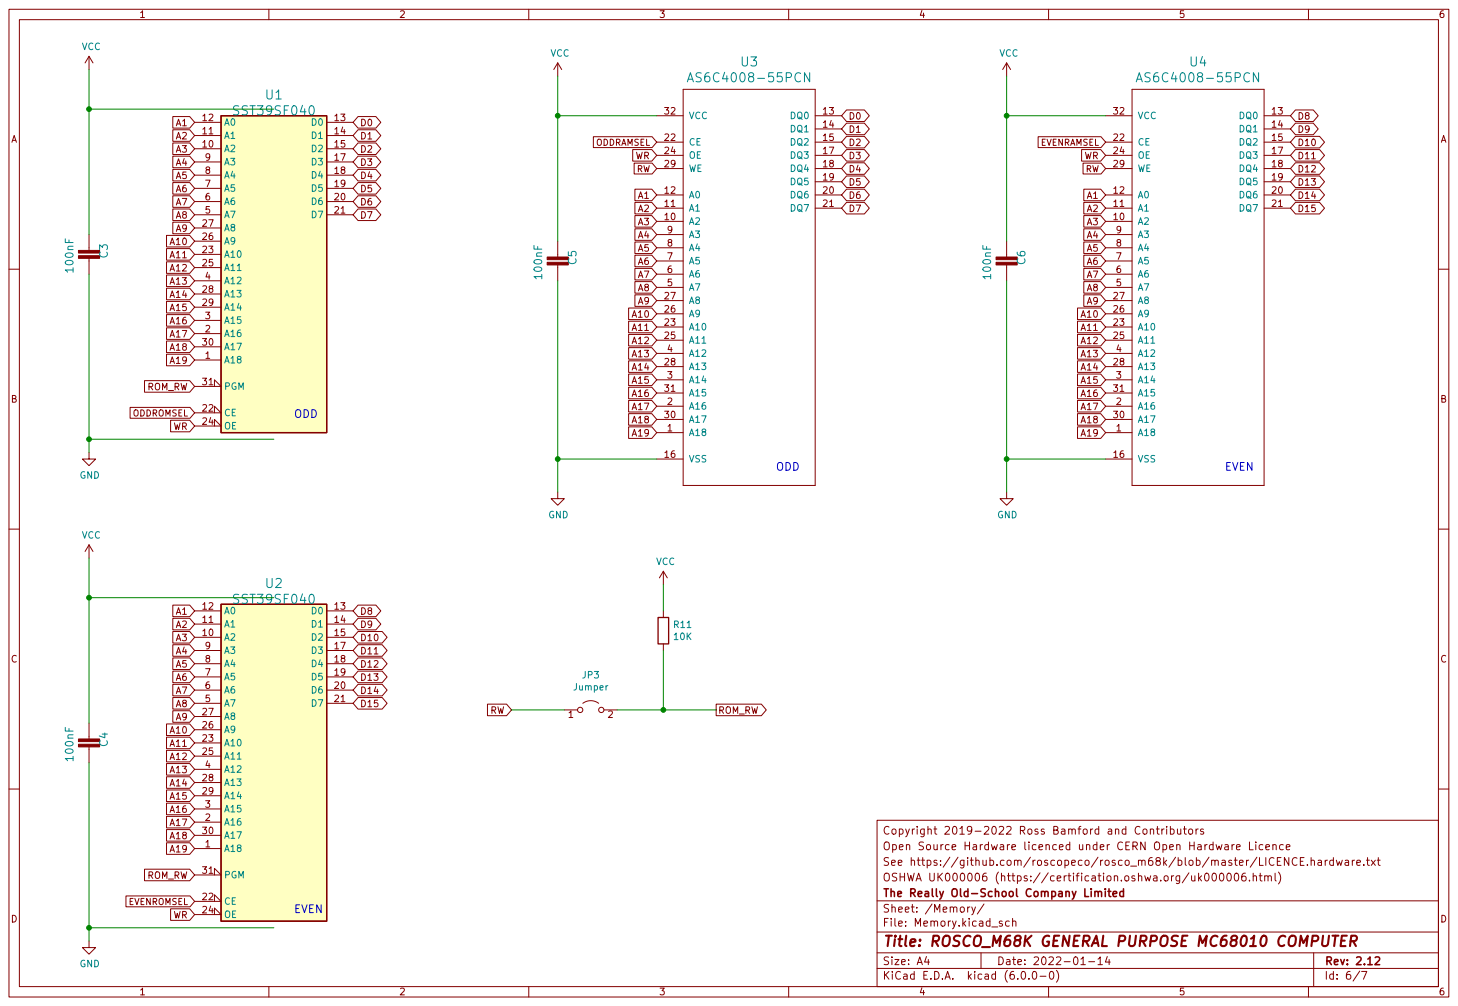
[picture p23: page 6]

Copyright 2019-2022 Ross Bamford and Contributors C5 100nF

Open Source Hardware licenced under CERN Open Hardware Licence
See https://github.com/roscopeco/rosco_m68k/blob/master/LICENCE.hardware.txt
OSHWA UK000006 (https://certification.oshwa.org/uk000006.html)
The Really Old-School Company Limited
Sheet: /Memory/
File: Memory.kicad_sch
Id: 6/7 Title: ROSCO_M68K GENERAL PURPOSE MC68010 COMPUTER

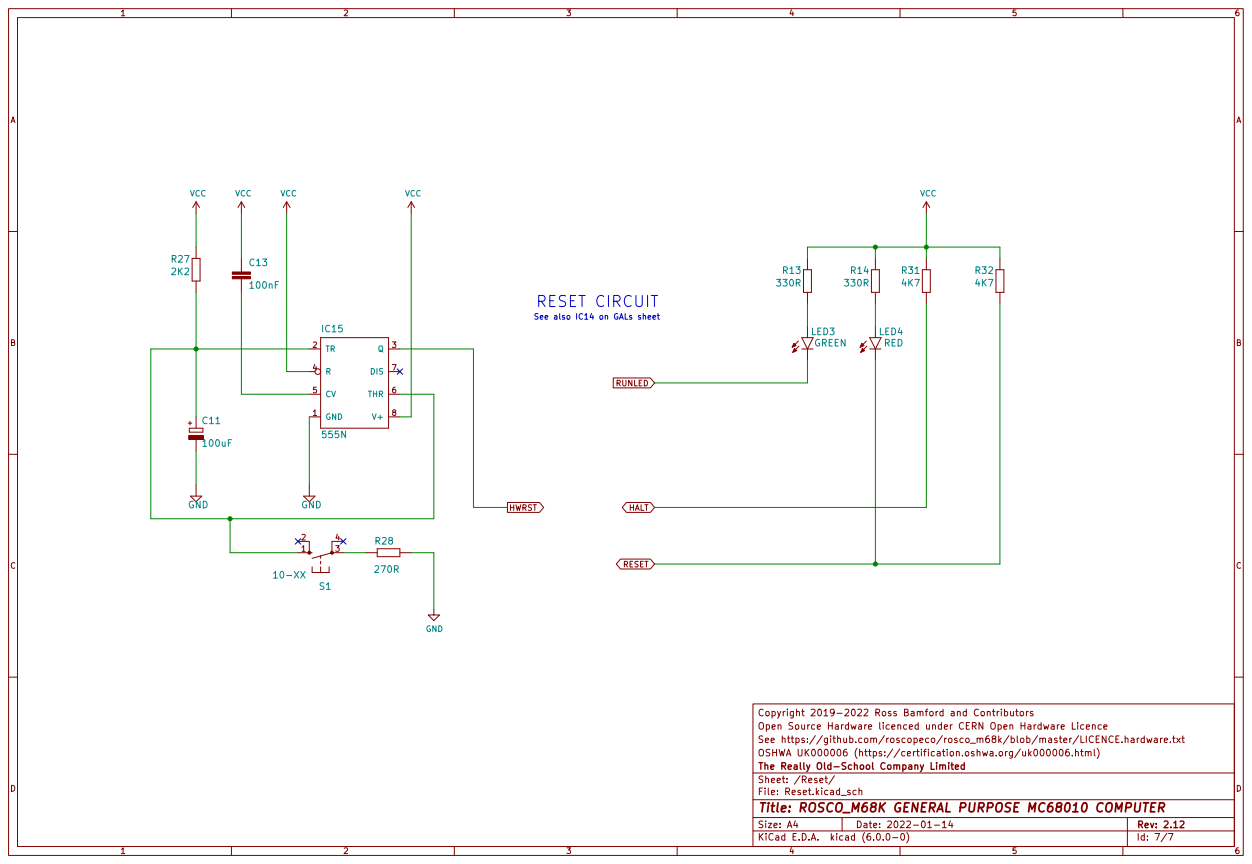
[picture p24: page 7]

Copyright 2019-2022 Ross Bamford and Contributors GND

Open Source Hardware licenced under CERN Open Hardware Licence
See https://github.com/roscopeco/rosco_m68k/blob/master/LICENCE.hardware.txt
OSHWA UK000006 (https://certification.oshwa.org/uk000006.html)
File: Reset.kicad_sch Sheet: /Reset/ The Really Old-School Company Limited

Id: 7/7 Title: ROSCO_M68K GENERAL PURPOSE MC68010 COMPUTER

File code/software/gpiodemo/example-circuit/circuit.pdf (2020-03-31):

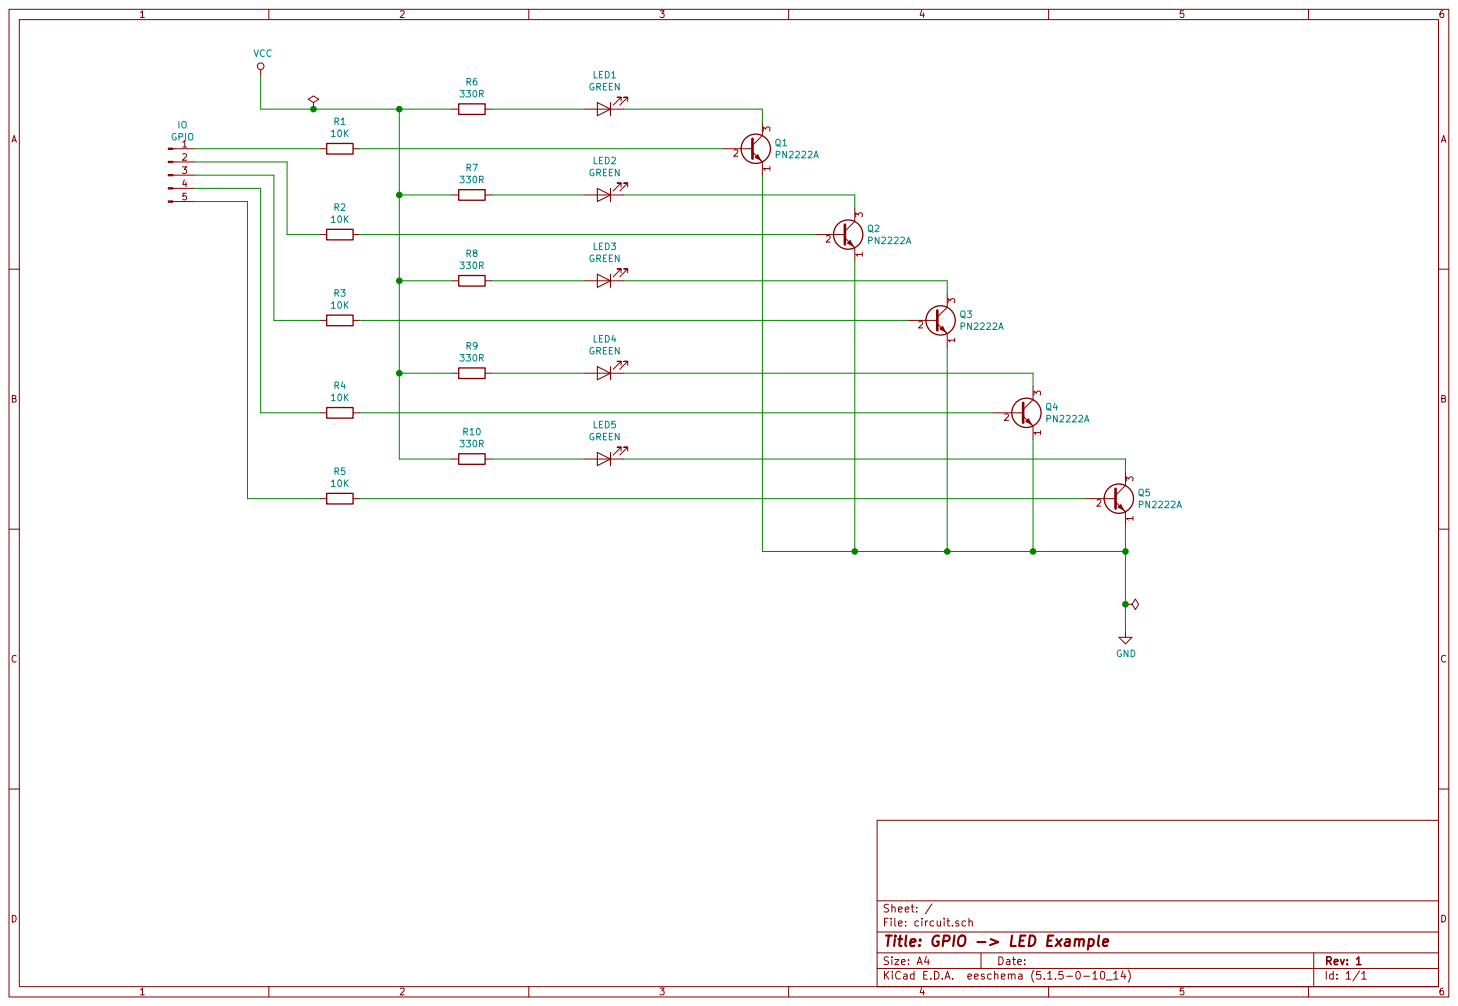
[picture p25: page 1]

Id: 1/1 Title: GPIO -> LED Example

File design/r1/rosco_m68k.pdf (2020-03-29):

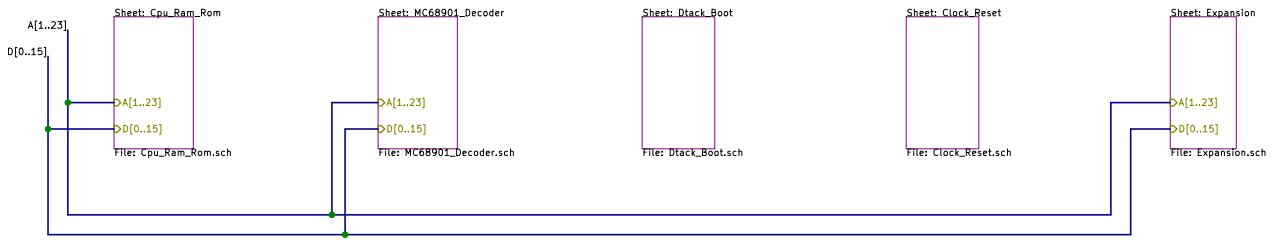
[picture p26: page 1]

Copyright 2019-2020 Ross Bamford and Contributors
Open Source Hardware licenced under CERN Open Hardware Licence
See https://github.com/roscopeco/rosco_m68k/blob/master/LICENCE.hardware.txt
File: rosco_m68k.sch Sheet: / OSHWA UK000006 (https://certification.oshwa.org/uk000006.html)

Id: 1/6 Title: ROSCO_M68K GENERAL PURPOSE MC68010 COMPUTER

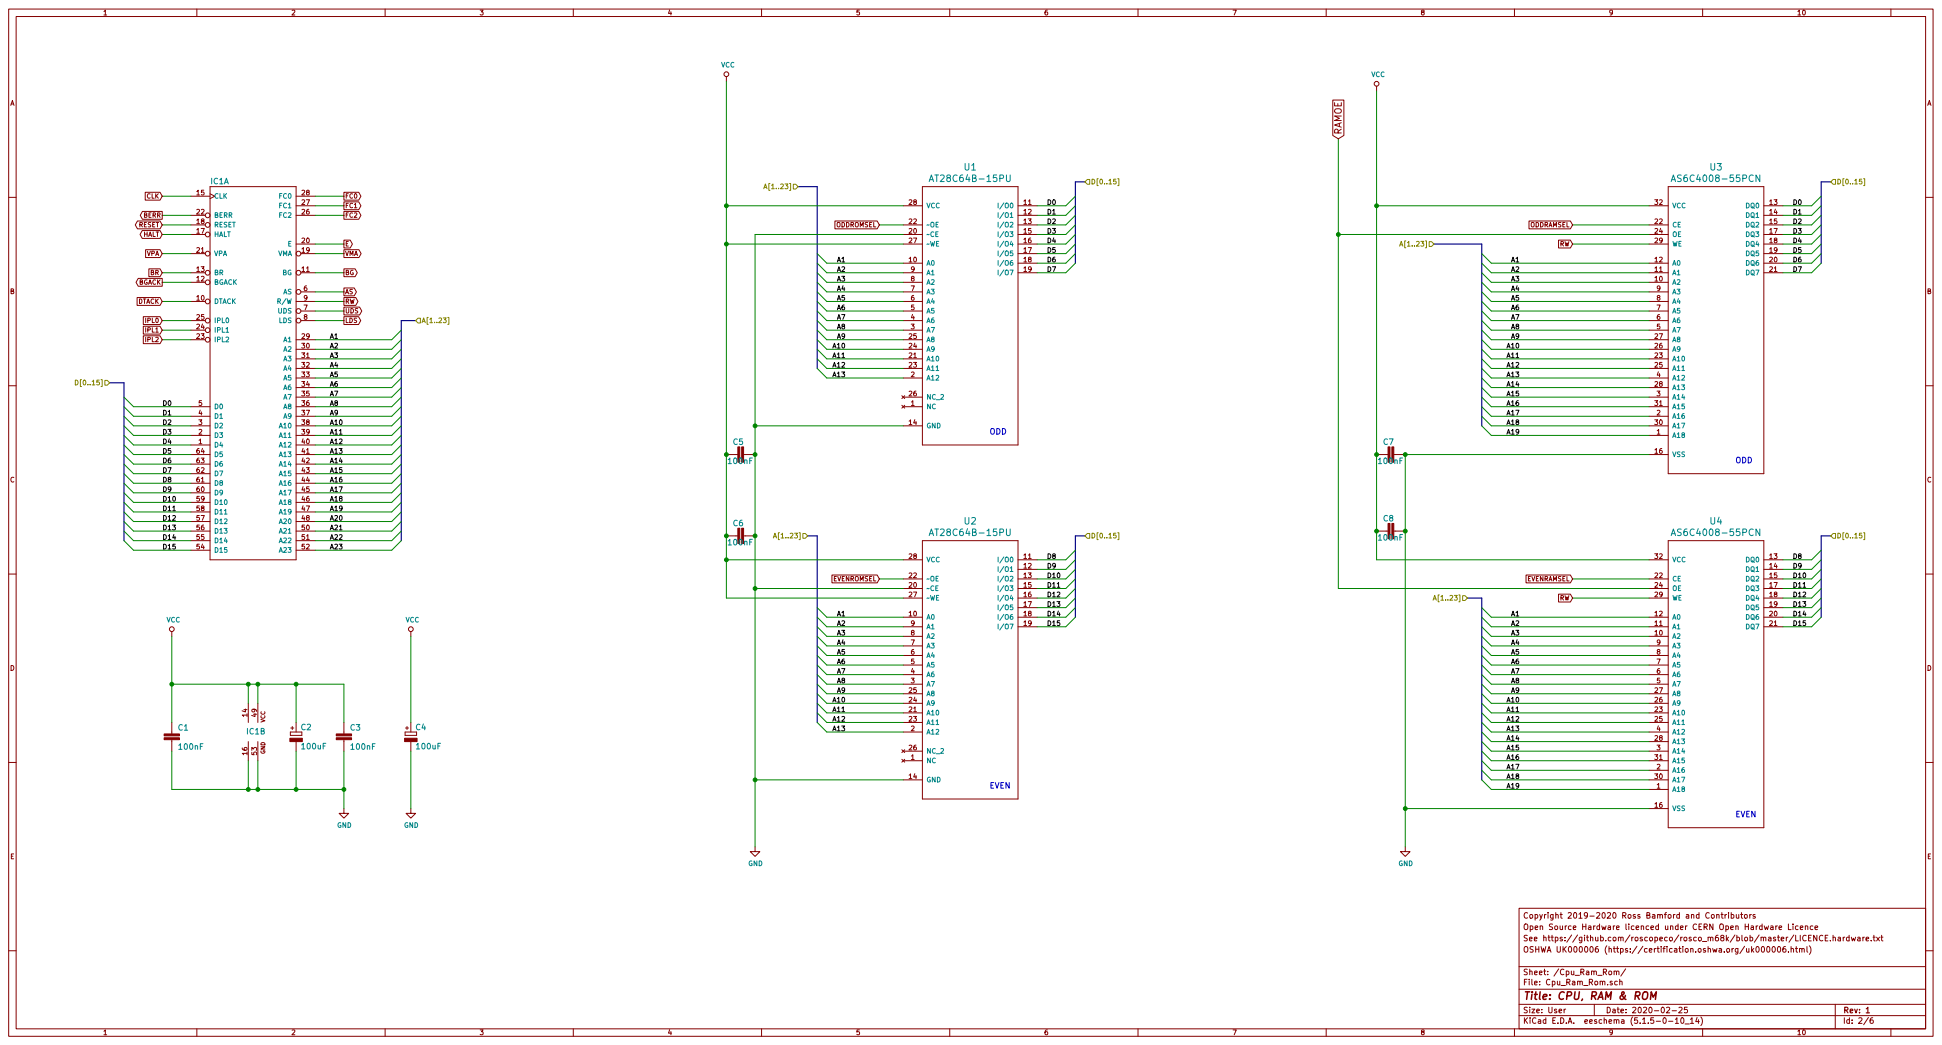
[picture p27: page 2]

Copyright 2019-2020 Ross Bamford and Contributors
Open Source Hardware licenced under CERN Open Hardware Licence
See https://github.com/roscopeco/rosco_m68k/blob/master/LICENCE.hardware.txt
OSHWA UK000006 (https://certification.oshwa.org/uk000006.html)

Sheet: /Cpu_Ram_Rom/
File: Cpu_Ram_Rom.sch
Id: 2/6 Title: CPU, RAM & ROM

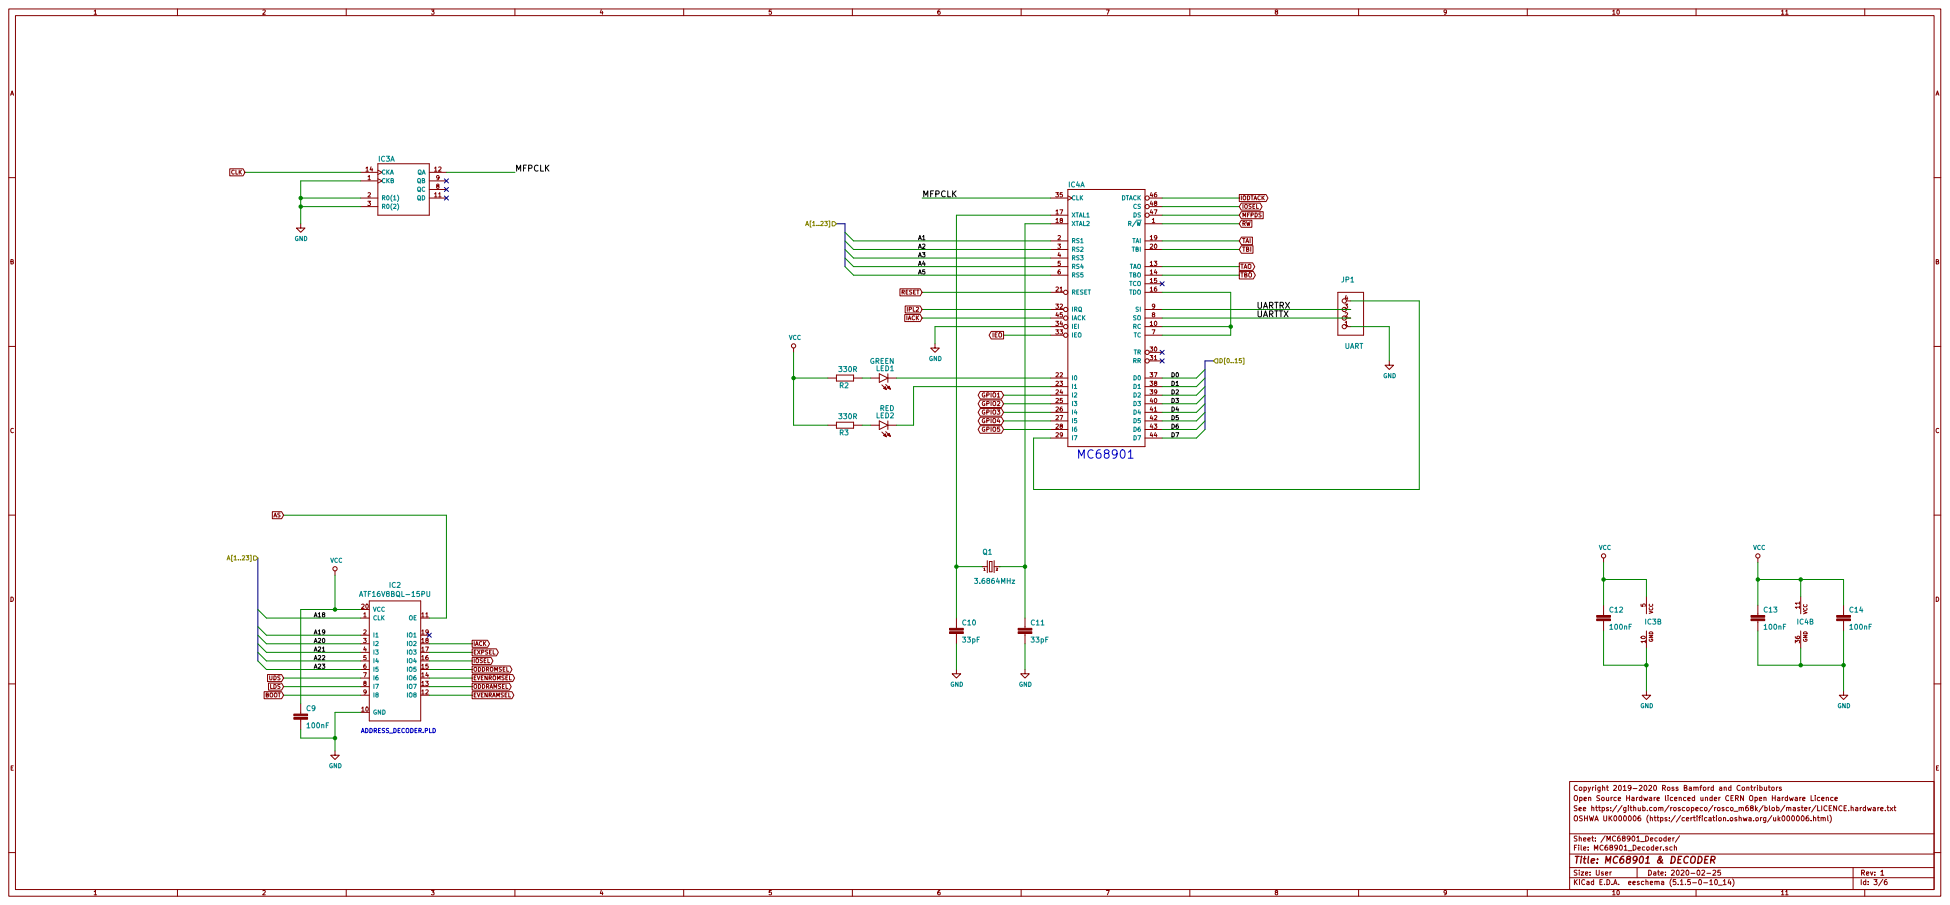
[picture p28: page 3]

IEO | IRQ 32 IEO 33 I0 22

I1 23
I2 24 I3 25 I4 26 I5 27 I6 28

IACK
EVENRAMSEL ODDRAMSEL ODDROMSEL EXPSEL
IOSEL

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

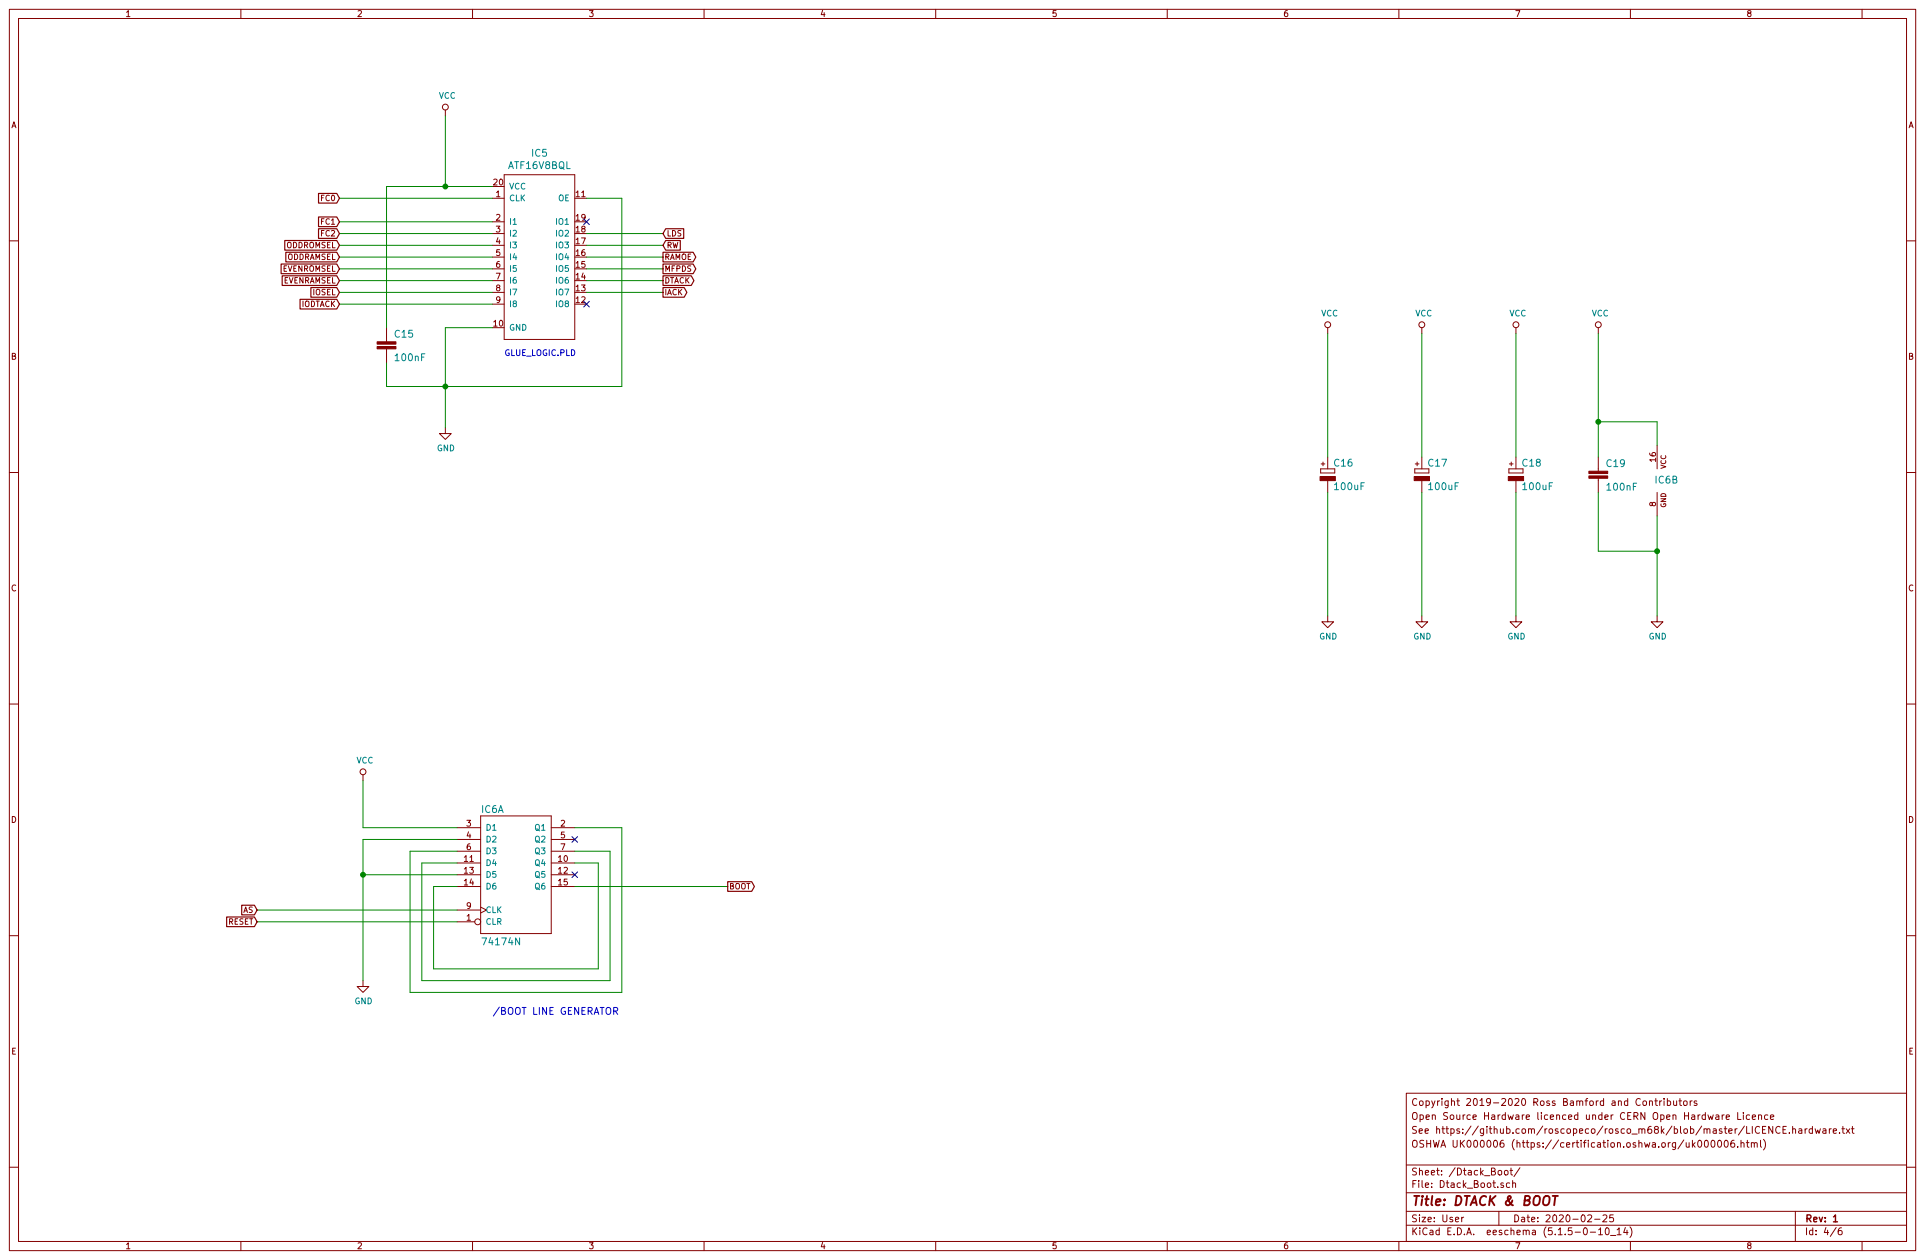
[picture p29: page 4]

IOSEL EVENRAMSEL ODDRAMSEL ODDROMSEL FC2 FC1 FC0

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

Sheet: /Dtack_Boot/
File: Dtack_Boot.sch
Id: 4/6 Title: DTACK & BOOT


Copyright 2019-2020 Ross Bamford and Contributors VCC

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

Sheet: /Clock_Reset/
File: Clock_Reset.sch
Id: 5/6 Title: SYSTEM CLOCK AND RESET


H4 MountingHole H3 MountingHole H2 MountingHole H1 MountingHole

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

Sheet: /Expansion/
File: Expansion.sch
Id: 6/6 Title: EXPANSION AND IO

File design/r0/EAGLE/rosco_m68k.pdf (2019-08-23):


CPU, RAM & ROM

Sheet: 1/6

22/08/2019 15:41 C:\Users\rosco\devel\retro\rosco_m68k\design\EAGLE\rosco_m68k.sch (Sheet: 1/6)


MC68901 & DECODER

Sheet: 2/6

22/08/2019 15:41 C:\Users\rosco\devel\retro\rosco_m68k\design\EAGLE\rosco_m68k.sch (Sheet: 2/6)


DTACK & BOOT

Sheet: 3/6

22/08/2019 15:41 C:\Users\rosco\devel\retro\rosco_m68k\design\EAGLE\rosco_m68k.sch (Sheet: 3/6)


CLOCK & RESET

Sheet: 4/6

22/08/2019 15:41 C:\Users\rosco\devel\retro\rosco_m68k\design\EAGLE\rosco_m68k.sch (Sheet: 4/6)


EXPANSION

Sheet: 5/6

22/08/2019 15:41 C:\Users\rosco\devel\retro\rosco_m68k\design\EAGLE\rosco_m68k.sch (Sheet: 5/6)

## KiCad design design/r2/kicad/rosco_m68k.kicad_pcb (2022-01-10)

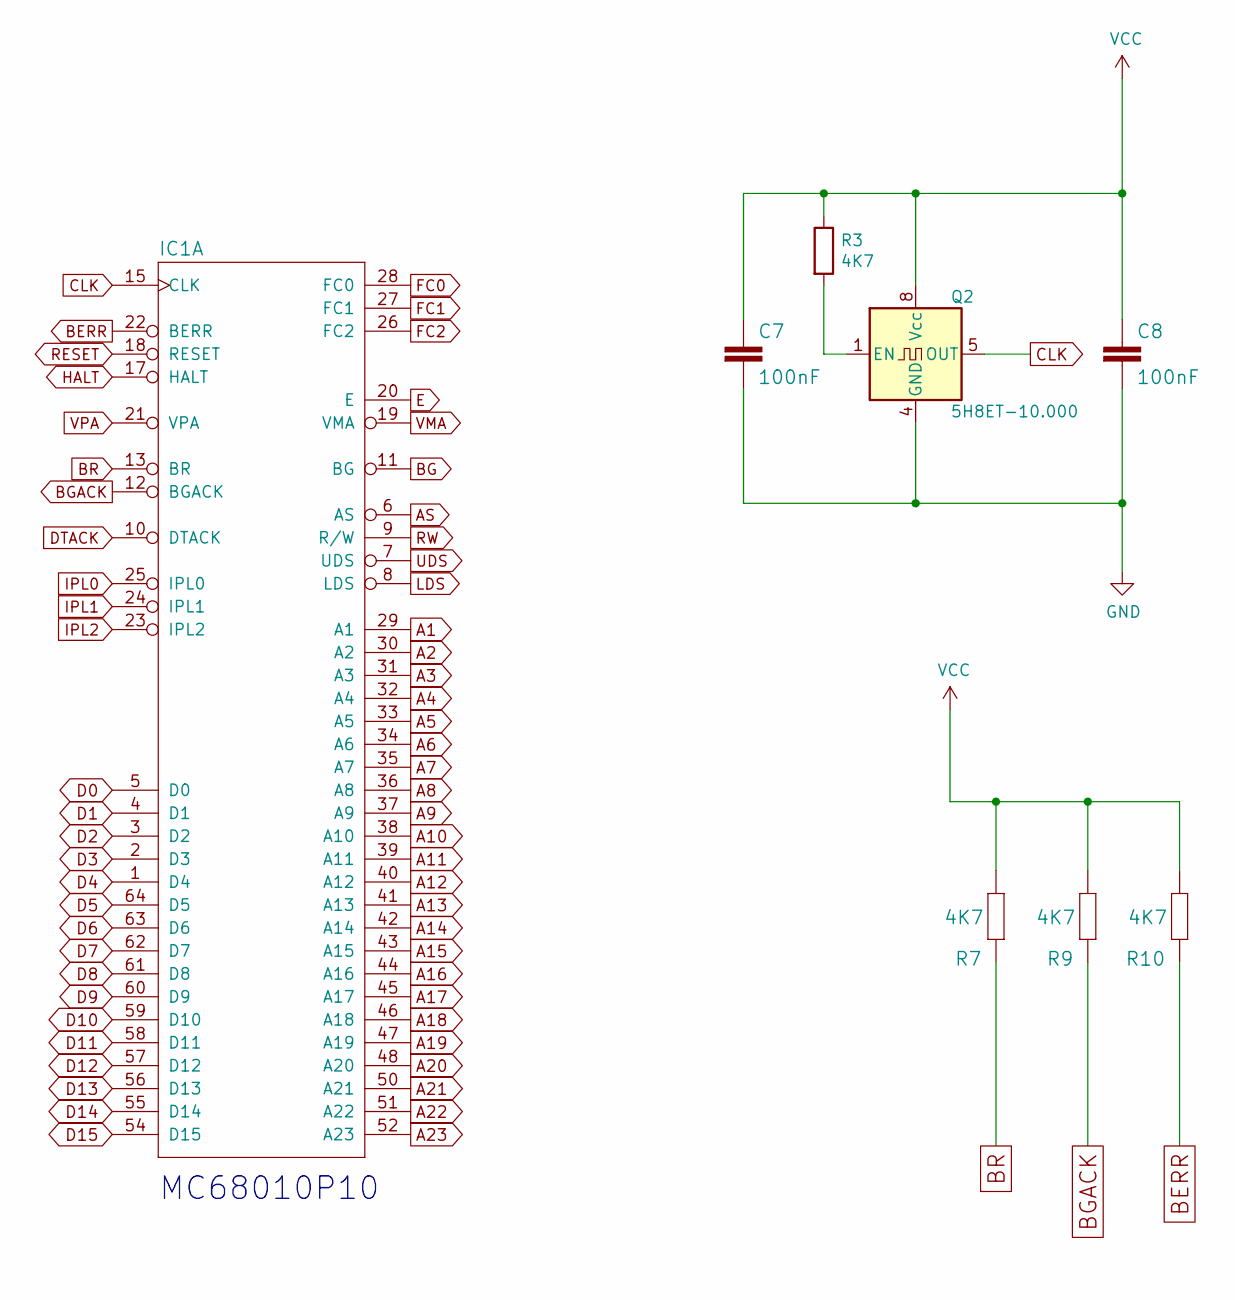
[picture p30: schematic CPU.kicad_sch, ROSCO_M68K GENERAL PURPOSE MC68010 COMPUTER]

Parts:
C7, C8: 100nF; C2.5-3
IC1: MC68010P10; DIL64
Q2: 5H8ET-10.000; Oscillator_DIP-8
R3, R7, R9, R10: 4K7; 0207_10

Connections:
A1: IC1.29 (A1); also elsewhere on the board
A2: IC1.30 (A2); also elsewhere on the board
A3: IC1.31 (A3); also elsewhere on the board
A4: IC1.32 (A4); also elsewhere on the board
A5: IC1.33 (A5); also elsewhere on the board
A6: IC1.34 (A6); also elsewhere on the board
A7: IC1.35 (A7); also elsewhere on the board
A8: IC1.36 (A8); also elsewhere on the board
A9: IC1.37 (A9); also elsewhere on the board
A10: IC1.38 (A10); also elsewhere on the board
A11: IC1.39 (A11); also elsewhere on the board
A12: IC1.40 (A12); also elsewhere on the board
A13: IC1.41 (A13); also elsewhere on the board
A14: IC1.42 (A14); also elsewhere on the board
A15: IC1.43 (A15); also elsewhere on the board
A16: IC1.44 (A16); also elsewhere on the board
A17: IC1.45 (A17); also elsewhere on the board
A18: IC1.46 (A18); also elsewhere on the board
A19: IC1.47 (A19); also elsewhere on the board
A20: IC1.48 (A20); also elsewhere on the board
A21: IC1.50 (A21); also elsewhere on the board
A22: IC1.51 (A22); also elsewhere on the board
A23: IC1.52 (A23); also elsewhere on the board
AS: IC1.6 (AS); also elsewhere on the board
BERR: IC1.22 (BERR), R10.1; also elsewhere on the board
BG: IC1.11 (BG); also elsewhere on the board
BGACK: IC1.12 (BGACK), R9.1; also elsewhere on the board
BR: IC1.13 (BR), R7.1; also elsewhere on the board
CLK: IC1.15 (CLK), Q2.5 (OUT); also elsewhere on the board
D0: IC1.5 (D0); also elsewhere on the board
D1: IC1.4 (D1); also elsewhere on the board
D2: IC1.3 (D2); also elsewhere on the board
D3: IC1.2 (D3); also elsewhere on the board
D4: IC1.1 (D4); also elsewhere on the board
D5: IC1.64 (D5); also elsewhere on the board
D6: IC1.63 (D6); also elsewhere on the board
D7: IC1.62 (D7); also elsewhere on the board
D8: IC1.61 (D8); also elsewhere on the board
D9: IC1.60 (D9); also elsewhere on the board
D10: IC1.59 (D10); also elsewhere on the board
D11: IC1.58 (D11); also elsewhere on the board
D12: IC1.57 (D12); also elsewhere on the board
D13: IC1.56 (D13); also elsewhere on the board
D14: IC1.55 (D14); also elsewhere on the board
D15: IC1.54 (D15); also elsewhere on the board
DTACK: IC1.10 (DTACK); also elsewhere on the board
E: IC1.20 (E); also elsewhere on the board
FC0: IC1.28 (FC0); also elsewhere on the board
FC1: IC1.27 (FC1); also elsewhere on the board
FC2: IC1.26 (FC2); also elsewhere on the board
GND: C7.2, C8.2, IC1.16 (GND@1), IC1.53 (GND@2), Q2.4 (GND); also elsewhere on the board
HALT: IC1.17 (HALT); also elsewhere on the board
IPL0: IC1.25 (IPL0); also elsewhere on the board
IPL1: IC1.24 (IPL1); also elsewhere on the board
IPL2: IC1.23 (IPL2); also elsewhere on the board
LDS: IC1.8 (LDS); also elsewhere on the board
unnamed: Q2.1 (EN), R3.2
RESET: IC1.18 (RESET); also elsewhere on the board
RW: IC1.9 (R/W); also elsewhere on the board
UDS: IC1.7 (UDS); also elsewhere on the board
VCC: C7.1, C8.1, IC1.14 (VCC@1), IC1.49 (VCC@2), Q2.8 (Vcc), R3.1, R7.2, R9.2, R10.2; also elsewhere on the board
VMA: IC1.19 (VMA); also elsewhere on the board
VPA: IC1.21 (VPA); also elsewhere on the board

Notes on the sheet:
MC68010P10

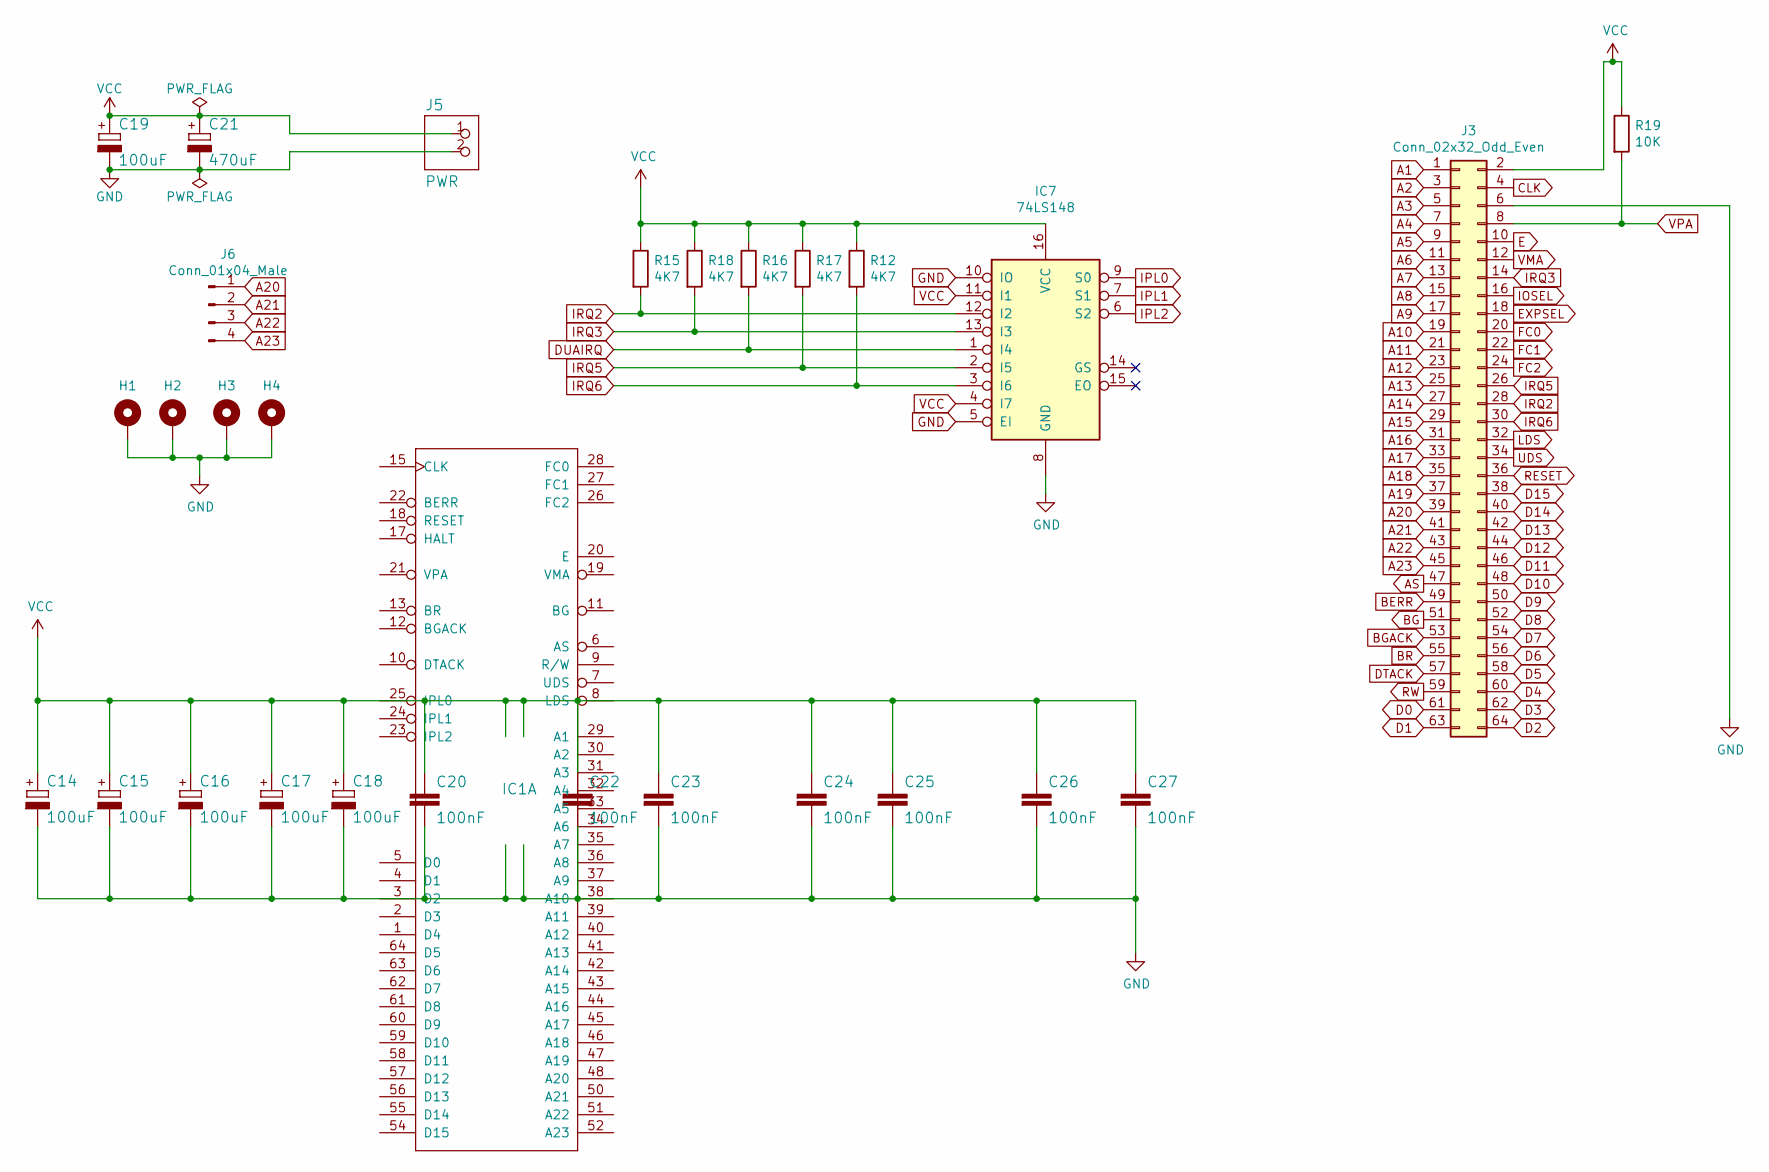
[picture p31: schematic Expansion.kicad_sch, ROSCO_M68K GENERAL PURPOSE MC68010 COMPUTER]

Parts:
C14, C15, C16, C17, C18, C19: 100uF; E2,5-5
C20, C22, C23, C24, C25, C26, C27: 100nF; C2.5-3
C21: 470uF; E3,5-10
H1, H2, H3, H4: MountingHole; MountingHole_3.2mm_M3_Pad
IC1: MC68010P10; DIL64
IC7: 74LS148; DIP-16_W7.62mm_LongPads
J3: Conn_02x32_Odd_Even; PinHeader_2x32_P2.54mm_Vertical
J5: PWR; 1X02
J6: Conn_01x04_Male; PinHeader_1x04_P2.54mm_Vertical
R12, R15, R16, R17, R18: 4K7; 0207_10
R19: 10K; 0207_10

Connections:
A1: IC1.29 (A1), J3.1; also elsewhere on the board
A2: IC1.30 (A2), J3.3; also elsewhere on the board
A3: IC1.31 (A3), J3.5; also elsewhere on the board
A4: IC1.32 (A4), J3.7; also elsewhere on the board
A5: IC1.33 (A5), J3.9; also elsewhere on the board
A6: IC1.34 (A6), J3.11; also elsewhere on the board
A7: IC1.35 (A7), J3.13; also elsewhere on the board
A8: IC1.36 (A8), J3.15; also elsewhere on the board
A9: IC1.37 (A9), J3.17; also elsewhere on the board
A10: IC1.38 (A10), J3.19; also elsewhere on the board
A11: IC1.39 (A11), J3.21; also elsewhere on the board
A12: IC1.40 (A12), J3.23; also elsewhere on the board
A13: IC1.41 (A13), J3.25; also elsewhere on the board
A14: IC1.42 (A14), J3.27; also elsewhere on the board
A15: IC1.43 (A15), J3.29; also elsewhere on the board
A16: IC1.44 (A16), J3.31; also elsewhere on the board
A17: IC1.45 (A17), J3.33; also elsewhere on the board
A18: IC1.46 (A18), J3.35; also elsewhere on the board
A19: IC1.47 (A19), J3.37; also elsewhere on the board
A20: IC1.48 (A20), J3.39, J6.1; also elsewhere on the board
A21: IC1.50 (A21), J3.41, J6.2; also elsewhere on the board
A22: IC1.51 (A22), J3.43, J6.3; also elsewhere on the board
A23: IC1.52 (A23), J3.45, J6.4; also elsewhere on the board
AS: IC1.6 (AS), J3.47; also elsewhere on the board
BERR: IC1.22 (BERR), J3.49; also elsewhere on the board
BG: IC1.11 (BG), J3.51
BGACK: IC1.12 (BGACK), J3.53; also elsewhere on the board
BR: IC1.13 (BR), J3.55; also elsewhere on the board
CLK: IC1.15 (CLK), J3.4; also elsewhere on the board
D0: IC1.5 (D0), J3.61; also elsewhere on the board
D1: IC1.4 (D1), J3.63; also elsewhere on the board
D2: IC1.3 (D2), J3.64; also elsewhere on the board
D3: IC1.2 (D3), J3.62; also elsewhere on the board
D4: IC1.1 (D4), J3.60; also elsewhere on the board
D5: IC1.64 (D5), J3.58; also elsewhere on the board
D6: IC1.63 (D6), J3.56; also elsewhere on the board
D7: IC1.62 (D7), J3.54; also elsewhere on the board
D8: IC1.61 (D8), J3.52; also elsewhere on the board
D9: IC1.60 (D9), J3.50; also elsewhere on the board
D10: IC1.59 (D10), J3.48; also elsewhere on the board
D11: IC1.58 (D11), J3.46; also elsewhere on the board
D12: IC1.57 (D12), J3.44; also elsewhere on the board
D13: IC1.56 (D13), J3.42; also elsewhere on the board
D14: IC1.55 (D14), J3.40; also elsewhere on the board
D15: IC1.54 (D15), J3.38; also elsewhere on the board
DTACK: IC1.10 (DTACK), J3.57; also elsewhere on the board
DUAIRQ: IC7.1 (I4), R16.2; also elsewhere on the board
E: IC1.20 (E), J3.10
EXPSEL: J3.18; also elsewhere on the board
FC0: IC1.28 (FC0), J3.20; also elsewhere on the board
FC1: IC1.27 (FC1), J3.22; also elsewhere on the board
FC2: IC1.26 (FC2), J3.24; also elsewhere on the board
GND: C14.-, C15.-, C16.-, C17.-, C18.-, C19.-, C20.2, C21.-, C22.2, C23.2, C24.2, C25.2, C26.2, C27.2, H1.1, H2.1, H3.1, H4.1, IC1.16 (GND@1), IC1.53 (GND@2), IC7.5 (EI), IC7.8 (GND), IC7.10 (IO), J3.6, J5.2; also elsewhere on the board
HALT: IC1.17 (HALT); also elsewhere on the board
IOSEL: J3.16; also elsewhere on the board
IPL0: IC1.25 (IPL0), IC7.9 (S0)
IPL1: IC1.24 (IPL1), IC7.7 (S1)
IPL2: IC1.23 (IPL2), IC7.6 (S2)
IRQ2: IC7.12 (I2), J3.28, R15.2
IRQ3: IC7.13 (I3), J3.14, R18.2
IRQ5: IC7.2 (I5), J3.26, R17.2
IRQ6: IC7.3 (I6), J3.30, R12.2
LDS: IC1.8 (LDS), J3.32; also elsewhere on the board
RESET: IC1.18 (RESET), J3.36; also elsewhere on the board
RW: IC1.9 (R/W), J3.59; also elsewhere on the board
UDS: IC1.7 (UDS), J3.34; also elsewhere on the board
VCC: C14.+, C15.+, C16.+, C17.+, C18.+, C19.+, C20.1, C21.+, C22.1, C23.1, C24.1, C25.1, C26.1, C27.1, IC1.14 (VCC@1), IC1.49 (VCC@2), IC7.4 (I7), IC7.11 (I1), IC7.16 (VCC), J3.2, J5.1, R12.1, R15.1, R16.1, R17.1, R18.1, R19.1; also elsewhere on the board
VMA: IC1.19 (VMA), J3.12
VPA: IC1.21 (VPA), J3.8, R19.2

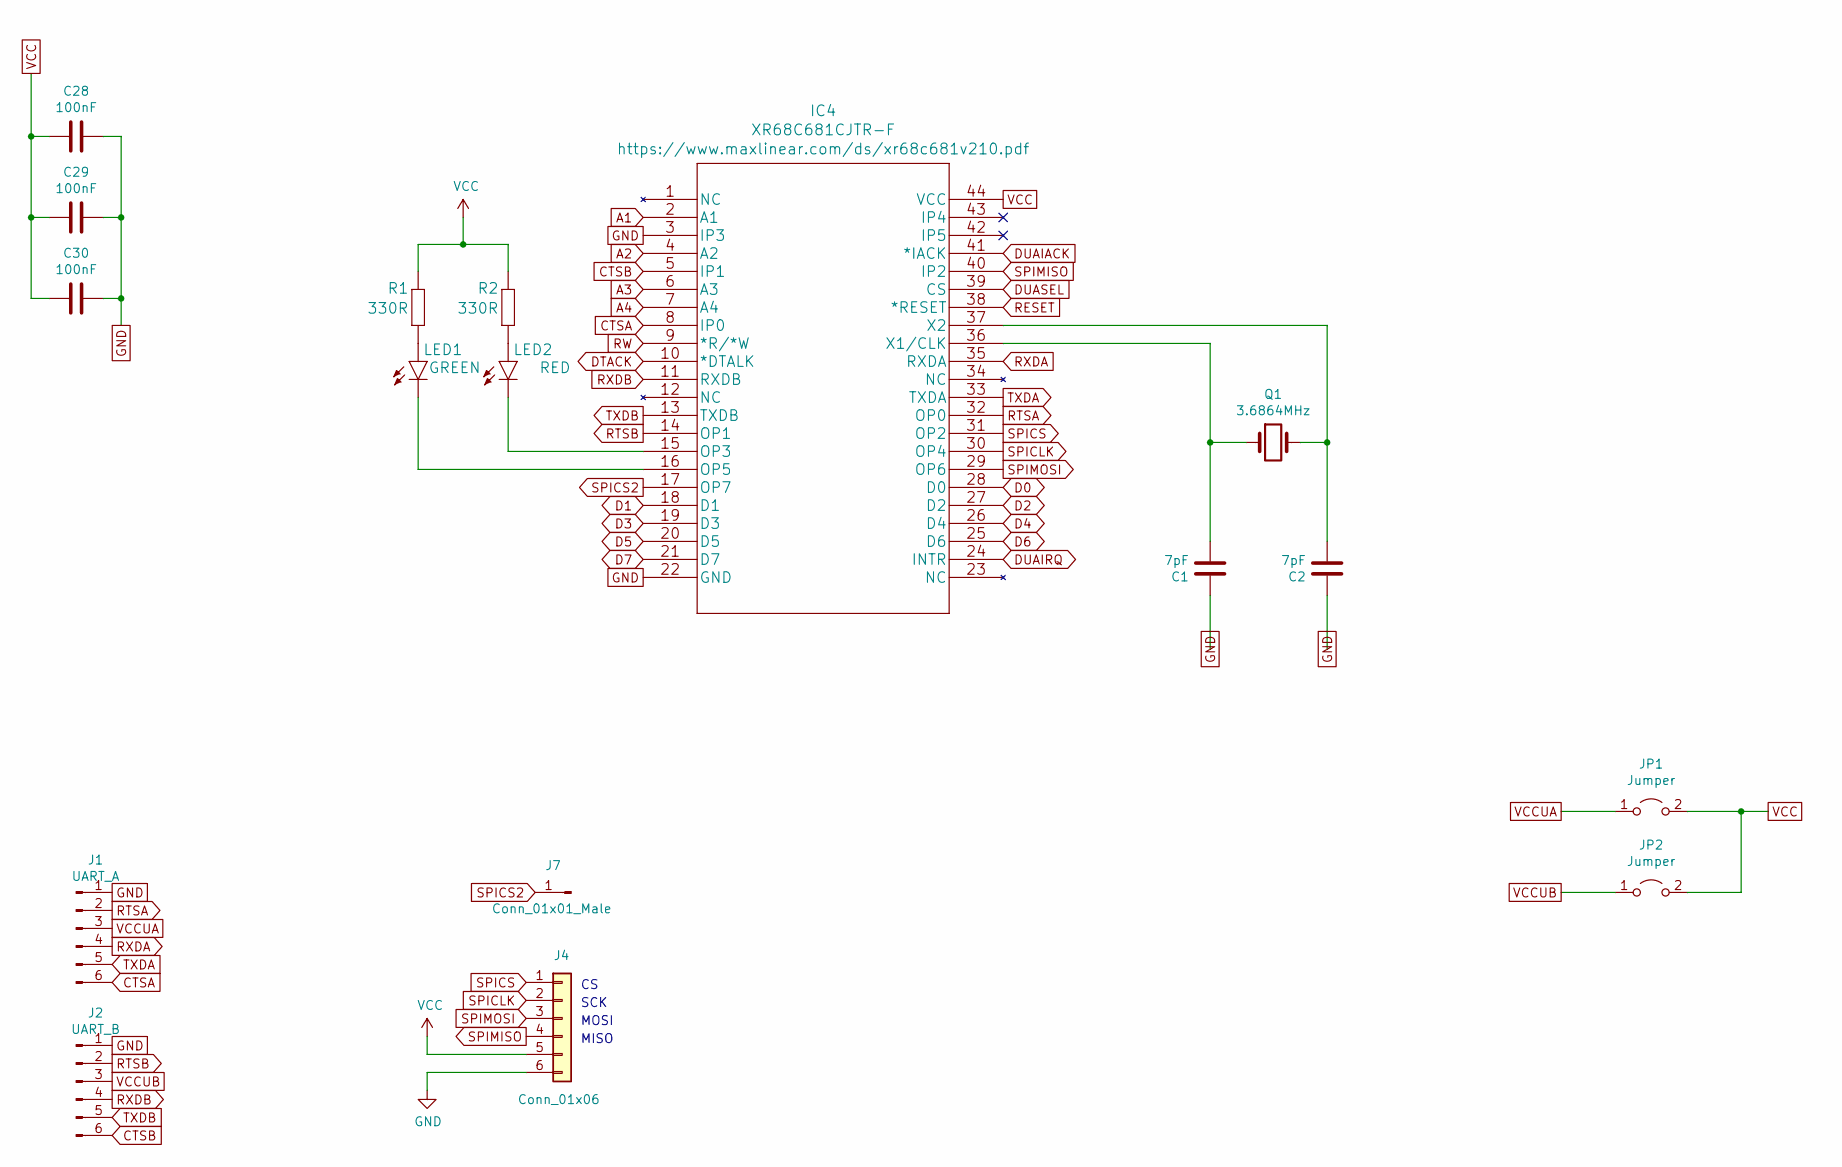
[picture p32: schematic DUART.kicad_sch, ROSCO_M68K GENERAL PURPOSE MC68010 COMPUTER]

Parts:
C1, C2: 7pF; C2.5_or_3.5-3
C28, C29, C30: 100nF; C2.5-3
IC4: XR68C681CJTR-F; PLCC-44_THT-Socket
J1: UART_A; 1X06
J2: UART_B; 1X06
J4: Conn_01x06; 1X06
J7: Conn_01x01_Male; PinHeader_1x01_P2.54mm_Vertical
JP1, JP2: Jumper; 1X02
LED1: GREEN; LED5MM
LED2: RED; LED5MM
Q1: 3.6864MHz; Crystal_HC49-4H_Vertical
R1, R2: 330R; 0207_10

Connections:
A1: IC4.2 (A1); also elsewhere on the board
A2: IC4.4 (A2); also elsewhere on the board
A3: IC4.6 (A3); also elsewhere on the board
A4: IC4.7 (A4); also elsewhere on the board
CTSA: IC4.8 (IP0), J1.6
CTSB: IC4.5 (IP1), J2.6
D0: IC4.28 (D0); also elsewhere on the board
D1: IC4.18 (D1); also elsewhere on the board
D2: IC4.27 (D2); also elsewhere on the board
D3: IC4.19 (D3); also elsewhere on the board
D4: IC4.26 (D4); also elsewhere on the board
D5: IC4.20 (D5); also elsewhere on the board
D6: IC4.25 (D6); also elsewhere on the board
D7: IC4.21 (D7); also elsewhere on the board
DTACK: IC4.10 (*DTALK); also elsewhere on the board
DUAIACK: IC4.41 (*IACK); also elsewhere on the board
DUAIRQ: IC4.24 (INTR); also elsewhere on the board
DUASEL: IC4.39 (CS); also elsewhere on the board
GND: C1.1, C2.1, C28.1, C29.1, C30.1, IC4.3 (IP3), IC4.22 (GND), J1.1, J2.1, J4.6; also elsewhere on the board
unnamed: C1.2, IC4.36 (X1/CLK), Q1.1
unnamed: C2.2, IC4.37 (X2), Q1.2
unnamed: IC4.15 (OP3), LED2.K (C)
unnamed: IC4.16 (OP5), LED1.K (C)
unnamed: LED1.A, R1.1
unnamed: LED2.A, R2.1
RESET: IC4.38 (*RESET); also elsewhere on the board
RTSA: IC4.32 (OP0), J1.2
RTSB: IC4.14 (OP1), J2.2
RW: IC4.9 (*R/*W); also elsewhere on the board
RXDA: IC4.35 (RXDA), J1.4
RXDB: IC4.11 (RXDB), J2.4
SPICLK: IC4.30 (OP4), J4.2
SPICS: IC4.31 (OP2), J4.1
SPICS2: IC4.17 (OP7), J7.1
SPIMISO: IC4.40 (IP2), J4.4
SPIMOSI: IC4.29 (OP6), J4.3
TXDA: IC4.33 (TXDA), J1.5
TXDB: IC4.13 (TXDB), J2.5
VCC: C28.2, C29.2, C30.2, IC4.44 (VCC), J4.5, JP1.2 (B), JP2.2 (B), R1.2, R2.2; also elsewhere on the board
VCCUA: J1.3, JP1.1 (A)
VCCUB: J2.3, JP2.1 (A)

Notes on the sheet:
MISO
SCK
MOSI

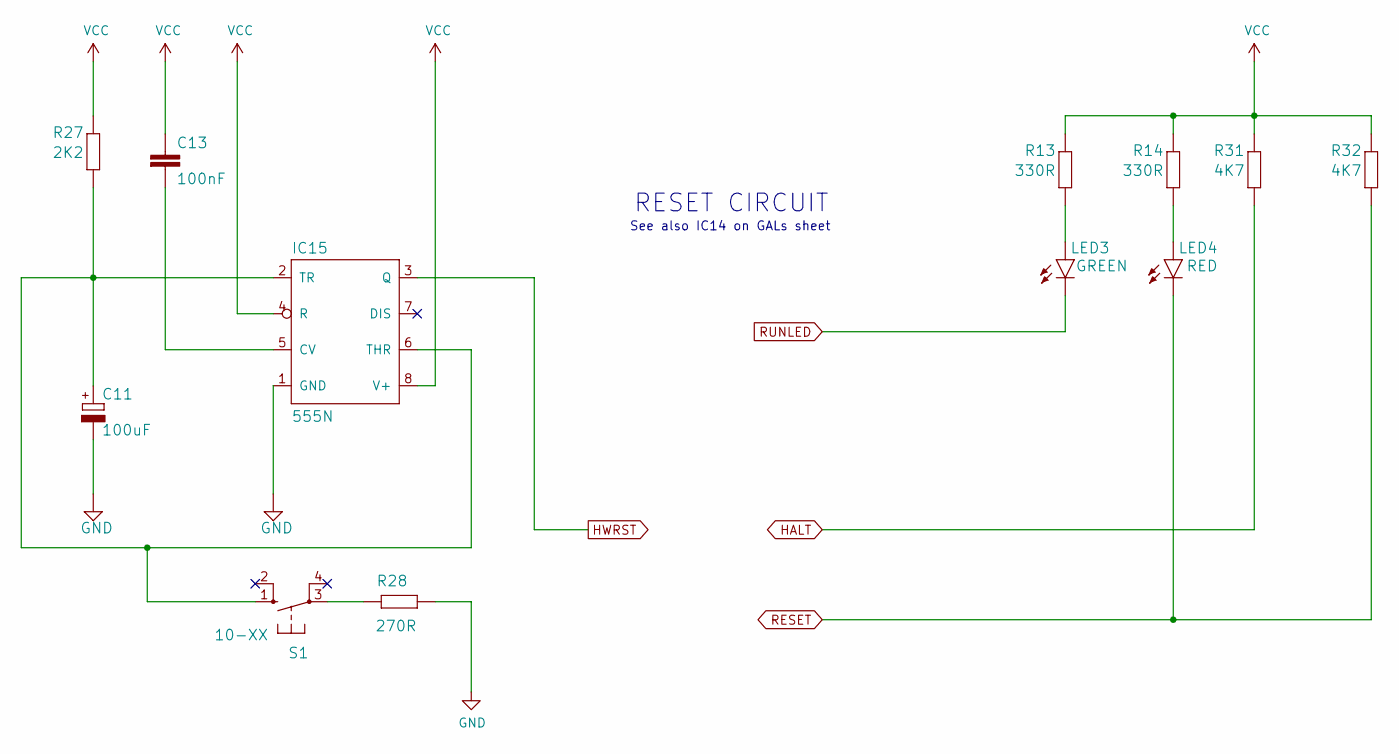
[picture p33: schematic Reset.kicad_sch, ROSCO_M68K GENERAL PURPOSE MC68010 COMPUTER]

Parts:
C11: 100uF; E2,5-5
C13: 100nF; C2.5-3
IC15: 555N; DIP-8_W7.62mm_LongPads
LED3: GREEN; LED5MM
LED4: RED; LED5MM
R13, R14: 330R; 0207_10
R27: 2K2; 0207_10
R28: 270R; 0207_10
R31, R32: 4K7; 0207_10
S1: 10-XX; B3F-10XX

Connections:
GND: C11.-, IC15.1 (GND), R28.1; also elsewhere on the board
HALT: R31.1; also elsewhere on the board
HWRST: IC15.3 (Q); also elsewhere on the board
unnamed: C11.+, IC15.2 (TR), IC15.6 (THR), R27.1, S1.1 (S)
unnamed: C13.2, IC15.5 (CV)
unnamed: LED3.A, R13.1
unnamed: LED4.A, R14.1
unnamed: R28.2, S1.3
RESET: LED4.K (C), R32.1; also elsewhere on the board
RUNLED: LED3.K (C); also elsewhere on the board
VCC: C13.1, IC15.4 (R), IC15.8 (V+), R13.2, R14.2, R27.2, R31.2, R32.2; also elsewhere on the board

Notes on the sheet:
See also IC14 on GALs sheet
RESET CIRCUIT

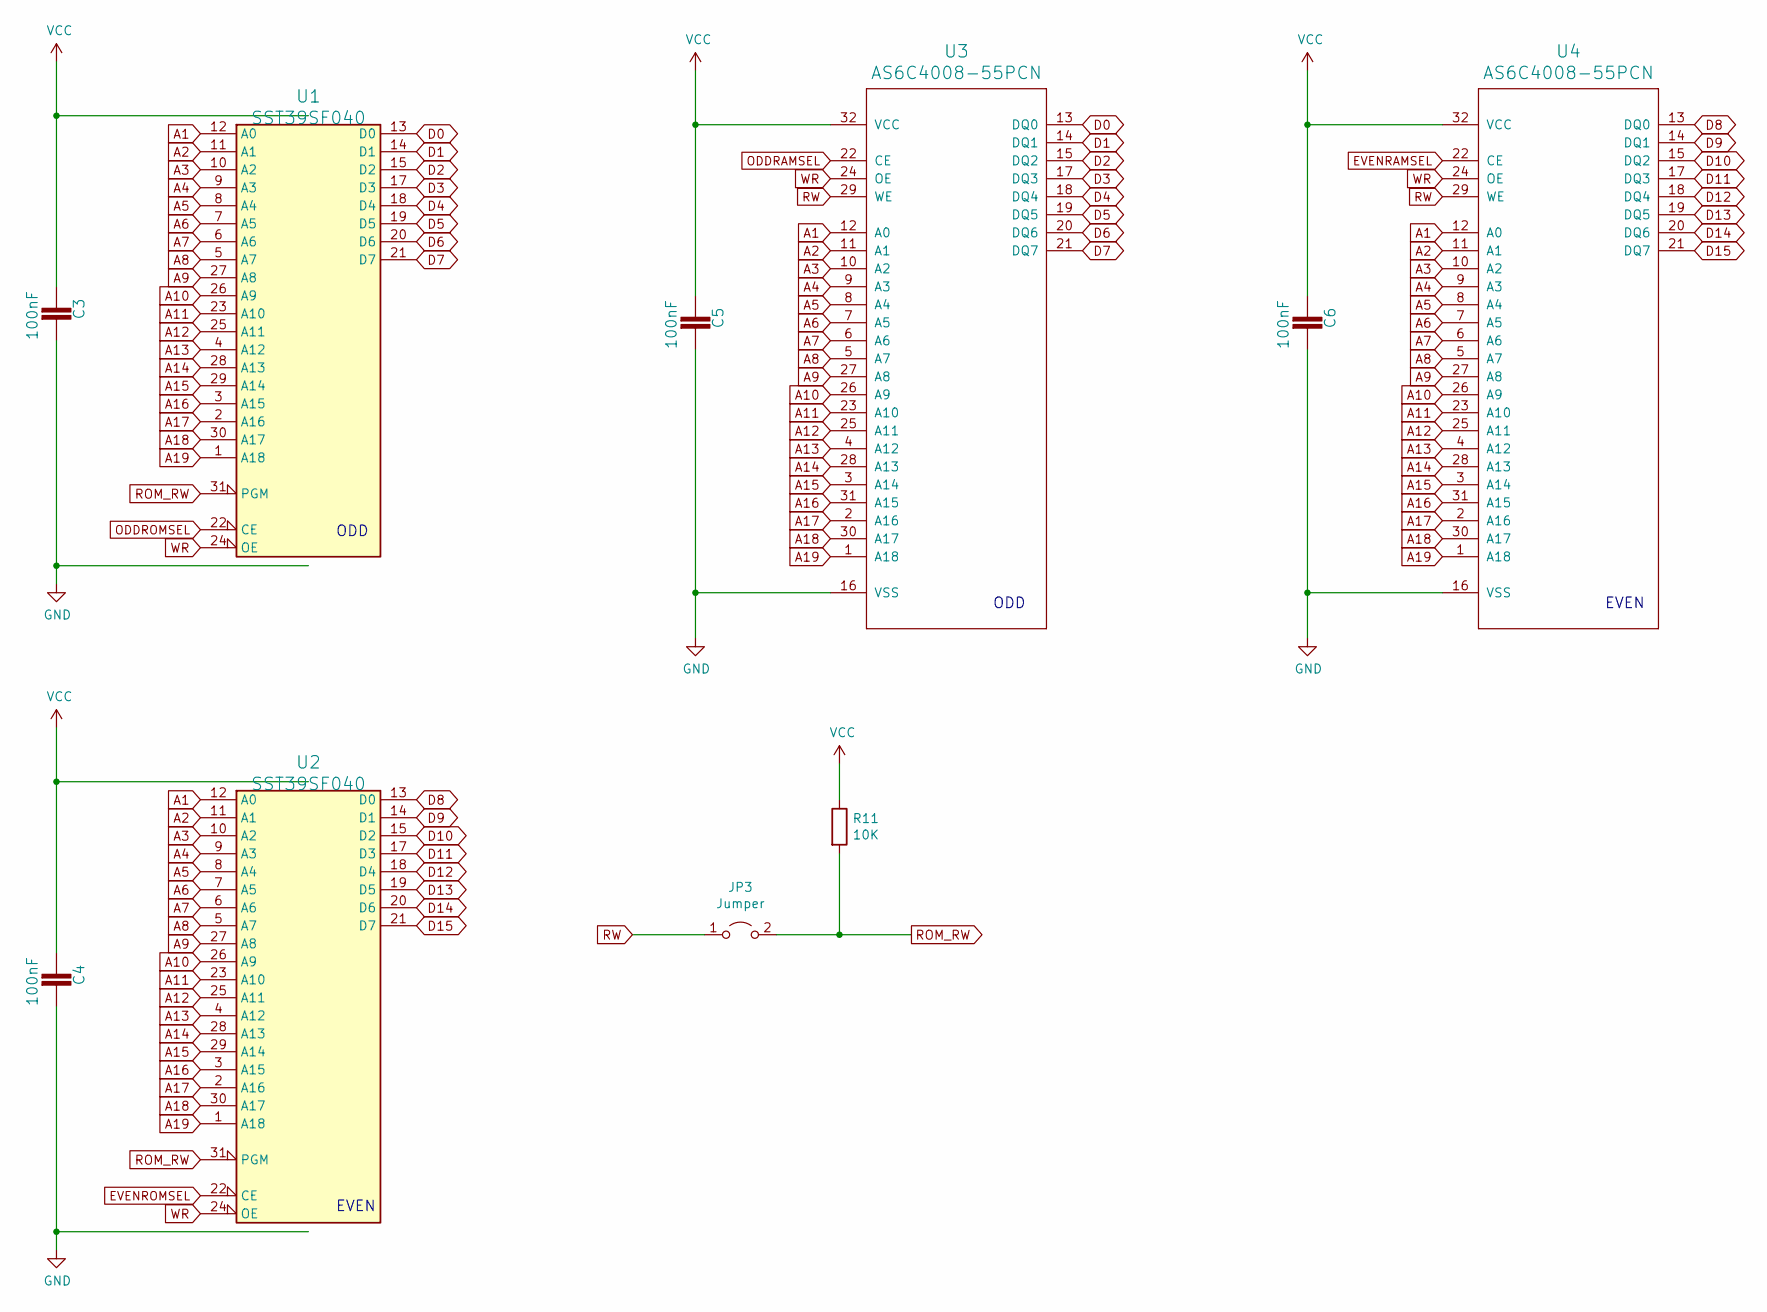
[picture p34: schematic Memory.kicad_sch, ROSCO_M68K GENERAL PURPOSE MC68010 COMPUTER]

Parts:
C3, C4, C5, C6: 100nF; C2.5-3
JP3: Jumper; 1X02
R11: 10K; 0207_10
U1, U2: SST39SF040; DIP-32_W15.24mm_LongPads
U3, U4: AS6C4008-55PCN; DIP-32_W15.24mm_LongPads

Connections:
A1: U1.12 (A0), U2.12 (A0), U3.12 (A0), U4.12 (A0); also elsewhere on the board
A2: U1.11 (A1), U2.11 (A1), U3.11 (A1), U4.11 (A1); also elsewhere on the board
A3: U1.10 (A2), U2.10 (A2), U3.10 (A2), U4.10 (A2); also elsewhere on the board
A4: U1.9 (A3), U2.9 (A3), U3.9 (A3), U4.9 (A3); also elsewhere on the board
A5: U1.8 (A4), U2.8 (A4), U3.8 (A4), U4.8 (A4); also elsewhere on the board
A6: U1.7 (A5), U2.7 (A5), U3.7 (A5), U4.7 (A5); also elsewhere on the board
A7: U1.6 (A6), U2.6 (A6), U3.6 (A6), U4.6 (A6); also elsewhere on the board
A8: U1.5 (A7), U2.5 (A7), U3.5 (A7), U4.5 (A7); also elsewhere on the board
A9: U1.27 (A8), U2.27 (A8), U3.27 (A8), U4.27 (A8); also elsewhere on the board
A10: U1.26 (A9), U2.26 (A9), U3.26 (A9), U4.26 (A9); also elsewhere on the board
A11: U1.23 (A10), U2.23 (A10), U3.23 (A10), U4.23 (A10); also elsewhere on the board
A12: U1.25 (A11), U2.25 (A11), U3.25 (A11), U4.25 (A11); also elsewhere on the board
A13: U1.4 (A12), U2.4 (A12), U3.4 (A12), U4.4 (A12); also elsewhere on the board
A14: U1.28 (A13), U2.28 (A13), U3.28 (A13), U4.28 (A13); also elsewhere on the board
A15: U1.29 (A14), U2.29 (A14), U3.3 (A14), U4.3 (A14); also elsewhere on the board
A16: U1.3 (A15), U2.3 (A15), U3.31 (A15), U4.31 (A15); also elsewhere on the board
A17: U1.2 (A16), U2.2 (A16), U3.2 (A16), U4.2 (A16); also elsewhere on the board
A18: U1.30 (A17), U2.30 (A17), U3.30 (A17), U4.30 (A17); also elsewhere on the board
A19: U1.1 (A18), U2.1 (A18), U3.1 (A18), U4.1 (A18); also elsewhere on the board
D0: U1.13 (D0), U3.13 (DQ0); also elsewhere on the board
D1: U1.14 (D1), U3.14 (DQ1); also elsewhere on the board
D2: U1.15 (D2), U3.15 (DQ2); also elsewhere on the board
D3: U1.17 (D3), U3.17 (DQ3); also elsewhere on the board
D4: U1.18 (D4), U3.18 (DQ4); also elsewhere on the board
D5: U1.19 (D5), U3.19 (DQ5); also elsewhere on the board
D6: U1.20 (D6), U3.20 (DQ6); also elsewhere on the board
D7: U1.21 (D7), U3.21 (DQ7); also elsewhere on the board
D8: U2.13 (D0), U4.13 (DQ0); also elsewhere on the board
D9: U2.14 (D1), U4.14 (DQ1); also elsewhere on the board
D10: U2.15 (D2), U4.15 (DQ2); also elsewhere on the board
D11: U2.17 (D3), U4.17 (DQ3); also elsewhere on the board
D12: U2.18 (D4), U4.18 (DQ4); also elsewhere on the board
D13: U2.19 (D5), U4.19 (DQ5); also elsewhere on the board
D14: U2.20 (D6), U4.20 (DQ6); also elsewhere on the board
D15: U2.21 (D7), U4.21 (DQ7); also elsewhere on the board
EVENRAMSEL: U4.22 (CE); also elsewhere on the board
EVENROMSEL: U2.22 (CE); also elsewhere on the board
GND: C3.2, C4.2, C5.2, C6.2, U1.16 (GND), U2.16 (GND), U3.16 (VSS), U4.16 (VSS); also elsewhere on the board
ODDRAMSEL: U3.22 (CE); also elsewhere on the board
ODDROMSEL: U1.22 (CE); also elsewhere on the board
ROM_RW: JP3.2 (B), R11.2, U1.31 (PGM), U2.31 (PGM)
RW: JP3.1 (A), U3.29 (WE), U4.29 (WE); also elsewhere on the board
VCC: C3.1, C4.1, C5.1, C6.1, R11.1, U1.32 (VCC), U2.32 (VCC), U3.32 (VCC), U4.32 (VCC); also elsewhere on the board
WR: U1.24 (OE), U2.24 (OE), U3.24 (OE), U4.24 (OE); also elsewhere on the board

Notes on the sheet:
EVEN
ODD

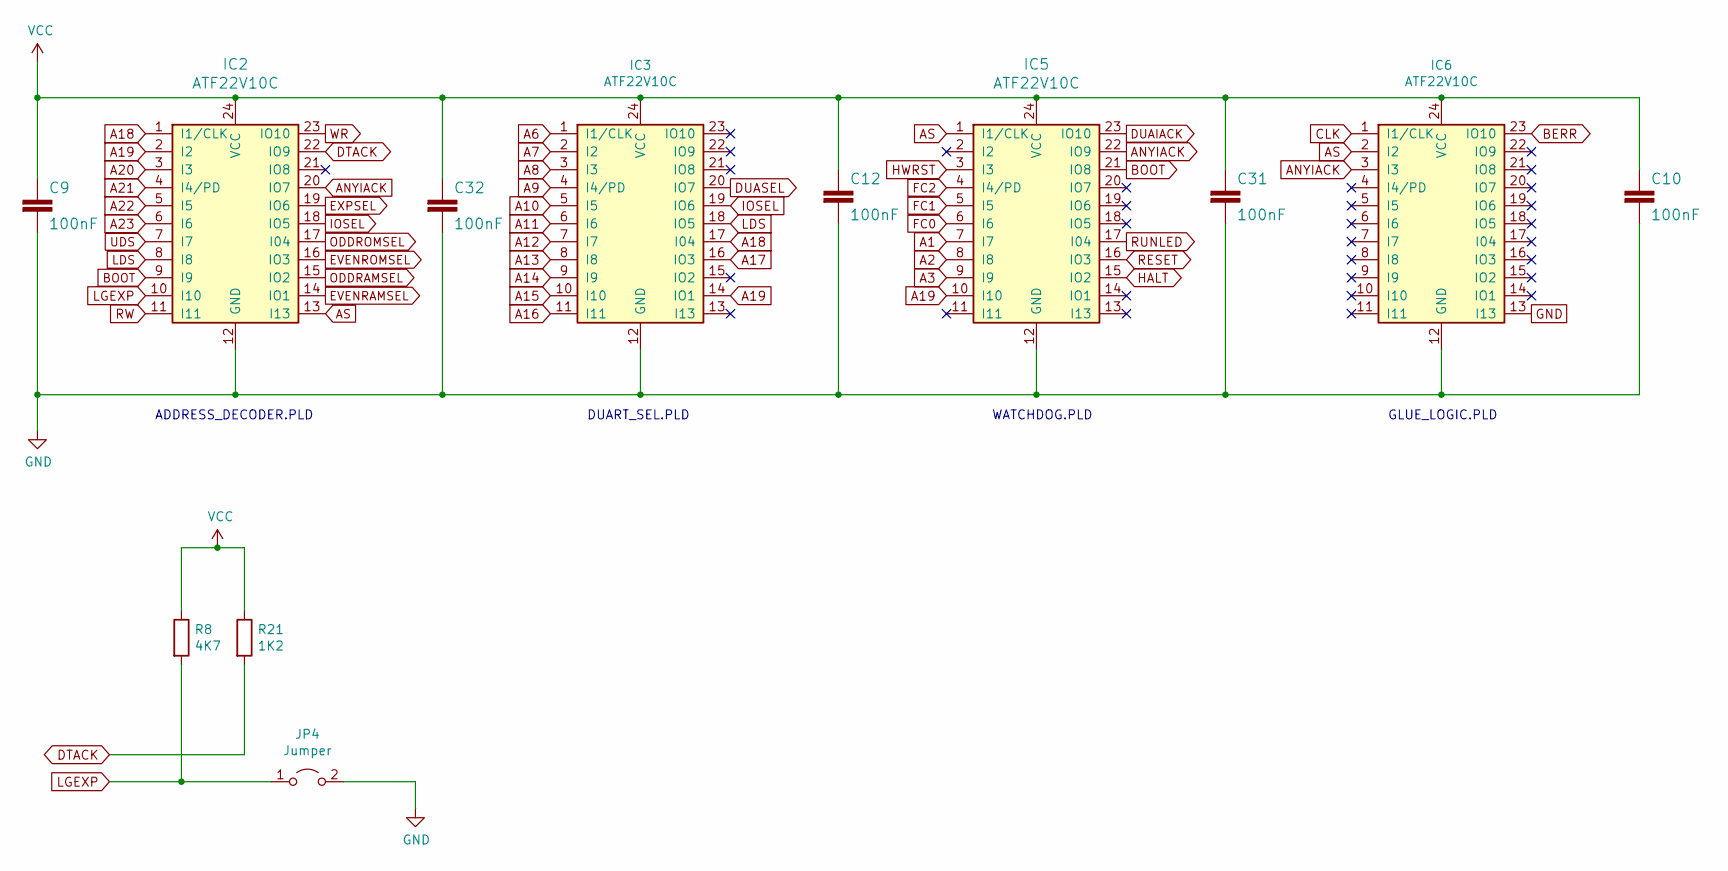
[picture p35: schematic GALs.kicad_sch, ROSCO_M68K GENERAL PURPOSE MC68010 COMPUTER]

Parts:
C9, C10, C12, C31, C32: 100nF; C2.5-3
IC2, IC3, IC5, IC6: ATF22V10C; DIP-24_W7.62mm_Socket_LongPads
JP4: Jumper; 1X02
R8: 4K7; 0207_10
R21: 1K2; 0207_10

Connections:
A1: IC5.7 (I7); also elsewhere on the board
A2: IC5.8 (I8); also elsewhere on the board
A3: IC5.9 (I9); also elsewhere on the board
A6: IC3.1 (I1/CLK); also elsewhere on the board
A7: IC3.2 (I2); also elsewhere on the board
A8: IC3.3 (I3); also elsewhere on the board
A9: IC3.4 (I4/PD); also elsewhere on the board
A10: IC3.5 (I5); also elsewhere on the board
A11: IC3.6 (I6); also elsewhere on the board
A12: IC3.7 (I7); also elsewhere on the board
A13: IC3.8 (I8); also elsewhere on the board
A14: IC3.9 (I9); also elsewhere on the board
A15: IC3.10 (I10); also elsewhere on the board
A16: IC3.11 (I11); also elsewhere on the board
A17: IC3.16 (IO3); also elsewhere on the board
A18: IC2.1 (I1/CLK), IC3.17 (I04); also elsewhere on the board
A19: IC2.2 (I2), IC3.14 (IO1), IC5.10 (I10); also elsewhere on the board
A20: IC2.3 (I3); also elsewhere on the board
A21: IC2.4 (I4/PD); also elsewhere on the board
A22: IC2.5 (I5); also elsewhere on the board
A23: IC2.6 (I6); also elsewhere on the board
ANYIACK: IC2.20 (IO7), IC5.22 (IO9), IC6.3 (I3)
AS: IC2.13 (I13), IC5.1 (I1/CLK), IC6.2 (I2); also elsewhere on the board
BERR: IC6.23 (IO10); also elsewhere on the board
BOOT: IC2.9 (I9), IC5.21 (IO8)
CLK: IC6.1 (I1/CLK); also elsewhere on the board
DTACK: IC2.22 (IO9), R21.2; also elsewhere on the board
DUAIACK: IC5.23 (IO10); also elsewhere on the board
DUASEL: IC3.20 (IO7); also elsewhere on the board
EVENRAMSEL: IC2.14 (IO1); also elsewhere on the board
EVENROMSEL: IC2.16 (IO3); also elsewhere on the board
EXPSEL: IC2.19 (IO6); also elsewhere on the board
FC0: IC5.6 (I6); also elsewhere on the board
FC1: IC5.5 (I5); also elsewhere on the board
FC2: IC5.4 (I4/PD); also elsewhere on the board
GND: C9.2, C10.2, C12.2, C31.2, C32.2, IC2.12 (GND), IC3.12 (GND), IC5.12 (GND), IC6.12 (GND), IC6.13 (I13), JP4.2 (B); also elsewhere on the board
HALT: IC5.15 (IO2); also elsewhere on the board
HWRST: IC5.3 (I3); also elsewhere on the board
IOSEL: IC2.18 (IO5), IC3.19 (IO6); also elsewhere on the board
LDS: IC2.8 (I8), IC3.18 (IO5); also elsewhere on the board
LGEXP: IC2.10 (I10), JP4.1 (A), R8.2
ODDRAMSEL: IC2.15 (IO2); also elsewhere on the board
ODDROMSEL: IC2.17 (I04); also elsewhere on the board
RESET: IC5.16 (IO3); also elsewhere on the board
RUNLED: IC5.17 (I04); also elsewhere on the board
RW: IC2.11 (I11); also elsewhere on the board
UDS: IC2.7 (I7); also elsewhere on the board
VCC: C9.1, C10.1, C12.1, C31.1, C32.1, IC2.24 (VCC), IC3.24 (VCC), IC5.24 (VCC), IC6.24 (VCC), R8.1, R21.1; also elsewhere on the board
WR: IC2.23 (IO10); also elsewhere on the board

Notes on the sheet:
GLUE_LOGIC.PLD
ADDRESS_DECODER.PLD
DUART_SEL.PLD
WATCHDOG.PLD

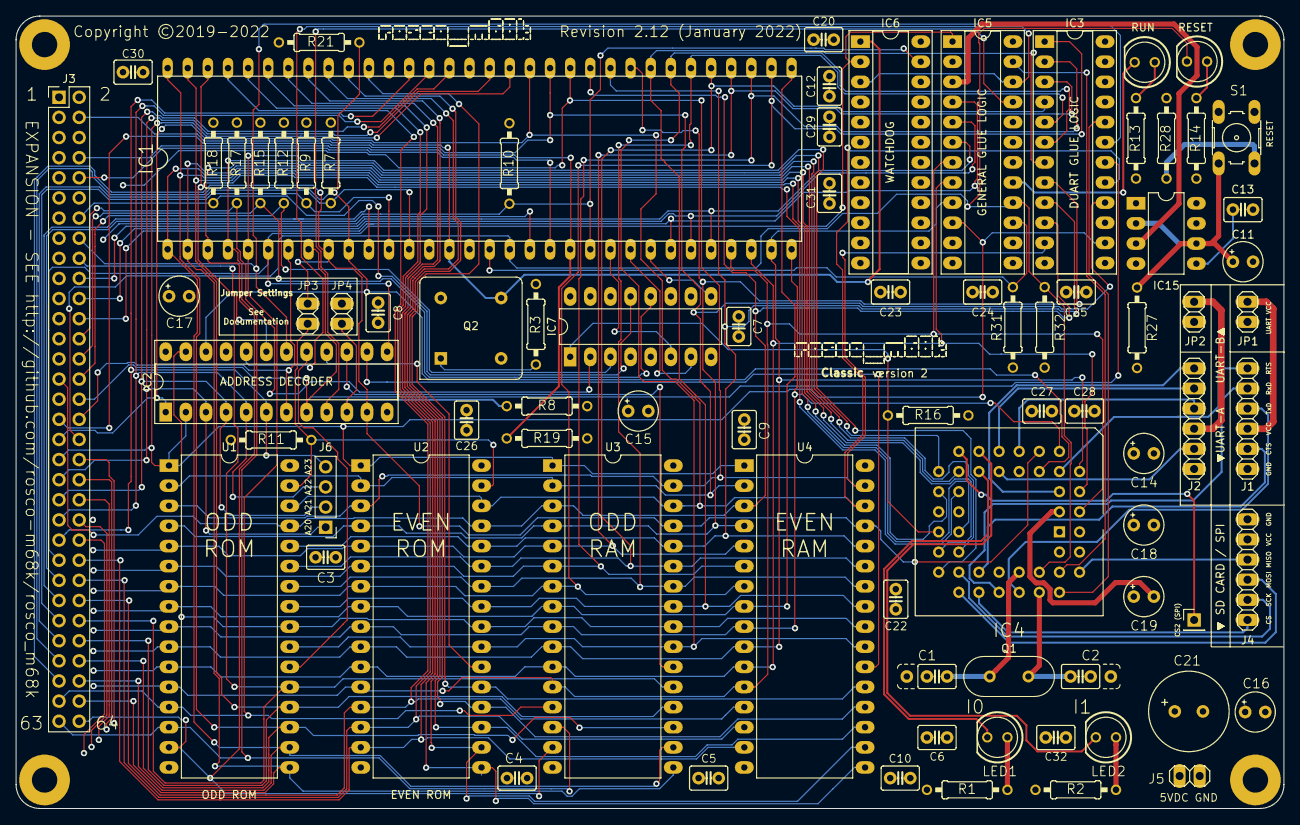
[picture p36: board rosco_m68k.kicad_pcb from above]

Board: 4 copper layers, 160.0 x 100.0 mm, 88 parts (0 on the bottom side), 109 nets.

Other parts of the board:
OSHW_Mono_0.25_Scale: UK000006; OSHW_Mono_0.25_Scale

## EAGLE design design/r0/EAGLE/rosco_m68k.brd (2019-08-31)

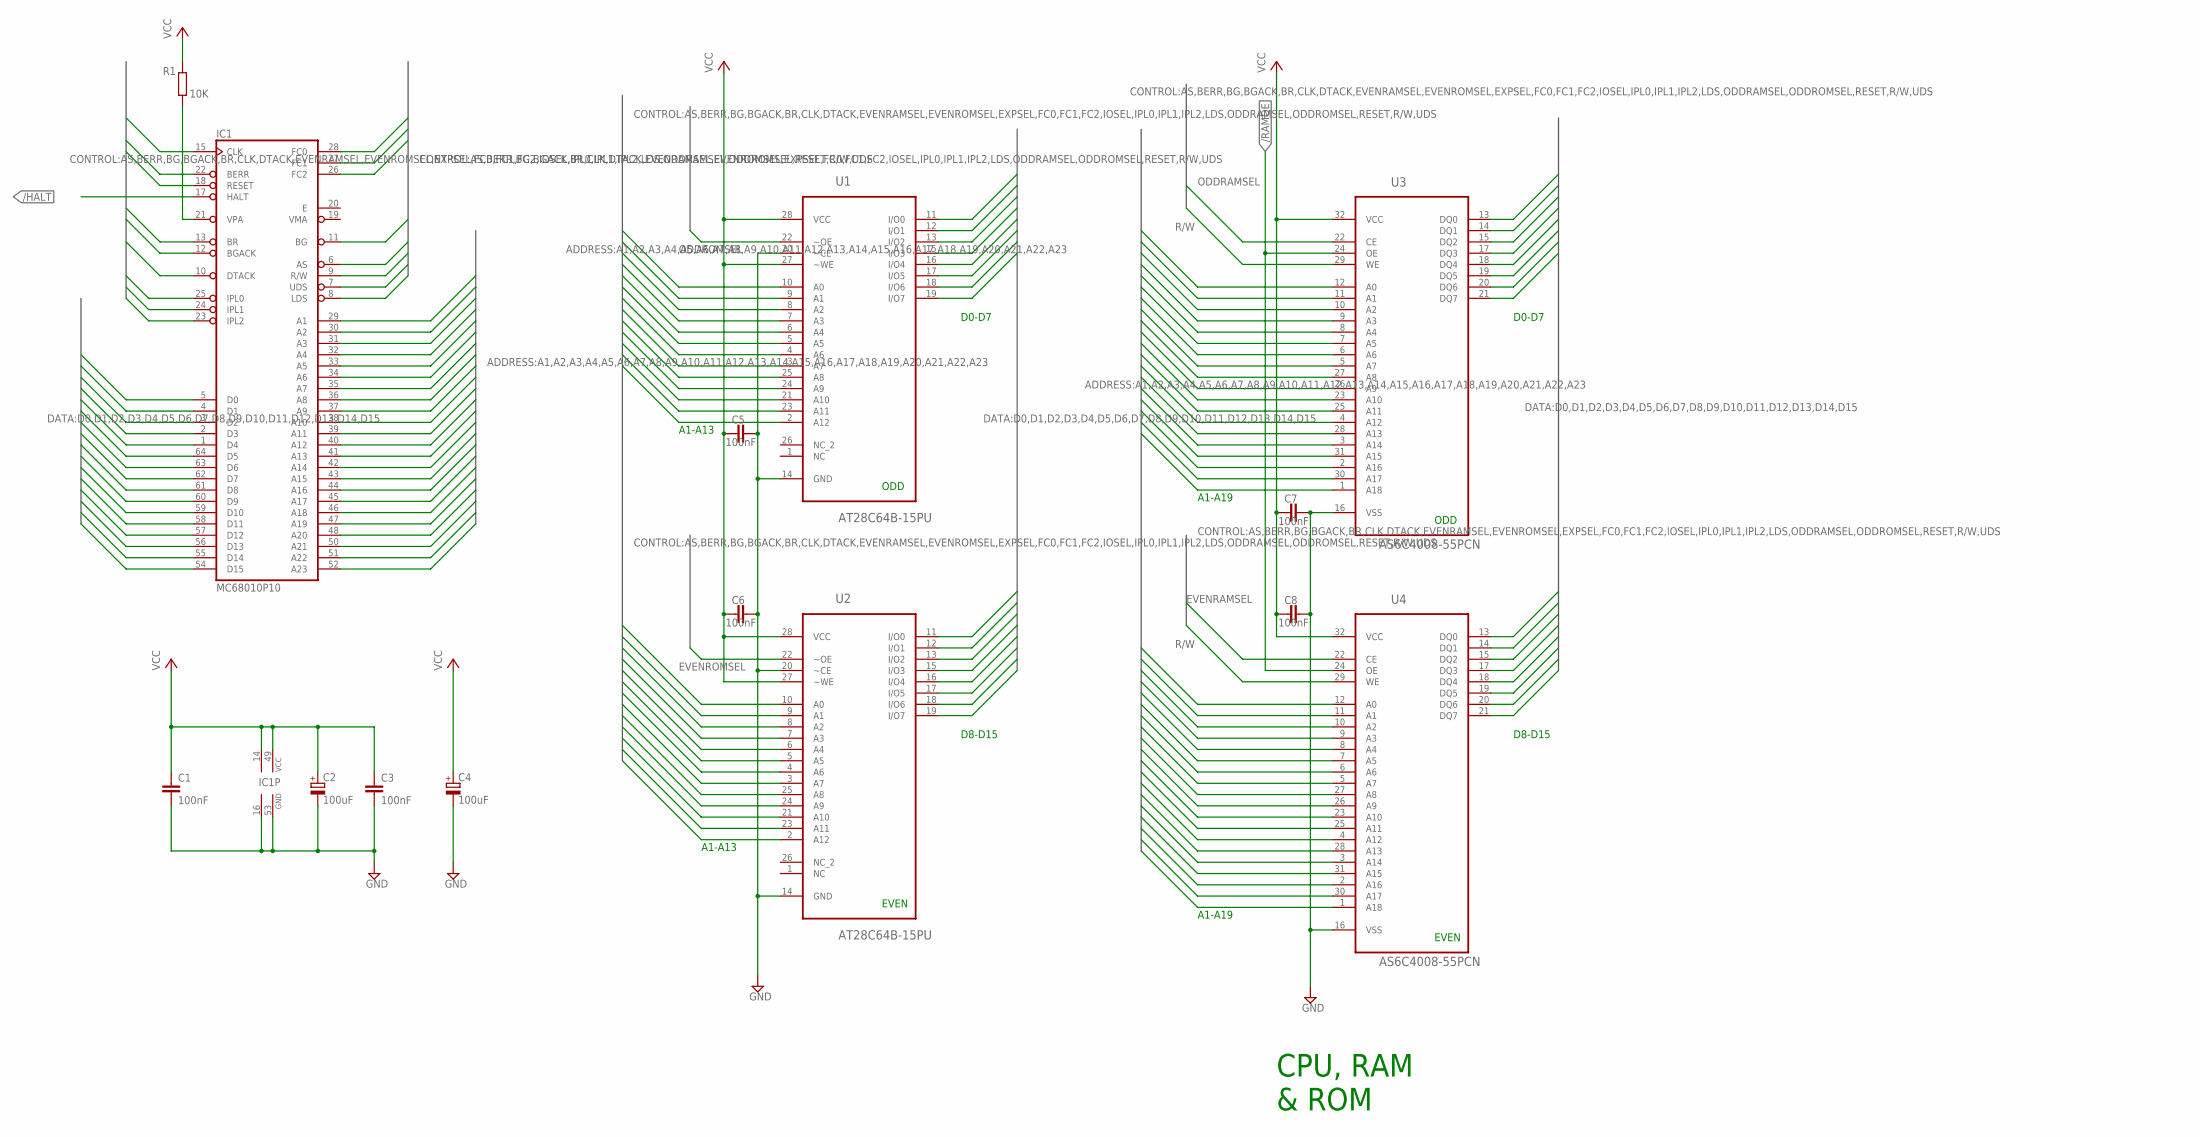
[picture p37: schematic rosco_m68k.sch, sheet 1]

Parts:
C1, C3, C5, C6, C7, C8: 100nF; C2.5-3
C2, C4: 100uF; E2,5-5
IC1: MC68010P10; DIL64
R1: 10K; 0207/10
U1, U2: AT28C64B-15PU; DIP254P1524X482-28
U3, U4: AS6C4008-55PCN; DIP254P1524X393-32

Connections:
/HALT: IC1.17 (HALT); also elsewhere on the board
/RAMOE: U3.24 (OE), U4.24 (OE); also elsewhere on the board
A1: IC1.29 (A1), U1.10 (A0), U2.10 (A0), U3.12 (A0), U4.12 (A0); also elsewhere on the board
A2: IC1.30 (A2), U1.9 (A1), U2.9 (A1), U3.11 (A1), U4.11 (A1); also elsewhere on the board
A3: IC1.31 (A3), U1.8 (A2), U2.8 (A2), U3.10 (A2), U4.10 (A2); also elsewhere on the board
A4: IC1.32 (A4), U1.7 (A3), U2.7 (A3), U3.9 (A3), U4.9 (A3); also elsewhere on the board
A5: IC1.33 (A5), U1.6 (A4), U2.6 (A4), U3.8 (A4), U4.8 (A4); also elsewhere on the board
A6: IC1.34 (A6), U1.5 (A5), U2.5 (A5), U3.7 (A5), U4.7 (A5); also elsewhere on the board
A7: IC1.35 (A7), U1.4 (A6), U2.4 (A6), U3.6 (A6), U4.6 (A6); also elsewhere on the board
A8: IC1.36 (A8), U1.3 (A7), U2.3 (A7), U3.5 (A7), U4.5 (A7); also elsewhere on the board
A9: IC1.37 (A9), U1.25 (A8), U2.25 (A8), U3.27 (A8), U4.27 (A8); also elsewhere on the board
A10: IC1.38 (A10), U1.24 (A9), U2.24 (A9), U3.26 (A9), U4.26 (A9); also elsewhere on the board
A11: IC1.39 (A11), U1.21 (A10), U2.21 (A10), U3.23 (A10), U4.23 (A10); also elsewhere on the board
A12: IC1.40 (A12), U1.23 (A11), U2.23 (A11), U3.25 (A11), U4.25 (A11); also elsewhere on the board
A13: IC1.41 (A13), U1.2 (A12), U2.2 (A12), U3.4 (A12), U4.4 (A12); also elsewhere on the board
A14: IC1.42 (A14), U3.28 (A13), U4.28 (A13); also elsewhere on the board
A15: IC1.43 (A15), U3.3 (A14), U4.3 (A14); also elsewhere on the board
A16: IC1.44 (A16), U3.31 (A15), U4.31 (A15); also elsewhere on the board
A17: IC1.45 (A17), U3.2 (A16), U4.2 (A16); also elsewhere on the board
A18: IC1.46 (A18), U3.30 (A17), U4.30 (A17); also elsewhere on the board
A19: IC1.47 (A19), U3.1 (A18), U4.1 (A18); also elsewhere on the board
A20: IC1.48 (A20); also elsewhere on the board
A21: IC1.50 (A21); also elsewhere on the board
A22: IC1.51 (A22); also elsewhere on the board
A23: IC1.52 (A23); also elsewhere on the board
AS: IC1.6 (AS); also elsewhere on the board
BERR: IC1.22 (BERR); also elsewhere on the board
BG: IC1.11 (BG); also elsewhere on the board
BGACK: IC1.12 (BGACK); also elsewhere on the board
BR: IC1.13 (BR); also elsewhere on the board
CLK: IC1.15 (CLK); also elsewhere on the board
D0: IC1.5 (D0), U1.11 (I/O0), U3.13 (DQ0); also elsewhere on the board
D1: IC1.4 (D1), U1.12 (I/O1), U3.14 (DQ1); also elsewhere on the board
D2: IC1.3 (D2), U1.13 (I/O2), U3.15 (DQ2); also elsewhere on the board
D3: IC1.2 (D3), U1.15 (I/O3), U3.17 (DQ3); also elsewhere on the board
D4: IC1.1 (D4), U1.16 (I/O4), U3.18 (DQ4); also elsewhere on the board
D5: IC1.64 (D5), U1.17 (I/O5), U3.19 (DQ5); also elsewhere on the board
D6: IC1.63 (D6), U1.18 (I/O6), U3.20 (DQ6); also elsewhere on the board
D7: IC1.62 (D7), U1.19 (I/O7), U3.21 (DQ7); also elsewhere on the board
D8: IC1.61 (D8), U2.11 (I/O0), U4.13 (DQ0); also elsewhere on the board
D9: IC1.60 (D9), U2.12 (I/O1), U4.14 (DQ1); also elsewhere on the board
D10: IC1.59 (D10), U2.13 (I/O2), U4.15 (DQ2); also elsewhere on the board
D11: IC1.58 (D11), U2.15 (I/O3), U4.17 (DQ3); also elsewhere on the board
D12: IC1.57 (D12), U2.16 (I/O4), U4.18 (DQ4); also elsewhere on the board
D13: IC1.56 (D13), U2.17 (I/O5), U4.19 (DQ5); also elsewhere on the board
D14: IC1.55 (D14), U2.18 (I/O6), U4.20 (DQ6); also elsewhere on the board
D15: IC1.54 (D15), U2.19 (I/O7), U4.21 (DQ7); also elsewhere on the board
DTACK: IC1.10 (DTACK); also elsewhere on the board
EVENRAMSEL: U4.22 (CE); also elsewhere on the board
EVENROMSEL: U2.22 (~OE); also elsewhere on the board
FC0: IC1.28 (FC0); also elsewhere on the board
FC1: IC1.27 (FC1); also elsewhere on the board
FC2: IC1.26 (FC2); also elsewhere on the board
GND: C1.2, C2.-, C3.2, C4.-, C5.2, C6.2, C7.2, C8.2, IC1.16 (GND), IC1.53 (GND), U1.14 (GND), U1.20 (~CE), U2.14 (GND), U2.20 (~CE), U3.16 (VSS), U4.16 (VSS); also elsewhere on the board
IPL0: IC1.25 (IPL0); also elsewhere on the board
IPL1: IC1.24 (IPL1); also elsewhere on the board
IPL2: IC1.23 (IPL2); also elsewhere on the board
LDS: IC1.8 (LDS); also elsewhere on the board
ODDRAMSEL: U3.22 (CE); also elsewhere on the board
ODDROMSEL: U1.22 (~OE); also elsewhere on the board
R/W: IC1.9 (R/W), U3.29 (WE), U4.29 (WE); also elsewhere on the board
RESET: IC1.18 (RESET); also elsewhere on the board
UDS: IC1.7 (UDS); also elsewhere on the board
VCC: C1.1, C2.+, C3.1, C4.+, C5.1, C6.1, C7.1, C8.1, IC1.14 (VCC), IC1.49 (VCC), R1.2, U1.27 (~WE), U1.28 (VCC), U2.27 (~WE), U2.28 (VCC), U3.32 (VCC), U4.32 (VCC); also elsewhere on the board
VPA: IC1.21 (VPA), R1.1

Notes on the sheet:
ODD
EVEN
D0-D7
D8-D15
A1-A13
A1-A19
CPU, RAM & ROM

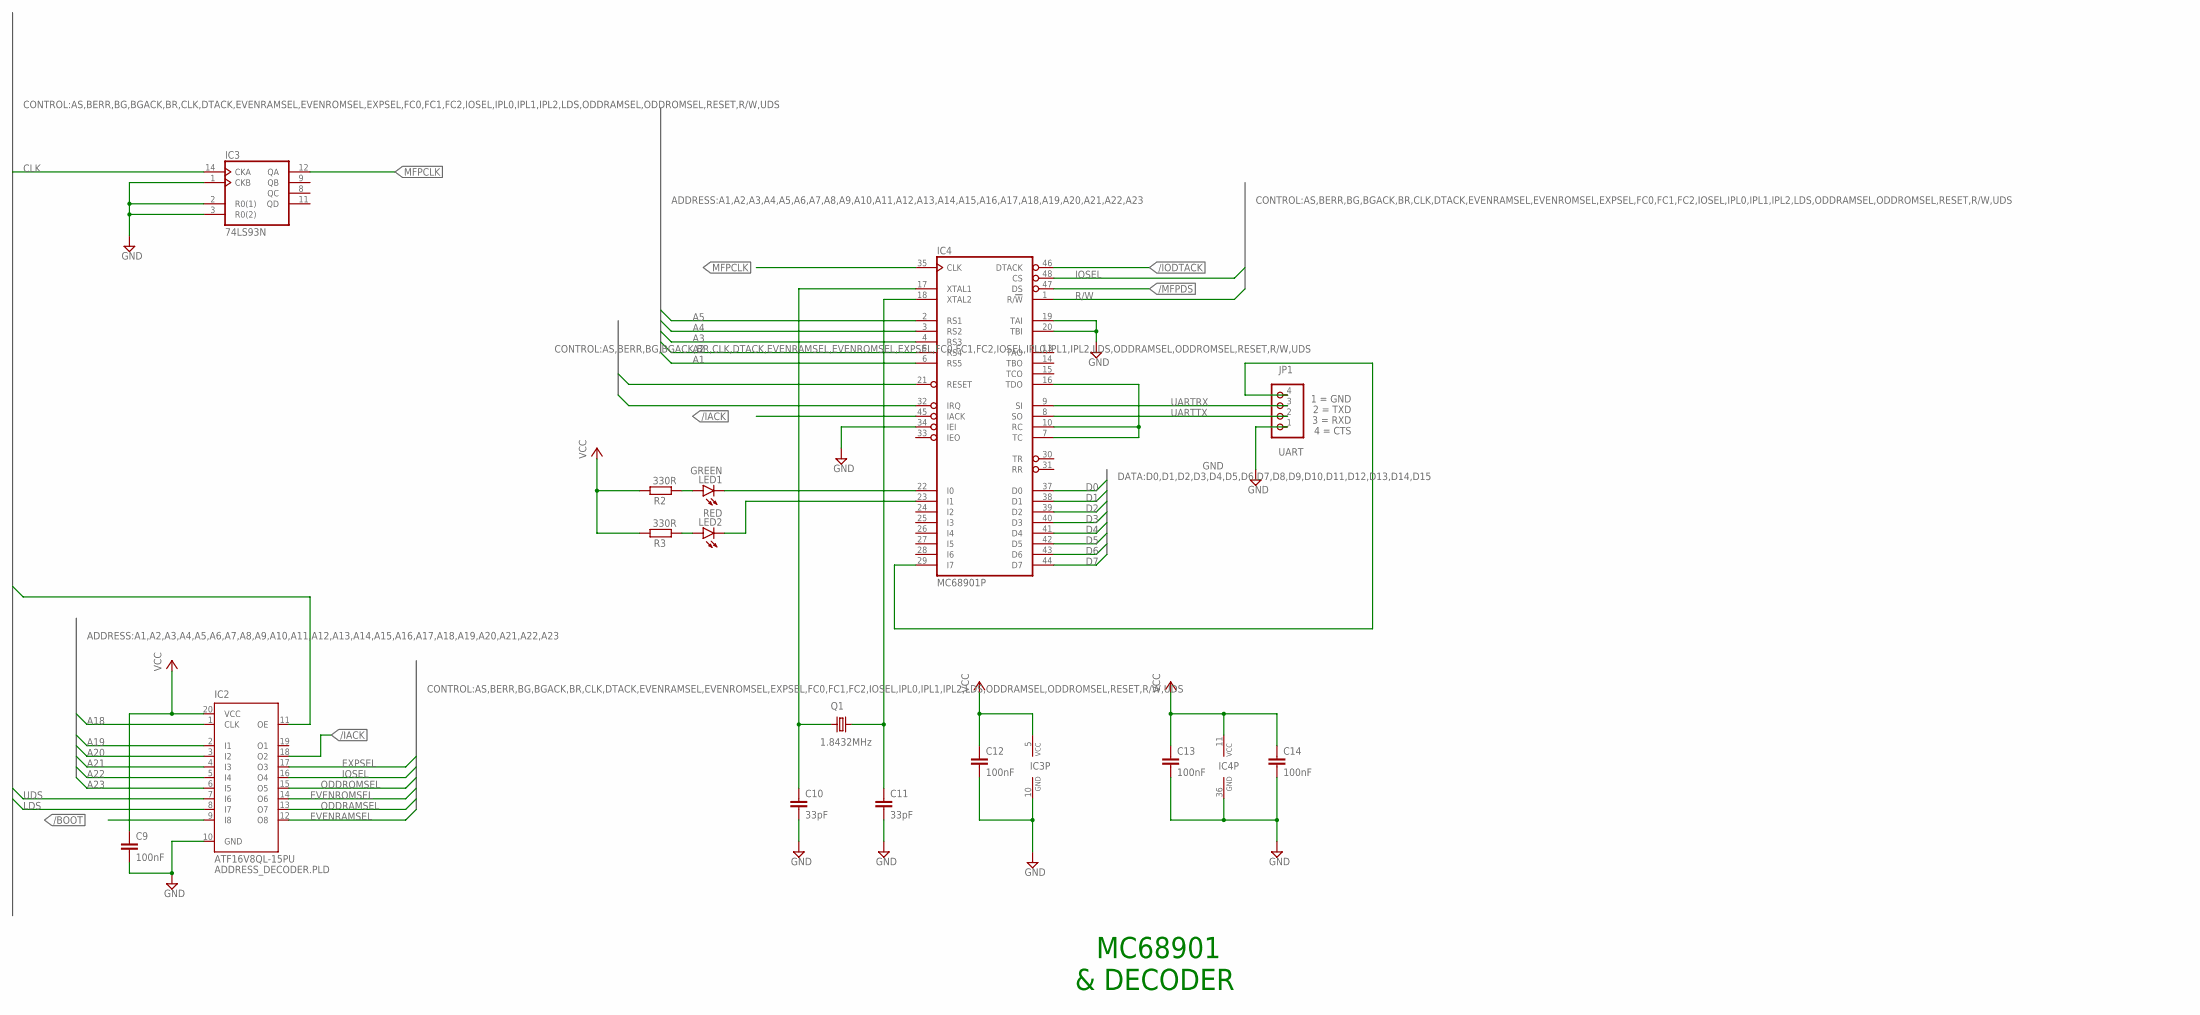
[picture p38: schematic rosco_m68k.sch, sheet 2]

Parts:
C9, C12, C13, C14: 100nF; C2.5-3
C10, C11: 33pF; C2.5-3
IC2: ATF16V8QL-15PU; DIL20; MPN ATF16V8QL-15PU
IC3: 74LS93N; DIL14
IC4: MC68901P; DIL48
JP1: UART; 1X04
LED1: GREEN; LED5MM
LED2: RED; LED5MM
Q1: 1.8432MHz; HC49/S
R2, R3: 330R; 0207/10

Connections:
/BOOT: IC2.9 (I8); also elsewhere on the board
/IACK: IC2.18 (O2), IC4.45 (IACK); also elsewhere on the board
/IODTACK: IC4.46 (DTACK); also elsewhere on the board
/MFPDS: IC4.47 (DS); also elsewhere on the board
A1: IC4.6 (RS5); also elsewhere on the board
A2: IC4.5 (RS4); also elsewhere on the board
A3: IC4.4 (RS3); also elsewhere on the board
A4: IC4.3 (RS2); also elsewhere on the board
A5: IC4.2 (RS1); also elsewhere on the board
A18: IC2.1 (CLK); also elsewhere on the board
A19: IC2.2 (I1); also elsewhere on the board
A20: IC2.3 (I2); also elsewhere on the board
A21: IC2.4 (I3); also elsewhere on the board
A22: IC2.5 (I4); also elsewhere on the board
A23: IC2.6 (I5); also elsewhere on the board
AS: IC2.11 (OE); also elsewhere on the board
CLK: IC3.14 (CKA); also elsewhere on the board
D0: IC4.37 (D0); also elsewhere on the board
D1: IC4.38 (D1); also elsewhere on the board
D2: IC4.39 (D2); also elsewhere on the board
D3: IC4.40 (D3); also elsewhere on the board
D4: IC4.41 (D4); also elsewhere on the board
D5: IC4.42 (D5); also elsewhere on the board
D6: IC4.43 (D6); also elsewhere on the board
D7: IC4.44 (D7); also elsewhere on the board
EVENRAMSEL: IC2.12 (O8); also elsewhere on the board
EVENROMSEL: IC2.14 (O6); also elsewhere on the board
EXPSEL: IC2.17 (O3); also elsewhere on the board
GND: C9.2, C10.2, C11.2, C12.2, C13.2, C14.2, IC2.10 (GND), IC3.1 (CKB), IC3.2 (R0(1)), IC3.3 (R0(2)), IC3.10 (GND), IC4.19 (TAI), IC4.20 (TBI), IC4.34 (IEI), IC4.36 (GND), JP1.1; also elsewhere on the board
IOSEL: IC2.16 (O4), IC4.48 (CS); also elsewhere on the board
IPL2: IC4.32 (IRQ); also elsewhere on the board
LDS: IC2.8 (I7); also elsewhere on the board
MFPCLK: IC3.12 (QA), IC4.35 (CLK)
MFPIO0: IC4.22 (I0), LED1.K (C)
MFPIO1: IC4.23 (I1), LED2.K (C)
MFPXTAL1: C10.1, IC4.17 (XTAL1), Q1.1
MFPXTAL2: C11.1, IC4.18 (XTAL2), Q1.2
unnamed: LED2.A, R3.1
unnamed: LED1.A, R2.1
ODDRAMSEL: IC2.13 (O7); also elsewhere on the board
ODDROMSEL: IC2.15 (O5); also elsewhere on the board
R/W: IC4.1 (R/!W); also elsewhere on the board
RESET: IC4.21 (RESET); also elsewhere on the board
UARTCLK: IC4.7 (TC), IC4.10 (RC), IC4.16 (TDO)
UARTCTS: IC4.29 (I7), JP1.4
UARTRX: IC4.9 (SI), JP1.3
UARTTX: IC4.8 (SO), JP1.2
UDS: IC2.7 (I6); also elsewhere on the board
VCC: C9.1, C12.1, C13.1, C14.1, IC2.20 (VCC), IC3.5 (VCC), IC4.11 (VCC), R2.2, R3.2; also elsewhere on the board

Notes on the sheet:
MC68901
& DECODER

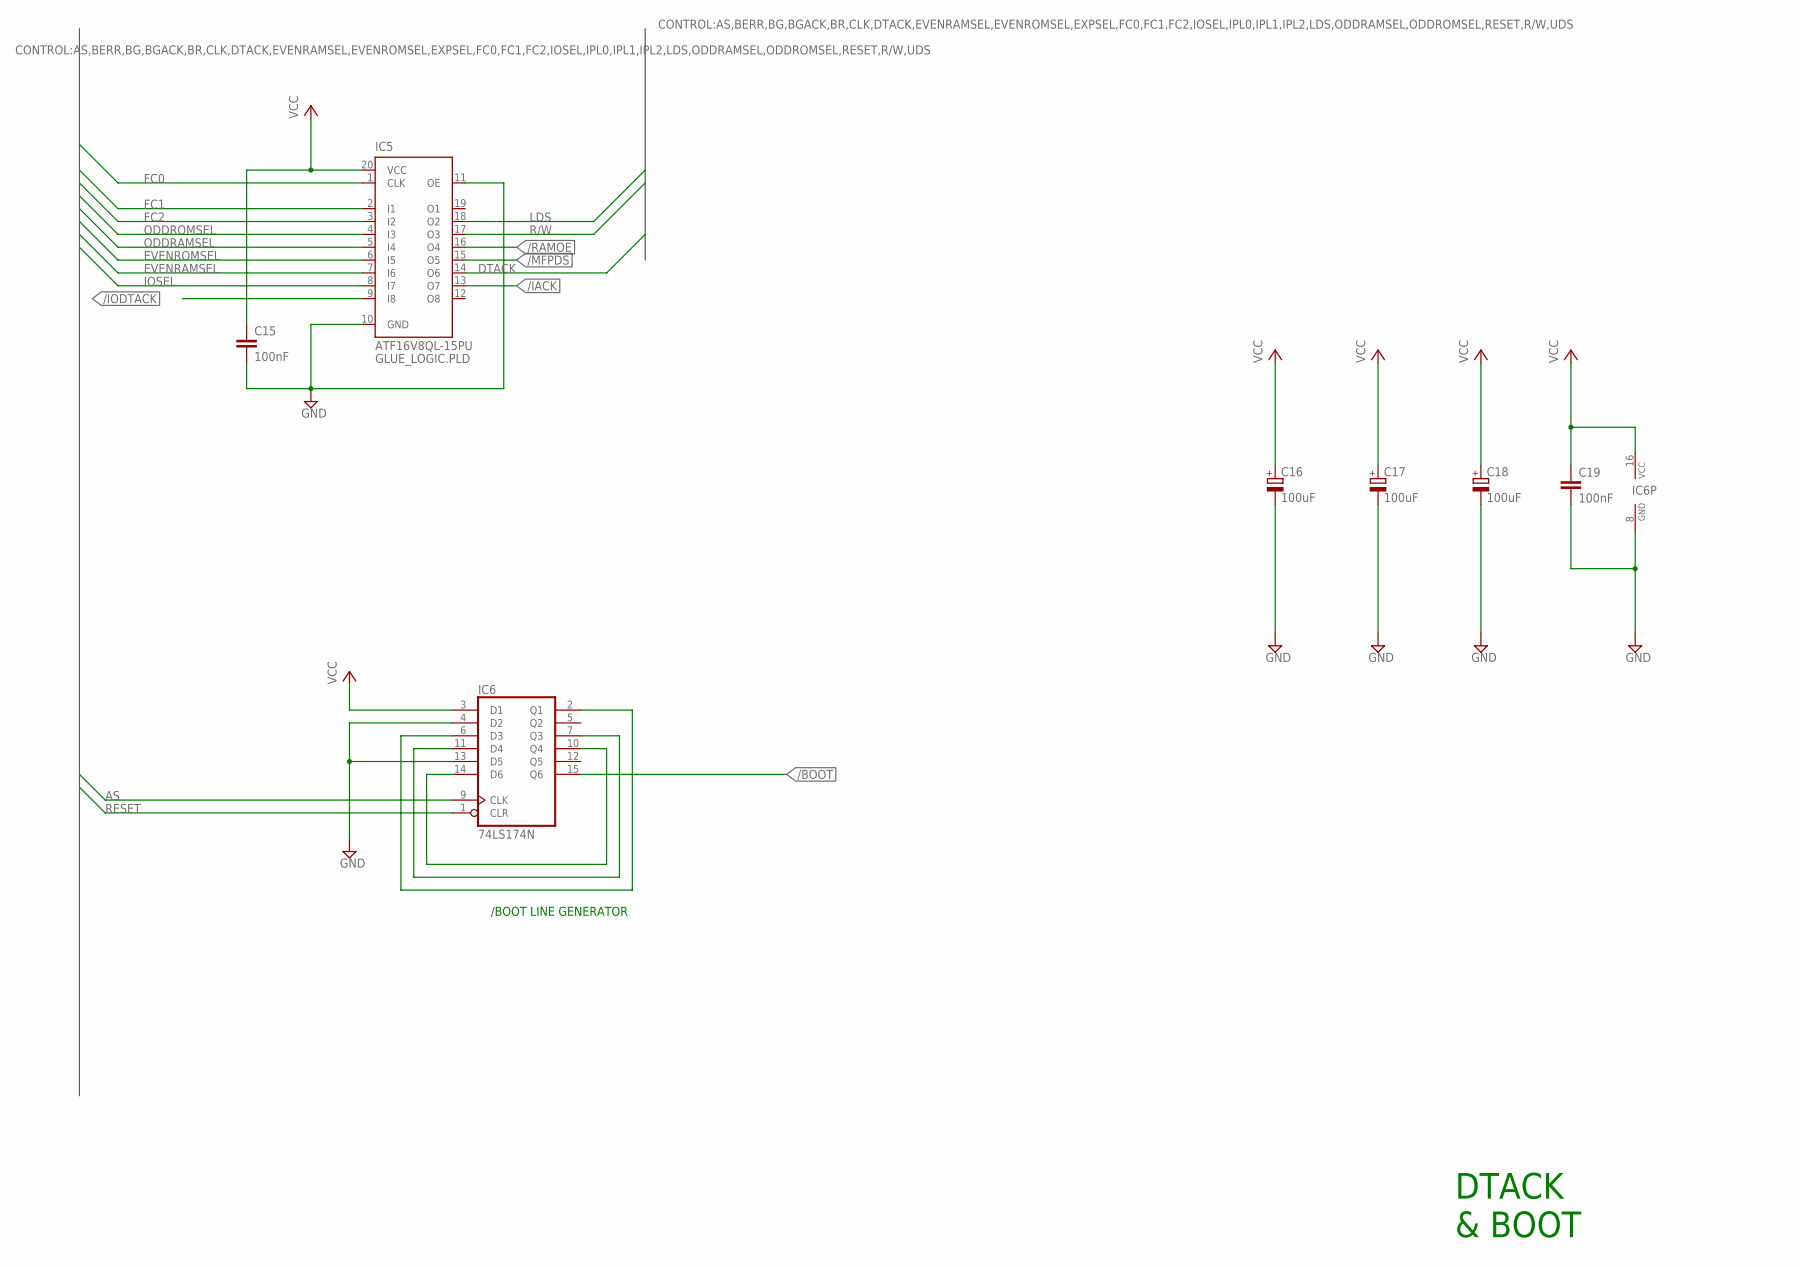
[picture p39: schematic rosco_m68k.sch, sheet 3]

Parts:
C15, C19: 100nF; C2.5-3
C16, C17, C18: 100uF; E2,5-5
IC5: ATF16V8QL-15PU; DIL20; MPN ATF16V8QL-15PU
IC6: 74LS174N; DIL16

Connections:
/BOOT: IC6.15 (Q6); also elsewhere on the board
/IACK: IC5.13 (O7); also elsewhere on the board
/IODTACK: IC5.9 (I8); also elsewhere on the board
/MFPDS: IC5.15 (O5); also elsewhere on the board
/RAMOE: IC5.16 (O4); also elsewhere on the board
AS: IC6.9 (CLK); also elsewhere on the board
DTACK: IC5.14 (O6); also elsewhere on the board
EVENRAMSEL: IC5.7 (I6); also elsewhere on the board
EVENROMSEL: IC5.6 (I5); also elsewhere on the board
FC0: IC5.1 (CLK); also elsewhere on the board
FC1: IC5.2 (I1); also elsewhere on the board
FC2: IC5.3 (I2); also elsewhere on the board
GND: C15.2, C16.-, C17.-, C18.-, C19.2, IC5.10 (GND), IC5.11 (OE), IC6.4 (D2), IC6.8 (GND), IC6.13 (D5); also elsewhere on the board
IOSEL: IC5.8 (I7); also elsewhere on the board
LDS: IC5.18 (O2); also elsewhere on the board
unnamed: IC6.7 (Q3), IC6.11 (D4)
unnamed: IC6.10 (Q4), IC6.14 (D6)
unnamed: IC6.2 (Q1), IC6.6 (D3)
ODDRAMSEL: IC5.5 (I4); also elsewhere on the board
ODDROMSEL: IC5.4 (I3); also elsewhere on the board
R/W: IC5.17 (O3); also elsewhere on the board
RESET: IC6.1 (CLR); also elsewhere on the board
VCC: C15.1, C16.+, C17.+, C18.+, C19.1, IC5.20 (VCC), IC6.3 (D1), IC6.16 (VCC); also elsewhere on the board

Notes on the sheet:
/BOOT LINE GENERATOR
DTACK & BOOT

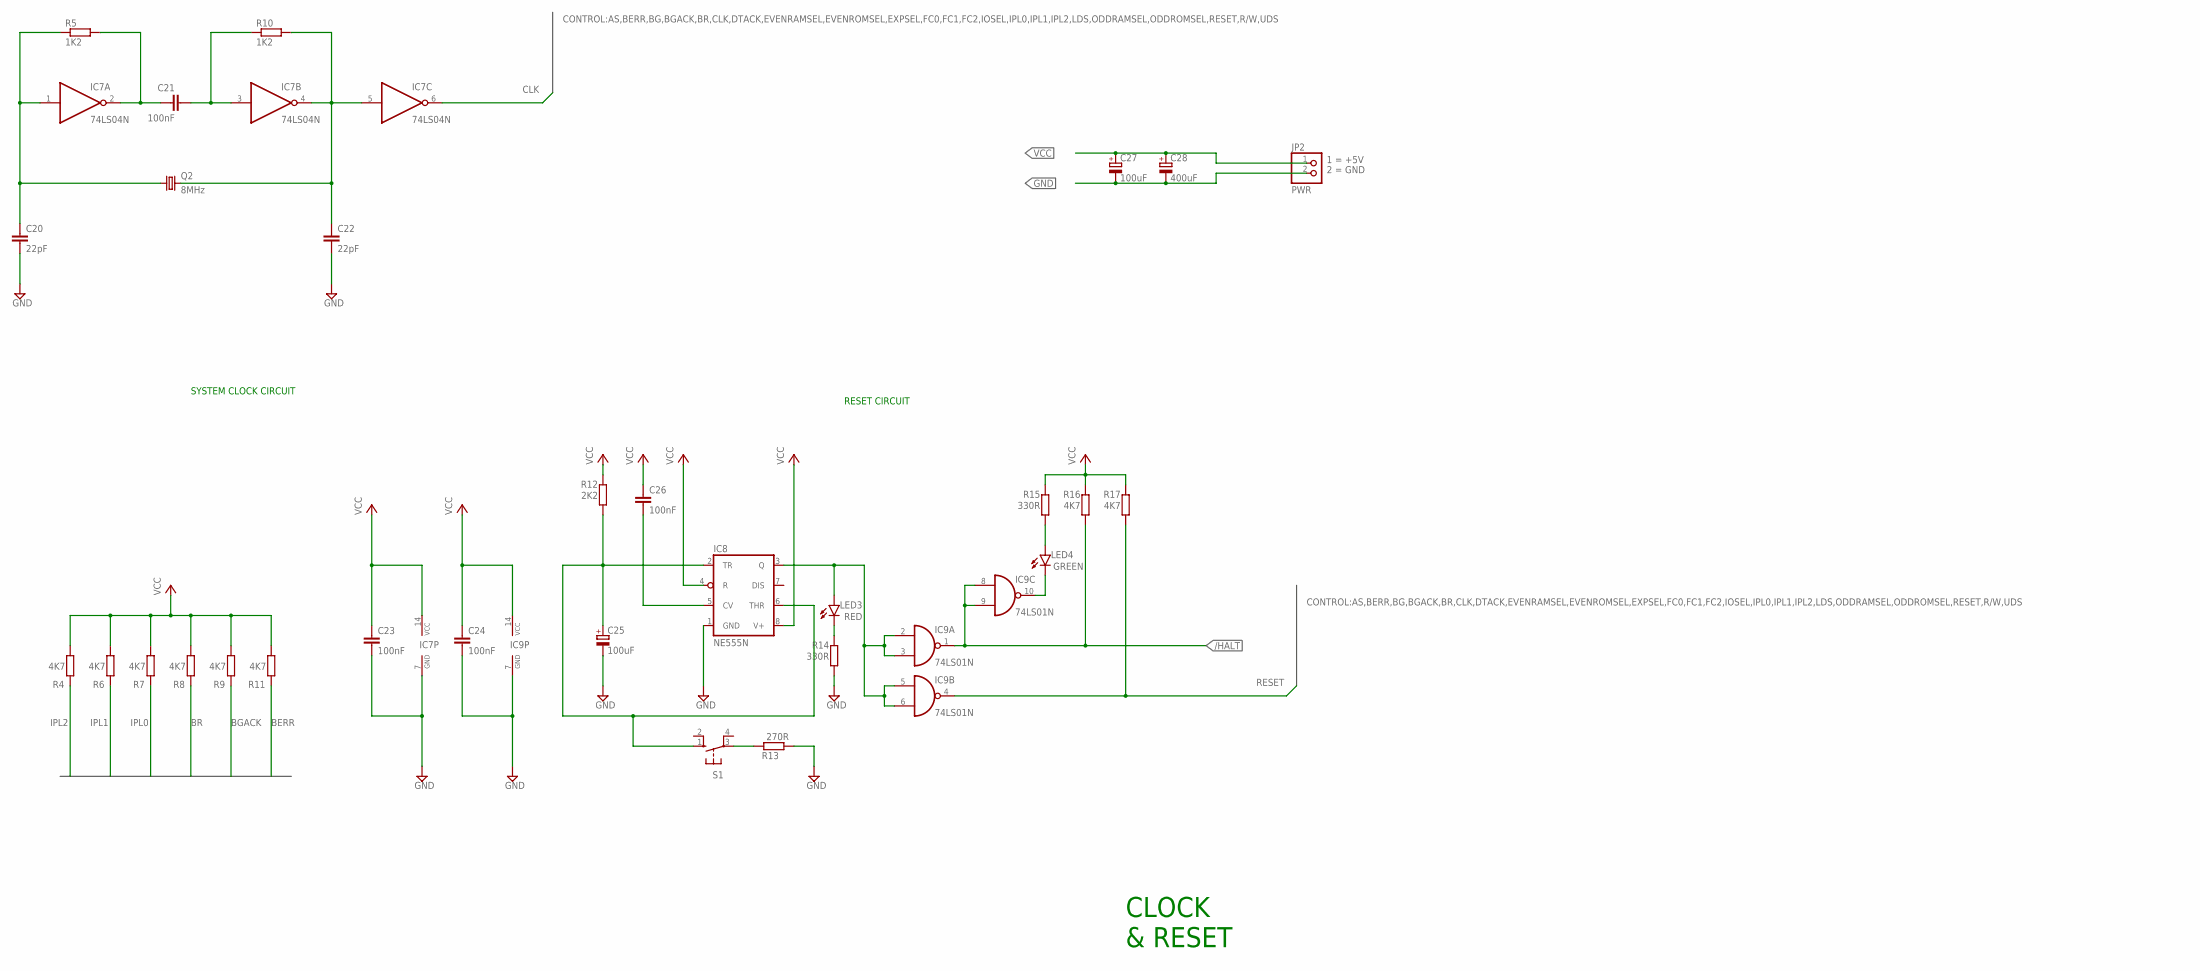
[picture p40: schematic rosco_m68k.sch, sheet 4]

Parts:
C20, C22: 22pF; C2.5-3
C21, C23, C24, C26: 100nF; C2.5-3
C25, C27: 100uF; E2,5-5
C28: 400uF; E3,5-10
IC7: 74LS04N; DIL14
IC8: NE555N; DIL08
IC9: 74LS01N; DIL14
JP2: PWR; 1X02
LED3: RED; LED5MM
LED4: GREEN; LED5MM
Q2: 8MHz; HC49/S
R4, R6, R7, R8, R9, R11, R16, R17: 4K7; 0207/10
R5, R10: 1K2; 0207/10
R12: 2K2; 0207/10
R13: 270R; 0207/10
R14, R15: 330R; 0207/10
S1: 10-XX; B3F-10XX

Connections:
/HALT: IC9.1 (O), IC9.8 (I0), IC9.9 (I1), R16.1; also elsewhere on the board
BERR: R11.1; also elsewhere on the board
BGACK: R9.1; also elsewhere on the board
BR: R8.1; also elsewhere on the board
CLK: IC7.6 (O); also elsewhere on the board
GND: C20.2, C22.2, C23.2, C24.2, C25.-, C27.-, C28.-, IC7.7 (GND), IC8.1 (GND), IC9.7 (GND), JP2.2, R13.1, R14.1; also elsewhere on the board
IPL0: R7.1; also elsewhere on the board
IPL1: R6.1; also elsewhere on the board
IPL2: R4.1; also elsewhere on the board
unnamed: C21.1, IC7.2 (O), R5.2
unnamed: C21.2, IC7.3 (I), R10.1
unnamed: C22.1, IC7.4 (O), IC7.5 (I), Q2.2, R10.2
unnamed: C20.1, IC7.1 (I), Q2.1, R5.1
unnamed: C26.2, IC8.5 (CV)
unnamed: LED3.K (C), R14.2
unnamed: IC9.10 (O), LED4.K (C)
unnamed: LED4.A, R15.1
unnamed: IC8.3 (Q), IC9.2 (I0), IC9.3 (I1), IC9.5 (I0), IC9.6 (I1), LED3.A
unnamed: R13.2, S1.3
unnamed: C25.+, IC8.2 (TR), IC8.6 (THR), R12.1, S1.1 (S)
RESET: IC9.4 (O), R17.1; also elsewhere on the board
VCC: C23.1, C24.1, C26.1, C27.+, C28.+, IC7.14 (VCC), IC8.4 (R), IC8.8 (V+), IC9.14 (VCC), JP2.1, R4.2, R6.2, R7.2, R8.2, R9.2, R11.2, R12.2, R15.2, R16.2, R17.2; also elsewhere on the board

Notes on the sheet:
RESET CIRCUIT
SYSTEM CLOCK CIRCUIT
CLOCK & RESET

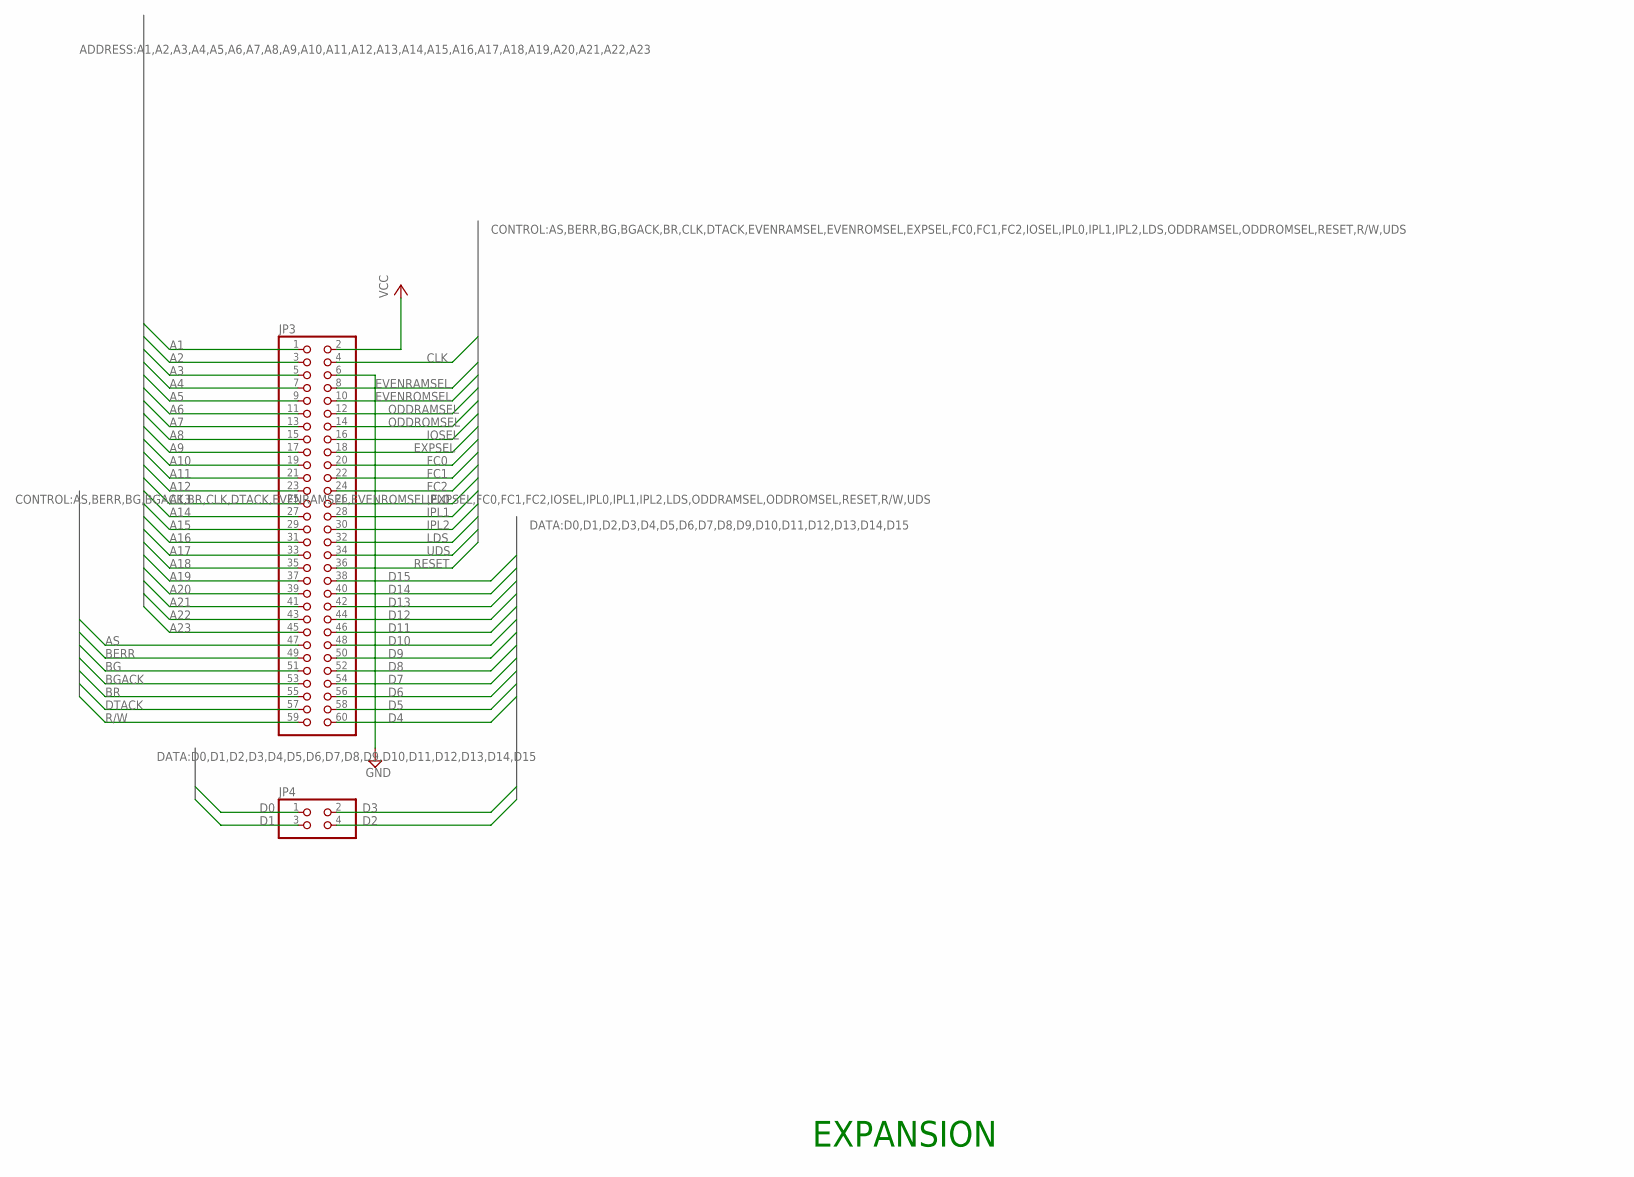
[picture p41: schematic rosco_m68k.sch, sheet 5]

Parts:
JP3: PINHD-2X30; 2X30
JP4: PINHD-2X2; 2X02

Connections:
A1: JP3.1; also elsewhere on the board
A2: JP3.3; also elsewhere on the board
A3: JP3.5; also elsewhere on the board
A4: JP3.7; also elsewhere on the board
A5: JP3.9; also elsewhere on the board
A6: JP3.11; also elsewhere on the board
A7: JP3.13; also elsewhere on the board
A8: JP3.15; also elsewhere on the board
A9: JP3.17; also elsewhere on the board
A10: JP3.19; also elsewhere on the board
A11: JP3.21; also elsewhere on the board
A12: JP3.23; also elsewhere on the board
A13: JP3.25; also elsewhere on the board
A14: JP3.27; also elsewhere on the board
A15: JP3.29; also elsewhere on the board
A16: JP3.31; also elsewhere on the board
A17: JP3.33; also elsewhere on the board
A18: JP3.35; also elsewhere on the board
A19: JP3.37; also elsewhere on the board
A20: JP3.39; also elsewhere on the board
A21: JP3.41; also elsewhere on the board
A22: JP3.43; also elsewhere on the board
A23: JP3.45; also elsewhere on the board
AS: JP3.47; also elsewhere on the board
BERR: JP3.49; also elsewhere on the board
BG: JP3.51; also elsewhere on the board
BGACK: JP3.53; also elsewhere on the board
BR: JP3.55; also elsewhere on the board
CLK: JP3.4; also elsewhere on the board
D0: JP4.1; also elsewhere on the board
D1: JP4.3; also elsewhere on the board
D2: JP4.4; also elsewhere on the board
D3: JP4.2; also elsewhere on the board
D4: JP3.60; also elsewhere on the board
D5: JP3.58; also elsewhere on the board
D6: JP3.56; also elsewhere on the board
D7: JP3.54; also elsewhere on the board
D8: JP3.52; also elsewhere on the board
D9: JP3.50; also elsewhere on the board
D10: JP3.48; also elsewhere on the board
D11: JP3.46; also elsewhere on the board
D12: JP3.44; also elsewhere on the board
D13: JP3.42; also elsewhere on the board
D14: JP3.40; also elsewhere on the board
D15: JP3.38; also elsewhere on the board
DTACK: JP3.57; also elsewhere on the board
EVENRAMSEL: JP3.8; also elsewhere on the board
EVENROMSEL: JP3.10; also elsewhere on the board
EXPSEL: JP3.18; also elsewhere on the board
FC0: JP3.20; also elsewhere on the board
FC1: JP3.22; also elsewhere on the board
FC2: JP3.24; also elsewhere on the board
GND: JP3.6; also elsewhere on the board
IOSEL: JP3.16; also elsewhere on the board
IPL0: JP3.26; also elsewhere on the board
IPL1: JP3.28; also elsewhere on the board
IPL2: JP3.30; also elsewhere on the board
LDS: JP3.32; also elsewhere on the board
ODDRAMSEL: JP3.12; also elsewhere on the board
ODDROMSEL: JP3.14; also elsewhere on the board
R/W: JP3.59; also elsewhere on the board
RESET: JP3.36; also elsewhere on the board
UDS: JP3.34; also elsewhere on the board
VCC: JP3.2; also elsewhere on the board

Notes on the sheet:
EXPANSION


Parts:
IC7: 74LS04N; DIL14
IC9: 74LS01N; DIL14

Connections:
GND: IC7.9 (I), IC7.11 (I), IC7.13 (I), IC9.11 (I0), IC9.12 (I1); also elsewhere on the board

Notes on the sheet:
UNUSED GATES


Board: 4 copper layers, 160.0 x 100.0 mm, 70 parts (0 on the bottom side), 96 nets.

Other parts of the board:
U$1: OSHW_8MM

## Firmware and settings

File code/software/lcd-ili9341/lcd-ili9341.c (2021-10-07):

/*
 * vim: set et ts=2 sw=2
 *------------------------------------------------------------
 *                                  ___ ___ _
 *  ___ ___ ___ ___ ___       _____|  _| . | |_
 * |  _| . |_ -|  _| . |     |     | . | . | '_|
 * |_| |___|___|___|___|_____|_|_|_|___|___|_,_|
 *                     |_____|
 * ------------------------------------------------------------
 * Copyright (c) 2020 Xark
 * MIT License
 * ------------------------------------------------------------
 */

// This is the rosco_m68k re-mixed version of Adafruit's library.
// Not a huge amount of code left from the Adafruit library, but
// it was helpful and here is the original copyright notice:

/***************************************************
  This is an Arduino Library for the Adafruit 2.2" SPI display.
  This library works with the Adafruit 2.2" TFT Breakout w/SD card
  ----> http://www.adafruit.com/products/1480

  Check out the links above for our tutorials and wiring diagrams
  These displays use SPI to communicate, 4 or 5 pins are required to
  interface (RST is optional)
  Adafruit invests time and resources providing this open source code,
  please support Adafruit and open-source hardware by purchasing
  products from Adafruit!

  Written by Limor Fried/Ladyada for Adafruit Industries.
  MIT license, all text above must be included in any redistribution
 ****************************************************/

// You can help support Adafruit by buying one of their LCD modules. I believe
// this code is compatible with the "SPI mode" of these:
// 2.4" TFT LCD Breakout - https://www.adafruit.com/product/2478
// 2.8" TFT LCD Breakout - https://www.adafruit.com/product/1770
// 3.2" TFT LCD Breakout - https://www.adafruit.com/product/1743

#include <basicio.h>
#include <gpio.h>
#include <machine.h>
#include <stdint.h>
#include <stdlib.h>

// Include GPIO SPI routines
// NOTE: SPI_FAST makes SPI routines inline (can bloat code size)
#define SPI_FAST
#include <gpio_spi.h>

#include "lcd-ili9341.h"        // definitions for ILI9341 LCD

#include "rle_images.h"        // test image data (created by images/Makefile)

// define INLINE as nothing to trade some speed for size
#define INLINE inline

// LCD modules: Most generic modules SPI LCD 320x240x16-bit color modules that
// use ILI9341 or ILI9342.
//
// I believe ILI9341 vs ILI9342 is default of 240x320 or 320x240, but the
// orientation can be changed in software anyways.
//
// The module I am using is fairly common 2.2" ILI9341 SPI TFT LCD with a 9
// pin connector (and an additional SD card connection that is not used).
// Other pinouts are common and can work fine also.
//
// Here is a good reference similar to the one I am using:
// http://www.lcdwiki.com/2.2inch_SPI_Module_ILI9341_SKU:MSP2202
//
// GPIO pin definitions for the LCD module I am using:
// 1          | VCC      | 5V / 3.3V power input        | VCC         |
// 2          | GND      | Ground                       | GND         |
// 3          | CS       | Chip select (active low)     | J5-P1 GPIO1 |
// 4          | RESET    | LCD reset (active low)       | J3-P36 RESET| *
// 5          | DC/RS    | Data/command register select | J5-P9 GPIO5 |
// 6          | COPI     | SPI data write to LCD        | J5-P5 GPIO3 |
// 7          | SCK      | SPI clock signal             | J5-P3 GPIO2 |
// 8          | LED      | LED backlight pin            | VCC         |
// 9          | CIPO     | SPI data read from LCD       | J5-P7 GPIO4 |
//
// * RESET signal is optional (there is software reset sequence)

// number of elements in C array
#define ELEMENTS(a) ((int)(sizeof(a) / sizeof(*a)))

// macro for easier MFP register access (read or write)
#define MFP(reg) (*(volatile uint8_t *)MFP_##reg)

// wait for ms milliseconds (with granularity of 10 ms, rounded up)
static void delayms(uint32_t ms)
{
    uint16_t ms10 = (uint16_t)(ms + 9) / (uint16_t)10U;
    mcDelaymsec10(ms10);
}

// timer helpers
static uint32_t start_tick;
void            timer_start()
{
    uint32_t ts = _TIMER_100HZ;
    uint32_t t;
    while ((t = _TIMER_100HZ) == ts)
        ;
    start_tick = t;
}

uint32_t timer_stop()
{
    uint32_t stop_tick = _TIMER_100HZ;

    return (stop_tick - start_tick) * 10;
}

// from https://stackoverflow.com/questions/21001659
unsigned int crc32b(unsigned char * message, int count)
{
    int          i, j;
    unsigned int byte, crc, mask;

    crc = 0xFFFFFFFF;
    for (i = 0; i < count; i++)
    {
        byte = message[i];        // Get next byte.
        crc  = crc ^ byte;
        for (j = 7; j >= 0; j--)
        {        // Do eight times.
            mask = -(crc & 1);
            crc  = (crc >> 1) ^ (0xEDB88320 & mask);
        }
    }
    return ~crc;
}

// LCD helpers
static inline uint16_t color565(uint32_t r, uint32_t g, uint32_t b)
{
    return ((r & 0xF8) << 8) | ((g & 0xFC) << 3) | (b >> 3);
}

// special LCD data/control register select (1/0)
#define LCD_DCRS_B GPIO5_B
#define LCD_DCRS   (1 << LCD_DCRS_B)

// initialize GPIO data-direction for SPI LCD
static inline void spi_init()
{
    // set data-direction for SPI signals (outputs, except CIPO)
    MFP(DDR) = (MFP(DDR) | SPI_CS | SPI_SCK | SPI_COPI | LCD_DCRS) & ~(SPI_CIPO);
}

// begin LCD command
static inline void lcd_begin_cmd()
{
    // CS selected (low)
    // LCD DCRS command mode (low)
    // SCK idle (high)
    // COPI one (high)
    MFP(GPDR) = (MFP(GPDR) | SPI_SCK | SPI_COPI) & ~(SPI_CS | LCD_DCRS);
}

// begin LCD data
static inline void lcd_begin()
{
    // CS selected (low)
    // LCD DCRS data mode (high)
    // SCK idle (high)
    // COPI one (high)
    MFP(GPDR) = (MFP(GPDR) | SPI_SCK | SPI_COPI | LCD_DCRS) & ~(SPI_CS);
}

// end LCD command/data
static inline void lcd_end()
{
    // CS de-selected (high)
    // LCD DCRS data mode (high)
    // SCK idle (high)
    // COPI one (high)
    MFP(GPDR) = (MFP(GPDR) | SPI_CS | SPI_SCK | SPI_COPI | LCD_DCRS);
}

// using macros here to allow testing/experimentation
#define SPI_SEND_BYTE(b)          spi_send_byte(b)
#define SPI_SEND_BUFFER(p, c)     spi_send_buffer(p, c)
#define SPI_READ_BYTE()           spi_read_byte()
#define SPI_READ_BUFFER(p, c)     spi_read_buffer(p, c)
#define SPI_EXCHANGE_BYTE(b)      spi_exchange_byte(b)
#define SPI_EXCHANGE_BUFFER(p, c) spi_exchange_buffer(p, c)

static INLINE void lcd_command(uint32_t byte)
{
    lcd_begin_cmd();            // cmd mode
    SPI_SEND_BYTE(byte);        // send command byte
    lcd_begin();                // data mode
}

static INLINE void lcd_write(uint32_t byte)
{
    SPI_SEND_BYTE(byte);
}

static INLINE void lcd_write16(uint32_t data)
{
    SPI_SEND_BYTE(data >> 8);
    SPI_SEND_BYTE(data);
}

static INLINE void lcd_write16_count(uint32_t data, int count)
{
    while (count-- > 0)
    {
        lcd_write16(data);
    }
}

// LCD control
static int16_t _width, _height;
static uint8_t _rotation;

// set rectangular data window
static void lcd_set_window(int x0, int y0, int x1, int y1)
{
    lcd_command(ILI9341_CASET);        // column address set
    lcd_write16(x0);                   // XSTART
    lcd_write16(x1);                   // XEND
    lcd_command(ILI9341_PASET);        // row address set
    lcd_write16(y0);                   // YSTART
    lcd_write16(y1);                   // YEND
    lcd_command(ILI9341_RAMWR);        // write to RAM
}

// set LCD orientation
static void lcd_set_rotation(int m)
{
    _rotation = (m & 3);        // can't be higher than 3

    lcd_command(ILI9341_MADCTL);

    switch (_rotation)
    {
        default:
        case 0:
            lcd_write(ILI9341_MADCTL_MX | ILI9341_MADCTL_BGR);
            _width  = ILI9341_TFTWIDTH;
            _height = ILI9341_TFTHEIGHT;
            break;
        case 1:
            lcd_write(ILI9341_MADCTL_MV | ILI9341_MADCTL_BGR);
            _width  = ILI9341_TFTHEIGHT;
            _height = ILI9341_TFTWIDTH;
            break;
        case 2:
            lcd_write(ILI9341_MADCTL_MY | ILI9341_MADCTL_BGR);
            _width  = ILI9341_TFTWIDTH;
            _height = ILI9341_TFTHEIGHT;
            break;
        case 3:
            lcd_write(ILI9341_MADCTL_MV | ILI9341_MADCTL_MY | ILI9341_MADCTL_MX | ILI9341_MADCTL_BGR);
            _width  = ILI9341_TFTHEIGHT;
            _height = ILI9341_TFTWIDTH;
            break;
    }

    lcd_set_window(0, 0, _width - 1, _height - 1);
}

// LCD vertical scroll (0-319)
void lcd_scroll(uint16_t y)
{
    lcd_command(ILI9341_VSCRSADD);
    lcd_write16(y);
}

// LCD scroll margin
void lcd_scrollmargin(uint16_t top, uint16_t bottom)
{
    // TFA+VSA+BFA must equal 320
    if (top + bottom <= ILI9341_TFTHEIGHT)
    {
        uint16_t middle = ILI9341_TFTHEIGHT - top + bottom;
        lcd_command(ILI9341_VSCRDEF);
        lcd_write16(top);
        lcd_write16(middle);
        lcd_write16(bottom);
    }
}

// sends "magic" commands to init display
static void lcd_init()
{
    // Initialization commands for ILI9341 screens
    static const uint8_t ILI9341_cmds[] = {
        ILI9341_SWRESET,
        DELAY,
        0xEF,
        3,
        0x03,
        0x80,
        0x02,
        0xCF,
        3,
        0x00,
        0xC1,
        0x30,
        0xED,
        4,
        0x64,
        0x03,
        0x12,
        0x81,
        0xE8,
        3,
        0x85,
        0x00,
        0x78,
        0xCB,
        5,
        0x39,
        0x2C,
        0x00,
        0x34,
        0x02,
        0xF7,
        1,
        0x20,
        0xEA,
        2,
        0x00,
        0x00,
        ILI9341_PWCTR1,
        1,           // power control
        0x23,        // VRH[5:0]
        ILI9341_PWCTR2,
        1,           // 10 power control
        0x10,        // SAP[2:0];BT[3:0]
        ILI9341_VMCTR1,
        2,        // VCM control
        0x3e,
        0x28,
        ILI9341_VMCTR2,
        1,        // VCM control2
        0x86,
        ILI9341_MADCTL,
        1,
        (ILI9341_MADCTL_MX),        // | ILI9341_MADCTL_BGR),
        ILI9341_VSCRSADD,
        2,
        0x00,
        0x00,
        ILI9341_PIXFMT,
        1,
        0x55,
        ILI9341_FRMCTR1,
        2,
        0x00,
        0x18,
        ILI9341_DFUNCTR,
        3,
        0x08,
        0x82,
        0x27,
        0xF2,
        1,        // Gamma Function Disable
        0x00,
        ILI9341_GAMMASET,
        1,        // Gamma curve selected
        0x01,
        ILI9341_GMCTRP1,
        15,        // Set Gamma
        0x0F,
        0x31,
        0x2B,
        0x0C,
        0x0E,
        0x08,
        0x4E,
        0xF1,
        0x37,
        0x07,
        0x10,
        0x03,
        0x0E,
        0x09,
        0x00,
        ILI9341_GMCTRN1,
        15,
        0x00,
        0x0E,
        0x14,
        0x03,
        0x11,
        0x07,
        0x31,
        0xC1,
        0x48,
        0x08,
        0x0F,
        0x0C,
        0x31,
        0x36,
        0x0F,
        ILI9341_SLPOUT,
        DELAY,
        ILI9341_DISPON,
        0,
    };

    lcd_end();

    const uint8_t * addr = &ILI9341_cmds[0];

    while (addr < &ILI9341_cmds[sizeof(ILI9341_cmds)])        // For each command...
    {
        uint8_t cmd = *addr++;            // read command
        lcd_command(cmd);                 // issue command
        uint8_t numArgs = *addr++;        // Number of args to follow
        if (numArgs == DELAY)
        {
            delayms(150);
        }
        else
        {
            while (numArgs--)        // For each argument...
            {
                uint8_t arg = *addr++;
                lcd_write(arg);        // Read, issue argument
            }
        }
    }

    lcd_set_rotation(0);

    lcd_end();
}

// LCD rectangle fill
void lcd_fill_rect(int x, int y, int w, int h, uint32_t color)
{
    // rudimentary clipping (drawChar w/big text requires this)
    if ((x >= _width) || (y >= _height))
        return;
    if (x < 0)
    {
        w += x;
        x = 0;
    }
    if (y < 0)
    {
        h += y;
        y = 0;
    }
    if ((x + w) > _width)
        w = _width - x;
    if ((y + h) > _height)
        h = _height - y;

    lcd_set_window(x, y, x + w - 1, _height);

    for (; h > 0; h--)
    {
        lcd_write16_count(color, w);
    }

    lcd_end();
}

uint8_t RGB888Buffer[320 * 240 * 3];

void lcd_readimage()
{
    lcd_set_rotation(1);

    lcd_command(ILI9341_CASET);        // column address set
    lcd_write16(0);                    // XSTART
    lcd_write16(_width - 1);           // XEND
    lcd_command(ILI9341_PASET);        // row address set
    lcd_write16(0);                    // YSTART
    lcd_write16(_height - 1);          // YEND
    lcd_command(ILI9341_RAMRD);        // read from RAM

    SPI_READ_BYTE();
    SPI_READ_BUFFER(RGB888Buffer, sizeof(RGB888Buffer));

    lcd_end();
}

int lcd_readscanline()
{
    lcd_command(ILI9341_GETSCAN);
    SPI_READ_BYTE();
    int r = SPI_READ_BYTE() << 8;
    r |= SPI_READ_BYTE();

    lcd_end();

    return r;
}

void testRGB(uint16_t * rgbimg)
{
    lcd_set_rotation(1);

    SPI_SEND_BUFFER(rgbimg, 320 * 240 * 2);

    lcd_end();
}

void testRLE1(uint8_t * rleimg, uint32_t backcolor, uint32_t forecolor)
{
    int32_t  total    = 0;
    int32_t  cnt      = 0;
    uint32_t curcolor = backcolor;
    uint32_t colorxor = backcolor ^ forecolor;

    const uint8_t * cmp = rleimg;

    lcd_set_rotation(1);

    while (total < (320 * 240))
    {
        cnt = *cmp++;
        if (cnt & 0x80)
            cnt = ((cnt & 0x7f) << 8) | *cmp++;

        lcd_write16_count(curcolor, cnt);
        curcolor ^= colorxor;
        total += cnt;
    }

    lcd_end();
}

void testRLE(uint16_t * p)
{
    static uint32_t color2;

    lcd_set_rotation(1);

    for (;;)
    {
        uint32_t color = *p++;
        color2         = color & ~0x0020;
        if (color != color2)
        {
            uint32_t count = *p++;
            if (count == 0xffff)
            {
                break;
            }
            lcd_write16_count(color2, count);
        }
        else
        {
            lcd_write16(color2);
        }
    }

    lcd_end();
}

static uint16_t colortable[] = {ILI9341_BLACK,
                                ILI9341_BLUE,
                                ILI9341_RED,
                                ILI9341_GREEN,
                                ILI9341_CYAN,
                                ILI9341_MAGENTA,
                                ILI9341_YELLOW,
                                ILI9341_WHITE};

int main(int argc, char ** argv)
{
    (void)argc;
    (void)argv;

    if (checkchar())
    {
        readchar();
    }

    delayms(250);        // give minicom a chance to load after kermit

    println("");
    println("*** TFT LCD Module Example ***");
    println("          by Xark");
    println("(built on " __DATE__ " at " __TIME__ ")");
    println("");
    print("rosco_m68k firmware version: ");
    printushort(_FIRMWARE_REV >> 16);
    print(".");
    printuchar(_FIRMWARE_REV >> 8);
    print(".");
    printuchar(_FIRMWARE_REV);
    println("");

    println("This is an example of using rosco_m68k GPIO to");
    println("control a common ILI9341/ILI9342 TFT LCD SPI");
    println("display module.");

    println("Initializing LCD...");

    spi_init();        // setup MFP GPIO port data-direction
    lcd_init();        // send initialization sequence to LCD module

    println("Done.  Now look at the LCD display. :)");
    println("");
    lcd_fill_rect((_width / 2) - 4, 0, 8, _height, ILI9341_GREEN);
    lcd_fill_rect(0, (_height / 2) - 4, _width, 8, ILI9341_GREEN);
    println("Press any key to exit.");
    println("");

    uint16_t hadcolor = 0;
    int      count    = 0;
    int      img      = 0;
    do
    {
        print("#");
        printuint(count);
        print(" Test:\"");
        print(image_name[img]);
        print("\" ");
        print(image_type[img] == 1 ? "RLE555" : image_type[img] == 2 ? "MONO" : "RGB");
        println("");

        print("  Draw...       ");
        timer_start();

        if (image_type[img] == 0)
            testRGB(image_data[img]);
        else if (image_type[img] == 1)
            testRLE(image_data[img]);
        else if (image_type[img] == 2)
        {
            testRLE1(image_data[img],
                     colortable[hadcolor % ELEMENTS(colortable)],
                     colortable[hadcolor + 1 % ELEMENTS(colortable)]);
            hadcolor++;
        }

        uint32_t ticks = timer_stop();

        print("  Time:");
        printuint(ticks);
        println(" ms");
        delayms(2000);

        if (checkchar())
        {
            break;
        }


#if 1        // smooth scroll test

        print("  Scroll...     ");
        timer_start();
        lcd_set_rotation(0);

        for (int s = 0; s < 320; s++)
        {
            int line1, line2;
            line1 = lcd_readscanline();
            do
            {
                line2 = lcd_readscanline();
            } while (line1 < line2);
            lcd_scroll(s);
            line1 = lcd_readscanline();
            do
            {
                line2 = lcd_readscanline();
            } while (line1 < line2);
        }
        lcd_scroll(0);

        ticks = timer_stop();

        print("  Time:");
        printuint(ticks);
        println(" ms");
        delayms(2000);

        if (checkchar())
        {
            break;
        }


#endif

        print("  Read RGB888...");

        timer_start();

        lcd_set_rotation(1);

        lcd_readimage();

        ticks = timer_stop();

        print("  Time:");
        printuint(ticks);
        print(" ms (CRC32:");
        printuint(crc32b(RGB888Buffer, sizeof(RGB888Buffer)));
        println(")");

        if (checkchar())
        {
            break;
        }

        print("  Draw RGB565...");

        // convert RGB888 to RGB565 (with inverted checkerboard)
        static uint16_t RGB565Buffer[320 * 240];

        uint8_t *  src = RGB888Buffer;
        uint16_t * dst = RGB565Buffer;
        for (int y = 0; y < 240; y++)
        {
            for (int x = 0; x < 320; x++)
            {
                uint16_t c = color565(src[0], src[1], src[2]);
                *dst++     = ((y ^ x) & 0x40) ? c : ~c;
                src += 3;
            }
        }

        timer_start();

        lcd_set_rotation(1);

        testRGB(RGB565Buffer);

        ticks = timer_stop();

        print("  Time:");
        printuint(ticks);
        println(" ms");
        delayms(2000);

        img += 1;
        if (img >= ELEMENTS(image_data))
        {
            img = 0;
        }
        count++;
    } while (!checkchar());        // loop until a char is waiting in UART buffer

    // restore GPIO data-direction and turn off LEDs
    MFP(DDR)  = UART_CTS | LED_RED | LED_GREEN;
    MFP(GPDR) = LED_RED | LED_GREEN;

    println("");
    // invoke Rosco Paranoid Android(TM) module
    println("A brain the size of a planet, and they ask me to drive an LCD...");

    return 0;
}

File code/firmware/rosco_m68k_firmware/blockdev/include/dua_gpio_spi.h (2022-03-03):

/*
 *------------------------------------------------------------
 *                                  ___ ___ _
 *  ___ ___ ___ ___ ___       _____|  _| . | |_
 * |  _| . |_ -|  _| . |     |     | . | . | '_|
 * |_| |___|___|___|___|_____|_|_|_|___|___|_,_|
 *                     |_____|
 * ------------------------------------------------------------
 * Copyright (c) 2021 Ross Bamford
 * MIT License
 *
 * Routines for SPI mode 2 (CPOL=1, CPHA=1)
 * ------------------------------------------------------------
 */

#ifndef _ROSCOM68K_GPIO_SPI_H
#define _ROSCOM68K_GPIO_SPI_H

#include <machine.h>

#define USE_ASM_DUART_SPI   1   // Xark - set to 1 to use optimized asm routines
// firmware SPI functions are static inline and always inlined
#define SPI_INLINE inline __attribute__ ((always_inline))

#define pinMode(...)
#define INPUT   0
#define OUTPUT  0

// Default rosco 2.x SPI pins
#if !defined(SPI_CS_B)
#define SPI_CS_B      2         // Output port pin
#endif
#if !defined(SPI_SCK_B)
#define SPI_SCK_B     4         // Output port pin
#endif
#if !defined(SPI_COPI_B)
#define SPI_COPI_B    6         // Output port pin
#endif
#if !defined(SPI_CIPO_B)
#define SPI_CIPO_B    2         // Input port pin
#endif
#if !defined(SPI_CS1_B)
#define SPI_CS1_B     7         // Output port pin
#endif

// calculate bit values for bit positions
#define SPI_CS        (1<<SPI_CS_B)
#define SPI_CS1       (1<<SPI_CS1_B)
#define SPI_SCK       (1<<SPI_SCK_B)
#define SPI_COPI      (1<<SPI_COPI_B)
#define SPI_CIPO      (1<<SPI_CIPO_B)

// HI/LO refer to physical pin state, these ports are active
// low, so they appear reversed here...
static volatile uint8_t *DUART_OUTLOPORT = (uint8_t*)DUART_W_OPR_SETCMD;
static volatile uint8_t *DUART_OUTHIPORT = (uint8_t*)DUART_W_OPR_RESETCMD;
static volatile uint8_t *DUART_INPUTPORT = (uint8_t*)DUART_R_INPUTPORT;

static SPI_INLINE void digitalWrite(uint8_t pinmask, bool value) {
    if (value) {
        *DUART_OUTHIPORT = pinmask;
    } else {
        *DUART_OUTLOPORT = pinmask;
    }
}

static SPI_INLINE bool digitalRead(uint8_t pinmask) {
    return ((*DUART_INPUTPORT) & pinmask);
}

// send one SPI byte, ignore received byte
#if USE_ASM_DUART_SPI
extern void spi_send_byte(int byte);
#else
static SPI_INLINE void spi_send_byte(int byte) __attribute__ ((used));
static SPI_INLINE void spi_send_byte(int byte)
{
    if (byte & 128) {
        // output high data, followed by low clock
        *DUART_OUTHIPORT = SPI_COPI;
        *DUART_OUTLOPORT = SPI_SCK;
    } else {
        // output low and clock at once
        *DUART_OUTLOPORT = SPI_COPI | SPI_SCK;
    }

    // Send clock high again
    *DUART_OUTHIPORT = SPI_SCK;

    if (byte & 64) {
        // output high data, followed by low clock
        *DUART_OUTHIPORT = SPI_COPI;
        *DUART_OUTLOPORT = SPI_SCK;
    } else {
        // output low and clock at once
        *DUART_OUTLOPORT = SPI_COPI | SPI_SCK;
    }

    // Send clock high again
    *DUART_OUTHIPORT = SPI_SCK;

    if (byte & 32) {
        // output high data, followed by low clock
        *DUART_OUTHIPORT = SPI_COPI;
        *DUART_OUTLOPORT = SPI_SCK;
    } else {
        // output low and clock at once
        *DUART_OUTLOPORT = SPI_COPI | SPI_SCK;
    }

    // Send clock high again
    *DUART_OUTHIPORT = SPI_SCK;

    if (byte & 16) {
        // output high data, followed by low clock
        *DUART_OUTHIPORT = SPI_COPI;
        *DUART_OUTLOPORT = SPI_SCK;
    } else {
        // output low and clock at once
        *DUART_OUTLOPORT = SPI_COPI | SPI_SCK;
    }

    // Send clock high again
    *DUART_OUTHIPORT = SPI_SCK;

    if (byte & 8) {
        // output high data, followed by low clock
        *DUART_OUTHIPORT = SPI_COPI;
        *DUART_OUTLOPORT = SPI_SCK;
    } else {
        // output low and clock at once
        *DUART_OUTLOPORT = SPI_COPI | SPI_SCK;
    }

    // Send clock high again
    *DUART_OUTHIPORT = SPI_SCK;

    if (byte & 4) {
        // output high data, followed by low clock
        *DUART_OUTHIPORT = SPI_COPI;
        *DUART_OUTLOPORT = SPI_SCK;
    } else {
        // output low and clock at once
        *DUART_OUTLOPORT = SPI_COPI | SPI_SCK;
    }

    // Send clock high again
    *DUART_OUTHIPORT = SPI_SCK;

    if (byte & 2) {
        // output high data, followed by low clock
        *DUART_OUTHIPORT = SPI_COPI;
        *DUART_OUTLOPORT = SPI_SCK;
    } else {
        // output low and clock at once
        *DUART_OUTLOPORT = SPI_COPI | SPI_SCK;
    }

    // Send clock high again
    *DUART_OUTHIPORT = SPI_SCK;

    if (byte & 1) {
        // output high data, followed by low clock
        *DUART_OUTHIPORT = SPI_COPI;
        *DUART_OUTLOPORT = SPI_SCK;
    } else {
        // output low and clock at once
        *DUART_OUTLOPORT = SPI_COPI | SPI_SCK;
    }

    // Send clock high again
    *DUART_OUTHIPORT = SPI_SCK;
}
#endif
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

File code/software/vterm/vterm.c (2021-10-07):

/* COPYRIGHT 2018 BRYAN HALEY UNDER THE MIT LICENSE *
 * SEE LICENSE.MD FOR MORE INFORMATION       
 * 
 * Modified Matt Pearce 2020 to support Rosco m68k       */



#include <stdio.h>
#include <stdlib.h>
#include <string.h>
#include "vterm.h"
#include <printf.h>
#include <machine.h>

#define ASCII_VALID_START 0x20
#define ASCII_VALID_END 0x7E

char* uart_getline(char* buff, int len)
{
    int buff_index = 0;
    char in = 0;
    
    /* Clear the buffer before using it */
    memset(buff, 0, len);

    /* Keep getting input until we get the enter key */
    while (buff_index < len && in != 0x0d)
    {
        in = mcReadchar();

        /* Handle characters than can be displayed */
        if (in >= ASCII_VALID_START && in <= ASCII_VALID_END)
        {
            /* Add them to the input buffer */
            buff[buff_index] = in;
            buff_index++;

            /* Print them to the screen so the user can see what they are typing */
            mcPrintchar(in);
        }

        /* Handle Backspace (Win/Lin) or Del (Mac) */
        if (in == 0x7F || in == 0x08)
        {
            vt_backspace();
            
            /* Remove the deleted character from the input buffer */
            if (buff_index > 0) { buff_index--; }
            buff[buff_index] = 0;
        }

        /* Handle escape sequences */
        if (in == 0x1B && mcReadchar() == 0x5B)
        {
            /* Handle arrow keys */
            switch (mcReadchar())
            {
                case 0x41:
                    vt_move_cursor_up("1"); break;
                case 0x42:
                    vt_move_cursor_down("1"); break;
                case 0x43:
                    vt_move_cursor_left("1"); break;
                case 0x44:
                    vt_move_cursor_right("1"); break;
            }
        }
    }

    mcPrintchar('\r');
    mcPrintchar('\n');

    return buff;
}

int main(int argc, char **argv) 
{
    (void)argc;
    (void)argv;
    
    /* Create an input buffer for commands */
    char* inputbuffer = (char*) calloc(1,100);
    int len = 100;

    /* initialize vterm control library */
    vt_init();

    /* clear the screen and reset cursor to get rid of old junk data */
    vt_clear_screen();
    vt_move_cursor_xy(0,0);

    printf("You can type with a working backspace, or use the arrow keys to move around.\n");
    printf("Available commands: %s%s",
           "clear, color4, color8, trucolor, invert, bold, underline,\n",
           "normal, bell, blink, fill, cursor-pos, screen-size, exit, help\n");

    while(1)
    {
        printf("$ ");
        uart_getline(inputbuffer, len);
        char *input = inputbuffer;
        while (*input > 0 && *input <= ' ')
        {
            input++;
        }

        if (strcmp(input, "clear") == 0)
        {
            vt_clear_screen();
            vt_move_cursor_xy(0,0);
        }

        else if (strcmp(input, "help") == 0)
        {
            printf("Available commands: %s%s",
                   "clear, color4, color8, trucolor, invert, bold, underline,\n",
                   "normal, bell, blink, fill, cursor-pos, screen-size, exit, help\n");
        }

        else if (strcmp(input, "exit") == 0)
        {
            printf("\x1b" "cGoodbye, you hoopy frood!\n");
            return 0;
        }

        else if (strcmp(input, "color4") == 0)
        {
            printf("Enter a foreground color code: ");
            char* fg_code = (char*) calloc(1,5);
            uart_getline(fg_code, 5);
            printf("Enter a background color code: ");
            char* bg_code = (char*) calloc(1,5);
            uart_getline(bg_code, 5);

            vt_setcolor_4bit(fg_code, bg_code);
            printf("Color test\n");
        }

        else if (strcmp(input, "color8") == 0)
        {
            printf("Enter a foreground color code (0-255): ");
            char* fg_code = (char*) calloc(1,5);
            uart_getline(fg_code, 5);
            printf("Enter a background color code (0-255): ");
            char* bg_code = (char*) calloc(1,5);
            uart_getline(bg_code, 5);

            vt_setcolor_8bit(fg_code, bg_code);
            printf("Color test\n");
        }

        else if (strcmp(input, "trucolor") == 0)
        {
            printf("Setting foreground colors\n");
            printf("Enter a red color value (0-255): ");
            char* r_fg = (char*) calloc(1,4);
            uart_getline(r_fg, 4);
            printf("Enter a blue color value (0-255): ");
            char* g_fg = (char*) calloc(1,4);
            uart_getline(g_fg, 4);
            printf("Enter a green color value (0-255): ");
            char* b_fg = (char*) calloc(1,4);
            uart_getline(b_fg, 4);

            printf("\nSetting background colors\n");
            printf("Enter a red color value (0-255): ");
            char* r_bg = (char*) calloc(1,4);
            uart_getline(r_bg, 4);
            printf("Enter a blue color value (0-255): ");
            char* g_bg = (char*) calloc(1,4);
            uart_getline(g_bg, 4);
            printf("Enter a green color value (0-255): ");
            char* b_bg = (char*) calloc(1,4);
            uart_getline(b_bg, 4);
            
            vt_setcolor_tru(r_fg, r_bg, g_fg, g_bg, b_fg, b_bg);
            printf("Color test\n");
        }

        else if (strcmp(input, "invert") == 0)
        {
            vt_invert_colors();
        }

        else if (strcmp(input, "bold") == 0)
        {
            vt_bold_text();
        }

        else if (strcmp(input, "underline") == 0)
        {
            vt_underline_text();
        }

        else if (strcmp(input, "normal") == 0)
        {
            vt_reset_text_attributes();
        }

        else if (strcmp(input, "bell") == 0)
        {
            vt_bell();
        }
        
        else if (strcmp(input, "blink") == 0)
        {
            vt_blink_text();
        }

        else if (strcmp(input, "trucolor-test") == 0)
        {
            printf("\x1b[38;2;40;177;249mTRUECOLOR\x1b[0m\n");
        }
        
        else if (strcmp(input, "cursor-pos") == 0)
        {
            vt_vec2 *cursor_pos = vt_get_cursor_pos();
            printf("Cursor position: (%d,%d)\n", cursor_pos->x, cursor_pos->y);
            free(cursor_pos); cursor_pos = NULL;
        }
        
        else if (strcmp(input, "screen-size") == 0)
        {
            vt_vec2 *screen_size = vt_get_screen_size();
            printf("Screen size: %dx%d\n", screen_size->x, screen_size->y);
            free(screen_size); screen_size = NULL;
        }

        else if (strcmp(input, "fill") == 0)
        {
            printf("Enter a character to fill the screen with: ");
            char in = mcReadchar();

            vt_fill_screen(in);
        
        }
        
        else if (strcmp(input, "scroll-up") == 0)
        {
            vt_scroll_up();
        }
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

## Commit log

2019-03-18 Initial import
    [reset_circuit.sch]
2019-03-28 Fix values
    [address_decoder_v1.sch]
2019-03-28 Add clock schematic
    [clock.sch]
2019-04-21 Spacing tidy up
    [address_decoder_v1.sch]
2019-04-22 Add CPU glue to handle reset of address decoder
2019-04-24 Gate tidy up in prep for layout
    [address_decoder_v1.sch]
2019-04-28 Add free-run schematic
    [m68k_free_run.sch]
2019-05-08 Add new v2 address decoder sim and schematic
    * Fixed incorrect endianness for UDS/LDS lines
    * Add /BOOT generation to schematic
    * Make sim accurately reflect hardware (i.e. no XNOR gates)
    [address_decoder_v2.sch]
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2019-05-19 Add DTACK generator design
    [dtack-generator.sch]
2019-05-26 Add DTACK generator
    [address_decoder_v2.sch]
2019-05-26 Add high-level bus schematic
    [bus_schematic.sch]
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2019-06-04 New DTACK generator
    [address_decoder_v2.sch]
2019-06-06 Add pullup on DTACK
    [address_decoder_v2.sch]
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2019-06-25 Fix capacitor orientation
    [reset_circuit.sch]
2019-07-15 Finish design of DTACK generator
    [address_decoder_v2.sch]
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2019-08-14 Redo full schematic, obsolete old designs
    [address_decoder_v1.sch, address_decoder_v2.sch, bus_schematic.sch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]
2019-08-16 Cleanup ready for PCB design
    [rosco_m68k.sch]
2019-08-16 Initial PCB design
    [rosco_m68k.brd]
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2019-08-23 Use new PLD glue logic and tidy up
    [rosco_m68k.sch]
2019-08-23 New PCB design
    [rosco_m68k.brd]
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2019-08-31 Fix misplaced capacitor
    [rosco_m68k.brd, rosco_m68k.sch]
2019-09-01 Enable serial RX
    * Add RX buffer full and error handlers
    * Fix transmitter wakeup bug (still has a race condition though)
    * kmain now just reads chars from serial and echoes them back
    [serial.c]
2019-09-22 First cut spinlock/critical (lock not working)
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2020-03-01 Add r0 gerbers
    [copper_bottom_l4.gbr, copper_inner_l2.gbr, copper_inner_l3.gbr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]
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2020-03-13 Add note about r0 silkscreen error
2020-03-13 Add errata for r0 board
2020-03-14 Rearrange design files
    [Clock_Reset.sch, Cpu_Ram_Rom.sch, Dtack_Boot.sch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]
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2020-03-15 Initial cleanup
    [Clock_Reset.sch, Cpu_Ram_Rom.sch, Dtack_Boot.sch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]
2020-03-15 Cleanup first pass
    [Clock_Reset.sch, Cpu_Ram_Rom.sch, Dtack_Boot.sch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]
2020-03-15 Fixing migrated symbols
    [Cpu_Ram_Rom.sch, Dtack_Boot.sch, MC68901_Decoder.sch]
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2020-03-15 Initial work on r1 board, make ERC and DRC pass
    [rosco_m68k.kicad_pcb]
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2020-03-17 GPIO, Legacy Peripheral and Panel support
    [Cpu_Ram_Rom.sch, Expansion.sch, MC68901_Decoder.sch]
2020-03-17 Design complete
    [Expansion.sch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]
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2020-03-28 Add missing KiCad project files (Fix #17)
2020-03-29 Fix #18 and apply suggestions from #17
    [Clock_Reset.sch, Cpu_Ram_Rom.sch, Dtack_Boot.sch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]
2020-03-29 Critical no longer needed for UART IO
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2020-03-31 Example circuit
    [circuit.sch]
2020-04-11 Switch from WinCUPL to GALasm.
    * Removes the need for the proprietary (and terrible!) WinCUPL
    * Fix #29 (with caveats, see the ticket comments)
    * Fix #30
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2020-05-25 # This is a combination of 9 commits. # This is the 1st commit message:
    First cut SPI and SD libs|
    # This is the commit message #2:
    First steps reading FAT filesystem
    # This is the commit message #3:
    Additions and bugfixes
    # This is the commit message #4:
    Add FAT support
    # This is the commit message #5:
    Major speed and size improvements
    # This is the commit message #6:
    First cut working SD in ROM
    # This is the commit message #7:
    First cut working SD in ROM
    # This is the commit message #8:
    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
    [bbspi.c]
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2020-05-25 Fix limiting resistors on R2 and R15
    [Clock_Reset.sch, MC68901_Decoder.sch]
2020-05-26 Rerate current-limiting resistor for new green LEDs
    [Clock_Reset.sch]
2020-05-26 Initial work r1.2
    [Cpu_Ram_Rom.sch, Expansion.sch, Glue.sch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]
2020-05-27 Pull-up on oscillator enables
    [Glue.sch]
2020-05-29 More robust MFP decoding
    [Cpu_Ram_Rom.sch, Glue.sch]
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2020-06-07 Revert "Hotfix/decoder glue fixes"
2020-06-07 Revert "Merge pull request #50 from rosco-m68k/revert-49-hotfix/decoder-glue-fixes"
    This reverts commit 63c6bc7cd5000788ee704e0b7b0d4c550ee03512, reversing
    changes made to aaf14eb8d8b84df4b9f41bdb977f99d74f958e87.
2020-06-09 Remove confusingly-located copy of r1 gerbers
    [rosco_m68k-B_Mask.gbr, rosco_m68k-B_Paste.gbr, rosco_m68k-B_SilkS.gbr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]
2020-06-12 Layout for 1.2 and PLD changes for same
    [Cpu_Ram_Rom.sch, Expansion.sch, Glue.sch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]
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2020-06-20 Regenerated BOM
    [rosco_m68k.csv]
2020-06-25 Fix reset LED snafu
    [Expansion.sch, Glue.sch, rosco_m68k.kicad_pcb]
2020-06-25 New fab outputs
    [rosco_m68k-B_Mask.gbr, rosco_m68k-B_Paste.gbr, rosco_m68k-B_SilkS.gbr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]
2020-07-02 Add DTACK watchdog, tidy up footprints
    [Cpu_Ram_Rom.sch, Expansion.sch, Glue.sch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]
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2020-07-10 New BOM
    [rosco_m68k.csv]
2020-07-29 Fix timer frequency
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2020-07-30 Silkscreen fixes suggested by Jayney & Henk
    [rosco_m68k.kicad_pcb]
2020-07-31 Redo PCB CAM with silkscreen fixes
    [rosco_m68k-B_Mask.gbr, rosco_m68k-B_Paste.gbr, rosco_m68k-B_SilkS.gbr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]
2020-08-13 Finalise 1.2 (BREAKING CHANGE)
    [rosco_m68k-B_Mask.gbr, rosco_m68k-B_Paste.gbr, rosco_m68k-B_SilkS.gbr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]
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2020-08-17 Fix some comments and documentation
    [gpio-interrupt.c]
2020-08-18 Rerate LED limiters for new LED stock
    [Cpu_Ram_Rom.sch, Glue.sch, rosco_m68k.csv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]
2020-08-24 Add -quiet to assembler to avoid vasm spam
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2020-09-24 Fix printf-using examples to also -lgcc
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2020-10-10 Revert accidentally-pushed "Add faster, more robust SD loader to BIGROM"
    This reverts commit 69425305b6aaf81d7e0fb9204e5737be372b1f28.
    [bbspi.c]
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2020-10-12 Improve SD load error checking, timing & prints
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2020-10-22 Minor routing improvement
    [rosco_m68k.kicad_pcb]
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2020-11-25 Fix 1.21 incorrect IC7 ref (was U5)
    [Glue.sch, rosco_m68k.kicad_pcb]
2020-11-25 H/W BREAKING CHANGE: IC5 Pin 19 is now DTACK, 14 is PPDTACK
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2020-11-26 Board changes for new DTACK
    [Glue.sch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]
2020-11-29 Print message to avoid seemingly-hung board
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2021-03-05 Tidy up IO and add SPI header, roll r1.22
    [Cpu_Ram_Rom.sch, Expansion.sch, Glue.sch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]
2021-03-05 BOM updated
    [rosco_m68k.csv]
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2021-03-21 Revert "Merge pull request #181 from rosco-m68k/feature/board-1.22"
    This reverts commit 67e3259ef153c8a657db8d826cd60eea2d9b52e3, reversing
    changes made to 43bb90592578d0b0c5d0a3f828a55b4324962c1a.
    [Cpu_Ram_Rom.sch, Expansion.sch, Glue.sch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]
2021-03-22 Switch to using a pointer to the CPU struct (and saving regs properly)
2021-03-31 Update board for IC5 and tidy up
    [Glue.sch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]
2021-03-31 Fix memcheck for memory hole
2021-03-31 Silkscreen tweaks for manufacturing
    [rosco2_m68k.kicad_pcb, rosco2_m68k.sch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]
2021-04-09 Fix #199
    [Cpu_Ram_Rom.sch, Expansion-fix.sch, Glue.sch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]
2021-04-14 Remove unused copy of expansion schematic
    [Expansion-fix.sch]
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2021-06-27 Fix mislabeled data pin on J3p64
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2021-07-11 Fix memcheck on hugerom boards
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2021-09-22 Enable/disable Timer C on NOTICK false/true
    Timer C settings were backwards, and comments have been updated.
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2021-10-26 Initial r2 import (still WIP)
    [Cpu_Ram_Rom.sch, DUART.sch, Expansion.sch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]
2021-10-26 Remove outdated gerbers
    [rosco_m68k-B_Mask.gbr, rosco_m68k-B_Paste.gbr, rosco_m68k-B_SilkS.gbr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]
2021-10-26 Complete schematic capture for r2
    [CPU.sch, Cpu_Ram_Rom.sch, DUART.sch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]
2021-10-26 Tidy up footprints
    [CPU.sch, DUART.sch, Expansion.sch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]
2021-10-26 Schematic / GAL tweaks and do layout
    [CPU.sch, DUART.sch, GALs.sch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]
2021-10-26 Add ROM write-enable jumper and tidy up
    [GALs.sch, Memory.sch, rosco_m68k.kicad_pcb]
2021-10-26 Changes requested by @e2k
    [Expansion.sch, rosco_m68k.kicad_pcb]
2021-10-26 Update PDF and BOM
    [rosco_m68k.csv]
2021-10-26 Fix C3 unconnected issue
    [rosco_m68k.kicad_pcb]
2021-10-26 Fix incorrect LED hookup and add SPICS2 at @wbond's suggestion
    [DUART.sch, rosco_m68k.csv, rosco_m68k.kicad_pcb]
2021-10-26 Fix incorrect device
2021-10-26 Fix incorrect GAL value and redo BOM etc
    [GALs.sch, rosco_m68k.csv, rosco_m68k.kicad_pcb]
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2021-10-26 Fix initial timer tick for r2x DUART
2021-10-26 Fix CTS/RTS labelling
    [DUART.sch, rosco_m68k.kicad_pcb]
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2021-10-26 Reset BOOT logic on board reset
2021-10-26 Bite the bullet and do IPL properly...
    [CPU.sch, DUART.sch, Expansion.sch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]
2021-10-26 Fully decode for DUART
    [GALs.sch, rosco_m68k.kicad_pcb]
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2021-10-26 Fix unconnected VCC on 148
    [Expansion.sch, rosco_m68k.kicad_pcb]
2021-10-30 Add r2.1 CAM data
    [rosco_m68k-B_Mask.gbr, rosco_m68k-B_Paste.gbr, rosco_m68k-B_SilkS.gbr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]
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2021-11-17 Tighten up TICK_HANDLER
    * TICK_HANDLER should only handle ticks when the correct interrupt is
    received from the DUART (the COUNTER interrupt) on r2.x boards.
    * This is necessary because the XR68C681 has only limited vectored
    interrupt support.
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2021-12-20 Add value for Q1
    [DUART.sch]
2022-01-10 Super-minor tidy-up
    [DUART.sch, Expansion.sch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]
2022-01-14 Initial conversion to KiCad 6
    [CPU.kicad_sch, DUART.kicad_sch, Expansion.kicad_sch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]
2022-01-14 Remove old schematic files
    [CPU.sch, DUART.sch, Expansion.sch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]
2022-01-14 Tidy up schematic for new filenames
    [rosco_m68k.kicad_sch]
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2022-01-26 Replace all serial console vectors
    [duart.asm, mfp.asm]
2022-01-26 Fix GCC faulting on guaranteed NULL dereference
    Only fixed in stage1, for now
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2022-02-06 Fix mixed-up GAL labels in schematic
    [GALs.kicad_sch]
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2025-06-07 Fix typo in PRINTCHAR description (#482)

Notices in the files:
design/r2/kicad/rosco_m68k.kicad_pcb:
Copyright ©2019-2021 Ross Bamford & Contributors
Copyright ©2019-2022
